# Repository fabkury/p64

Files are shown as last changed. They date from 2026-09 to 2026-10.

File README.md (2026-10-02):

# p64

A small pixel-art display for your desk: 64 x 64 RGB LEDs behind a 3D-printed shell,
powered over USB-C, controlled from a browser. It plays animated pixel art from a microSD
card and from [Makapix Club](https://makapix.club), shows a clock, the weather and the room
temperature, and takes live pixel streams from your computer. Open source, built from two
off-the-shelf Waveshare boards, no soldering.

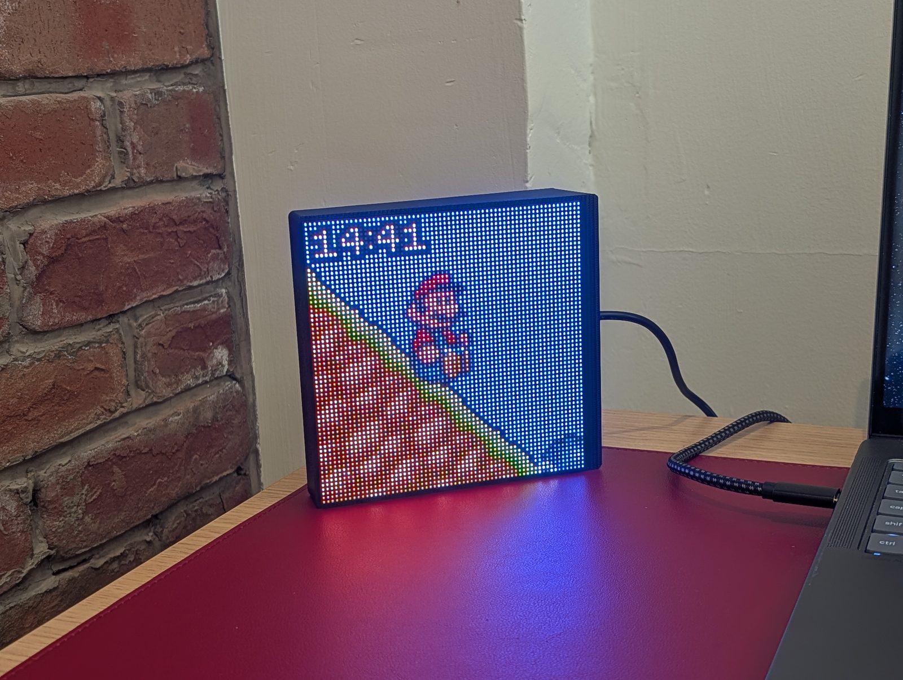
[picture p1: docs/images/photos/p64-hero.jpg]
p64 on a desk, playing an animation with the clock overlay


## What it does

- **Plays pixel art the way it was drawn.** GIF, PNG/APNG, WebP and BMP, static or animated,
  with transparency. Small canvases are scaled up by whole numbers so pixels stay square;
  large ones are scaled down cleanly. Every frame is shown, none skipped.
- **Looks right.** 11-bit colour per channel at a 264 Hz refresh, gamma 2.2, seamless
  changes from one artwork to the next: no blank frame, no flicker, no brightness step.
  A "Photo" mode raises the refresh to 814 Hz for cameras.
- **Runs on its own.** Put files on a microSD card, or pair it with Makapix Club and it
  plays channels of community pixel art, refreshing its cache over Wi-Fi. Playsets group
  channels; a scheduler picks what plays when. Offline, it keeps playing what it has.
- **Is a clock too.** A time overlay on artworks, nine clock faces (digital, analogue, and seven themed ones: split-flap, nixie tubes, a landscape that follows the real sun, a word clock, an hourglass, an orrery and a seven-segment LED or VFD clock),
  weather from Open-Meteo, the room temperature from the board's own sensor, and a night
  schedule that dims or blanks the panel.
- **Takes a live feed.** Send pixels over UDP with DDP (LedFx, xLights, WLED tooling) or
  the raw p64 format; a bundled script mirrors any image, animation or a region of your
  screen to the panel.
- **Is controlled from a browser.** A mobile-friendly web UI on `http://p64.local`
  (five colour themes, installable as a web app), a documented HTTP API with WebSocket
  push, an optional PIN. A tap on the shell skips to the next artwork; the IMU turns the
  picture upright whichever way you stand it.
- **Updates itself.** Firmware updates come from GitHub Releases with a verified install
  and rollback. Nothing is downloaded or installed without you pressing the button.

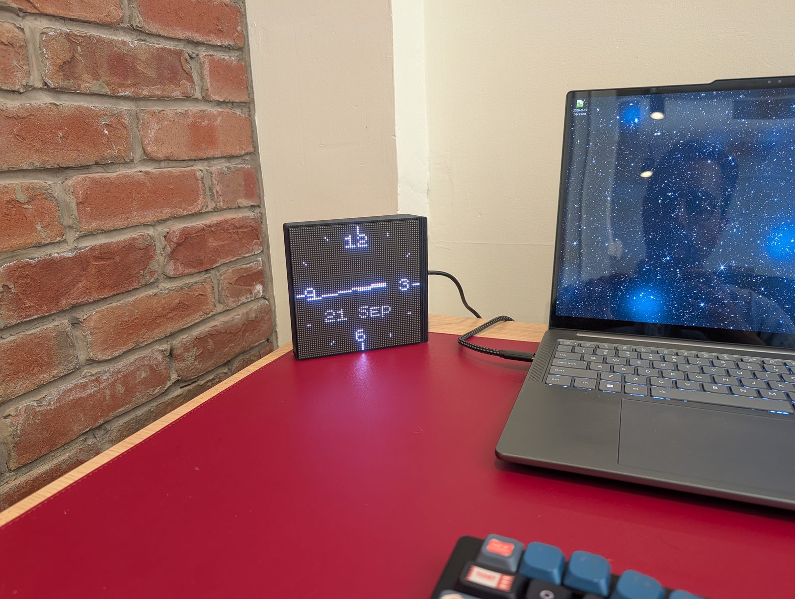
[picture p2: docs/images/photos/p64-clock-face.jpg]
Analogue clock face
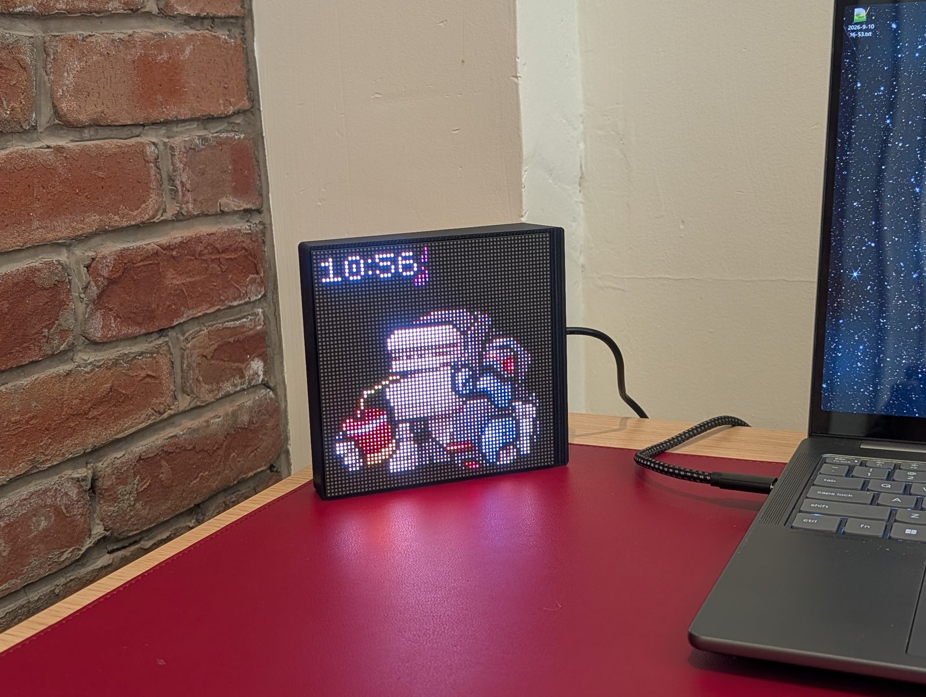
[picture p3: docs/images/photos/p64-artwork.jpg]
An artwork with the time overlay
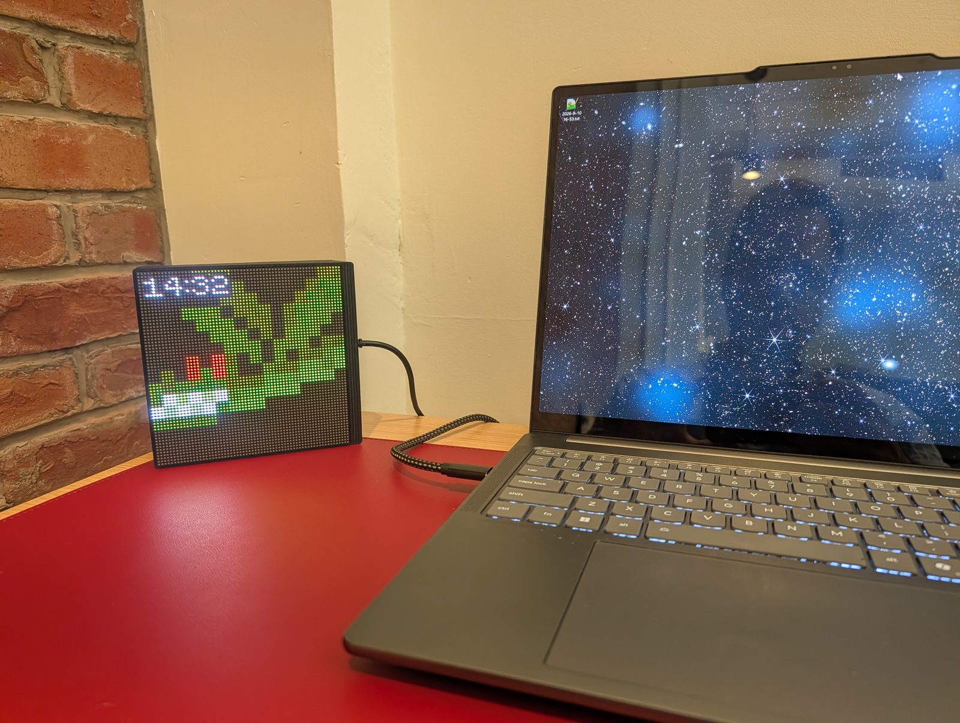
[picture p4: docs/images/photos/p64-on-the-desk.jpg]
Next to a laptop, for scale
|  |  |  |
|---|---|---|
| The analogue clock face | Time overlay on an artwork | 128 mm square, for scale |

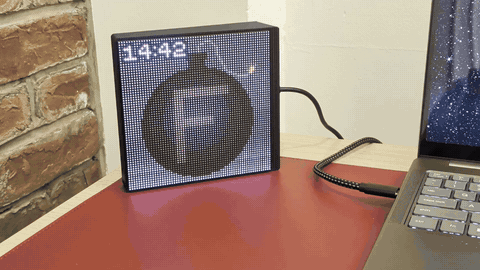
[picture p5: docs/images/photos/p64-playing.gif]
A short clip of an animation playing with the clock overlay


The web UI, on a phone:

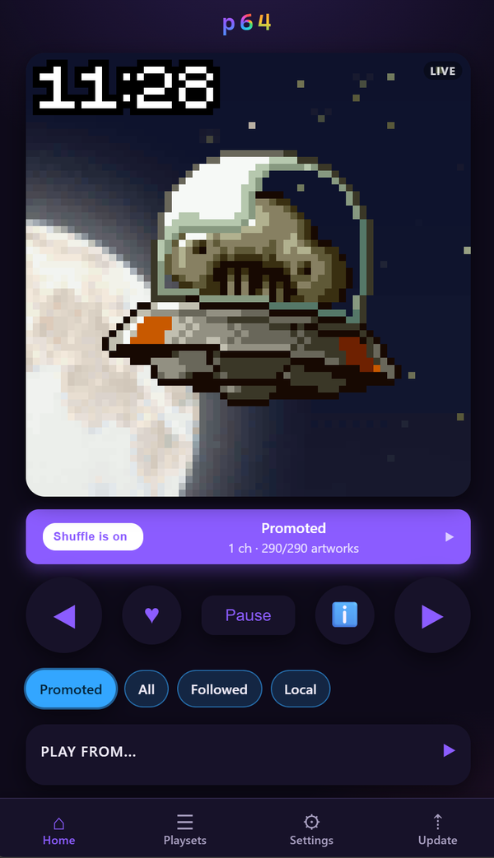
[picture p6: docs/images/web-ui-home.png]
Home page
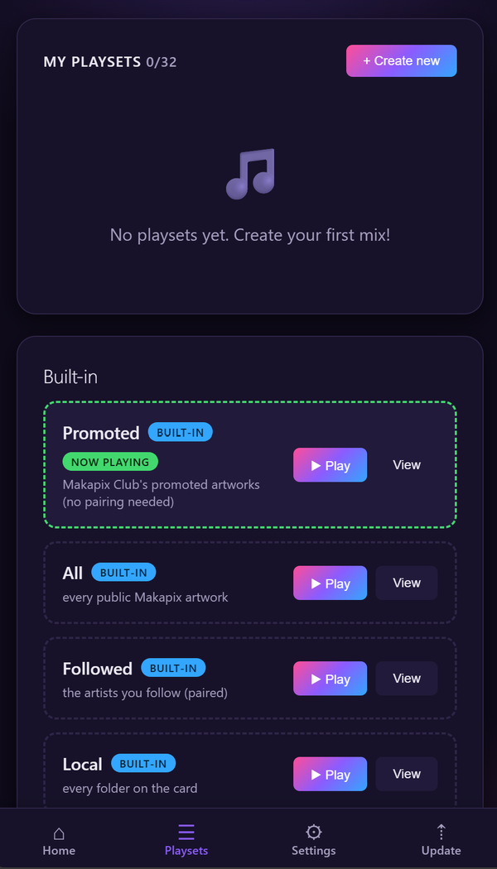
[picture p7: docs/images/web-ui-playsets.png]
Playsets page
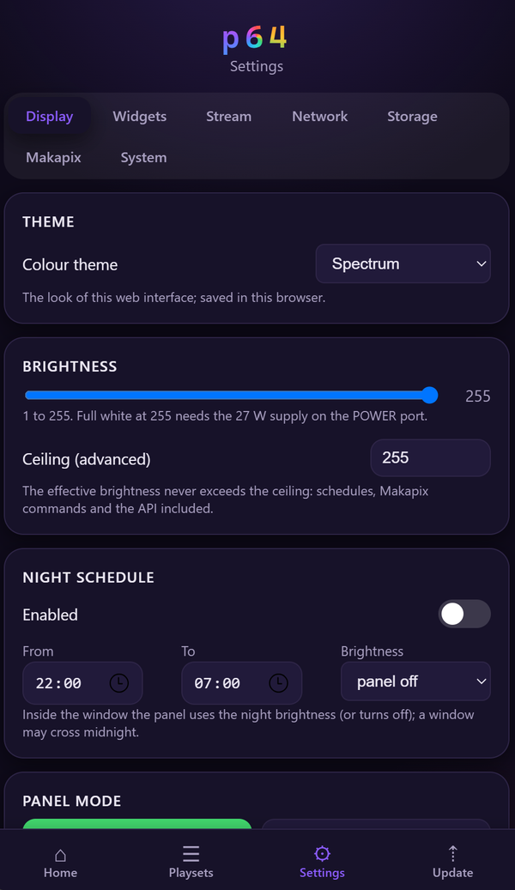
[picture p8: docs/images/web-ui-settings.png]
Settings page
|  |  |  |
|---|---|---|
| Home: live preview, controls, channels | Playsets: your mixes and the built-ins | Settings: display, widgets, network, Makapix |

More photos:

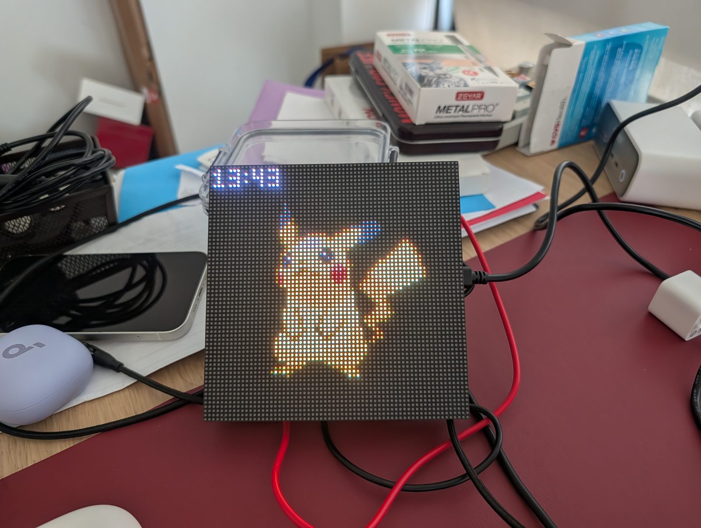
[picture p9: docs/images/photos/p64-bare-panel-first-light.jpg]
The bare panel on the bench, showing its first animation
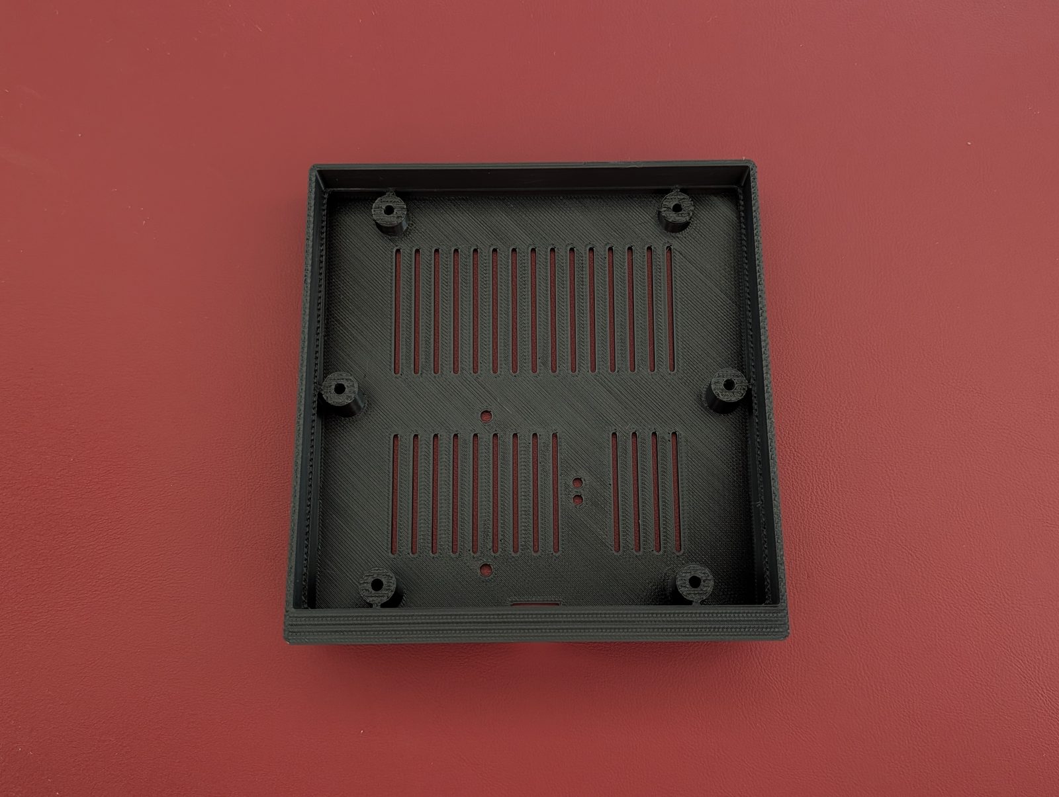
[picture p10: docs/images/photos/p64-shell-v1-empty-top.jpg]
The empty v1 shell seen from above
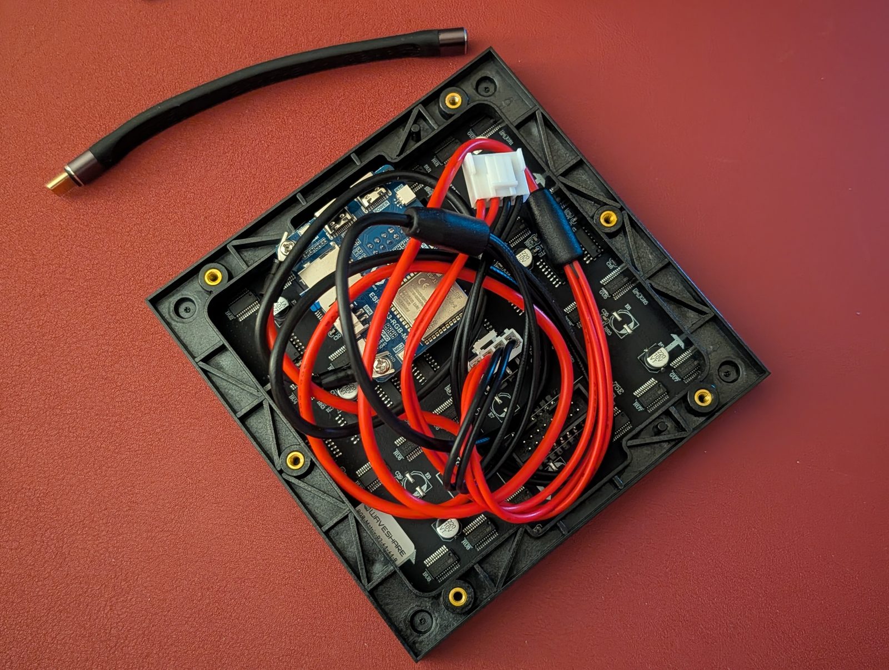
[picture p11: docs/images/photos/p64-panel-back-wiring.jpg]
The driver board and its leads behind the panel
|  |  |  |
|---|---|---|
| First light, before the shell | The v1 shell, empty | The driver board behind the panel |
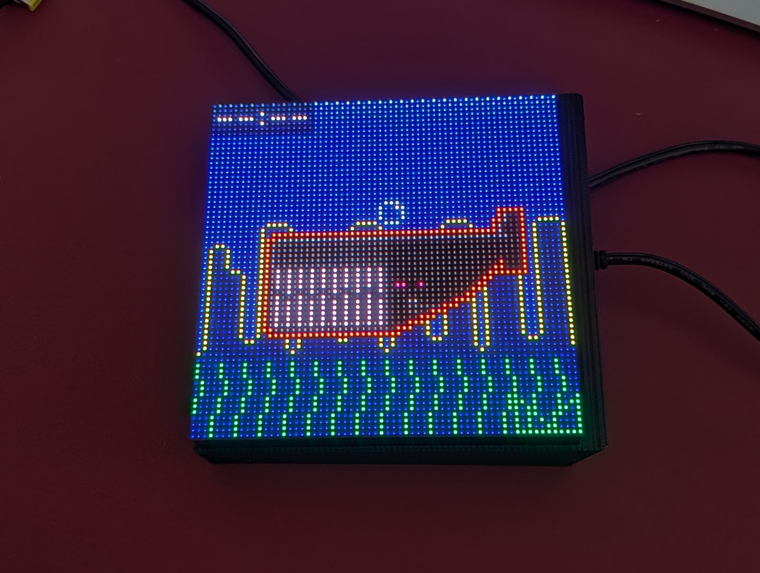
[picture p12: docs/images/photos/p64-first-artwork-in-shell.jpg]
The first artwork in the shell
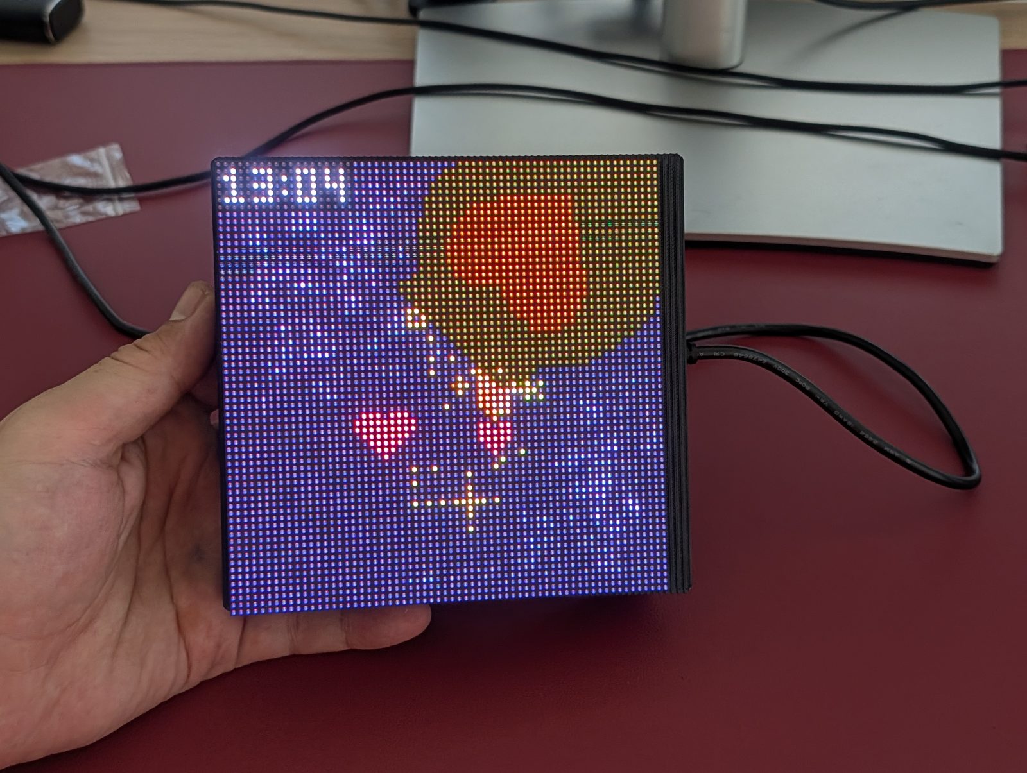
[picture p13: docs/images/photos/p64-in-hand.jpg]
p64 held in one hand
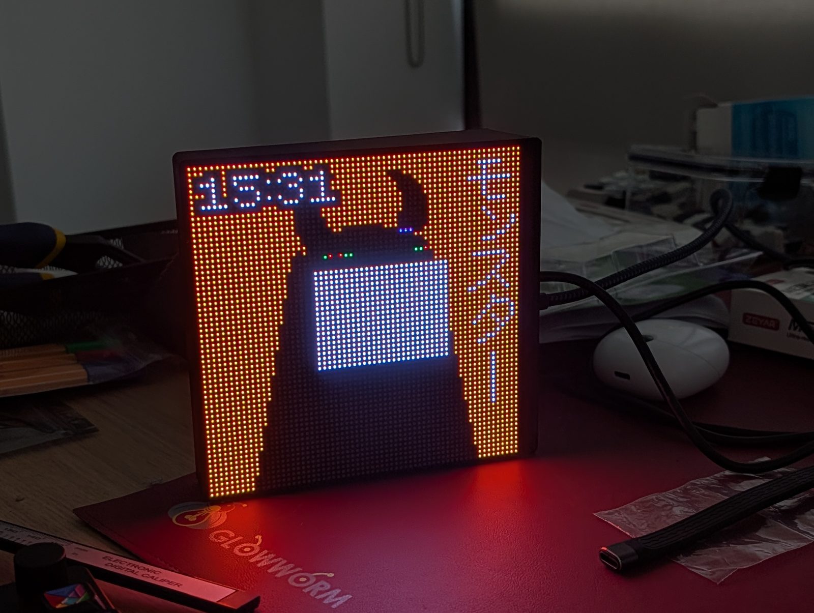
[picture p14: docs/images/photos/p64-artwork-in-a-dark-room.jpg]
An artwork in a dark room
|  |  |  |
| First artwork in the shell | In the hand | Lights off |
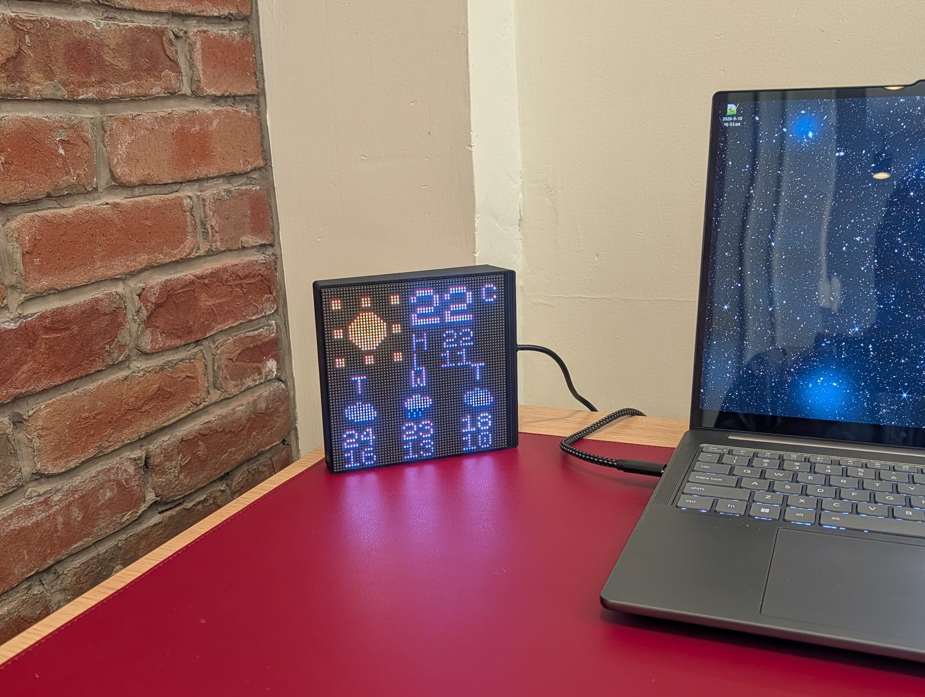
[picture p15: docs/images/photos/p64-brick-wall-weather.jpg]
The weather widget
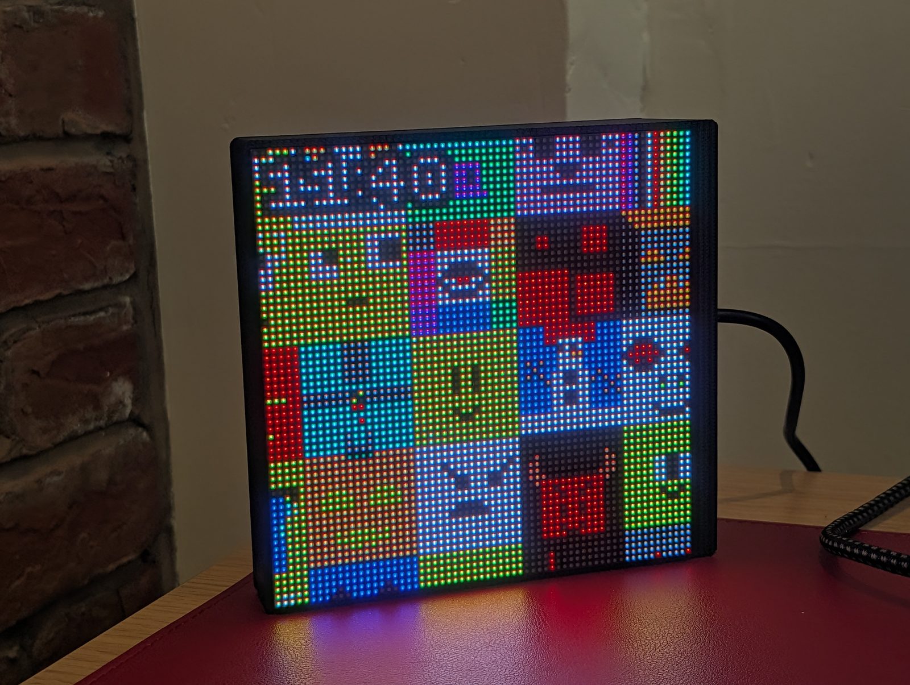
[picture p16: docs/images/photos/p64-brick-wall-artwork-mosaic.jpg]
A mosaic of small artworks
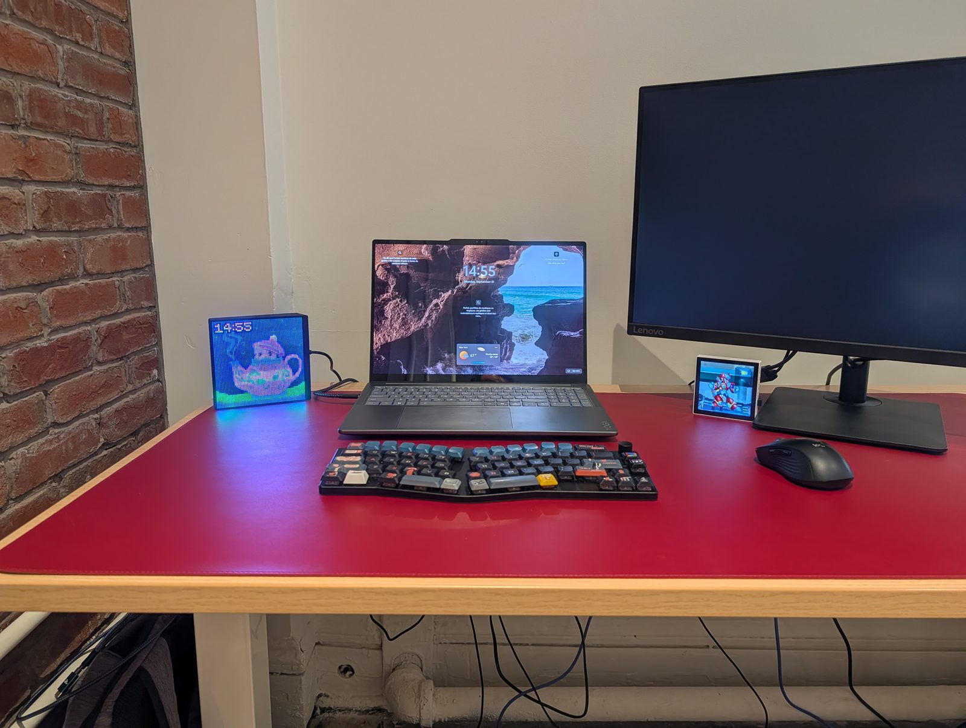
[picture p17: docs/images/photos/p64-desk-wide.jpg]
The whole desk, p64 at the left
|  |  |  |
| The weather widget | A mosaic artwork | On the desk |

The rest are in [`docs/images/photos/`](docs/images/photos/). There is also a 50-second
concept video of p64b rendered from the enclosure model (the shell as designed, the
mock-ups, an exploded view with a look inside the shell, the two knobs at work, the panel
playing animations and the widgets): the pipeline is in
[`docs/video/`](docs/video/README.md), the MP4 is regenerated with one command and is not
committed.

## What you need

Three parts from Waveshare plug together, plus a print and a handful of screws. List
prices on waveshare.com on 2026-09-21, before shipping:

| Part | What it is | Price |
|---|---|---|
| [ESP32-S3-RGB-Matrix](https://www.waveshare.com/esp32-s3-rgb-matrix.htm) | The driver board: ESP32-S3 with 32 MB flash and 16 MB PSRAM, Wi-Fi, HUB75 header, two USB-C ports, IMU, real-time clock, temperature sensor, microSD slot. Ships with the power lead and screws. [Wiki](https://docs.waveshare.com/ESP32-S3-RGB-Matrix). | $24.99 |
| [RGB-Matrix-P2-64x64-B](https://www.waveshare.com/rgb-matrix-p2-64x64.htm?sku=33838) | The panel: 4096 RGB LEDs at a 2 mm pitch, 128 x 128 mm, GOB version (a protective layer over the LEDs). The [standard version](https://www.waveshare.com/rgb-matrix-p2-64x64.htm) without the layer is $28.99 and fits the same shell. [Wiki](https://docs.waveshare.com/RGB-Matrix-Px-64x64). | $31.99 |
| [PSU-27W-USB-C-B](https://www.waveshare.com/psu-27w-usb-c-b.htm?sku=27775) | A 5.1 V USB-C supply; any good 5 V 3 A USB-C supply works. US, EU and UK plugs. | $6.99 |
| The shell | One support-free 3D print, about 80 g of PLA or PETG on a 140 x 140 mm bed, or a print bureau, plus a 2 g insert. Files in `enclosure/output/p64a/` or `p64b/`. The v1 shell in the photos was printed by JLC3DP in black PLA for $18.83, shipping included. | $18.83 at a bureau, a few dollars of filament at home |
| Small parts | Six M3 x 10 screws, a USB-C cable; for the current shell version two small 90-degree USB-C adapters. A microSD card is optional. | a few dollars |

About $64 in electronics plus the print, so a little over $80 before the electronics'
shipping. You also need a computer with a USB-C cable to
flash the firmware the first time; after that the device updates itself over Wi-Fi.

## Two variants

p64 comes in two variants, both supported for good (decided 2026-09-22):

- **p64a, solder-less:** no rotary encoders. Two boards plug together, the power lead goes
  into screw terminals, the shell is `enclosure/output/p64a/`.
- **p64b, with soldering:** two rotary encoder knobs on the back of the shell
  (`enclosure/output/p64b/`), wired to the board's GPIO socket as in `docs/hardware/`.

The firmware is the same; p64a simply has no knobs to read.

## Build one

[docs/build-your-own.md](docs/build-your-own.md) is the step-by-step guide. In short:

1. Order the parts above and print `p64_enclosure_print.stl` plus the small
   `p64_cradle_insert.stl` from `enclosure/output/p64a/v7a/` (no knobs, no soldering) or
   `enclosure/output/p64b/v7b/` (two knobs, soldered wiring); see the two variants above.
2. Install ESP-IDF v5.5, build the firmware from `firmware/` and flash it over the
   board's USB port.
3. Plug the board onto the panel, connect the power lead, slide the panel into the shell
   and fit the six screws.
4. Power it on. It opens a `p64-setup` Wi-Fi network; join it, pick your network in the
   portal, and open `http://p64.local` in a browser.

## Status

p64 is a working prototype. One device runs the firmware every day, and every feature in
[the specification](docs/spec/p64-spec.md) is implemented and checked on it. What is not
there yet, as of 2026-09-21:

- **No firmware release yet.** Building one today means compiling from source with
  ESP-IDF. A first GitHub release with a ready-to-flash image is planned; the updater is
  already in the firmware and waits for it.
- **The shell in the photos is v1.** The current design, v7, adds a window for the USB-C
  cables (and, in p64b, mounts for the two knobs) and is not printed yet. v1 is proven,
  archived under `enclosure/archive/pre-v7/`, and needs a right-angle USB-C cable instead.
- **The two knobs work on the bench, not yet in a shell.** Both are wired to the board's
  GPIO socket on a breadboard and accepted (2026-10-01): one turns the brightness and
  pauses, the other steps through the artworks and likes on Makapix Club. The permanent
  harness and the p64b shell are still to come; the wiring projects are in
  `docs/hardware/`.
- **Some acceptance measurements** in the specification still need instruments.

## Repository map

| Path | What it is |
|---|---|
| `firmware/` | The product firmware: ESP-IDF v5.5, C++20, on a patched `esp-hub75` driver. Its README has the build, flash and test commands; `firmware/docs/` has the architecture, the API and the progress log. |
| `enclosure/` | The OpenSCAD shell (one source, two variant files), with ready-to-print STL/3MF and renders under `enclosure/output/p64a/` and `p64b/`. Its README has the design rationale and the print settings; the earlier versions are under `enclosure/archive/pre-v7/`. |
| `docs/spec/p64-spec.md`, `CONTEXT.md`, `docs/adr/` | What the device does (the specification), the vocabulary, and the decisions that are hard to reverse. |
| `docs/build-your-own.md`, `docs/images/` | The build guide, the photos (`photos/`) and the web UI screenshots. |
| `docs/hardware/` | Wiring projects for the two rotary encoders, with schematics. |
| `firmware/reference/hardware-tests/` | The test firmware that brought up the board and panel; the technical reference for what the hardware taught (pin map, driver patch, frame pacing, DMA). |
| `prompt/` | The task prompt of each development session, in order. |

## About

p64 is a sibling of [p3a](https://github.com/fabkury/p3a), the same author's ESP32-P4
pixel-art player, and a "player" for [Makapix Club](https://makapix.club), a community
site for pixel art whose [server](https://github.com/fabkury/makapix) is open source too.
The firmware, the shell and the documentation were developed with Claude Code, session by
session; the prompts are committed under `prompt/`, and every hardware finding was
verified on the device.

Licensed under the [Apache License 2.0](LICENSE). Bundled fonts are VEXED's Capital Hill,
Everyday Slight, Standard, Typical and Ample, and High Birth (CC BY 4.0); the LED driver is
[esp-hub75](https://github.com/esphome/esp-hub75) with a local patch, the GIF decoder is
bitbank2's AnimatedGIF, and libpng and libwebp decode the rest.

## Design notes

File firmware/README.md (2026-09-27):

# p64 firmware

The firmware of the p64 device: a desktop 64x64 RGB LED matrix built on Waveshare's
ESP32-S3-RGB-Matrix driver board and RGB-Matrix-P2-64x64 panel (the repository README
lists the hardware).

Started from zero on 2026-09-19 and built in ten milestones the same day (M0 to M10,
`docs/PROGRESS.md` has the table, the log and what was verified on the device). The
design is `docs/architecture.md`, the routes `docs/api.md`.

## Specification

What the device does is fixed by `docs/spec/p64-spec.md` at the repository root, with
the vocabulary in `CONTEXT.md` and the decisions in `docs/adr/`.

## Building, flashing, testing

ESP-IDF v5.5.4 (`tools/env.ps1` knows the install), PowerShell 7, from this folder:
`./tools/build.ps1`, `./tools/flash.ps1` (auto-detects the board's COM port),
`./tools/monitor.ps1`, `./tools/idf.ps1 <args>`. `sdkconfig.defaults` is the source
of truth; a changed default needs `sdkconfig` deleted. Wi-Fi credentials live only in
the git-ignored `sdkconfig.secrets`. Boot logs without a reset: `tools/serial_peek.py
COM13 <seconds>` with the IDF venv's python while `POST /api/v1/action/reboot`
restarts the firmware.

Host tests (`python tests/host/run.py`, gcc and the system Python with Pillow) build
the ESP-IDF-free parts: decoders against Pillow pixel for pixel, the content model,
fonts, widgets' pure parts, the stream protocol, the night rule, the time rules, taps and
orientation, the encoders' wire format and detent tracker, the version rule. Device tests under `tests/device/` run against the
live device: `api_smoke`, `content_smoke`, `makapix_smoke [--paired]`,
`widgets_smoke`, `stream_smoke`, `ops_smoke`, `imu_smoke`, `encoders_smoke [--watch S]`, `pin_smoke`, `ota_smoke
[--no-install]`, `ui_smoke`, `cache_sweep_smoke [--delete]`, `panel_mode_smoke`,
`timing_smoke` (playback cadence), `ws_smoke` (the WebSocket push held open), and
`soak --minutes N` for an
unattended acceptance run. The resource floors (internal RAM free and largest block at
steady state and over a soak, core 0 busy share, image size, static internal RAM) live
in `budgets.json`: `api_smoke` and `soak` check the runtime ones against the device,
`tools/check_size.py` the static ones against a build; a change that breaks a floor
raises it there deliberately (rule of 2026-09-22, `docs/review-2026-09/`). Give the
timing-sensitive tests (`stream_smoke`, `soak`) the device's IP rather than `p64.local`:
on this laptop the first mDNS resolution of a process takes up to 3 s, which lands the
stream test's status read after the stream has gone silent (seen 2026-09-22; against the
IP the same run measures 29.7 fps with 0 incomplete frames).
Tools: `stream_send.py` (send pixels), `release_assets.py` (the GitHub release assets),
`cpu_sample.py` (per-task CPU shares and heap figures from `diag/memory`; heap owners
too when the build has `CONFIG_HEAP_TASK_TRACKING`), `check_size.py`, `gen_fonts.py`,
`gen_weather_icons.py`, `gen_ui_icons.py`.

## Fonts and icons

`tools/gen_fonts.py` rasterises the bundled TTFs (`assets/fonts`, VEXED's Capital Hill,
Everyday Slight, Standard, Typical and Ample, and High Birth, CC BY 4.0) into `components/p64_gfx/src/fonts_data.cpp`;
`tools/gen_weather_icons.py` draws the weather icons into `assets/weather/*.png` (edit
the PNGs by hand and rerun to compile them in). Both need Pillow (the system Python)
and both outputs are committed, so the firmware build needs neither.

## HTTP API

Route reference: `docs/api.md`. Device tests: `tests/device/api_smoke.py` and
`tests/device/content_smoke.py` (both need a card with files; `--corpus` uploads the
host corpus). `tests/device/panel_mode_smoke.py` switches Quality and Photo mode a dozen
times and checks the refresh rate, plane count, DMA streaming and the internal heap
after each (the panel modes are refresh profiles of the driver, `docs/architecture.md`
section 4; the 2026-09-20 rework is in `docs/PROGRESS.md`).

## Web UI

`components/p64_web/ui/`: `index.html` (Home), `playsets.html`, `settings.html`,
`update.html`, `static/common.css` and `static/theme.js` (p3a's stylesheet and themes,
copied verbatim; update them from `reference/p3a/webui/static/` when p3a's change),
`static/app.js` (shared helpers), `manifest.json` and the icons from
`tools/gen_ui_icons.py`. Everything is embedded in the image (ADR 0005); a change needs
a rebuild and flash. `tests/device/ui_smoke.py` checks the routes.

## Streams

Pixels over UDP: DDP on 4048 (LedFx, xLights, WLED tooling) and the raw p64 format on
4064 (RGB888, RGB565 or indexed, any size to 128x128, chunked by offset; the header is
in `docs/api.md`). `python tools\stream_send.py p64.local test` sends a moving
pattern, `... image.gif` any image or animation, `... screen --ddp --size 128` the PC
screen; `tests/device/stream_smoke.py` checks both protocols pixel for pixel and the
takeover.

## Decode benchmark (2026-09-19, first firmware milestone of spec 4.4)

Measured on the device with `GET /api/v1/diag/bench` (decode plus scaling to 64x64, per
frame, on the HTTP task on core 0 while the show ran on core 1; Pillow-made corpus from
`tests/host/corpus/`, two loops):

| File | Format | Canvas | Frames | Avg ms/frame | Max ms | Sustainable fps |
|---|---|---|---|---|---|---|
| gif_anim_32.gif | GIF | 32x32 | 8 | 0.98 | 1.07 | 1016 |
| apng_blend_48.png | APNG | 48x48 | 16 | 3.46 | 4.29 | 289 |
| apng_opaque_64.png | APNG | 64x64 | 12 | 4.73 | 5.37 | 212 |
| webp_anim_lossless_64.webp | WebP | 64x64 | 12 | 5.66 | 6.61 | 177 |
| apng_rgba_128.png | APNG | 128x128 | 8 | 22.30 | 25.04 | 45 |
| webp_anim_lossy_128.webp | WebP | 128x128 | 10 | 28.68 | 31.07 | 35 |
| png_rgba_128.png | PNG | 128x128 | 1 | 6.27 | 6.27 | (static) |
| png_rgb_256.png | PNG | 256x256 | 1 | 15.87 | 15.87 | (static) |
| bmp_24_64.bmp | BMP | 64x64 | 1 | 1.01 | 1.01 | (static) |

So 64x64 animations decode well inside the 16.7 ms budget of 60 fps in every format, and
128x128 animations sustain 35 to 45 fps: 128x128 at 60 fps plays in slow motion under
the no-drop rule (ADR 0003), as the spec allows. Run it again after decoder or scaler
changes: `python tests/device/api_smoke.py http://p64.local --corpus --bench`.

## Relation to `reference/hardware-tests/`

`reference/hardware-tests/` is the previous `firmware/` folder: the test firmware that
brought up the driver board and the panel (renamed `hardware-tests/` on 2026-09-19, moved
under `reference/` on 2026-09-24; git history follows both moves, `git log --follow` works
on its files). Unlike the clones beside it, it is tracked in git. It is the technical reference for this project, not the architectural one:

- Take from it what the hardware taught: the pin map, the vendored and patched esp-hub75
  driver, the frame pacing against the panel's DMA, the tonal-depth and refresh numbers,
  the GDMA priority lesson, the network settings and measured throughput, the microSD
  wiring, the ESP-IDF tool scripts and environment facts.
- Do not take its architecture or code patterns (the scene loop, the module layout, the
  fetcher/web split) as given; they were shaped by testing one thing at a time, not by
  the device we want to build.

Its README, `reference/hardware-tests/README.md`, holds the details and the measured numbers.

## Private area

`private/` is a separate repository, `github.com/fabkury/p64-private`, never published:
the user's own components (a private source of channels, ADR 0012). It is git-ignored
here and the pre-commit hook refuses its paths. The build finds it on its own
(`CMakeLists.txt`): its `components/` join the build, `sdkconfig.private` applies on top of
`sdkconfig.defaults`, the version ends in `+private`, `main.cpp` calls `p64::priv::start()`
under `CONFIG_P64_PRIVATE`, and `tests/host/run.py` compiles what
`private/tests/host/manifest.json` names. Without the folder the build is the public
firmware, which is what CI builds. To mount it on a fresh checkout, from `firmware/`:

```
git clone https://github.com/fabkury/p64-private private
```

A private build must not install a public release without knowing it drops the private
parts; the Update page says so (`private_build` in `/api/v1/update`).

## Reference clones

`reference/` holds local clones of upstream repositories, git-ignored (the tracked
`hardware-tests/` beside them is the exception). Waveshare's example repository for the
driver board (schematic, examples, pin map) is the one the hardware tests were written
against; to re-create it, from `firmware/`:

```
git clone https://github.com/waveshareteam/ESP32-S3-RGB-Matrix reference/ESP32-S3-RGB-Matrix
```

Two more clones live there since 2026-09-19 and are used as references by the
specification: `p3a/`, the user's production ESP32-P4 pixel-art player whose module
boundaries, web UI and Makapix client p64 follows, and `makapix/`, the Makapix Club
server, whose `docs/player/`, `docs/mqtt-api/` and `api/openapi.json` are the device
contract:

```
git clone https://github.com/fabkury/p3a reference/p3a
git clone https://github.com/fabkury/makapix reference/makapix
```

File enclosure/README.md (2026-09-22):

# Tabletop enclosure for the Waveshare RGB-Matrix-P2-64x64 + ESP32-S3-RGB-Matrix

This folder is the enclosure part of the [p64 project](../README.md). All paths and
commands below are relative to `enclosure/`.

A single-piece, support-free 3D printed back shell that screws onto the six M3 brass
inserts of the 128 x 128 mm P2 LED matrix, encloses the ESP32-S3-RGB-Matrix controller
that is plugged into the panel's HUB75 IN header, and stands the display on a desk
leaning back 12 degrees. The USB-C cables plug into two small 90-degree adapters that
stay on the controller's ports, through one window in the back face; a second small
print, the cradle insert, is glued inside around them.

The design is **v7**, in one OpenSCAD file, and p64 comes in two variants that share it:

| Variant | Shell | What differs |
|---|---|---|
| **p64a**, solder-less | `src/p64_enclosure_v7a.scad`, outputs in `output/p64a/v7a/` | No rotary encoders: no posts, bushing holes or spot-faces on the back, the lower vent band keeps all its columns. Otherwise identical. |
| **p64b**, with soldering | `src/p64_enclosure_v7b.scad`, outputs in `output/p64b/v7b/` | Two rotary encoders (Adafruit 5880 boards) on the back face, one knob per side; the wiring projects are in `../docs/hardware/`. |

The two variant files are three lines each: they include `src/p64_enclosure_v7.scad`, the
geometry, and set `encoders` to false or true. Both variants are supported for good, so a
change to the shell is made once, in `p64_enclosure_v7.scad`, and both output folders are
regenerated. Nothing of v7 has been printed yet; the fit of the pocket, ledge and bosses,
unchanged since the first version, was verified on the v1 print (see below). The earlier
versions v1 to v6 and their story are in [`archive/pre-v7/`](archive/pre-v7/README.md).

## Files

| Path | What it is |
|---|---|
| `src/p64_enclosure_v7.scad` | The parametric OpenSCAD source (OpenSCAD 2021.01+): the whole shell, the cradle insert, the mock-ups and the section views. Everything below is a parameter. Rendered on its own it gives p64b. |
| `src/p64_enclosure_v7a.scad`, `src/p64_enclosure_v7b.scad` | The variant files: include the source and set `encoders`. Render these, not the source, so the output lands in the right folder. |
| `output/p64a/v7a/`, `output/p64b/v7b/` | One folder per variant and version, identical file names inside: `p64_enclosure_print.stl` / `.3mf` (ready to slice, print orientation), `p64_enclosure_service.stl` (0.45 mm fit clearance instead of 0.3, for MJF/SLA bureaus), `p64_cradle_insert.stl` (the second print), and the renders: `render_back.png`, `render_assembly.png` (with the mock-ups), `render_print.png`, `render_product.png` / `render_product_back.png` (standing on a table), `render_section_ad.png` (through the POWER adapter), `render_section_win.png` (along the adapters' centre line), `render_window.png` (straight at the window: the two socket faces with the insert's sole around them), `render_insert.png` (the insert alone), `render_frame_notch.png` (where to notch the panel frame, in red), `render_section_edge.png` (the wall profile through x = 33: the edge chamfer and fillets); p64b adds `render_section_enc.png` (through an encoder). |
| `input/measurements.md` | Hand measurements of parts that have no drawing: the v1 print, the 90-degree USB-C adapter. |
| `input/usb-c-90-degree-adapter/` | Photos of the 90-degree USB-C adapter; one has the hand measurements drawn on it. |
| `input/PXL_20260918_*.jpg` | Photos of the v1 print, alone and assembled. |
| `input/RGB-Matrix-P2-64x64-2D.dwg`, `.pdf` | Waveshare's drawing of the panel frame (DWG and a PDF rendering of it). |
| `input/ESP32-S3-RGB-Matrix-2D.pdf` | Waveshare's 1:1 drawing of the controller board. |
| `input/*details*.jpg` | Waveshare product photos used for the features the drawings do not cover. |
| `input/adafruit-5880/` | Adafruit's EagleCAD board file of the encoder breakout (CC BY-SA), with a README of what the shell reads from it (p64b). |
| `archive/pre-v7/` | Versions v1 to v6 (sources, outputs, the speaker photos of v5) and their documentation, moved on 2026-09-22. v1 is the only printed one. |
| `archive/2026-08-stand-concept/` | Earlier, abandoned concept (detachable stand, wall keyholes). Kept for reference only. |
| `archive/2026-09-dhruv-solidworks/` | Dhruv's separate SolidWorks take on the enclosure (`p64.SLDPRT` and its STEP export). Kept as-is, never edited here. |

## What the design does

- **Fit:** pocket 128.4 x 128.4 mm (0.3 mm clearance per side around the 127.8 mm frame
  measured in Waveshare's drawing), 2 mm walls, 2.4 mm back wall.
  The walls wrap 13.5 mm forward: over the panel's 12 mm plastic frame and 1.5 mm of the
  2.5 mm LED board and mask stack in front of it, so the mask stands 1.0 mm proud of the
  rim (`proud`; 2.5 mm until 2026-09-22, when the rim ended at the frame) and the front
  is nearly bezel-less. Beside the board the pocket keeps 0.2 mm per side around the
  assumed 128.0 mm board outline (`board`, `board_clr`, not in any drawing); if the real
  board is wider the pocket steps out there automatically and the `front:` echo line
  reports the wall left.
- **Size:** 132.4 mm wide, 132.4 mm tall at the back edge and 139.9 mm at the front (the
  base wedge). The side profile is a wedge: 35.5 mm deep at the bottom (13.5 mm lip +
  22 mm shell) thinning to 21.5 mm at the top (13.5 + 8). The back face is one flat plane
  sloping 6 degrees, so the print still lies flat on it.
- **Interior:** 19.4 mm clear at the bottom edge, 12.9 mm at the top edge of the controller,
  5.8 mm at the top edge of the panel. The mounted controller needs roughly 9 mm and the
  VH4 power plug with its wires about 8 mm, both in the deep half.
- **Mounting:** six counterbored bosses on the panel's inserts, positions from Waveshare's
  drawing: (0, +-56.85) and (+-56.85, +-44) mm, rotated with the panel. Bosses are 10.5 mm in
  diameter around a 6.5 mm counterbore (2 mm walls). M3 x 10 screws go in
  from the back; the boss floor is 5 mm so about 5 mm of thread engages the insert. The two
  top bosses are only 6.6 mm tall because of the wedge; their screw heads end up 1 mm below
  the back face (keep `depth_top` at 8 mm or more, or use M3 x 8 there).
  A 1.6 mm seating ledge with a 45-degree underside supports the frame's 1.6 mm outer wall
  all around, except over 30 mm below the USB-C ports where it is relieved (see the window).
- **Tilt / stand:** the bottom wall thickens into a wedge so the whole base is one flat plane
  at 12 degrees. With the edge fillets the contact patch is 31.2 mm deep; the centre of
  gravity lands about 8 mm in front of the rear contact line, so it takes roughly a
  7-degree backward push to tip.
- **Panel orientation:** the panel is installed rotated 90 degrees counter-clockwise (seen
  from the back) so the controller sits at the bottom with its USB-C ports facing down.
  The LED image is rotated 90 degrees in firmware.
- **Cables:** two small 90-degree USB-C adapters stay plugged on the controller's POWER and
  USB ports; their sockets face the back wall through one window at the bottom centre of
  the back face, and the external cables plug in from behind. Nothing hangs below the base.
- **Back wall:** two bands of ventilation slots, 3 mm pin holes over BOOT and RESET marked
  with short grooves (one groove = BOOT, two grooves = RESET; text labels were dropped because
  their 0.3 mm ribs are too thin for bureau printing), 3.5 mm holes over the two microphones,
  six screw counterbores, the USB-C window with one groove beside its right end (= USB, the
  programming port; POWER has none), and in p64b the two encoder bushings with their
  spot-faces. Every wall and rib is 2.0 mm or thicker, with two named exceptions in the
  glued insert.
- **Edges:** the back face's perimeter has a 1.4 mm 45-degree chamfer, the front rim a
  1.5 mm fillet, the base's front edge a 3 mm fillet, the counterbore mouths a 0.5 mm
  chamfer (see Edges).

Not included: access to the TF card slot. In every orientation the card slot ends up about
39 mm from the nearest wall, so a slot in the shell would be useless. The card has to be
inserted before closing the shell.

## USB-C: the adapters, the window and the cradle insert

- **Hardware** (hand-measured on 2026-09-19, `input/measurements.md`, photos in
  `input/usb-c-90-degree-adapter/`): a generic 19.3 x 12.7 x 8.0 mm aluminium-shelled
  male-to-female right-angle USB-C adapter; the male plug leaves the wide face with its
  centre 4.8 mm from one end (7.7 mm proud of the face, boot included), the female socket
  sits in the far end face. Plugged into a port with the controller on the panel, the body
  hangs below the port with its length running front to back and the socket facing the
  back wall; the two bodies touch (the ports are 12.74 mm apart), so the pair is 25.4 mm
  wide. POWER is the left one seen from the back. Both adapters fit at once (checked
  2026-09-19).
- **Where they end up** (model, `z_chip` = 0.5): receptacle axis 3.7 mm behind the frame's
  back face; bodies from 1.1 mm in front of that face to 18.2 mm behind it, i.e. 0.5 mm
  short of the cavity back and 2.9 mm inside the outer surface; body underside 0.41 mm
  above the frame's outer wall; the pair spans x = -12.4..13.0 mm, y = -61.9..-53.9.
- **Window:** one 28.3 x 10.7 mm rounded-rectangle opening through the back wall, corner
  radius 3.0 (the body's own), 0.5 mm 45-degree chamfer outside. It is sized by the
  tolerance budget below: 1.45 mm of clearance per side in x, 1.95 mm above the bodies and
  0.76 mm below them, so its centre sits 0.6 mm above the pair's. The socket faces sit
  2.9 mm down in it and a cable plug's boot goes into that well. One cable at a time is the
  design case; two boots at or under the USB-C maximum of 12.35 mm would also fit side by
  side. The mic1 hole sits 0.5 mm right and 1.6 mm up from where the microphone is
  (`mic1_off`) so the webs around it keep 2 mm against the window: 2.18 mm to the window
  at the inner face (the chamfer outline comes 1.68 mm close on the surface), 2.05 mm to
  the nearest vent slot. The microphone is about 10 mm behind the wall, so the hole is a
  sound vent and the offset changes nothing audible.
- **Frame notch (hand work):** the bodies reach 1.1 mm in front of the frame's back face,
  and right there the frame's back plate has a 3.9 mm strip between its opening (58.4 mm
  from the centre at the ports) and its 1.6 mm outer wall. Cut that strip away through the
  plate, 27.4 mm wide centred on the **real** ports (1 mm each side of the pair); the outer
  wall stays. Measured from the frame instead of the ports, the whole position budget needs
  29.4 mm: in the panel's own orientation (arrows up, seen from the back) x = -62.3..-58.4,
  y = -15.0..+14.4 mm, which is what `render_frame_notch.png` shows in red. On 2026-09-19
  an adapter on the uncut plate stopped about 1 mm short of seating; after cutting, check
  that both seat fully and that the bodies clear the wall (that check also verifies the
  downward side of the budget, see below).
- **Cradle insert** (`part = "insert"`, `p64_cradle_insert.stl`): a 34 x 7 x 6 mm second
  print: a U (1.2 mm bottom wall, 2 mm side walls up to the bodies' top face, open towards
  the controller) around the last 6 mm of the bodies, standing on a 1.2 mm sole that lies
  on the cavity back and reaches 3 mm beyond the window on each side and 1 mm below it.
  Its opening has 0.55 mm of clearance in x and 0.75 in y (0.3/0.5 plus the print
  allowance), because it is glued to the cavity back while sitting on the real adapters and
  so aligns itself to wherever they are. It takes the sideways and downward part of the
  cable forces so they cannot lever the adapters in the receptacles. The bodies pass
  through the sole's opening into the wall's window, so from outside the sole frames the
  two socket faces at 2.4 mm depth and hides the shell's wider opening on the sides and
  below; above the bodies the 1.95 mm strip stays open into the cavity (a bar there would
  sit in front of the mic1 hole at the worst case). Two 1.5 x 1.2 mm rails on the cavity
  back bracket the sole with the whole x budget of play: a guide for placing it and a shear
  key for the glue. The 1.2 mm sole and bottom wall are deliberate exceptions to the 2 mm
  rule: the sole is a glued lamination on the 2.4 mm wall, the bottom wall is backed by
  the shell's bottom wall within 0.36 mm (a 0.05 mm overlap only if the bodies sat as low
  as they physically can, which would just lift the glued insert by that much; that is
  why it is 1.2 and not 2). 1.2 mm is JLC3DP's thin-wall line: at 1.0 their check flagged
  the insert on 2026-09-22, and a 1 mm entry chamfer along the bottom wall tapered it to
  a knife edge. The entry chamfer is now 0.8 mm on the side walls only (1.2 mm left at
  the edge); the bottom wall has none. The wall's own 2.4 mm depth keeps the
  plugs from ever leaving the receptacles: a plug shell is 6.5 mm long.
- **Ledge relief:** the seating ledge is cut away over 30.3 mm centred below the ports
  (`ledge_relief`); in the previous design the bodies passed 0.7 mm above it.
- **Standing:** the back face points 6 degrees below horizontal (12 degrees of lean minus
  the 6 degree wedge) and the window's centre is about 8 mm above the table, so a cable
  leaves backwards, slightly downwards, and reaches the table a few centimetres behind
  the display (`render_product_back.png`).
- **Numbers** (the `budget:`, `adapters:`, `insert:`, `webs:` and `ledge relief:` echo
  lines): window 28.34 x 10.71, centre y -57.3, bottom edge y -62.65; insert opening
  26.54 x 9.5, outer width 30.54, sole 34.34 x 7.25, rails at x -20.1..-18.6 and
  19.2..20.7; at the worst case (bodies 1.7 mm higher) the side walls end at y -52.2, 1.6 mm
  below the mic1 hole's edge; the window's chamfer stops 1.95 mm from the back face's
  bottom edge chamfer; socket faces z 18.2, well depth 2.92.

### The tolerance budget

The window and the rails are sized so that the print fits at the first try even if the
inputs the model cannot verify are off by their rated error (decided 2026-09-22: fit
before looks, the position budget as rated, JLC3DP FDM). Every clearance is derived from
these parameters, so the numbers can shrink once the real positions are measured.

| Input | Rated error | Where it comes from | Moves the adapter pair |
|---|---|---|---|
| Port position (`hub75_in_native`, `tol_pos`) | +-1.0 mm in x and y | read off a product photo; the v1 print only showed the ports inside a 30 mm pocket | x and y |
| Boot gap (`ad_gap` 1.2, `tol_gap`) | +-0.5 mm | an estimate (7.7 mm plug minus a 6.5 mm shell), not measured | y (how far the bodies hang below the ports) |
| Body size (`ad_len`, `ad_w`, `ad_t`, `tol_body`) | +-0.2 mm per side of the pair | hand measurements on a photo | x and y edges, z (socket face) |
| Socket face depth (`z_chip` 0..1, `ad_plug_c`, `ad_len`, `tol_z`) | +-1.1 mm | `z_chip` is a range, the other two are photo measurements | z only: the well is 1.8 to 4.0 mm deep instead of 2.9, the plugs stay 6.5 mm in the receptacles |
| FDM print allowance (`print_clr`) | 0.25 mm per side of an opening | a guess from the v1 print, whose outside came out 0.3 mm per side larger than the model | shrinks every opening |
| Body corner radius (`ad_r`, 3.0) | real 3.5 to 4 | photos | only ever adds clearance |

Window clearance: x = 1.0 + 0.2 + 0.25 = 1.45 per side; up = 1.0 + 0.5 + 0.2 + 0.25 =
1.95; down = 0.41 + 0.25 + 0.1 = 0.76, because one bound is physical: the bodies cannot
hang lower than the frame's outer wall (inner face at y = -62.3, from the drawing), or the
adapters would not seat on the ports at all. So downwards the shell needs only the print
allowance beyond those 0.41 mm, and "do both adapters seat fully after the notch is cut"
verifies the whole downward side for free. Not absorbed: a port lower than the frame's
wall allows (a hardware collision, found at that check); a socket depth beyond +-1.1 mm
(only the well's depth changes, the cable still plugs in); the microphone position itself
(+-1 mm from the same photo, irrelevant for a vent hole).

Before v7 the window had 0.4/0.6 mm of clearance per side and the cradle 0.3/0.5, i.e.
0.15/0.35 and 0.05/0.25 after the print allowance: a 1 mm error in the port position put
an adapter body into the wall (`archive/pre-v7/`, v6).

### Shrinking the budget (measure later)

Once the notch is cut and both adapters are seated on the real panel, three caliper
measurements pin the inputs down; after them `tol_pos` can drop to the residual (0.3 mm
is realistic for calipers) and the window shrinks accordingly, the insert unchanged:

| Measure | Nominal | Pins down |
|---|---|---|
| Frame's outer side face to the pair's outer side face, on each side (design orientation, ports down) | 50.9 right, 51.5 left | port x (`hub75_in_native[1]` before the 90 degree rotation) |
| Frame's outer bottom face to the bodies' underside | 2.0 | port y plus the boot gap (`hub75_in_native[0]` and `ad_gap`) |
| Frame's back face to the socket faces (depth gauge) | 18.2 | `z_chip` + `ad_plug_c` + `ad_len` |

Enter what differs, regenerate both variants, and read the echo lines: the model prints
every margin.

## Encoders (p64b only)

- **Hardware assumed:** two Adafruit 5880 boards (I2C "seesaw" rotary encoder breakout:
  25.4 x 25.4 mm PCB with four 2.5 mm plated holes on a 20.32 mm square, a Bourns
  PEC11-style 24-detent encoder with push switch soldered at the centre, 15 mm D-shaft,
  M7 x 0.75 bushing, 6.5 mm body height) and 20 mm set-screw knobs. Checked on
  2026-09-22 against the sources and, the same day, with calipers on one of the user's
  boards (`input/measurements.md`: shaft 15.0, body 6.5, PCB 1.6, holes 2.5, board 25.4,
  washer plus nut 2.5, all as modelled; the bushing measured 6.0 instead of the
  datasheet's 5.0 and the model now uses 6.0, which only changes how far it stands out;
  the pin stubs under the board reach 3.0 mm into the 4.1 mm available there; the knob
  is 20 x 15.5). Against the sources: the board outline, corner radius, hole size and hole
  square come from Adafruit's EagleCAD board file, stored in `input/adafruit-5880/` with
  the numbers read from it; the encoder's body height (6.5 mm from the mounting surface),
  the 12.5 x 13.2 mm body, the M7 x 0.75 bushing, the 6.0 mm shaft with its 4.5 mm flat
  and the bushing length per shaft length (5.0 mm for the 15 mm shaft, 7.0 for 20 mm and
  longer) come from the Bourns PEC11 datasheet (rev. 05/11, cited under Sources). All of
  them match the model. Not measured yet: the washer's outer diameter and the nut across
  its corners, which must fit the 14 mm spot-face (an M7 nut and washer are about 11 to
  12 mm).
- **Where:** the shafts leave the back face at (+-47, -25) mm in the shell's coordinates,
  i.e. 19 mm in from each side edge and 41 mm up from the bottom edge, one knob per side.
  That spot is clear of the (+-56.85, 0) and (+-44, -56.85) bosses and the controller
  (x = -16..26), and needs no extra shell depth.
- **How they mount:** each board lies parallel to the back face, component side towards the
  wall. Four 4.5 mm posts hang from the cavity back and end in 2.2 mm pegs that enter the
  board's holes, so the board cannot turn. The bushing passes through a 7.4 mm hole; a
  14 mm, 0.4 mm-deep spot-face on the outside gives the supplied washer and nut a flat seat
  on the sloping wall and 4.0 mm of thread (the 6.0 mm bushing stands 3.6 mm proud of the
  face).
  The nut takes the knob's push force; the pegs only key the board.
- **Numbers** (printed by the `echo` lines): cavity 15.2 mm deep at the encoder; board
  bottom 7.2 mm behind the frame back face (ledge top is at 3.1 mm); posts 8.3 mm from the
  nearest boss; board edge 4.5 mm from the side wall; shaft 12.6 mm proud of the face; knob
  end 35 mm behind the frame back face with the user's 15.5 mm knob. The knobs are
  therefore the deepest point of the shell, 13 mm past the bottom edge: the display stands
  exactly as without them, but laid on its back it rests on the knobs.
- **Vents:** the lower band loses its outer two columns on each side (x = +-36 and +-42)
  where the boards sit; p64a keeps them.
- **Board orientation:** the side wall is only 4.5 mm from the board's outer edge, so turn
  each board with its two STEMMA QT sockets facing up and down and the header pads towards
  the centre (`enc_rot`). The cables then run vertically past the boards.
- **Wiring (not part of the shell):** the two boards chain on the controller's 4-pin SH1.0
  "GPIO" socket (pin 1 = IO45, 2 = IO46, 3 = 3V3, 4 = GND) used as a second I2C bus. The
  STEMMA QT pin order differs, so use an SH-to-header cable pair rather than a straight
  SH-SH cable; IO45/IO46 carry 10 k pull-downs on the controller, so add 2.2 k pull-ups to
  3V3 on SDA and SCL. Second board: close jumper A0 (address 0x37).
  The complete wiring projects, with schematics, bench procedure and firmware plan, are
  `../docs/hardware/encoders-solderless.md` (one encoder, no soldering) and
  `../docs/hardware/encoders-soldered.md` (two encoders, soldered); both belong to p64b.
- **p64a:** `encoders = false` removes the posts, the bushing holes and the spot-faces and
  gives the lower vent band its four outer columns back; nothing else moves.

## Edges

Every outer edge is softened for the hand; the pocket and the inner walls stay sharp for
an accurate fit. With `edge_back_c`, `edge_rim_r`, `edge_base_r` and `cb_chamfer` set to
0 the sharp-edged body comes back exactly.

- **Back face perimeter:** a 45-degree chamfer, 1.4 mm (`edge_back_c`). This edge is the
  bed side of the print, where a fillet would start as a horizontal overhang; a chamfer
  prints clean. 1.4 rather than 1.5 because the top wall and the base meet the back face
  at 96 degrees, not 90, which brings the chamfer closer to the cavity: the material left
  on the corner diagonal (cavity edge to chamfer plane) is 2.02 mm at the top edge, 2.12 at
  the sides and 2.36 at the bottom, printed by the `edges:` echo line; 1.5 mm would leave
  1.95 at the top. The chamfer wraps each rounded corner as a cone. On the back face it
  ends 1.95 mm from the USB window's own chamfer and over 4 mm from the nearest counterbore.
  The bed footprint is 129.6 x 130.3 mm.
- **Front rim:** a 1.5 mm fillet on the outer edge (`edge_rim_r`). The rim is the end of
  the 2 mm wall, so 0.5 mm of flat remains next to the panel; the pocket edge itself stays
  sharp and the fit against the frame is unchanged.
- **Base front edge:** a 3 mm fillet (`edge_base_r`) on the acute 78-degree edge under the
  LED face, the sharpest edge of the shell and the front line of the base. It is backed by
  the solid wedge. The base's front contact line moves back 3.7 mm and the back chamfer
  moves the rear one forward 1.4 mm, so the contact patch is 31.2 mm deep instead of 36.3;
  the centre of gravity stays about 8 mm in front of the rear contact line, so a backward
  push of about 7 degrees tips it. Along the two front-bottom corners the 3 mm rounding
  blends into the rim's 1.5 mm and the vertical corners' 2.6 mm (the most a uniform 2 mm
  wall allows against the frame's sharp corners).
- **Counterbores:** a 0.5 mm chamfer on the six mouths (`cb_chamfer`), where the fingers
  land on the back.
- **Flat by design:** the encoder spot-faces (they must stay flat for the nut).
- **How it is built:** `outer_body()` is the hull of thin sections of the envelope, each
  with every bounding plane moved inwards by its own amount: a stack of 13 sections
  sweeps the rim fillet (7.5 degrees per facet, like `$fn = 48`), a capsule of two spheres
  makes the base bar, two sections make the back chamfer. Each section keeps a corner
  radius of `r_out` minus its inset, so the vertical corners still come out at 2.6 mm.
- **Printing:** the chamfer rises from the bed at 45 degrees along the two straight sides
  and at 42 degrees along the top and bottom edges (those two walls overhang 6 degrees),
  1.4 mm tall, no support. The fillets are at the top of the print. Elephant-foot
  compensation matters less for the outline (the first layer is inside the chamfer) but
  keep it for the holes. `render_section_edge.png` shows the profile through x = 33
  (`part = "section_edge"`, a cut clear of every feature).

## Assembly

Before the first assembly, once:

1. Cut the frame notch (see the window section), push an adapter onto each port (it only
   goes one way, body towards the frame's edge) and check that both seat fully with their
   bodies clear of the frame's wall.
2. Dry-fit: panel with adapters into the shell, the bodies through the insert's U and the
   insert between the two rails, no glue. Check that the insert lies flat on the cavity
   back with the sole's arms overlapping the wall beside the window.
3. Put a thin bead of cyanoacrylate on the sole's back face along its outer edge only (or
   a strip of double-sided tape), well away from the opening, seat the panel with the
   adapters carrying the insert, fit two screws, and let it cure. The adapters position the
   insert; the shell only receives it. From then on the bodies slide into the U as the
   panel seats.

Every time:

1. Plug the controller onto the panel's HUB75 IN header and wire its 5V/GND screw terminals
   to the panel's VH4 power socket, exactly as in Waveshare's photo (ignore the speaker).
   Push the two adapters onto the ports.
2. p64b: plug the STEMMA QT cables into both encoder boards; from inside the shell push each
   board onto its four pegs with the shaft through the wall; from outside fit the washer
   and nut (hand-tight, 10 kgf.cm max) and then the knob; connect the chain to the
   controller's GPIO socket.
3. Slide the panel into the shell from the front with the controller at the **bottom**
   (USB-C ports pointing at the wedge). It seats on the ledge and the six bosses; the
   adapter bodies enter the insert.
4. Fit six M3 x 10 screws from the back. The heads sit 17 mm deep, so use a long PH1 or
   hex driver.
5. Plug the cables into the adapters through the back window, straight, 2.9 mm deep: POWER
   (power only) on the left seen from the back, USB (power + programming) on the right,
   marked by the groove.

Screws: none shipped with the panel or the controller. Buy six M3 x 10 (socket head cap or
pan head, head 6 mm or less for the 6.5 mm counterbore; not countersunk). Nothing else is
screwed: the encoder boards bring their own bushing nut and washer, the adapters simply
stay plugged in, and the insert takes a drop of cyanoacrylate or a strip of tape.

## Printing

- Print `p64_enclosure_print.stl` from your variant's folder as delivered: it already lies
  on its inclined back face, no supports needed. The walls lean 6 degrees, the base face
  overhangs 6 degrees, the ledge underside is 45 degrees, there are 6.5 mm bridges over the
  screw counterbores, the 1.4 mm edge chamfer rises from the bed (first layer
  129.6 x 130.3 mm), the two rails and (p64b) the encoder posts stand up from the cavity
  back, and the window's chamfer is a 45-degree overhang that starts at the bed. Print
  height 35.7 mm; about 82 g of PLA with 20 percent infill.
- Print `p64_cradle_insert.stl` too: sole down, no support, under 2 g; its walls lean
  6 degrees (they follow the adapter bodies, the sole follows the sloping cavity back). If
  the opening comes out tight, a file pass fixes it; loose is fine.
- 0.2 mm layers, 3 to 4 perimeters, 20 percent infill, PLA or PETG.
- For FDM use the 0.3 mm `p64_enclosure_print.stl`: the 0.45 mm `_service.stl` printed in
  PLA left the panel with slight side play (see below). Keep the 0.45 mm file for MJF/SLA.
- Enable elephant-foot compensation (0.1 to 0.2 mm) so the screw counterbores and the
  grooves stay clean on the first layer.
- p64b: the pegs are 2.2 mm pins; MJF nylon prints them fine, for FDM check the fit and
  sand if needed. The spot-faces sit on the bed face and become a 3.3 mm-wide bridge ring
  at the third layer, which is harmless.
- Bed needs at least 140 x 140 mm.

## Verified against the Waveshare drawing

`input/RGB-Matrix-P2-64x64-2D.dwg` (identical to Waveshare's GitHub copy) contains
the plastic frame ("JXS-P2-128*128 bottom case") and the LED mask, not the PCB. Checked:

| Item | Drawing | Model |
|---|---|---|
| Six M3 inserts | (0, +-56.85), (+-56.85, +-44), M3, on dia 9.8 faces | same to 0.01 mm; boss dia 10.5 |
| Frame outline | 127.8 x 127.8, sharp corners, 12 mm deep, no draft | pocket 128.4 (0.3 mm per side), corner r 0.6, lip 12 |
| Outer wall / rim for the ledge | 1.6 mm thick (inner face at +-62.3) | ledge 1.6 mm, sits fully on the wall; the wall is the physical bound of the adapter bodies |
| Back opening | +-51.9, widening to ~+-58.4 for y within +-16 | USB-C ports fall inside the wide part; the frame notch cuts the plate strip between 58.4 and the wall |
| Corner screw recesses | dia 6 at (+-56, +-56), M1 x 6 screws | inside the cavity, 3.7 mm from the ledge |
| Pins | dia 3 x 3 mm at (+-56, -29) | inside the cavity, clear of ledge and bosses |

The controller's own dimensions come from `input/ESP32-S3-RGB-Matrix-2D.pdf` (1:1 vector PDF).

## Things that could not be verified

| Input | Value used | Parameter | Notes |
|---|---|---|---|
| Centre of the panel's HUB75 IN header | (-35.0, +5.4) mm from the panel centre, panel arrows up, seen from the back | `hub75_in_native` | From the product photo, +-1 mm. The pin holes (3 mm), mic holes (3.5 mm) and the USB-C window (`tol_pos`) are sized to absorb that error. With this value the chip's edge overhangs the frame rim by 0.8 mm, which fits the photo. v1 print: its 30 mm base pocket landed exactly on the two USB-C ports; whether the pin and mic holes land over the buttons and mics is not checked yet. |
| Height of the controller PCB's back face above the frame's back face | 0.5 mm | `z_chip` | Must be 0 or more because the chip edge overhangs the rim; 0 to 1 mm is budgeted (`tol_z`). v1 print: with the panel seated there is a visible gap between the controller and the back wall, so the value is safe. |
| 90-degree adapter: boot gap between its body and the receptacle face | 1.2 mm | `ad_gap` | 7.7 mm plug protrusion minus a 6.5 mm plug shell, from the measured photo. Sets how far below the ports the bodies hang; +-0.5 mm is budgeted (`tol_gap`). Measure the seated adapter after notching the frame. |
| 90-degree adapter: corner radius of the body cross-section | 3.0 mm | `ad_r` | From the photos, looks like 3.5 to 4. A smaller value in the model only makes the insert's and the window's corners tighter than needed. |
| FDM print allowance | 0.25 mm per side of an opening | `print_clr` | A guess from the v1 print (outside +0.3 mm per side, holes "clean"). Measure the v7 window against the model when it arrives. |
| LED board / mask outline | 128.0 mm | `board` | Waveshare's quoted panel size; the drawing has the frame (127.8) and not the board. The rim runs 1.5 mm beside the board with 0.2 mm clearance per side (`board_clr`). Measure the board and the mask at their widest; if over 128.0, set `board` and the pocket steps out (the wall there drops below 2 mm past 128.0, the echo warns). |
| LED board + mask thickness in front of the frame | 2.5 mm | `panel_stack` | From the v1 print, where the mask stood 2.5 mm proud of a rim that ended at the frame. Sets the lip together with `proud`. |
| Encoder washer outer diameter and nut across corners (p64b) | under 14 mm | `enc_spot_d` | Not measured yet; the 14 mm spot-face must take both. Everything else about the 5880 was measured on 2026-09-22 (`input/measurements.md`). |

## Verified with the v1 print

The pocket, ledge, bosses, wedge, vents and pin/mic holes of v7 are those of v1, the
first version, whose 0.45 mm-clearance file (`archive/pre-v7/output/v1/p64_enclosure_service.stl`)
was printed by JLC3DP in black FDM PLA (order of 2026-09-05, received 2026-09-18, $18.83
including shipping). Checked by hand the same day; measurements in `input/measurements.md`,
photos `input/PXL_20260918_*.jpg`.

| Item | Result |
|---|---|
| Overall size | 133.0 mm wide (model 132.4, +0.6 mm), 34.6 mm deep at the bottom edge (model 34.6). |
| Screw bosses | All six line up with the panel's inserts. The 3.4 mm holes and 6.5 mm counterbores printed clean; a screw drops in without cleaning. |
| Panel in the pocket | Drops in by hand with slight side play, under 1 mm, at 0.45 mm clearance. Next FDM print: use the 0.3 mm `p64_enclosure_print.stl`. |
| Seating | The frame rests on the ledge all round and the LED mask stands about 2.5 mm proud of v1's rim, which ended at the frame (v7's rim runs 1.5 mm further, so the mask stands 1.0 mm proud). |
| USB-C ports | v1's 30 mm base pocket landed exactly on the two ports (v7 has a window in the back instead). |
| Controller clearance | Visible gap between the controller and the back wall with the panel seated. |
| Back face | Groove marks legible, vent slots, pin holes and mic holes clean; the 2 mm minimum-feature rule held. |
| Stand | Stable at the 12 degree lean; the front-bottom bar was confirmed on the real part. |
| Heat | Barely warm after running for a while; PLA is fine at the brightness used. |
| Not checked yet | Pin holes and mic holes over the buttons and mics (press BOOT through the hole with a pin). |

## Main parameters (`src/p64_enclosure_v7.scad`)

- Shell: `depth_bottom` 22, `depth_top` 8 (set equal for a flat back), `tilt` 12, `proud`
  1.0 with `panel_stack` 2.5 and `frame_d` 12 (the lip, 13.5, is derived), `board` 128.0,
  `board_clr` 0.2, `wall` 2, `back_t` 2.4, `panel_clr` 0.3; screws `screw_len` 10, `engage` 5, `cb_d` 6.5,
  `boss_od` 10.5; `panel_rot` 90; back wall `vents`, `pin_d` 3, `mic_d` 3.5, `mic1_off`
  [0.5, 1.6]
- Edges: `edge_back_c` 1.4, `edge_rim_r` 1.5, `edge_base_r` 3, `cb_chamfer` 0.5 (all 0 =
  the sharp-edged body)
- Adapters and window: `adapters`, `ad_*` (the measured adapter), `ad_win_chamfer` 0.5,
  `ad_mark`; the budget `tol_pos` [1, 1], `tol_gap` 0.5, `tol_body` 0.2, `tol_z` 1.1,
  `print_clr` 0.25, `win_slack` 0.1; `ledge_relief`
- Insert: `ins_clr` [0.3, 0.5], `ins_depth` 6, `ins_sole_t` 1, `ins_wall_t` 2, `ins_bot_t`
  1, `ins_lap` 3, `ins_top_cut` 2.5, `ins_rails`, `ins_rail_h` 1.2, `ins_rail_t` 1.5
- Encoders: `encoders` (the variant switch), `enc_pos`, `enc_rot`, `enc_bush_l`,
  `enc_spot_t`, `enc_post_d`, `enc_peg_d`, `enc_keepout`
- `part` selects `shell`, `print`, `assembly`, `section_ad`, `section_win`, `section_y`,
  `section_enc`, `section_edge` (cut at `section_edge_x`), `product`, `frame`, `insert`

## Regenerating the outputs

Render the variant files, never the source directly, so the output lands in its folder.
p64b (`v7b`) below; p64a is the same with `p64a/v7a` and `_v7a.scad`, minus
`render_section_enc.png`:

```
openscad -o output/p64b/v7b/p64_enclosure_print.stl   -D "part=\"print\""  src/p64_enclosure_v7b.scad
openscad -o output/p64b/v7b/p64_enclosure_print.3mf   -D "part=\"print\""  src/p64_enclosure_v7b.scad
openscad -o output/p64b/v7b/p64_enclosure_service.stl -D "part=\"print\""  -D panel_clr=0.45 src/p64_enclosure_v7b.scad
openscad -o output/p64b/v7b/p64_cradle_insert.stl     -D "part=\"insert\"" src/p64_enclosure_v7b.scad
```

The renders are previews (no `--render`), 1600 x 1200, Metallic scheme:

```
openscad -o output/p64b/v7b/render_back.png         -D "part=\"shell\""        --imgsize=1600,1200 --projection=p --colorscheme=Metallic --camera=-235,-327,307,0,-12,-8 src/p64_enclosure_v7b.scad
openscad -o output/p64b/v7b/render_assembly.png     -D "part=\"assembly\""     --imgsize=1600,1200 --projection=p --colorscheme=Metallic --camera=-235,-327,307,0,-12,-8 src/p64_enclosure_v7b.scad
openscad -o output/p64b/v7b/render_section_enc.png  -D "part=\"section_enc\""  --imgsize=1600,1200 --projection=p --colorscheme=Metallic --camera=-252,-48,94,60,0,8 src/p64_enclosure_v7b.scad
openscad -o output/p64b/v7b/render_print.png        -D "part=\"print\""        --imgsize=1600,1200 --projection=p --colorscheme=Metallic --camera=-270,-350,270,0,0,15 src/p64_enclosure_v7b.scad
openscad -o output/p64b/v7b/render_product.png      -D "part=\"product\""      --imgsize=1600,1200 --projection=p --colorscheme=Metallic --camera=300,495,180,0,0,66 src/p64_enclosure_v7b.scad
openscad -o output/p64b/v7b/render_product_back.png -D "part=\"product\""      --imgsize=1600,1200 --projection=p --colorscheme=Metallic --camera=308,-440,283,0,0,60 src/p64_enclosure_v7b.scad
openscad -o output/p64b/v7b/render_section_ad.png   -D "part=\"section_ad\""   --imgsize=1600,1200 --projection=p --colorscheme=Metallic --camera=110,-120,55,-6,-50,8 src/p64_enclosure_v7b.scad
openscad -o output/p64b/v7b/render_section_win.png  -D "part=\"section_win\""  --imgsize=1600,1200 --projection=p --colorscheme=Metallic --camera=15,-180,45,0,-55,10 src/p64_enclosure_v7b.scad
openscad -o output/p64b/v7b/render_frame_notch.png  -D "part=\"frame\""        --imgsize=1600,1200 --projection=o --colorscheme=Metallic --camera=0,-48,170,0,-48,0 src/p64_enclosure_v7b.scad
openscad -o output/p64b/v7b/render_section_edge.png -D "part=\"section_edge\"" --imgsize=1600,1200 --projection=o --colorscheme=Metallic --camera=333,-4,5,33,-4,5 src/p64_enclosure_v7b.scad
openscad -o output/p64b/v7b/render_insert.png       -D "part=\"insert\""       --imgsize=1600,1200 --projection=p --colorscheme=Metallic --camera=40,-60,50,0,0,2 src/p64_enclosure_v7b.scad
openscad -o output/p64b/v7b/render_window.png       -D "part=\"assembly\""     --imgsize=1600,1200 --projection=o --colorscheme=Metallic --camera=0.3,-57,21,-6,0,0,60 src/p64_enclosure_v7b.scad
```

`render_frame_notch.png` looks straight at the back of the panel (orthographic);
`render_section_edge.png` looks at the cut face from +X (the base on the left, the back
face on top); `render_window.png` uses the gimbal camera form, straight at the back face
around the window, the mic1 hole at the top right. `part = "product"` stands the assembled
shell on its wedge foot (front towards +Y, leaning back 12 degrees, base on z = 0) with a
black LED-face mock-up and a table slab. The `echo` lines of every render print the
margins named in this README.

## Sources

- Panel drawing: https://github.com/waveshareteam/RGB-Matrix-Px-xx/tree/main/hardware/dimensions/RGB-Matrix-Pxx-64x64 (`RGB-Matrix-P2-64x64-2D.dwg`)
- Controller drawing: https://github.com/waveshareteam/ESP32-S3-RGB-Matrix/tree/main/hardware/dimensions (`ESP32-S3-RGB-Matrix-2D.pdf`)
- Wikis: https://docs.waveshare.com/ESP32-S3-RGB-Matrix and https://docs.waveshare.com/RGB-Matrix-Px-64x64
- Encoder board (p64b): https://www.adafruit.com/product/5880 and its EagleCAD files
  https://github.com/adafruit/Adafruit-I2C-QT-Rotary-Encoder-PCB (the board file is
  stored in `input/adafruit-5880/`, CC BY-SA)
- Encoder (p64b): Bourns PEC11 datasheet, rev. 05/11, https://cdn-shop.adafruit.com/datasheets/pec11.pdf
  (not stored: Bourns' copyright)
- Controller GPIO socket pinout (p64b): the schematic in
  https://github.com/waveshareteam/ESP32-S3-RGB-Matrix/tree/main/hardware/schematics
- 90-degree USB-C adapter: a generic aluminium-shelled male-to-female right-angle adapter,
  no drawing; dimensions hand-measured (`input/measurements.md`).

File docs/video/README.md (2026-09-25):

# The p64b concept video

A 50-second rendered concept video of p64b (the variant with the two rotary encoders),
built from the v7b enclosure model, the mock-ups in the same OpenSCAD source and the
firmware's own assets: the panel plays four animations from the host-test GIF corpus, the
clock and weather faces are drawn with the firmware's bundled pixel fonts and weather
icons, and a plasma stands in for a live stream. Made on 2026-09-24 for the public: what
p64 is, what is inside it, and what it does. The device on screen is the model, not a
photo: nothing of v7 has been printed yet (see `enclosure/README.md`).

The video itself (`docs/p64b-concept-v4.mp4`, 1920 x 1080, 30 fps, H.264, silent; `-audio.mp4`
with the music bed) is
not committed, to keep the repository small; this folder holds everything that makes it,
so one command regenerates it. `build/` is git-ignored.

Versions so far, all kept side by side in `docs/` (git-ignored): **v1**, the first cut
(twelve captions of 1.5 to 3 s, two lines each); **v2**, the same render after the user
found v1's text too much and too brief (seven captions of 3 to 4.6 s, one line each);
**v3** (`p64b-concept-v3-draft*.mp4`, 15 fps drafts), a new render: the explosion flies out
horizontally (the tilted axis had sent parts under the table) with outer parts leading
(a shaft no longer pokes through its knob), the user's artworks, the clock fixed,
brighter LEDs under PBR Neutral, the haze; **v4** (the current video, rendered at 96 samples on 2026-09-24) adds the knob
scene, 45 s in all: after the reassembly the camera settles behind the device, which sits
in the left half of the frame, and a "virtual screen" (the front of the panel, drawn flat
in the right half by `compose.py` from the same baked LED frames) shows what each knob
does as it turns and is pressed: A dims and brightens, A pressed blanks the panel (pause) and resumes, B
steps to the next and the previous artwork, B pressed likes (a heart). The knobs are
separate pieces on pivots with a pointer line each (`pieces.scad`), and a faint point
light marks the active knob. The 30 s timelines of v1 to v3 are in git history (commit
d682551).

## Regenerate

Needs OpenSCAD 2021.01 (`C:\Program Files\OpenSCAD`), Blender 5.2 (`C:\Program Files\
Blender Foundation\Blender 5.2`; Cycles on the GPU, OptiX or CUDA, the CPU works but is
slow), ffmpeg on the PATH, and a Python with Pillow and numpy (the system one). From
`docs/video/` in PowerShell 7:

```
.\make.ps1            # everything below, in order; the v4 pass (96 samples, the haze and the glow light)
                      # takes several hours on an RTX 5050 laptop, depending on the GPU's power state
.\make.ps1 -Quick     # 16 samples and every fourth frame, for a look at the motion (7.5 fps)
```

The steps, if you want one of them alone:

| Step | Command | What it does |
|---|---|---|
| 1 | `openscad -o build/values.echo -D piece="values" pieces.scad` and one `-o build/<piece>.stl -D piece="<piece>"` per piece | `pieces.scad` includes the enclosure source with `encoders = true` and exports each mock-up (panel frame, LED board, controller, adapters, cradle insert, encoder boards, knobs, screws) as its own STL in the shell's design coordinates, plus the numbers Blender needs. |
| 2 | `python bake_leds.py` | One 64 x 64 PNG per video frame in `build/leds/` (what the panel shows, from `storyboard.PANEL`), and the LED aperture mask. |
| 3 | `blender -b -P scene.py -- [--start N --end N] [--step N] [--samples N] [--frames a,b,c]` | Builds the scene (the committed `enclosure/output/p64b/v7b/p64_enclosure_print.stl` un-printed back into design coordinates, the pieces, the LED face with the baked sequence, a dark studio, the camera and the explosion from `storyboard.py`), saves `build/p64b.blend`, renders `build/frames/`. |
| 4 | `python compose.py [--frames a,b,c]` | Bloom around the LEDs, the virtual screen of the knob scene, fades, captions, the end card; encodes `../p64b-concept-v4.mp4` with ffmpeg (about 13 min for the 1500 frames). ||| 4 | `python compose.py [--frames a,b,c]` | Bloom around the LEDs, the virtual screen of the knob scene, fades, captions, the end card; encodes `../p64b-concept-v4.mp4` with ffmpeg (about 13 min for the 1500 frames). |

| 5 | `python audio.py --mux ../p64b-concept-v4.mp4 ../p64b-concept-v4-audio.mp4` | The soundtrack: a warm, slow ambient synth bed synthesised from scratch (filtered detuned sawtooth pads over eight added-ninth chords in D, a sine sub bass, a sparse plucked motif, a soft pulse under the explosion and the finale, a synthetic reverb; no samples, nothing to license) with subtle effects from `storyboard.py` (a filtered whoosh as the parts fly out and back, clicks on every knob detent and press, a small chime on the like), normalised to -18 LUFS with ffmpeg's loudnorm and muxed into a copy of the silent video (the video stream is copied). The silent MP4 stays; the one with sound is `docs/p64b-concept-v4-audio.mp4`. A first, lo-fi chiptune version with a drum kit was discarded the same day (2026-09-25) at the user's request. |

`storyboard.py` is the one place with every time: the camera beats, the explosion, what
the panel shows, the captions. Change it and rerun from step 2 (the panel) or 3 (camera,
explosion) or 4 (captions only: a captions change needs no re-render).

## What is in the 50 seconds (v4)

| Time | Picture | Caption |
|---|---|---|
| 0 to 4 s | Front three-quarter view, the hero artwork playing | what p64 is, size |
| 4 to 8 s | Orbit to the back: the vents, the six screws, the USB-C window, the two knobs; the explosion begins | the back of the shell |
| 8 to 15 s | Exploded view from the side, panel to screws: panel, controller, adapters, insert, encoder boards, shell, nuts and knobs, screws | the panel and the driver board; the print, the adapters, the screws |
| 15 to 20 s | The camera swings to the front-right and above and looks into the shell's cavity (the seating ledge, the six bosses, the encoder posts, the vents from inside), a light in there fading in and out, then flies back | inside the shell |
| 20 to 23 s | Everything comes back together while the camera moves behind the device | no soldering for p64a, p64b adds the knobs |
| 23 to 37 s | The knob scene: the device in the left half, the virtual screen in the right; knob A turns down and up, is pressed twice; knob B turns forward and back, is pressed | knob A: brightness, press to pause; knob B: next / previous, press to like |
| 37 to 39 s | The virtual screen fades, the camera returns to the front | |
| 39 to 48 s | Feature beats on the panel: Van Gogh, the digital and analogue clocks, the weather, a live-stream plasma, the living room | card and Makapix Club, clock, weather; streams and the web UI |
| 48 to 50 s | End card | logo, repository, licence |

## Honest notes

- The mock-ups are the enclosure source's own (`ghost_*` modules): boxes and cylinders in
  the right places and sizes, not the real boards' shapes. The screws are modelled here
  (`pc_screws` in `pieces.scad`), M3 x 10 pan heads sitting 1 mm below the back face.
- The LED face is a 64 x 64 texture behind a grid of rounded apertures on a glossy black
  body, a look, not the panel's optics; the real GOB panel diffuses more.
- The artworks (since v3) are the user's selection in `docs/video/artworks/` (animated
  64 x 64 WebP; `f12030f3...` is the hero piece and leads; the sunset, the Van Gogh and the
  living room follow), read with their own frame durations from the ANMF chunks. v1 and
  v2 used corpus GIFs from `firmware/tests/host/corpus/gifs/`; `storyboard.PANEL` takes
  either (`art:` or `gif:`). The LED face's emission is `P64_LED_STRENGTH` (default 4.5 under
  the Khronos PBR Neutral view transform, `P64_VIEW`, whose highlights roll off; v1 and v2
  used Standard at 9, which clipped pale artworks to white; AgX was tried and desaturated
  the LEDs). A scattering volume around the device (`P64_HAZE`, default 0.10 per
  metre, 0 removes it) lets the LEDs light the air in front of them (the user's request
  of 2026-09-24: brighter LEDs with volumetric light). The studio lights are unlinked
  from the volume (Cycles light linking), otherwise their scatter greys the scene and
  swamps the panel; and since the emissive LED face alone scatters too little to read,
  an area light on the face, coloured and dimmed per frame from the baked picture's mean
  (`build/led_mean.json`, written by `bake_leds.py`) and linked to the volume only, does
  the visible glow (`P64_GLOW_W`, default 1.2 W at a full-white panel; 4 W washes the
  picture out, 40 W whites the frame).
- The analogue clock ticks once per second of video time since v3 (v1 and v2 ran it six
  times too fast).
- v4's other look decisions, all the user's: the LED face and mask are matte (the glossy
  coat reflected the key light as a hot spot), the studio lights dim to 12 % for the last,
  frontal stretch (`storyboard.STUDIO_DIM`), a paused panel is off, the stream plasma
  runs at 55 %, the active knob is marked by a floating emissive ring that exists only
  while lit, and the exploded view gets a look into the shell's cavity with its own light.
- Nothing here is measured. The video is a concept render of the v7b model as designed.

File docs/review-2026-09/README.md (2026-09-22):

# Architecture review, September 2026: memory, CPU and testing discipline

Written 2026-09-22 (session prompt `prompt/p021-architecture-discipline-review.txt`),
three days after the product firmware reached M10. The question was whether there are
major breaking changes, including dropped features, that would improve the firmware's
memory, CPU or testing discipline if made now.

The answers, in one paragraph: internal RAM is the only resource in trouble, and it is in
real trouble (13 to 23 KB free at steady state against a 64 KB target, with a low-water
mark of about 1 KB seen on the device today); CPU is not a problem anywhere (core 0 is
3 to 5 % busy, core 1 is 9 to 44 % busy depending on the artwork) and no feature is
worth dropping for it; testing is strong for the pure layers and absent for the state and
timing code where the bugs have been. Two breaking changes are recommended: replace the
MQTT-over-mTLS session with an HTTPS command channel on the fetcher's single TLS slot
(the server's own roadmap already names it), and split the show, renderer, player and
fetcher into pure cores with thin shells so the host can test them. Around those, a set
of measured, non-breaking memory trims and a testing practice (framework, CI, budgets,
the written rule) do the rest. No feature needs to be dropped; streams are the one
candidate for demotion to a compile-time option.

## Files

| File | What it holds |
|---|---|
| `memory.md` | measurements taken today (heap by task, two configuration experiments, the low-water mark), the findings, and what each feature costs in internal RAM |
| `cpu.md` | measured per-task CPU shares at idle and under a 128x128 WebP, the findings, and the drop-a-feature table |
| `testing.md` | what is protected and what is not, the fifteen untested fixed bugs, and the practice changes |
| `proposals.md` | the ranked roadmap: every proposal with its measured or estimated gain, its cost, its risk, and whether it breaks anything |
| `tier1-results.md` | what tier 1 of the roadmap did on 2026-09-22 (prompt p022): the commits, the measurements before and after, the verification of the configuration change |
| `steps3-4-results.md` | what the next session did (prompt p024): doctest and GitHub Actions, and the first pure cores (timing, settings, the Makapix contract, the show's rules), with what their tests found and what remains |
| `step4-results.md` | the rest of step 4 (prompt p025): the fetcher policy, the show core behind `ShowEnv`, the WebSocket test, the seams, and the two latent bugs their tests found |
| `evidence-memory.md` | the code inventory behind `memory.md`: every task, allocation and config item, with file and line |
| `evidence-cpu.md` | the code inventory behind `cpu.md`: every periodic activity, per-frame path, event handler and blocking hazard |
| `evidence-testing.md` | the code inventory behind `testing.md`: coverage by file, seams graded, the device scripts, the regression table |

## Decisions the review was made under

Asked with the tool at the start of the session and answered by the user:

- Makapix Club and the operations layer (web UI, PIN, OTA) are not candidates for
  removal. Everything else may be proposed.
- The device may be measured and flashed freely; the committed build is restored at the
  end. (Done: the device runs the committed build again; the instrumentation lives on
  the branch `review/cpu-instrumentation`.)
- Testing proposals may go as far as a framework, CI and a hardware lane; the user then
  chose GitHub Actions for the host tests and the firmware build, with the device lane
  staying manual.
- The server side of Makapix is open to change (the user owns makapix.club).
- The internal-RAM target is 64 KB free with a 32 KB largest block at steady state.
- Of the non-sacred features the user uses the weather and temperature widgets, the IMU
  and the clock; not the streams.
- The review session proposed only; tier 1 of the roadmap was executed the same
  afternoon under prompt p022 (`tier1-results.md`).

## Method

1. Three code audits (memory, CPU, testing) over `components/p64_*` and `main/`, each
   producing an inventory with file and line references (the `evidence-*.md` files).
2. Measurements on the paired development device: the linker map and `idf.py size`,
   the diagnostics API before and after a reboot, a boot log over the serial console, and
   an instrumentation build (per-task run time and heap-by-task attribution added to
   `GET /api/v1/diag/memory`) sampled at idle and under load.
3. Two configuration experiments flashed and measured (the always-internal malloc
   threshold; Wi-Fi and FreeRTOS code moved out of internal RAM), because they are the
   cheapest candidate levers and estimates for them are unreliable.
4. Synthesis into findings and a ranked roadmap.

## Instrumentation

The measurements used a branch, `review/cpu-instrumentation`, whose one commit was
cherry-picked into main the same day (tier 1, `tier1-results.md`): per-task `run_time`
and `core` in `diag/memory` are always on (`CONFIG_FREERTOS_GENERATE_RUN_TIME_STATS`,
no measurable cost), and the `heap_by_task` array appears when a build sets
`CONFIG_HEAP_TASK_TRACKING` (about 4 KB of internal RAM, so off by default). The
sampling script is `firmware/tools/cpu_sample.py`.

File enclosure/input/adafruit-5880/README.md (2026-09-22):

# Adafruit I2C QT Rotary Encoder board file (Adafruit 4991 / 5880)

`Adafruit I2C QT Rotary Encoder.brd` is the EagleCAD board file of Adafruit's I2C STEMMA QT
rotary encoder breakout, copied unchanged on 2026-09-22 from
https://github.com/adafruit/Adafruit-I2C-QT-Rotary-Encoder-PCB (commit `4b82c1319140`,
2021-05-11). Adafruit 5880 is this board with the encoder pre-soldered. Licence: Creative
Commons Attribution-ShareAlike 3.0 Unported (`license.txt`, Adafruit's copy), which is
why the file can live here; the encoder's datasheet (Bourns PEC11, Bourns' copyright) is
not stored, only cited: https://cdn-shop.adafruit.com/datasheets/pec11.pdf (rev. 05/11;
the same file sits in Adafruit's repository as `pec11.pdf`).

What the p64 shell takes from the board file (read with a small XML parse of the
`plain` outline, the `MOUNTINGHOLE_2.5_PLATED` elements and the `PEC11+SWITCH` footprint):

| Item | Board file | Shell parameter |
|---|---|---|
| Outline | 25.4 x 25.4 mm, 2.54 mm corner radius (four 90-degree arcs) | `enc_board` 25.4, `enc_board_r` 2.54 |
| Mounting holes | drill 2.5 mm, pad 3.2 mm, at (2.54, 2.54), (22.86, 2.54), (2.54, 22.86), (22.86, 22.86): a 20.32 mm square | `enc_hole_p` 20.32, `enc_hole_d` 2.5 |
| Encoder | footprint `PEC11+SWITCH` at the board centre (12.7, 12.7), rotated 45 degrees (`MR135`) | encoder at the centre, body at 45 degrees |
| STEMMA QT sockets | `JST_SH4` at (2.54, 12.7) and (22.86, 12.7): the middle of the left and right edges | `enc_rot` +-90 turns them up and down in the shell |
| Header | `1X06_ROUND_70` at (12.7, 2.54): the middle of the bottom edge | ends up towards the shell's centre |

Not in the board file: the PCB thickness (1.6 mm assumed, Adafruit's usual) and anything
about the encoder's height, which comes from the datasheet.

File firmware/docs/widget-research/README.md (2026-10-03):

# Widget research: new data sources and the competition

Research of 2026-10-03 (prompt p073): the material for a discussion about which widgets
p64 could grow next. Since then the shortlist's first entry, air quality and UV, was
built the same day (prompt p074, spec 7.4); nothing else here is implemented or decided.

Scope, as settled with the user before the research:

- Sources: keyless public APIs, and services that need a user-supplied key, token or
  OAuth (full OAuth acceptable where it is technically feasible).
- Architecture: **device-direct only**. The device fetches and renders by itself; no
  companion server, no project-run cloud.
- Subjects looked at hardest: sky, earth and nature; money and news; transit, sport and
  travel.
- Audience: any p64 builder, worldwide, so global coverage and little setup rank high.
- Competition: commercial pixel displays, open firmware projects, adjacent smart displays.

The files:

| File | What it holds |
|---|---|
| [competition.md](competition.md) | What comparable products ship as widgets and how they work technically |
| [keyless-sources.md](keyless-sources.md) | Public APIs that need no account or key, with measured response sizes |
| [keyed-sources.md](keyed-sources.md) | Key-paste and OAuth services, and what OAuth can be without a backend |

How far to trust the numbers: the keyless catalogue's sizes were measured on 2026-10-03
with plain `curl` from a US address. The keyed survey marks each claim as read on the
provider's documentation, taken from a search summary, or from memory; free-tier figures
change often and every one should be rechecked before anything is built on it. Nothing
was tested from the device.

## What the competition teaches

1. **The widget types everyone has**, in rough order of how often they appear: clock,
   weather, countdown/timer, follower counters, stocks/crypto/currency, sports scores,
   calendar/agenda, transit arrivals, now-playing with album art, "show my own data",
   message board, news, moon/sun, air quality, flights overhead. p64 has the first two
   (and astronomy inside the horizon face) and nothing of the rest.
2. **Almost nobody does it on the device.** Tidbyt/Tronbyt and TRMNL render on a server
   and send an image; AWTRIX, PixelIt and ESPHome are dumb renderers fed by Home
   Assistant or Node-RED; Divoom leans on its own cloud. The projects that fetch and
   render on a microcontroller are Pixelix, Adafruit's MatrixPortal guides and
   witnessmenow's libraries. p64's device-direct rule puts it in that smaller group:
   every widget is firmware code and every key sits on the device, but nothing dies when
   a server does (Tidbyt's end is the cautionary tale).
3. **The most used plugin, wherever it exists, is "poll my URL and show the value"**:
   TRMNL's Private Plugin (first by connections), LaMetric's My Data DIY, Pixelix's
   GrabViaRest. It is device-direct (the device polls; whatever answers is the owner's
   business), so it is inside the rule, and it is the one feature that lets others extend
   p64 without firmware changes.
4. **64x64 is a rare advantage.** Most rivals are 32x8 or 64x32 and reduce everything to
   icon plus scrolling text. Maps, boards, graphs and pictures (radar, chessboard, sky
   chart, contribution graph, album art) are what the small ones cannot do.
5. **Sports is Tidbyt's biggest category and has no microcontroller-only example** in
   the survey; the data is large, league-specific and mostly unofficial.

## What the sources survey teaches

- **Keyless and good**: Open-Meteo's other endpoints (air quality, UV, marine with a
  global tide curve), USGS earthquakes, NOAA SWPC space weather, ISS position and TLEs,
  RainViewer radar tiles (PNG), Frankfurter currency rates, Coinbase/CoinGecko/mempool
  for crypto, Nager.Date holidays, Jolpica F1, MLB (with a field filter), Lichess.
  Responses of 0.1 to 5 KB, cJSON-friendly.
- **Keyless but awkward**: flights overhead (11 to 43 KB, grows with traffic), TfL
  arrivals (27 KB), RSS headlines (15 to 32 KB of XML), Wikipedia "on this day"
  (138 KB), ESPN scores (76 to 287 KB, unofficial). All need a streaming parser.
- **No legitimate keyless stock quotes exist.** Stooq is behind a key since 2026; Yahoo
  is unofficial and against its terms. Stocks mean a pasted Finnhub key.
- **OAuth without a backend is clean on four services**: Microsoft Graph, GitHub, Twitch
  and Trakt accept the device grant with a public client ID and no secret. Google's
  device flow excludes Calendar. Spotify is effectively closed to an open-source project
  (five users per app, Premium, HTTPS or loopback redirects only), so each owner would
  register an app and paste a URL back; Last.fm gives now-playing with one key instead.
- **Calendar's practical route is the private ICS URL**; the cost is a recurrence
  engine and feeds of up to several MB through the single TLS slot.
- **Transit has no worldwide keyless source.** Transitland (key, 10,000 queries a month)
  is the widest aggregator; TfL, Switzerland and Norway are keyless.

## Three enablers that matter more than any one widget

| Enabler | What it unlocks | Cost to look at |
|---|---|---|
| A baseline JPEG decoder | Album art, daily museum art, APOD, satellite and sun images, thumbnails: nearly every image source serves only JPEG | Flash size, work RAM (expected small, unmeasured), a host-tested decoder path like the other three |
| A streaming JSON/XML reader | Flights, sports, TfL, RSS, Wikipedia: anything over ~16 KB that cJSON should not hold whole | A pure, host-testable file; no new RAM class |
| One shared fetch scheduler for widgets | Many small pollers sharing the single TLS slot politely, each with its cadence, its "last good value with age" and its stale rule (what weather does alone today) | Design work; every new host is a 12 to 13 KB TLS session while it lasts, one at a time |

Also common to all: an identifying `User-Agent` (Wikimedia, MET Norway, NWS and GitHub
require one), attribution lines in the web UI's About section, and trusted time before
any dated request (ADR 0011).

## Ranked shortlist

Ranked for any p64 builder by appeal against cost on p64 (internal RAM, the TLS slot,
legibility on 64x64, setup). This is a recommendation to argue with, not a plan.

| # | Widget | Source | Key | Why here | Main cost or risk |
|---|---|---|---|---|---|
| 1 | Air quality and UV | Open-Meteo air quality | none | Global, ~600 B, same provider and terms as weather; could be a page of the weather widget or its own | Pollen is Europe-only |
| 2 | Rain radar | RainViewer tile centred on the location | none | The most 64x64-native idea: one 10 to 16 KB PNG box-averaged 4x, animated from two hours of frames; no small rival can show it | Needs a base map (coastline) drawn on-device; radar coverage is not global; terms are personal use with attribution, no availability promise |
| 3 | Markets ticker | Coinbase or CoinGecko (crypto), Frankfurter (currency); Finnhub for stocks | none; a key for stocks | Fifth most common widget everywhere; 60 to 220 B responses; a sparkline has room on 64x64 | Stocks need a key; Binance is geo-blocked; history for the sparkline must be kept on the device |
| 4 | Sky tonight | SWPC Kp and scales, ISS TLE from CelesTrak with SGP4 on the device, planets computed | none | Extends what the horizon and orrery faces began; aurora chance from Kp and latitude; "ISS overhead in 12 min" is an event worth an interlude | SGP4 is new pure code to write and test; wheretheiss.at is one person's service |
| 5 | Countdown and holidays | User dates in settings; Nager.Date for the next public holiday | none | Third most common type across products; nearly no network | Mostly on-device, so partly outside this research's scope |
| 6 | Planes overhead | OpenSky (anonymous 400 credits a day, or the owner's client credentials for 4,000), adsb.lol | none or a pasted pair | High charm on an LED matrix, proven on ESP32 HUB75 | 11 to 43 KB and growing with traffic: wants the streaming reader; no route or aircraft type without a second source; non-commercial terms |
| 7 | Earthquakes | USGS query, radius and magnitude filter, 475 B as text | none | Official, public domain, global | Dull when nothing happens: better as an event that triggers an interlude than as a standing widget |
| 8 | Tides and waves | Open-Meteo marine | none | The only global keyless tide curve; a tide graph suits the panel | Coastal owners only; a model, not a harbour gauge |
| 9 | Generic "my data" | A URL the owner enters; a small fixed JSON shape (value, label, icon, series) | owner's own | The most used plugin on every platform that has one; opens Home Assistant, Apps Script and anything else without the project running a server | A contract to design and keep; plain-HTTP LAN sources and HTTPS ones both to serve |
| 10 | Calendar agenda | Private ICS URL (Google, Outlook, iCloud); Microsoft Graph by device flow as a second step | a pasted URL | The highest-appeal keyed source in every survey | A recurrence expander (pure, testable, but real work); multi-MB feeds hold the TLS slot 10 to 20 s; outside the three subjects chosen for depth |
| 11 | Next departures | TfL, Swiss, Entur keyless; Transitland with a key | mixed | Second-largest Tidbyt category | Per-region adapters and upkeep; finding a stop ID is the owner's burden; 10,000 queries a month on Transitland |
| 12 | Sport | Jolpica F1 (keyless, 0.8 to 2.4 KB); MLB with `fields=` | none | The clean ones are narrow | Broad live scores exist only as ESPN's unofficial 76 to 287 KB responses or behind paid tiers |
| 13 | Headlines | RSS (BBC, NPR, Al Jazeera) | none | Common on larger displays | Text-heavy content is the weakest fit for 64 px; streaming XML; publisher terms |

Noted but outside the subjects chosen for depth: Last.fm now-playing (one key; album art
needs the JPEG decoder unless its CDN really serves PNG, untested), the GitHub
contribution graph (device flow; 53x7 cells suit the panel), follower counters (Bluesky
and Mastodon keyless, YouTube with a key), the Lichess daily puzzle.

My own reading: 1 and 3 are the cheap wins on existing machinery; 2 and 4 are the ones
that would make p64 look like nothing else; 9 is the strategic one; the JPEG decoder and
the fetch scheduler are worth deciding before any of them, because they change what the
rest costs.

## Open questions for the discussion

- Are new sources new **widgets** (each with a main-state slot and an interlude gap), or
  **pages** of fewer widgets (weather grows air quality, radar, tides)? The settings and
  interlude model of spec 6.1 scales poorly to a dozen kinds.
- Event-driven interludes ("ISS overhead", "earthquake nearby", "aurora likely") do not
  exist in the spec; today interludes are a dice roll at each swap.
- How many pollers may be live at once against the 48 KB floor, and is there a ceiling on
  distinct TLS hosts per hour?
- Does a pasted key deserve the PIN to be mandatory, given the web UI is plain HTTP?
- Is the unofficial-source line (ESPN, Yahoo) "never" or "opt-in and labelled"?

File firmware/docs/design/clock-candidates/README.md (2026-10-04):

# Clock face candidates (prompts p043 to p046, 2026-09-26)

The six faces were designed here as mock-ups, approved by the user on 2026-09-26 and then
implemented in the firmware (`components/p64_widgets/src/face_*.cpp`, settings value
`clock.face`). `tools/mock_clock_faces.py` stays the design reference: it draws the assets
(`assets/clock/<face>/`, baked by `tools/gen_clock_assets.py`), these review images and the
test references under `tests/host/corpus/clock/` that `tests/host/run.py` compares with the
firmware's pixels. Edit a face in the mock, regenerate, then match it in the C++ until the
comparison is exact again.

Every mock-up is made the way the firmware makes it: bitmap assets (the PNGs under
`firmware/assets/clock/<face>/`, drawn by the script and editable by hand afterwards)
stamped onto a 64x64 frame, plus text from the bundled pixel fonts through the firmware's
own glyph tables, integer-scaled, without anti-aliasing. `<face>.png` is the real 64x64 frame, `<face>@8x.png` the same enlarged
nearest-neighbour for looking at, `contact-sheet.png` all six side by side.

| Face | Idea | Assets | Text | Moves |
|---|---|---|---|---|
| `flip` | A split-flap clock: two graphite tiles with rounded corners, a top highlight, a hinge line through the numerals and axle pins; ivory numerals; the weekday and date small and dim above; an amber seconds rail below (30 ticks, one per two seconds). | `tile.png` (30x34, stamped twice), `digits.png` (ten 9x16 Helvetica-bold-style numerals) | Capital Hill 6 px for the date | The rail every second (optional); the flip on the minute (below) |
| `nixie` | Four Nixie tubes on a brass-trimmed walnut base: domed glass with a reflection, warm haze inside, wire numerals in orange with a one-pixel halo, socket and pins, a neon colon; the date in dim amber under the base. | `tube.png` (13x38, stamped four times), `digits.png` (ten 7x11 wire numerals), `base.png` (64x4) | Capital Hill 6 px for the date | The colon blinks (optional) |
| `horizon` | A landscape computed from where the sun really is (below). The time on top in outlined white, the date on the ground. | `sun.png`, `cloud.png`, `far-hills.png`, `near-hills.png`, `tree.png` (masks tinted per moment); the moon is drawn procedurally from its phase | Capital Hill 6 px at 2x for the time, 1x for the date | Every minute |
| `words` | A word clock: a 12x9 grid of letters behind a brushed-steel bezel, the letters that spell the time lit in warm white and the rest barely there ("IT IS HALF PAST TEN AM"); four corner dots add the minutes past the five. The grid is p64's own layout, not a product's. | `alphabet.png` (a 3x5 capital alphabet drawn for the grid), `bezel.png` (64x64 frame with the brush, the inner shadow and four screw heads) | none from the bundled fonts | Every five minutes, and a dot a minute |
| `hourglass` | The hour as sand: the top bulb holds what is left of it, the bottom the heap that has run, a stream between them that loses a grain every second; the surface of the top sand dips into a funnel and the heap rises to a peak under the neck. The hour and the minute stacked beside it in the flip's numerals, the date under them. | `frame.png` (26x52: walnut end plates, brass posts, the glass outline), `sand.png` (4x4 two-tone dither tile); the flip's `digits.png` shared | Everyday Slight 5 px for the date | The stream every second, the sand every minute |
| `orrery` | A brass orrery on a star chart: the Earth (with its Moon on an arm) goes round the Sun once in twelve hours, the Moon round the Earth once an hour, Mercury round the Sun once a minute; dotted brass rings for the orbits, twelve ticks at the rim, the time in figures on a brass plaque at the foot. | `plate.png` (64x64: chart, rings, ticks, plaque, drawn once), `sun.png` (9x9), `earth.png` (5x5), `moon.png` and `mercury.png` (3x3) | Capital Hill 6 px on the plaque | Mercury every second, the Moon and the Earth every minute |

The digits of the Everyday fonts carry a dotted zero and High Birth is the only bold plain
one, so the flip and nixie faces draw their own numerals as assets; that is also what those
clocks look like in life (Helvetica cards, wire cathodes).

## The second three

`words-moments.png`, `hourglass-moments.png` and `orrery-moments.png` show each at six
times of day; `hourglass@8x.gif` and `orrery@8x.gif` a few seconds of each. All three are
deliberately unlike the first three and each other: one is typographic and shows no
figures at all, one shows time as a quantity, one as a mechanism. The words face is
twelve-hour by nature (AM and PM are on the grid); the other two take 12/24 h.

## The flip's animation

`flip-minute.gif` (10:32 to 10:33) and `flip-hour.gif` (10:59 to 11:00), with `@8x`
enlargements. The firmware would keep one 30x34 sprite per tile (the tile asset with its two
numerals stamped on, rebuilt when the pair changes) and animate a change in ten frames of
45 ms: the old upper leaf falls, its rows squashed towards the hinge and darkened as it
tilts away from the light (heights 15, 12, 8, 4, 1), then the new lower leaf lands, growing
from the hinge and lit brighter while it faces the light (heights 2, 6, 10, 14, 16). Each
frame is three row-range copies of the two sprites (the top of the new card, the squashed
leaf, the bottom of the old card), so it costs nothing beyond the copies; the hour tile
starts one frame after the minute tile, as on a real clock. The GIFs hold the last seconds
before the minute, the flip, and the rest.

## The horizon's model

The scene is procedural, from the sun's position rather than from the hour, so every
hour of every day, and every place, looks like itself:

- Sun elevation and azimuth from the latitude and longitude the weather widget already
  holds, the day of the year and the local time (NOAA's low-precision formulas, well under
  a degree; pure arithmetic for a host-tested `solar.cpp`). Checked: New York on
  2026-09-26 rises at 06:50 and sets at 18:50 in the model, as in the almanac.
- The viewer faces the equator: the sun rises on the left and sets on the right in the
  northern hemisphere, mirrored in the southern; the east-west component is projected on
  the view plane so a sun near the zenith stays in the middle. Its height on the panel is
  its elevation.
- The sky is keyed by the elevation (nine stops from -18 degrees, astronomical night, to
  the zenith), with the twilight glow on the sun's side of the horizon only. The sun is a
  red disc within 6 degrees of the horizon and gold with rays above.
- Stars come out from 4 degrees below and are full from 12 below. The moon shows its
  phase (terminator drawn per pixel, from its elongation from the sun) where it really
  is: the Astronomical Almanac's low-precision moon, about 0.3 degrees (since
  2026-10-01; a phase-only estimate before, up to 20 degrees off); on a dark sky its
  night side shows faintly. The sun and the moon rise and set on the far hills' line
  (since 2026-10-01; before, the far hills hid the setting sun from 18 degrees up): the
  disc rests on the line at +0.7 degrees and has slid behind it by -0.83, the almanac's
  sunset (under a pixel a minute); the day's arc is the old round one lifted onto a
  raised horizon (the higher end of the hill line) up to row 18 at the zenith, the local
  line bending only the first 5 degrees; where the hills stand higher than that horizon
  (the peak), they hide a low body.
- The weather widget's current condition, when a location is set, adds clouds (one, two,
  four or seven by the cover, lit by the sky), greys the sky, and streaks rain or drops
  snow, with a snow line on the ground.
- Clouds drift with the minute; the hills are hazed by the horizon colour by day and black
  by night.

`horizon-day.png` shows twelve moments of one day in New York; `horizon-variants.png` the
same afternoon hour in four weathers, and dusk in Sao Paulo (sun setting on the left, the
southern hemisphere), midwinter noon in Tromso (the sun never up, a crescent moon),
midsummer near midnight in Reykjavik (the sun just under the horizon at the north) and noon
in Singapore (the sun near the zenith). Without a location the face would use a fixed
mid-latitude and no weather, so it still runs.

Settings each would honour when implemented: 12/24 h (AM/PM as a small mark), seconds
(rail, colon blink), date order, and the accent colour where a face has one (the flip's
rail, the nixie's glow); the face colour settings of the digital face do not apply to the
themed faces.

## The LED face (prompts p052 and p053, 2026-09-28)

A seven-segment clock drawn from VEXED's **Digital Display** (`assets/fonts/digital-display`,
CC BY 4.0), a 15x19 pixel font that only looks right at multiples of 19 px: the digits and
the colon are rasterised once from the TTF at 19 px into `assets/clock/led/digits.png` and
`colon.png` (`gen_fonts.py` does not bundle this font, it is too tall for the overlay).
HH:MM in one row would be 67 px, so the hours sit at the upper left and the minutes at the
lower right, a staircase, with the seconds at the lower left in two 5x9 seven-segment
digits of the same style (`mini.png`) and the indicators AM, PM and ALM at the upper right
(the words face's 3x5 alphabet). Every digit position keeps its unlit "8" as a faint ghost,
as on the real displays; the leading zero of the hour is blank in 12 h; the ALM dot is lit
for decoration only (an alarm has no meaning yet).

Mocked up as two faces (LED and VFD) and approved on 2026-09-28 with two changes: the VFD
became a style of the one face, and the highlight that swept along the top of the frame
every eight seconds was dropped as artificial; after the first look at the panel (p054)
the ghost and the glow of every style were cut to a third, because the matrix lifts the
dark end and the unlit segments competed with the lit ones; that overshot (too faint to
notice, p055) and half the first values is where they settled (the review images show the
final values). The `led_style` setting picks one of five:

| Style | Look | Assets |
|---|---|---|
| `red`, `green`, `amber`, `blue` | An LED bedside clock: the segments behind a filter tinted in the colour, a dark plastic bezel with the light on its top and left edges and a recessed inner edge, the labels printed on the filter with a lit square dot beside each (AM or PM in 12 h). | `led/bezel.png` (64x64 with the window clear), `digits.png`, `colon.png`, `mini.png` |
| `vfd` | A vacuum fluorescent display: cyan-green phosphor (150, 255, 225) on dark glass with a faint mesh (alternate rows), in a chrome frame with a bright top-left edge; the indicator words themselves light up, a bell beside ALM; a six-bar meter dances in the band between the rows, purely for life. | `led/vfd-frame.png` and the same digits |

What moves: every digit change (the seconds every second, the minutes every minute)
cross-fades over five frames of 40 ms, the segments that go out falling from lit to ghost
while the ones that come in rise, the shared ones staying lit, the way a display with a
slow response changes; the colon blinks with the blinking-colon setting; a one-pixel glow
around every lit pixel breathes over four seconds (255 down to 140 of its colour and back),
so the face redraws every 200 ms whenever it is up (decided 2026-09-28); the VFD's meter
bars ride two unrelated triangle waves each. The face's clock is the local time of day in
milliseconds, so every frame is a function of the moment: the firmware (`face_led.cpp`)
draws the same integer arithmetic over a 0..255 intensity map and a ghost map, and the
seventeen `led-*` references (the styles, 12 h, the blinking colon, frames of the fades)
are pixel-exact.

`led.png` is the 64x64 frame (10:32:37, 24 h, seconds on), `led@8x.png` enlarged,
`led-vfd.png` and `led-vfd@8x.png` the VFD style; `led-styles.png` the five styles;
`led-moments.png` six times of day in 12 h; `led.gif` and `led-vfd.gif` (and `@8x`) eight
seconds from 10:31:57 across the minute change, frame by frame as the firmware draws them.

## Two faces from Retro Diffusion art (p075 and p076, 2026-10-03)

Designed here as mock-ups (p075), approved and implemented the same day (p076): the
settings values `horizon_rd` and `aquarium`, `face_horizon_rd.cpp` and
`face_aquarium.cpp`. Both are drawn from pixel art generated with the Retro Diffusion
API; the raw pictures, every call's payload and price are in `assets/rd-source/`
($2.18 spent), `tools/prep_rd_clock_assets.py` cuts them into `assets/clock-png/<face>/`,
and those PNG files are embedded in the firmware as they are and decoded when the face
starts (`picture.hpp`), unlike the other faces' baked sprites. Decisions taken with the
user: the horizon's computed sky over painted land; a goldfish tank with decor, the time
small on a sign (the time only, no AM or PM), the light following day and night; PNG
assets for both; a 12 px sun and a 12 px moon (the first mock had 8 and 14).

| Face | Idea | Assets | Text | Moves |
|---|---|---|---|---|
| `horizon_rd` | The horizon face's sky and almanac (colours by the sun's elevation, glow on the sun's side, stars, the sun and the moon where they are, the moon's phase, the weather's clouds, rain and snow) over a painted landscape: snow peaks, a lake, pines and a log cabin. The land keeps its colours by day, sinks to a blue night and is warmed at the twilights; the lake mirrors the sky and glitters under the sun and the moon; the cabin's two windows are lit while it is dark. | `land.png` (64x38, at row 26), `lake.png` (the water's mask), `lights.png` (the windows), `sun.png` (12x12), `moon.png` (12x12, the phase's terminator is computed over it), `cloud-a.png`, `cloud-b.png` | Everyday Vast Black 11 px for the time, Capital Hill for AM/PM beside it, Everyday Slight 5 px for the date at the bottom right, on the lake, clear of the cabin; one outline at 75 % black | The lake's glints every 500 ms, the rest every minute |
| `aquarium` | A goldfish tank: a stone castle, a plant, an open treasure chest, gravel, and a wooden sign that carries the time. Three goldfish swim from wall to wall and turn, each on its lane, wagging its tail: a small yellow one and an orange one behind the decor, a large red and white one in front of everything but the sign. By night (from the sun's elevation) the water goes dark blue, the castle's window and door glow, the yellow fish hides and the others swim at half speed. | `tank.png` (16 frames of 64x64: the plant sways, bubbles rise from the chest), `front.png` (the same frames, only what stands in front of the far fish), `sign.png` (27x10), `lights.png`, `fish-a.png` (20x17), `fish-b.png` (26x19), `fish-c.png` (14x10), eight frames each | Everyday Standard 6 px on the sign, cream with a carved shadow | Every 150 ms |

`horizon_rd-day.png` is one day in New York (the same twelve moments as `horizon-day.png`),
`horizon_rd-variants.png` the weather, 12 h, the full and the half moon and Sao Paulo,
`horizon_rd@8x.gif` six seconds of the lake; `aquarium-moments.png` six moments,
`aquarium.gif` and `aquarium-night.gif` (with `@8x`) fourteen and ten seconds of the tank.
The aquarium is integer arithmetic after the sun's elevation, so its references are
compared pixel for pixel; Horizon-RD's within the horizon's tolerance.

## Two analogue faces on Retro Diffusion dials (p077 and p078, 2026-10-03)

Designed here as mock-ups (p077, as "Analogue-RD-1" and "-2"), approved and implemented
the same day (p078) under the names the user chose: the settings values `bracket` and
`station`, `face_bracket.cpp` and `face_station.cpp` on the shared `dial.cpp`. Only the
dial of each is painted (Retro Diffusion, $0.90 for the candidates; the calls are in
`assets/rd-source/calls.json`): `tools/prep_rd_clock_assets.py` cuts
`assets/clock/bracket/dial.png` and `assets/clock/station/dial.png`, baked like the other
sprites. Both dials were generated at 80x80 and the middle 64x64 kept, so that the dial
fills the panel (asked for at 64x64, the model leaves a margin). Everything that must be
exact is drawn, in integers, the same in the mock and the firmware: markers, numerals
(bundled fonts, native size), hands as shapes along their axis with a lit edge and a
one-pixel shadow, the hub, the date. Decided with the user: antique brass and enamel for
the first, a railway station clock for the second; hands by the firmware, styled and
textured per dial; no painted numerals; the second hand with the seconds setting, the
date, something alive.

| Face | Idea | Asset | Text | Moves |
|---|---|---|---|---|
| `bracket` | An antique bracket clock: an engraved brass plate whose corners show around a cream enamel dial. Roman cardinals, a diamond at the other hours, a dot a minute; blued-steel hands, a spade on the hour hand; a brass cap; a mock pendulum, as such clocks have: a curved slot under the XII in which a brass bob swings once every two seconds. | `dial.png` (64x64, the enamel 56 px across) | Capital Hill 6 px for the numerals (its I has serifs), Everyday Slight 5 px for the date | The bob every 100 ms; a thin red second hand that ticks, with the seconds setting |
| `station` | A railway station clock: a white dial in a steel rim, a bar at every hour (heavier at the quarters), a tick a minute, black bar hands with a lighter edge. | `dial.png` (64x64, the dial 59 px across) | Everyday Slight 5 px for the date, grey | A glint crosses the glass for 1.5 s every 12 s; with the seconds setting the red second hand runs the way station clocks do: once round in 58.5 s, then it waits at the top for the minute hand to jump |

`bracket-moments.png` and `station-moments.png` show six times of day, the seconds off and
the month-first date; `bracket.gif` and `station.gif` (with `@8x`) twelve seconds across a
minute change with the seconds on; `station-glint.png` the glint frame by frame.

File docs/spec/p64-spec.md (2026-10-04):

# p64 product specification

Version 1.0, 2026-09-19. Source of truth for what the p64 device does. Words are used as
defined in `CONTEXT.md`; hard-to-reverse choices and their reasons are in `docs/adr/`.
This document says what the device does and what its limits are; how the firmware is
built to do it is the architecture's job and is not written here.

How to change this document: edit it in the same commit as the change it describes; add
an ADR when the change reverses one; keep the settings and limits tables complete.

Sources referred to as "p3a" are the user's ESP32-P4 player firmware (v1.2.3, cloned at
`firmware/reference/p3a`); "the server" is Makapix Club (cloned at
`firmware/reference/makapix`); "the hardware tests" are `firmware/reference/hardware-tests/`.

## 1. Product

p64 is a self-contained desktop pixel-art player: a 64x64 RGB LED panel in a printed
shell, powered over USB-C, controlled from a browser on the same Wi-Fi network and from
Makapix Club. It plays animated and static pixel art from the owner's microSD card and
from Makapix Club channels, shows a clock, the weather and the room temperature as
widgets, and accepts pixel streams from the network.

Posture: a public, open-source, do-it-yourself product (Apache-2.0), the same as p3a:
`main` is production, devices update over the air from GitHub Releases, and every feature
must work for a stranger who assembled the device from the parts list. English only.

Principles, in priority order:

1. Playback is accurate, tearless and jitter-free. Nothing the device does in the
   background may disturb the panel.
2. Every change on the panel is seamless.
3. The device keeps working alone: offline, without a card, without Makapix.
4. The web UI feels like p3a's: same navigation, same look, same vocabulary.
5. Nothing is silently dropped or skipped: rejected files, failed downloads and late
   frames are counted and visible in the web UI.

## 2. Hardware

| Part | Facts | Used by v1 |
|---|---|---|
| Driver board | Waveshare ESP32-S3-RGB-Matrix: ESP32-S3-WROOM-2-N32R16V, 32 MB octal flash, 16 MB octal PSRAM, HUB75 header, two USB-C (POWER, USB), BOOT button, IMU (6-axis), RTC, temperature/humidity sensor, audio codec with two microphones, speaker output, TF slot. Native USB Serial/JTAG on the USB port. | Panel, BOOT, IMU, temperature/humidity sensor, TF slot, USB console (the RTC has no battery and is not used, ADR 0011) |
| Panel | Waveshare RGB-Matrix-P2-64x64: 4096 RGB LEDs, 2 mm pitch, 1/32 scan, HUB75E, 5 V, 15 W max, 128x128 mm. | Yes |
| Power | Waveshare PSU-27W-USB-C-B on the POWER port; the USB port takes a computer for console and flashing. Full white at brightness 255 draws close to the panel's 15 W; a USB-only rig cannot supply that (see brightness ceiling). | Yes |
| Shell | `enclosure/` v4: panel turned 90 degrees clockwise, two rotary encoders on the back planned, panel-mount USB-C sockets. | Rotation default 90; encoders reserved |
| Not used in v1 | Audio codec, speaker, microphones, Bluetooth. | Extension points only |

Firmware platform: ESP-IDF v5.5, C++, the vendored and patched `esp-hub75` driver from
the hardware tests (pin map, GDMA priority, refresh and tonal-depth findings recorded in
`firmware/reference/hardware-tests/README.md`). Single supported target; the panel's width and height are
one configuration property read everywhere, never literal numbers.

## 3. Panel and picture

### 3.1 Panel modes

| Mode | Bit planes | Refresh (measured at 20 MHz pixel clock, 2026-09-20) | Codes per channel | Light at full white | Use |
|---|---|---|---|---|---|
| Quality (default) | 11 | 263.9 Hz (transition bit 5, 37 transmissions per row; low windows 1 2 4 8 16 31 clocks) | 2048 (243 distinct after the gamma 2.2 fit, 51 in the darkest quarter) | 100 % (1984 of 2368 pixel clocks per frame lit) | Normal viewing: dark tones keep their steps |
| Photo | 8 | 813.8 Hz (transition bit 4, 12 transmissions per row) | 256 | about 76 % of Quality (491 of 768 clocks lit, at three times the rate) | Being photographed or filmed: no rolling-shutter banding |

Photo mode is dimmer by design: the five planes sent once carry halved output-enable
windows whatever the plane count, and with only twelve transmissions per row they are a
larger share of the frame. Cameras compensate with exposure; the setting is not meant
for viewing. Quality mode is eleven planes at 264 Hz since 2026-10-02 (ADR 0015; ten
planes at 271.3 Hz and 233 codes before, chosen by the user's eye on the panel). Deeper
settings need a refresh near 140 Hz and 23 to 41 KB more internal RAM, which the device
does not have (settled with the user on 2026-09-20 and 2026-10-02).

Switching modes is a user action in the web UI and the API. The driver's refresh
profile changes in place (no re-initialisation, nothing allocated): the panel shows the
previous picture for a few refresh periods and never blanks; it must not require a
reboot. The mode persists across reboots.
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

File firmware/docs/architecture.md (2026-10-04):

# p64 firmware architecture

How the firmware is built to do what `docs/spec/p64-spec.md` says. Vocabulary from
`CONTEXT.md`. This file is kept current as the code grows; the milestone status is in
`PROGRESS.md` next to it.

## 1. Shape

ESP-IDF v5.5 project, C++20, one application, components under `firmware/components/`.
Boundaries follow p3a's (ADR 0001) but are grouped into fewer, larger components sized
for the ESP32-S3; each component has one job, a public header set under
`include/p64/<name>/`, and no knowledge of the components above it.
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

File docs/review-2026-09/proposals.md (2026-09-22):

# Proposals: the ranked roadmap

Every proposal names its gain (measured where it was measured today, est. otherwise),
its cost in sessions of work, its risk, and whether it breaks a contract (the API, the
Makapix contract, a setting, a file format). Ordered by gain per cost within the three
tiers; the tiers are ordered by urgency. The decisions the review was made under are in
`README.md`; the evidence is in `memory.md`, `cpu.md` and `testing.md`.
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

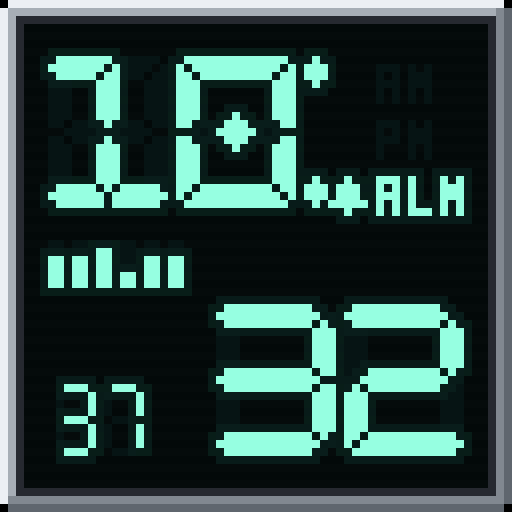
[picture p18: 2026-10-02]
firmware/docs/design/clock-candidates/led-vfd@8x.png

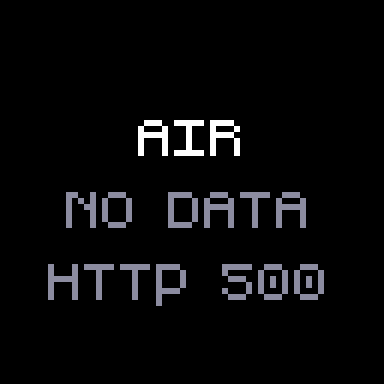
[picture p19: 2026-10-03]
firmware/docs/design/air-widget/no-data.png

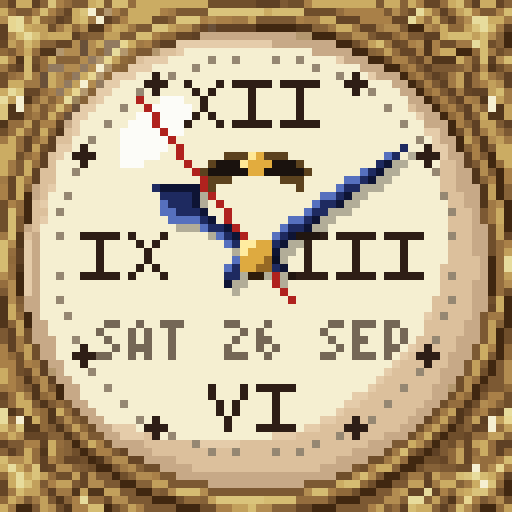
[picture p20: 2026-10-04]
firmware/docs/design/clock-candidates/bracket@8x.gif

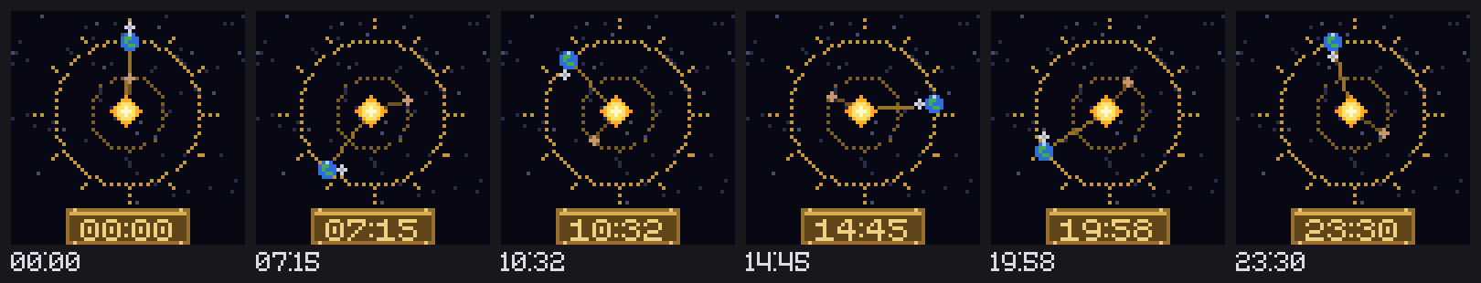
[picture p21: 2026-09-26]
firmware/docs/design/clock-candidates/orrery-moments.png

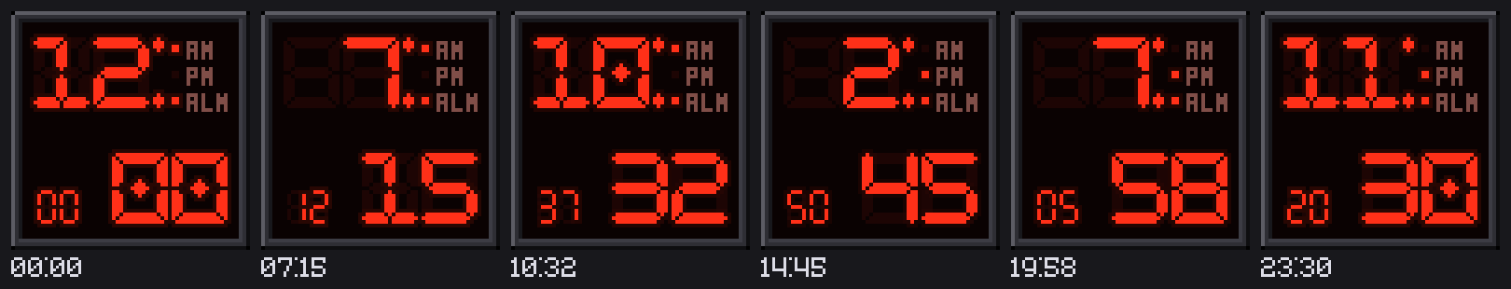
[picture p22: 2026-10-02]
firmware/docs/design/clock-candidates/led-moments.png

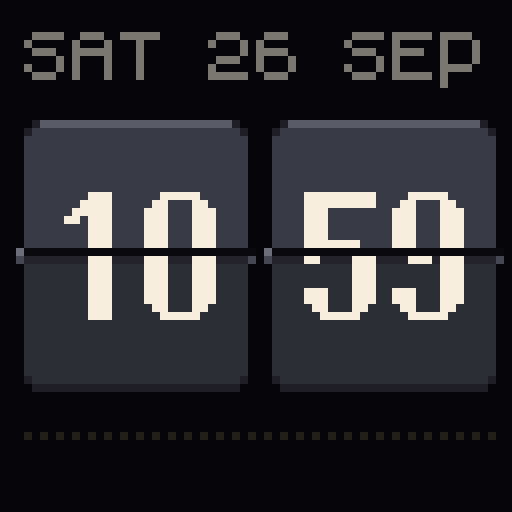
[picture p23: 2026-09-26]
firmware/docs/design/clock-candidates/flip-hour@8x.gif

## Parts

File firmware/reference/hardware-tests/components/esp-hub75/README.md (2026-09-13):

<!-- p64 vendoring note -->
> **p64:** this is [esphome-libs/esp-hub75](https://github.com/esphome-libs/esp-hub75) 0.3.6
> (MIT, see `LICENSE`), copied from the component registry into `firmware/components/`
> so it can be patched. Local changes are marked `p64 patch` in the sources and listed
> in `P64-CHANGES.md` next to this file. Upstream README follows.

# HUB75 DMA Driver Component

Complete API documentation and configuration reference for the HUB75 DMA driver component.

ESP-IDF component for driving HUB75 RGB LED matrix panels via DMA. Supports ESP32, ESP32-S2, ESP32-S3, ESP32-C6, and ESP32-P4.

**Requires ESP-IDF 4.4.8+** (ESP32-C6/P4 require 5.1+). Tested with 4.4.8, 5.5.2, and 6.0-rc1.

## Key Features

- Static circular DMA refresh (no CPU intervention after initialization)
- Multi-platform support: GDMA (S3), I2S (ESP32/S2), PARLIO (P4/C6)
- CIE 1931 gamma correction with native bit-depth LUTs (4-12 bit)
- Multi-panel layouts with serpentine and zigzag chaining
- Display rotation (0°, 90°, 180°, 270°) - runtime configurable
- Double buffering for tear-free animation
- Multiple pixel formats: RGB888, RGB888_32, RGB565

## Installation

### Option 1: Component Manager (Recommended)

**From ESP Component Registry:**

```yaml
dependencies:
  hub75:
    version: "^1.0.0"
```

Browse versions on the [ESP Component Registry](https://components.espressif.com/components/esphome/esp-hub75).

**From Git:**

```yaml
dependencies:
  hub75:
    git: https://github.com/esphome-libs/esp-hub75
    path: components/hub75  # Important: point to subdirectory!
```

**For local development:**

```yaml
dependencies:
  hub75:
    path: /path/to/esp-hub75/components/hub75
```

### Option 2: Manual Copy

Copy the component directory to your project:

```bash
cp -r /path/to/esp-hub75/components/hub75 my_project/components/
```

**Important:** Always point to `components/hub75/` subdirectory, not the repository root. The root contains a standalone test project that will conflict if included as a component.

## Quick Start

```cpp
#include "hub75.h"

void app_main() {
    // Configure for your panel
    Hub75Config config{};
    config.panel_width = 64;
    config.panel_height = 64;
    config.scan_wiring = Hub75ScanWiring::STANDARD_TWO_SCAN;  // Most panels
    config.shift_driver = Hub75ShiftDriver::FM6126A;          // Or GENERIC

    // Set GPIO pins
    config.pins.r1 = 25;
    config.pins.g1 = 26;
    config.pins.b1 = 27;
    config.pins.r2 = 14;
    config.pins.g2 = 12;
    config.pins.b2 = 13;
    config.pins.a = 23;
    config.pins.b = 19;
    config.pins.c = 5;
    config.pins.d = 17;
    config.pins.e = -1;
    config.pins.lat = 4;
    config.pins.oe = 15;
    config.pins.clk = 16;

    // Create and start driver
    Hub75Driver driver(config);
    driver.begin();  // Starts continuous refresh

    // Draw pixels - changes appear automatically!
    driver.set_pixel(10, 10, 255, 0, 0);  // Red
    driver.set_pixel(20, 20, 0, 255, 0);  // Green
    driver.set_pixel(30, 30, 0, 0, 255);  // Blue

    // Optional: Double buffering for tear-free animation
    if (config.double_buffer) {
        driver.clear();  // Clear back buffer
        // ... draw frame ...
        driver.flip_buffer();  // Atomic swap
    }
}
```

**Pin Configuration:** See repository [examples/common/pins_example.h](https://github.com/esphome-libs/esp-hub75/blob/main/examples/common/pins_example.h) for board-specific pre-configured pin layouts.

## API Reference

### Initialization

- `Hub75Driver(config)` - Create driver with configuration
- `bool begin()` - Initialize hardware and start continuous refresh loop
- `void end()` - Stop refresh and cleanup resources

### Drawing

- `void draw_pixels(x, y, w, h, buffer, format, color_order, big_endian)` - Bulk pixel write from buffer (most efficient for images/sprites)
  - `format`: `PixelFormat::RGB888` (24-bit packed), `RGB888_32` (32-bit padded), or `RGB565` (16-bit)
  - `color_order`: `ColorOrder::RGB` or `BGR` (for RGB888_32 only)
  - `big_endian`: Byte order control (affects RGB565 and RGB888_32)
- `void set_pixel(x, y, r, g, b)` - Draw single pixel with RGB888 values (0-255)
- `void fill(x, y, w, h, r, g, b)` - Fill rectangular region with solid color (optimized - color conversion done once)
- `void clear()` - Clear entire display to black

**Note:** `fill()` is more efficient than `set_pixel()` loops for solid color rectangles. For complex graphics primitives (circles, arcs, text), use a graphics library like LVGL or Adafruit_GFX.

### Double Buffering

- `void flip_buffer()` - Swap front and back buffers atomically

When double buffering is enabled, drawing operations (`clear()`, `set_pixel()`, `draw_pixels()`) operate on the back buffer. Call `flip_buffer()` to atomically swap buffers and display the new frame.

**Memory Usage:**
- **GDMA/I2S** (internal SRAM): ~57 KB single-buffer, ~114 KB double-buffer (64×64 panel, 8-bit)
- **PARLIO** (PSRAM): ~284 KB single-buffer, ~568 KB double-buffer (64×64 panel, 8-bit)

Double buffering doubles memory usage but enables tear-free animation. PARLIO uses ~5× more memory than GDMA/I2S, but allocates from PSRAM (typically 8-16 MB available) rather than scarce internal SRAM (~500 KB total). Larger panels scale linearly: 128×128 uses ~4× memory (PARLIO: ~1.1 MB, GDMA: ~228 KB).

### Rotation

- `void set_rotation(Hub75Rotation rotation)` - Set display rotation (0°, 90°, 180°, 270° clockwise)
- `Hub75Rotation get_rotation()` - Get current rotation

**Available rotations:**
- `Hub75Rotation::ROTATE_0` - No rotation (default)
- `Hub75Rotation::ROTATE_90` - 90° clockwise
- `Hub75Rotation::ROTATE_180` - 180°
- `Hub75Rotation::ROTATE_270` - 270° clockwise (90° counter-clockwise)

For 90° and 270° rotations, `get_width()` and `get_height()` return swapped values.

**Note:** Rotation changes take effect immediately. Content is NOT automatically rotated - the coordinate mapping changes. Clear and redraw after changing rotation if needed.

**Multi-Panel Note:** When using rotation with multi-panel layouts, configure `layout_rows`/`layout_cols` based on **physical panel wiring**. Rotation transforms the virtual coordinate space after layout remapping. See [Multi-Panel Guide](../../docs/MULTI_PANEL.md#using-rotation-with-multi-panel-layouts) for details.

### Brightness & Color Control

- `void set_brightness(uint8_t brightness)` - Set display brightness (0-255)
- `void set_intensity(float intensity)` - Set intensity multiplier (0.0-1.0) for smooth dimming
- `uint8_t get_brightness()` - Get current brightness value

**Gamma Correction:**
Gamma correction mode is **compile-time only** (configured via menuconfig):
- `HUB75_GAMMA_MODE=0` - Linear (no correction)
- `HUB75_GAMMA_MODE=1` - CIE 1931 standard (recommended, default)
- `HUB75_GAMMA_MODE=2` - Gamma 2.2

Configure via:
- `idf.py menuconfig` → HUB75 → Color → Gamma Correction Mode
- Or CMake: `target_compile_definitions(app PRIVATE HUB75_GAMMA_MODE=1)`

**Dual-Mode Brightness System:**
- **Basis brightness** (0-255): Adjusts hardware OE (output enable) timing in DMA buffers
- **Intensity** (0.0-1.0): Runtime scaling multiplier for smooth dimming without refresh rate changes
- Final brightness = (basis × intensity) >> 8

### Information

- `uint16_t get_width()` - Get display width in pixels (accounts for rotation)
- `uint16_t get_height()` - Get display height in pixels (accounts for rotation)
- `bool is_running()` - Check if refresh loop is active

**Note:** For 90° and 270° rotations, `get_width()` and `get_height()` return swapped values compared to the physical panel dimensions.

## Configuration Options

### Quick Examples

**Single 64×64 panel:**
```cpp
Hub75Config config{};
config.panel_width = 64;
config.panel_height = 64;
config.shift_driver = Hub75ShiftDriver::FM6126A;  // Try this if GENERIC doesn't work
```

**Two panels side-by-side:**
```cpp
config.layout_cols = 2;  // Two panels horizontally
config.layout = Hub75PanelLayout::HORIZONTAL;
// Virtual display: 128×64
```

**Higher quality display:**
```cpp
// Bit depth: Configure via menuconfig (4-12 bit available)
// (idf.py menuconfig → HUB75 → Panel Settings → Bit Depth)
config.double_buffer = true;   // Tear-free updates
config.min_refresh_rate = 90;  // Smoother for cameras
```

**Rotated display (portrait mode):**
```cpp
config.rotation = Hub75Rotation::ROTATE_90;  // 90° clockwise
// For 64×64 panel: get_width()=64, get_height()=64 (same for square)
// For 64×32 panel: get_width()=32, get_height()=64 (swapped!)
```

**Bit Depth Configuration:**
Bit depth is **compile-time only** (4-12 bits supported):
- Configure via `idf.py menuconfig` → HUB75 → Panel Settings → Bit Depth
- Or CMake: `target_compile_definitions(app PRIVATE HUB75_BIT_DEPTH=10)`
- Changes require full rebuild (regenerates LUT at compile time)

**For complete configuration reference** (all scan patterns, layouts, clock speeds, bit depth options, pin configuration, etc.), see **[MENUCONFIG.md](../../docs/MENUCONFIG.md)**.

## Multi-Panel Layouts

Chain multiple panels for larger displays:

```cpp
config.panel_width = 64;
config.panel_height = 64;
config.layout_rows = 2;    // Two rows vertically
config.layout_cols = 3;    // Three panels per row
config.layout = Hub75PanelLayout::TOP_LEFT_DOWN;  // Serpentine wiring
// Virtual display: 192×128 pixels
```

Panels chain **horizontally across rows** (row-major). Serpentine layouts have alternate rows mounted upside down to save cable length.

**For complete multi-panel guide** (layout patterns, wiring diagrams, coordinate remapping), see **[Multi-Panel Guide](../../docs/MULTI_PANEL.md)**.

## Platform Support

Supports ESP32, ESP32-S2, ESP32-S3, and ESP32-P4 with platform-specific optimizations:

- **ESP32/ESP32-S2** (I2S): ~57 KB SRAM, proven stability
- **ESP32-S3** (GDMA): ~57 KB SRAM, faster clock (40 MHz), ghosting fix
- **ESP32-P4** (PARLIO): ~284 KB PSRAM + ~16 KB SRAM, frees internal memory for apps
- **ESP32-C6** (PARLIO): Planned, same as P4 but no clock gating

**For detailed platform comparison, memory calculations, and implementation specifics**, see **[Platform Details](../../docs/PLATFORMS.md)**.

## Troubleshooting

**Common quick fixes:**
- **Black screen** → Try `shift_driver = Hub75ShiftDriver::FM6126A` (most modern panels)
- **Wrong colors** → Check R1/G1/B1/R2/G2/B2 pin mapping
- **Scrambled display** → Try `FOUR_SCAN_32PX_HIGH` scan wiring for 32px panels with 1/8 scan

**For complete debugging guide** (ghosting, flickering, multi-panel issues, platform-specific problems, error messages), see **[Troubleshooting Guide](../../docs/TROUBLESHOOTING.md)**.

## Advanced Documentation

For deep technical details, see the comprehensive documentation in `docs/`:

- **[Architecture Overview](../../docs/ARCHITECTURE.md)** - BCM timing, DMA descriptor chains, static circular refresh
- **[Platform Details](../../docs/PLATFORMS.md)** - GDMA vs I2S vs PARLIO implementation specifics, memory calculations, optimization strategies
- **[Color & Gamma](../../docs/COLOR_GAMMA.md)** - CIE 1931 correction, bit depth trade-offs, dual-mode brightness system
- **[Board Presets](../../docs/BOARDS.md)** - Pin mappings for supported boards, GPIO restrictions
- **[Menuconfig Reference](../../docs/MENUCONFIG.md)** - Complete menuconfig option guide
- **[Troubleshooting Guide](../../docs/TROUBLESHOOTING.md)** - Complete debugging reference

## License

MIT License - See repository [LICENSE](https://github.com/esphome-libs/esp-hub75/blob/main/LICENSE) file for details.

## Support

For issues, examples, and detailed documentation, visit the main repository:
https://github.com/esphome-libs/esp-hub75

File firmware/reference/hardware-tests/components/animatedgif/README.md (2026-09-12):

# animatedgif (vendored)

[bitbank2/AnimatedGIF](https://github.com/bitbank2/AnimatedGIF) by Larry Bank,
Apache-2.0 (see `LICENSE`). Copy of `src/AnimatedGIF.h`, `src/AnimatedGIF.cpp`
and `src/gif.inl` from upstream commit `c2478eca7aa2f3b7a09bdc583e5a4a43d03ac0d9`
(2026-07-03), with one local patch in `gif.inl` (search for "p64 patch"): the
"file too small" check in `GIFParseInfo()` rejected valid GIFs shorter than about
255 + palette bytes, because it judged by the second read's byte count instead of
the bytes already in the buffer. Three of the Makapix GIFs (200-265 bytes) hit
this. The ESP32-S3 SIMD
assembly files (`s3_transparent.S`, `p4_transparent.S`) and `GIFPlayer.h` are
not copied: they only serve the library's "cooked" RGB565 output mode, which
p64 does not use.

How p64 uses it: `GIF_DRAW_RAW` mode with an RGB888 palette. The library
decodes LZW and calls our line callback with palette indices, the frame's
rectangle, its transparency index and its disposal method; compositing into a
canvas (including disposal method 3, which the library itself does not
implement) lives in `main/gif_player.cpp`.

Build flags set by `CMakeLists.txt`: `__LINUX__` (its non-Arduino build),
`ALLOWS_UNALIGNED`, and `-w` for this component only.

To update: copy the three files from a newer upstream commit, record the
commit here, rebuild, and run `tools/gifcheck/gifcheck.py`.

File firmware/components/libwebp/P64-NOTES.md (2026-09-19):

# libwebp in p64

Vendored from https://github.com/webmproject/libwebp tag v1.4.0 (BSD-3-Clause, see
COPYING and PATENTS), decoder side only: `src/dec`, `src/demux` (demux and
WebPAnimDecoder), the decode sets of `src/dsp` and `src/utils` (the `COMMON_SOURCES` of
their Makefile.am plus the SIMD variants of those files, which compile to nothing on the
ESP32-S3), and the public headers in `src/webp`. The encoder, mux, sharpyuv and the
tools are left out. No source is modified. Threads are not enabled (`WEBP_USE_THREAD`
undefined). p3a fetches the same version at configure time; p64 vendors it so builds are
reproducible offline.

To upgrade: repeat the copy with the new tag (the file sets are listed in
`src/*/Makefile.am`), keep this note and the licence files current.

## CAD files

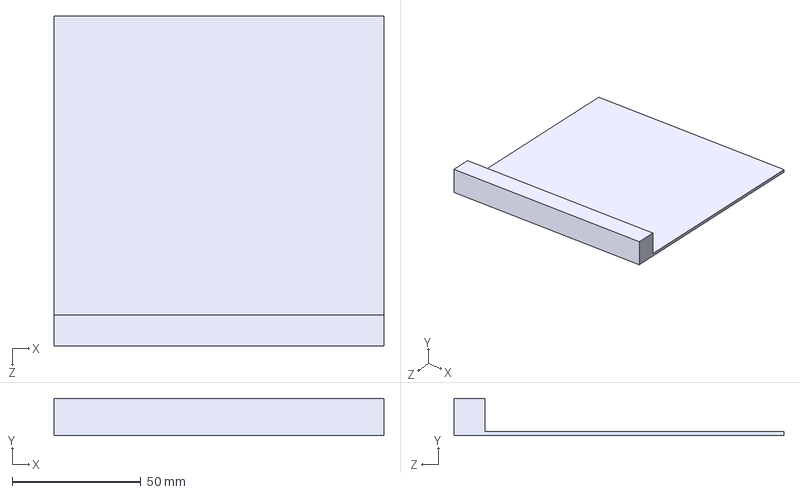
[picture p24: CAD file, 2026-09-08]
dhruv/p64.STEP
128.0 x 14.5 x 128.0 mm

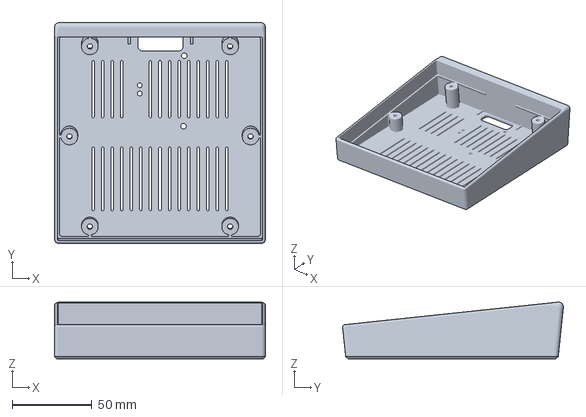
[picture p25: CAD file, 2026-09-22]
enclosure/output/p64a/v7a/p64_enclosure_print.3mf
132.4 x 138.6 x 35.7 mm

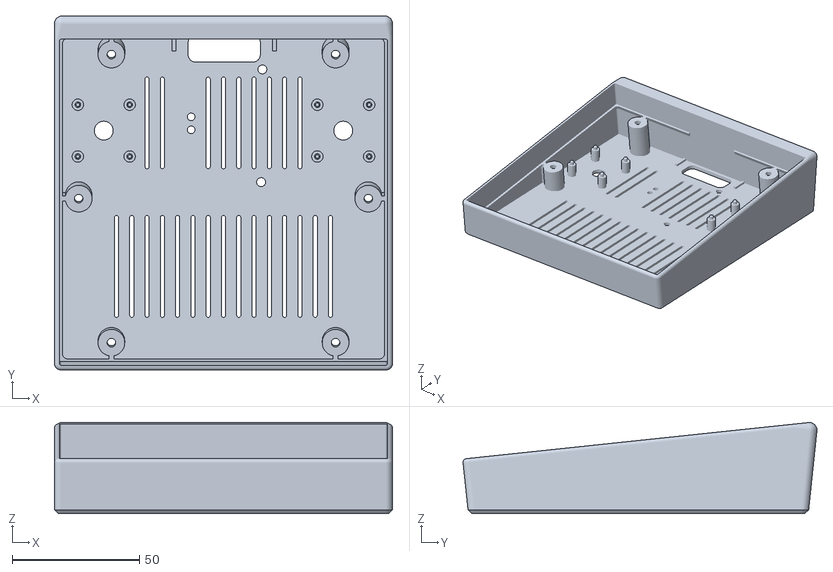
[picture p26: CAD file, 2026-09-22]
enclosure/output/p64b/v7b/p64_enclosure_service.stl
132.7 x 139.0 x 35.7

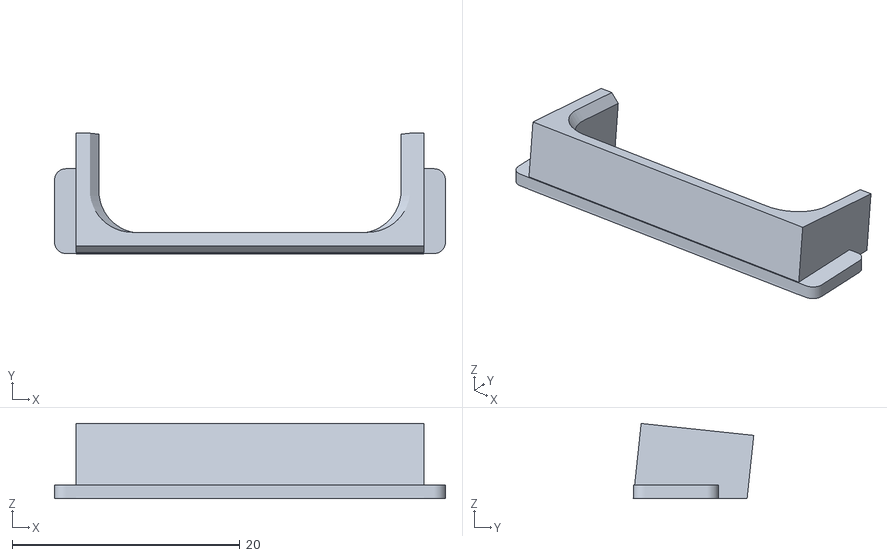
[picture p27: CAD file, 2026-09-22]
enclosure/output/p64b/v7b/p64_cradle_insert.stl
34.3 x 10.6 x 6.59

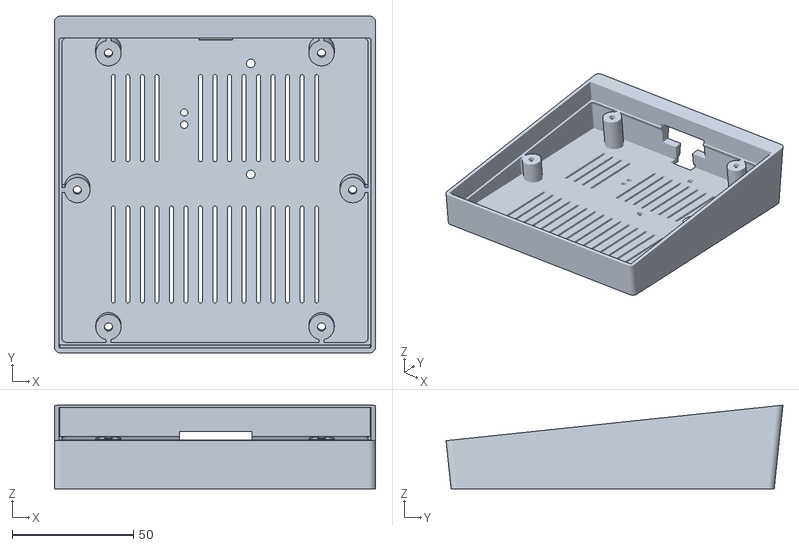
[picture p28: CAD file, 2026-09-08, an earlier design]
enclosure/archive/pre-v7/output/v1/p64_enclosure_service.stl
132.7 x 139.2 x 34.6

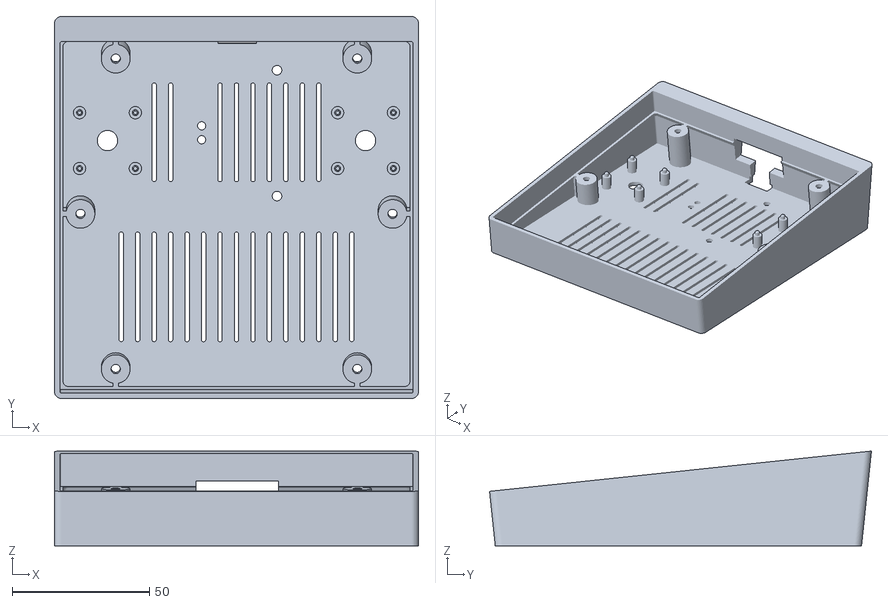
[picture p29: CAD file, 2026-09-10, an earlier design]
enclosure/archive/pre-v7/output/v2/p64_enclosure_service.stl
132.7 x 139.2 x 34.6

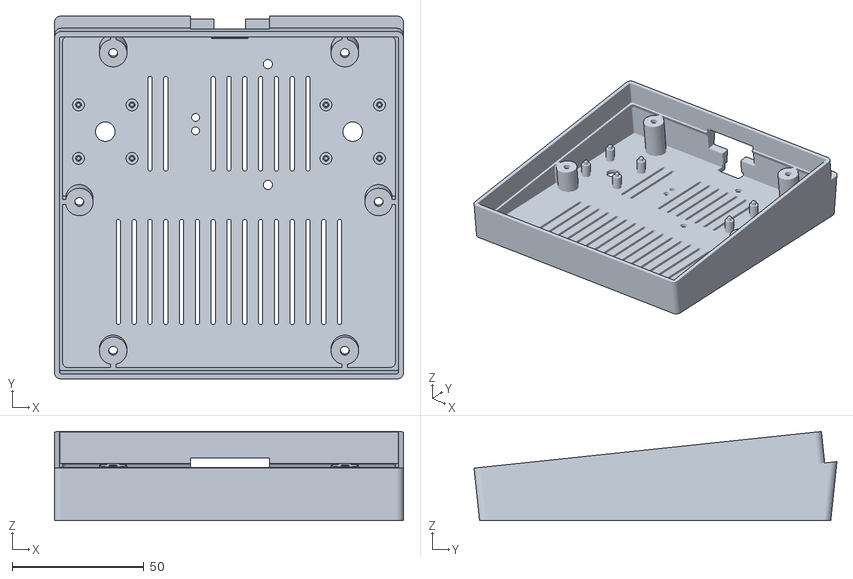
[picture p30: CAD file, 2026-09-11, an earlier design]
enclosure/archive/pre-v7/output/v3/p64_enclosure_service.stl
132.7 x 137.9 x 33.8

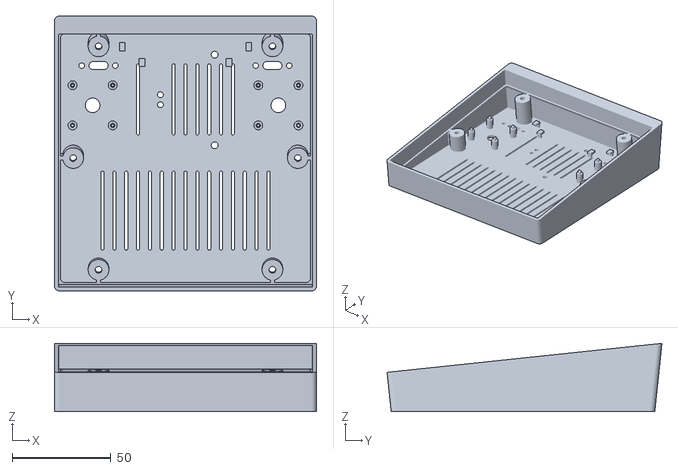
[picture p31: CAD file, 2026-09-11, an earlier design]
enclosure/archive/pre-v7/output/v4/p64_enclosure_service.stl
132.7 x 139.2 x 34.6

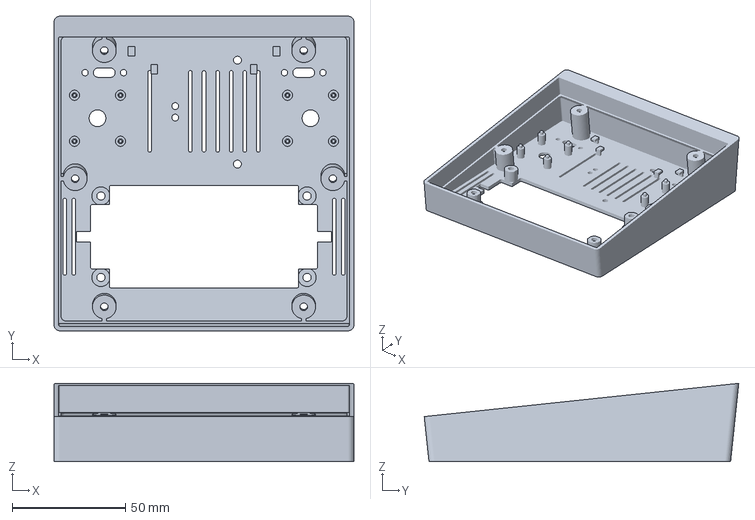
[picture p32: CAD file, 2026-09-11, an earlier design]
enclosure/archive/pre-v7/output/v5/p64_enclosure_print.3mf
132.4 x 138.9 x 34.6 mm

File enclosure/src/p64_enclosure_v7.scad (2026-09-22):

// =====================================================================
//  p64_enclosure_v7.scad
//  Tabletop back shell for the Waveshare RGB-Matrix-P2-64x64-B
//  (128 x 128 mm LED matrix, 6x M3 brass inserts) with the
//  ESP32-S3-RGB-Matrix controller plugged into the HUB75 IN header.
//  Needs OpenSCAD 2021.01 or newer.
//
//  v2 (2026-09-10): adds two rotary encoders on the back face, one near
//  each side edge in the lower half. Each is an Adafruit 5880 board
//  (I2C seesaw breakout, 25.4 mm square, Bourns PEC11-style encoder
//  soldered at its centre, 15 mm D-shaft, M7 x 5 mm bushing). The
//  board lies parallel to the back face, its shaft goes straight out
//  through the wall, the encoder's own washer and nut clamp it from the
//  outside under the knob, and four printed posts with pegs in the
//  board's 2.5 mm holes stop it from turning. Everything else is v1.
//
//  v4 (2026-09-11): two JUXINICE panel-mount USB-C extensions screwed to
//  the back face, their L-plugs inside the cavity below the controller's
//  ports, so v2's plug pocket, base groove and back notch are gone.
//  Superseded: the v1 print showed there is no room for them.
//
//  v6 (2026-09-19): the external cables plug into two small 90-degree
//  USB-C adapters that stay on the controller's ports for good. Each
//  adapter is a 19.3 x 12.7 x 8.0 mm body whose male plug leaves the
//  wide face 4.8 mm from one end and whose female socket sits in the far
//  end face; plugged in, the body hangs below its port with its length
//  running front to back and the socket facing the back wall, and the
//  two bodies touch (ports 12.74 mm apart). The back wall gets one window
//  over both socket faces (they end 2.9 mm inside the outer face) with a
//  1 mm chamfer, a U-shaped cradle on the cavity back keys the last 6 mm
//  of the bodies, and one groove beside the right end of the window marks
//  USB. The bodies' near ends reach 1.1 mm in front of the frame's back
//  face, so the frame's plate strip below the ports has to be notched by
//  hand (see README). v4's sockets, ribbon hooks and vent keep-outs are
//  gone; the lower vent band regains its +-30 columns. Based on v4 (front
//  bar kept, not the v3 plinth; no v5 speaker).
//
//  v6 edges (2026-09-19, edited in place, still v6): the outer edges are
//  softened for the hand. The back face's perimeter gets a 45-degree
//  chamfer (edge_back_c: it is the bed side of the print, where a fillet
//  would overhang), the front rim's outer edge a fillet (edge_rim_r,
//  leaving a flat next to the pocket, whose own edge stays sharp), and the
//  base's front edge, the acute one under the LED face, a larger fillet
//  (edge_base_r) that blends into the rim's along the front corners. The
//  six counterbore mouths get a small chamfer (cb_chamfer). The pocket,
//  ledge, bosses, cradle and every other opening are unchanged. The outer
//  body is now the hull of thin sections of the same envelope (side, top,
//  base, front and back planes), each section inset by its own edge
//  treatment, so the envelope itself did not move: set the three edge
//  values to 0 and the old body comes back exactly.
//
//  v7 (2026-09-22): v6 made tolerant of the inputs it cannot verify. The
//  port position is read off a product photo (+-1 mm), the adapter was
//  measured on a photo, the boot gap that sets how far the bodies hang
//  is an estimate, and an FDM opening prints smaller than modelled; v6's
//  window (0.4/0.6 mm per side) and cradle (0.3/0.5) could not absorb
//  that. v7 names the budget (tol_*, print_clr) and derives every
//  clearance from it: the window is sized for the worst case (its outer
//  chamfer shrinks to 0.5 mm and the mic1 hole moves 1.7 mm away from it
//  so the webs stay at 2 mm; downwards the frame's own wall bounds the
//  error, so that side stays close), and the seating ledge is relieved
//  below the ports. The cradle is no longer part of the shell: it is a
//  separate small print (part = "insert"), a U with v6's tight clearances
//  on a 1 mm sole, glued to the cavity back around the window while it
//  sits on the real adapters, so it aligns itself to wherever they are.
//  Two rails on the cavity back bracket the sole and key the glue joint.
//  Everything else is v6, edges included.
//
//  v7, 2026-09-22 (later, both variants): the walls wrap 1.5 mm further
//  forward, over the edge of the LED board, so the mask stands 1.0 mm
//  proud of the rim instead of 2.5 (`proud`; the lip is derived). The
//  board's outline is not in any drawing and is assumed 128.0 mm
//  (`board`); a stepped pocket appears automatically if board + clearance
//  exceeds the frame pocket. The shell is 1.5 mm deeper at the front,
//  nothing inside moves.
// ---------------------------------------------------------------------
//  Coordinates (design orientation, part = "shell"):
//    origin = centre of the panel frame back face
//    +X = right when looking at the BACK of the panel
//    +Y = up (the desk is towards -Y)
//    +Z = away from the LEDs, into the shell
//  The panel is installed rotated by panel_rot (90 deg CCW seen from
//  the back) so the controller USB-C ports face DOWN. The LED image
//  therefore has to be rotated 90 deg in firmware.
//
//  The shell is a wedge: depth_bottom deep where the controller and
//  cables live, thinning to depth_top at the top edge. The back face is
//  one flat inclined plane, so the print still lies flat on it.
//
//  part = "print"       -> back face on the bed, no supports needed
//  part = "assembly"    -> shell + translucent panel / chip / adapter / encoder mock-ups
//  part = "section_ad"  -> cut through the left (POWER) adapter
//  part = "section_win" -> cut along the adapters' centre line, seen from below
//  part = "section_y"   -> cut through the side screw bosses
//  part = "section_enc" -> cut through the right-hand encoder
//  part = "section_edge"-> cut through the walls at x = section_edge_x, clear of every feature: the edge profiles
//  part = "product"     -> the assembled display standing on a table (LED face mock-up)
//  part = "frame"       -> panel frame and controller only, seen from the back: where to notch the frame plate
//  part = "insert"      -> the cradle insert alone, sole on the bed (v7; a second, separate print)
// =====================================================================

part = "shell";            // "shell" | "print" | "assembly" | "section_ad" | "section_win" | "section_y" | "section_enc" | "section_edge" | "product" | "frame" | "insert"
section_edge_x = 33;       // where "section_edge" cuts: between two vent columns, clear of the encoder boards and the bosses

/* [Panel] */
panel      = 127.8;        // frame outer size, measured in RGB-Matrix-P2-64x64-2D.dwg (Waveshare quotes 128)
panel_clr  = 0.3;          // clearance per side between panel and pocket
frame_d    = 12;           // depth of the plastic frame behind the LED PCB
panel_stack = 2.5;         // LED board + mask in front of the frame's front face (measured on the v1 print: the mask
                           // stood 2.5 mm proud of a rim that ended at the frame)
proud      = 1.0;          // how far the mask stands proud of the rim (user choice 2026-09-22; was 2.5 = frame only)
lip        = frame_d + panel_stack - proud;   // how far the walls wrap forward over the frame: 13.5
board      = 128.0;        // LED board / mask outline (assumed: Waveshare quotes 128; not in any drawing, measure it)
board_clr  = 0.2;          // clearance per side beside the board; the pocket steps out if board + 2*board_clr exceeds it
panel_rot  = 90;           // panel rotation inside the shell, CCW seen from the back
// M3 inserts in the panel's own orientation (arrows up), from RGB-Matrix-P2-64x64-2D.dwg
holes_native    = [[0,56.85],[0,-56.85],[56.85,44],[-56.85,44],[56.85,-44],[-56.85,-44]];
hub75_in_native = [-35.0, 5.4];   // centre of the HUB75 IN header, panel orientation, seen from the back
frame_wall_t    = 1.6;            // the frame's outer wall (drawing); its inner face is at panel/2 - 1.6
frame_open      = 58.4;           // half-width of the frame's back opening at the ports (|y| < 16 native), from the drawing

/* [Shell] */
wall         = 2.0;    // side wall thickness
back_t       = 2.4;    // back wall thickness (perpendicular to the back face)
depth_bottom = 22;     // outer depth behind the frame back face at the bottom edge
depth_top    = 8;      // outer depth at the top edge (>= 8 keeps the top screw heads recessed)
tilt         = 12;     // lean-back angle in degrees
r_in         = 0.6;    // pocket corner radius (the frame corners are sharp; keep small)
ledge_w      = 1.6;    // seating ledge at the frame back face (0 = none); the frame's outer wall is 1.6 mm
ledge_t      = 1.5;
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

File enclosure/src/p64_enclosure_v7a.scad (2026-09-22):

// p64_enclosure_v7a.scad: the p64a shell (solder-less variant, no rotary encoders).
// The geometry lives in p64_enclosure_v7.scad; this file only switches the encoders off.
// The assignment must come AFTER the include: OpenSCAD lets the including file override
// an included file's variables that way (before the include it would be overwritten).
// Outputs: output/p64a/v7a/. Render with the same commands as v7b, this file instead.
include <p64_enclosure_v7.scad>
encoders = false;

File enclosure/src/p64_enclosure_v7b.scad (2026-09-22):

// p64_enclosure_v7b.scad: the p64b shell (soldered variant, two rotary encoders).
// The geometry lives in p64_enclosure_v7.scad; this file only states the variant.
// Outputs: output/p64b/v7b/ (identical to what p64_enclosure_v7.scad renders on its own).
include <p64_enclosure_v7.scad>
encoders = true;

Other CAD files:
enclosure/input/RGB-Matrix-P2-64x64-2D.dwg
enclosure/output/p64a/v7a/p64_enclosure_service.stl
enclosure/output/p64a/v7a/p64_cradle_insert.stl
enclosure/output/p64b/v7b/p64_enclosure_print.3mf
enclosure/archive/pre-v7/output/v6/p64_enclosure_service.stl
docs/video/pieces.scad
dhruv/p64.SLDPRT
enclosure/archive/2026-08-stand-concept/p64.scad
enclosure/archive/2026-09-dhruv-solidworks/p64.SLDPRT
enclosure/archive/pre-v7/output/v1/p64_enclosure_print.3mf
enclosure/archive/pre-v7/output/v1/p64_enclosure_print.stl
enclosure/archive/pre-v7/output/v2/p64_enclosure_print.3mf
enclosure/archive/pre-v7/output/v2/p64_enclosure_print.stl
enclosure/archive/pre-v7/output/v3/p64_enclosure_print.3mf
enclosure/archive/pre-v7/output/v3/p64_enclosure_print.stl
enclosure/archive/pre-v7/output/v4/p64_enclosure_print.3mf
enclosure/archive/pre-v7/output/v4/p64_enclosure_print.stl
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

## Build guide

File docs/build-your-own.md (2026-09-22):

# Build your own p64

This is the walk-through for building a p64 from the parts list in the
[README](../README.md). It assumes you can use a 3D printer or a print bureau, a
screwdriver and a command line. No soldering: the two boards plug together and the
power lead goes into screw terminals.

The state of things on 2026-09-21: the firmware is complete for version 1 and runs
daily on one device, but there is no ready-made firmware image yet, so step 3 compiles it
from source. The shell in the photos is version 1; the current design (v7) is not printed
yet. Both are covered below. p64 comes in two variants: **p64a** without rotary knobs
(no soldering at all) and **p64b** with two knobs on the back (soldered wiring, see
`docs/hardware/`); pick one before printing, the shells differ.

## 1. Order the parts

| Part | Notes |
|---|---|
| Waveshare ESP32-S3-RGB-Matrix | The driver board. Ships with the panel power lead (VH4 plug to bare wires), a 4-pin SH1.0 cable, screws and a small speaker that p64 does not use. |
| Waveshare RGB-Matrix-P2-64x64-B (or the standard RGB-Matrix-P2-64x64) | The 128 x 128 mm panel. The "-B" GOB version has a protective layer over the LEDs; both fit the shell. |
| A 5 V USB-C power supply, 3 A or more | Waveshare's PSU-27W-USB-C-B or any good phone charger. A laptop's USB port also powers it, but not at full brightness on bright content: full white at brightness 255 draws close to the panel's 15 W. |
| A USB-C cable | To power the device and, the first time, to flash it from a computer. For the v1 shell it must be a right-angle ("up/down angled") plug; for v7 any cable, plus two small 90-degree USB-C adapters (19.3 x 12.7 x 8 mm aluminium body, hand-measured in `enclosure/input/measurements.md`) and a drop of cyanoacrylate for the insert. |
| Six M3 x 10 screws | Into the panel's brass inserts. The heads sit 17 mm deep, so a long PH1 or hex driver is needed. |
| microSD card (optional) | FAT32. For your own files and for the Makapix cache; the device also runs without one. |

## 2. Print the shell

Everything is in `enclosure/`; its [README](../enclosure/README.md) explains the design.
Two versions matter:

- **v7, the current design:** `p64_enclosure_print.stl` (or `.3mf`) plus the small
  `p64_cradle_insert.stl`, a second print that is glued inside at the first assembly,
  both from `enclosure/output/p64a/v7a/` (no knobs) or `enclosure/output/p64b/v7b/` (two
  knobs). Cables plug into two 90-degree USB-C adapters that stay on the board's ports,
  reached through one window in the back face. It needs a small notch cut by hand in the
  panel's plastic frame (marked in red in `render_frame_notch.png` next to the STL). v7
  has not been printed yet; its window has room for the measurement errors the design
  carries, see the enclosure README.
- **v1, the proven one:** `enclosure/archive/pre-v7/output/v1/p64_enclosure_print.stl`. Printed by
  JLC3DP in black PLA for $18.83 including shipping, and verified to fit. The cable is a right-angle USB-C plug pushed up into the port from
  underneath, laid in a groove to a notch at the back. No knob mounts.

Print settings: the file already lies on its back face, no supports; 0.2 mm layers,
3 to 4 perimeters, 20 % infill, PLA or PETG, about 80 g; bed at least 140 x 140 mm;
enable elephant-foot compensation (0.1 to 0.2 mm) so the counterbores stay clean. For a
bureau printing in MJF or SLA use the `_service.stl` file with its larger clearance; for
FDM stick to `_print.stl`.

## 3. Build and flash the firmware

The firmware is under `firmware/`, built with ESP-IDF v5.5 (Espressif's SDK) in C++.

1. Install ESP-IDF v5.5.x for the ESP32-S3 target with Espressif's installer (EIM) or
   the [official instructions](https://docs.espressif.com/projects/esp-idf/en/v5.5/esp32s3/get-started/index.html).
2. Clone this repository.
3. On Windows, in PowerShell 7, from `firmware/`: edit the paths at the top of
   `tools/env.ps1` if ESP-IDF is not under `C:\esp\v5.5.4`, then

   ```
   .\tools\build.ps1
   .\tools\flash.ps1
   ```

   The scripts load the ESP-IDF environment themselves and find the board's serial port
   by its USB ID. On Linux or macOS the same project builds with the standard commands
   after sourcing ESP-IDF's `export.sh`, untested by the author so far:

   ```
   idf.py set-target esp32s3
   idf.py build
   idf.py -p /dev/ttyACM0 flash
   ```

4. Connect the computer to the board's **USB** port (the one nearer the middle of the
   board; the other, **POWER**, is power only). No button dance is needed; if flashing
   refuses, hold BOOT, tap RESET, release BOOT.

You can flash before or after assembly. Flashing later is fine too: the USB port stays
reachable in the shell.

## 4. Assemble

1. Plug the driver board onto the panel's **HUB75 IN** header (the panel has two headers,
   IN and OUT; Waveshare's product photos show which).
2. Connect the power lead: the VH4 plug into the panel's power socket, the bare wires into
   the board's 5 V and GND screw terminals, red to 5V.
3. v7 only: push a 90-degree adapter onto each of the board's USB-C ports, body towards
   the frame's edge, after cutting the frame notch. At the first assembly, glue the
   cradle insert to the inside of the back wall while the adapters carry it (the
   enclosure README's Assembly section has the steps). p64b: fit the two encoder boards
   on their pegs and nuts before the panel goes in.
4. Slide the panel into the shell from the front with the board at the **bottom**, so the
   USB-C ports point at the wedge. It seats on the ledge and the six bosses.
5. Fit the six M3 x 10 screws from the back.
6. v1: push the right-angle USB-C plug up into the port from underneath and lay the cable in
   the groove towards the back notch. v7: plug the cable into the adapter through the back
   window.

The firmware rotates the picture 90 degrees by default to match the shell. If you stand
the panel some other way, change the rotation in Settings, or set it to "auto" and the IMU
keeps the picture upright.

## 5. First run

1. Power on. A boot animation plays. Once the device is online it plays Makapix Club's
   Promoted channel, which needs no account; with a card that has files, those play first.
2. With no Wi-Fi network saved, after about a minute the device opens an open Wi-Fi network
   called **p64-setup**. Join it from a phone or laptop; a setup page opens by itself (or
   go to `http://192.168.4.1`). Pick your network from the list, enter the password,
   optionally give the device a name, and save. The device reboots and joins your network.
3. Open `http://p64.local` (or `http://p64-<name>.local`) in a browser. If your network
   does not resolve `.local` names, the device's IP address is in your router's client
   list.

From here everything is in the web UI:

- **Your own files:** upload from the Home page, or copy them onto the microSD card under
  `p64/animations/` and put the card in the slot (the device creates the folders on first
  use). GIF, PNG, APNG, WebP and BMP up to 256 x 256 pixels and 5 MB.
- **Makapix Club:** in Settings, the Makapix tab, press Pair. A six-character code shows
  on the panel; enter it on [makapix.club](https://makapix.club) within 15 minutes. The
  device then plays the channels you choose, and the site can send artworks to it.
- **Playsets:** group channels (your folders, Makapix channels, the clock and the other
  widgets) and choose what plays when.
- **Widgets:** the clock overlay, the clock faces, the weather (set your location) and
  the temperature, on the Widgets tab.
- **Streams:** from a computer with Python and Pillow,
  `python firmware/tools/stream_send.py p64.local image.gif` sends an image or animation,
  `... screen` mirrors your screen, `... test --ddp` sends a DDP test pattern. The panel
  returns to normal playback a few seconds after the stream stops.
- **Panel:** brightness, the night schedule, rotation, the Quality and Photo modes and the
  colour gains on the Display tab.

## 6. If something goes wrong

- **Dim or flickering at high brightness on laptop power:** the USB port cannot supply the
  panel at full white. Use the 27 W supply on the POWER port, or lower the brightness.
- **Cannot reach `p64.local`:** use the IP address from your router, or check the serial
  console (`.\tools\monitor.ps1`, or `idf.py monitor`) where the device prints it at boot.
- **Wrong network saved:** hold BOOT for 10 seconds at power-on. The panel counts down
  the last 3 seconds and the device resets to factory state, including Wi-Fi.
- **After a firmware update the device boots the old version:** an update that fails to
  boot rolls back on its own; the Update page shows both versions and lets you roll back
  by hand.
- Anything else: `firmware/docs/api.md` documents the HTTP API, and
  `http://p64.local/api/v1/status` reports what the device thinks is going on.

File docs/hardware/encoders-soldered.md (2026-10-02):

# Soldered option: two rotary encoders, with soldering

Written 2026-09-21, before anything was built. Both options belong to **p64b**, the variant with encoders; p64a has none. This is the complete project for the two
Adafruit 5880 encoders on the p64, from the parts on the table to two working knobs
inside the p64b shell (enclosure v7b). Its sibling, [the solderless option](encoders-solderless.md), is the one-encoder
project without soldering; the electrical facts (section 3 there) are the same and are
only summarised here.

Two tiers, both documented:

- **Tier 1, one solder bridge.** The only soldering that two 5880s strictly need is the
  address jumper A0 on the second board. Everything else stays on the breadboard, so the
  project can be built and the firmware finished before any further soldering.
- **Tier 2, the permanent harness.** The two pull-up resistors soldered onto board 1 and
  the two cables either mated pin-to-socket or spliced, so nothing but boards and cables
  goes into the shell.

Figures are generated by `tools/draw_encoders.py` (schemdraw) into `img/`; an ASCII
version follows each figure.

Roles decided on 2026-09-20: knob A (address 0x36) turn = brightness, press = pause /
resume; knob B (0x37) turn = next / previous, press = Makapix like; a long press is
unassigned; a settings switch swaps A and B once the shell shows which knob is left.

## 1. Parts

On hand (2026-09-21): the two 5880 boards, the two 5528 knobs, the 4209 and 4397 cables
(150 mm), the 4399 cable (50 mm), the 2.2 k resistors, the ELEGOO breadboards, fine
tweezers, jumper wires or header pins (the 5880 bags include a short header strip each).
The soldering kit of the table below arrived on 2026-09-26, the multimeter (Klein MM325)
and the solder wick on 2026-09-27, the replacement 5880 for knob B on 2026-10-01; the
200 mm 4401 cable and a 2 mm hex key are on hand too (2026-10-01). The
"no multimeter" notes in sections 3.3, 4 and 6.1 stay for a builder without one: the
probe firmware (section 5) is the check that matters.

Still needed:

| Part | For | Note |
|---|---|---|
| Electrical tape or 3 mm heat-shrink | wrapping the cable joints | tape is fine |
| Tier 2 only: 1/4 W 2.2 k resistors (optional) | neater on the board than 1/2 W | the 1/2 W parts work, they are just bulky |
| Tier 2 splice only: wire strippers, 2 mm heat-shrink, a lighter or heat gun | joining the cables | only if the pin-to-socket joints are not wanted |

The soldering kit (on hand since 2026-09-26). The picks are examples chosen on 2026-09-23 for this
project's three small jobs (a surface-mount bridge, two through-hole resistors, perhaps a
rework); any part meeting the spec does:

| Part | Spec | Example | Note |
|---|---|---|---|
| Soldering iron | temperature-controlled, fine conical or small chisel tip | Pinecil V2 (ships with the TS-B2 short tip, fine enough for A0) | runs on any USB-C PD charger of 65 W or more (12 to 20 V) with a C-to-C cable rated 3 A or more; the Miniware TS101 is the equal, dearer alternative |
| Iron stand | holds the hot iron between joints | any "TS100 / Pinecil" stand | the Pinecil comes without one |
| Solder | leaded 63/37, rosin flux core, 0.8 mm (0.031") | Kester 44, 1 oz dispense pak (24-6337-0027) | eutectic: no pasty range, the most forgiving on 0.3 mm pads; 1 oz is a lifetime of this project; avoid unbranded "60/40" spools |
| Flux pen | rosin or no-clean | Kester 951 or MG Chemicals 8341 | makes the A0 bridge a one-touch job, and pulls an A0/A1 bridge apart |
| Tip cleaner | brass wool in a holder | Hakko 599B-02 | does not cool the tip as a wet sponge does |
| Solder wick | desoldering braid, 2 mm | Chemtronics Soder-Wick #2 or MG Chemicals | removes surplus solder (section 8) |
| Flush side cutters | small, flush-cutting | Hakko CHP-170 | trims the resistor leads (section 6.1) |
| Isopropyl alcohol | 91 to 99 %, with cotton swabs | any | cleans the flux off |
| Safety glasses | any | | clipped leads fly |

Not needed: a fume extractor (a window or a fan is enough for five joints), a
helping-hands clip (tape holds the board), spare tips, a silicone mat.

## 2. Electrical summary

Full reasoning and numbers in the solderless option, section 3. In one table:

| Fact | Consequence |
|---|---|
| The controller's only spare connector is the 4-pin JST-SH "GPIO" socket: pin 1 IO45, 2 IO46, 3 3V3, 4 GND (schematic) | second I2C bus, IO45 = SDA, IO46 = SCL |
| STEMMA QT order is GND, V+, SDA, SCL; the socket's is signal, signal, 3V3, GND | never a straight SH-SH cable to the controller; 4209 + 4397 joined by function |
| IO45/IO46 carry 10 k pull-downs (R59/R60); each 5880 has 10 k pull-ups | two boards alone idle at 2.20 V, below the 2.475 V threshold; with one 2.2 k per line: 2.86 V |
| IO46 high at reset breaks the manual download mode | whether USB flashing still works is tested on the bench; if not, unplug the header pins to flash |
| Two seesaw boards need different addresses | board 2 gets jumper A0 bridged: 0x37 |

bus

```
 controller GPIO socket           your 2.2k pull-ups        board 1 (0x36)      board 2 (0x37, A0 bridged)
 IO45 (R59 10k to GND) ---SDA---+----[2.2k]---3V3----------- SDA ---- SDA ---4399--- SDA
 IO46 (R60 10k to GND) ---SCL---+----[2.2k]---3V3----------- SCL ---- SCL ---4399--- SCL
 3V3 -------------------------------------------------------- V+  ---- V+  ---4399--- V+
 GND -------------------------------------------------------- GND ---- GND ---4399--- GND
```

## 3. Soldering, tier 1: the A0 bridge on board 2

This is the smallest soldering job there is: joining two pads that are 0.3 mm apart with
one blob of solder. Do it before the bench build, on the board that will be knob B.

**Test the board before the iron touches it** (lesson of 2026-09-27: the first board B
was bridged untested and then answered at no address, so whether it arrived dead was
never known). Plug the untouched board alone onto the harness and power up: its NeoPixel
lights green and `GET /api/v1/diag/encoders?scan=1` lists 0x36. Only then bridge A0, and
plug it alone again: blue, and 0x37.

### 3.1 Setup

- Iron at 330 °C for leaded 63/37 solder (the range is 320 to 350 °C; lead-free would
  need 350 to 380 °C). A fine conical or small chisel tip (the Pinecil's TS-B2). Ventilate;
  do not breathe the smoke; wash hands after leaded solder.
- Tin the tip: melt a little solder onto it, wipe it in the brass wool; the tip should be
  shiny.
- Board on the bench, back side up, held down with a bit of tape. Find the three jumpers labelled A0, A1, A2 (Adafruit's pinout page); each is a
  pair of small pads with a narrow gap. Only A0 is touched.

### 3.2 The bridge

1. Dab flux on the A0 pads (optional but makes step 3 a one-touch job).
2. Put a small bead of solder on the tip.
3. Touch the tip flat across both pads for one to two seconds. The solder flows onto
   both pads and fills the gap. Lift the iron straight up.
4. Look at it under good light: a smooth, shiny bridge spanning both pads, not a ball
   sitting on one pad, and nothing touching the neighbouring A1 pads or any trace.
5. If it bridged only one pad, add flux and touch again. If it bridged A0 and A1
   together, drag the iron tip across the excess to pull it away, or add flux and wipe
   the tip along the gap; the surplus follows the tip. If that fails, lay solder wick on
   the bridge and press the iron on the wick for two seconds: it soaks the solder up;
   then start again from step 1.
6. Clean the flux with isopropyl alcohol on a cotton swab.

### 3.3 Checks

- Multimeter in continuity mode across the two A0 pads: beep.
- Continuity between the A0 pads and the neighbouring A1 pads: no beep.
- The real test is the probe firmware (section 5): the board must answer at 0x37, and
  the NeoPixel colour tells which board is which.
- No multimeter: inspect under a magnifier or the phone camera zoomed in. A bridge that
  looks continuous and shiny across the A0 gap, with a clear dark gap to A1 on both sides,
  passes; the probe settles it. A board that still answers at 0x36 has an open bridge;
  one that answers at 0x38 has A1 bridged too (an A0+A1 bridge gives 0x39: fix it,
  section 3.2 step 5). A short to a neighbouring trace is unlikely from one small bead but
  is why the inspection is for a gap on both sides.
- Mark the board (a dot of paint or tape on the edge) as "B / 0x37".

## 4. Bench build

Same as the solderless option, section 4, with the second board chained. Nothing is powered until
step 5.

bench map

```
 Adafruit 4209 (controller)      breadboard             Adafruit 4397 (board 1)         4399 (board 1 to board 2)
 yellow pin = IO45 (SDA) ------> row 5  <--[2.2k]--> + rail   row 5  ------> blue socket   = SDA   board 1 0x36 --50 mm--> board 2 0x37
 blue pin   = IO46 (SCL) ------> row 10 <--[2.2k]--> + rail   row 10 ------> yellow socket = SCL
 red pin    = 3V3        ------> + rail                       + rail ------> red socket    = V+
 black pin  = GND        ------> - rail                       - rail ------> black socket  = GND
```

1. Board off (USB and POWER unplugged).
2. Identify the socket pins with the 4209 plugged in and the controller on USB: the pin
   at 3.3 V (expected red), the pin with continuity to the USB-C shell (expected
   black), the two IO pins near 0 V (yellow = IO45, blue = IO46). Record the colours.
   Power off.
3. Plant the four pins: yellow in row 5, blue in row 10, red in the + rail, black in the
   - rail.
4. One 2.2 k from row 5 to the + rail, one from row 10 to the + rail.
5. Power on, measure rows 5 and 10 against the - rail: about 2.7 V expected (3.3 V would
   mean the pull-downs are not fitted; the resistors stay either way). Power off.
6. Header pins into rows 5 and 10 and the two rails; the 4397's sockets onto them by
   function (blue row 5, yellow row 10, red +, black -); its SH plug into board 1 (the
   unmodified 0x36 board).
7. The 4399 from board 1's free socket to board 2 (A0 bridged).
8. Power on, measure again: about 2.86 V (two boards' pull-ups in parallel with the
   2.2 k). Record.
9. `.\tools\flash.ps1` from `firmware/` with everything connected: the IO46 question.
   Pass: the chain stays connected for good. Fail: pull the four 4209 pins to flash.
10. Note `GET /api/v1/diag/memory` once as the baseline.

No multimeter: skip steps 2, 5 and 8. The keyed plug settles the colours (found
2026-09-26): yellow = IO45 (SDA), blue = IO46 (SCL), red = 3V3, black = GND, i.e. the
4209 lands with black on socket pin 4, next to the board's GND label. Before the first
power-up, read the silkscreen beside the socket once more and confirm that the black
wire sits on the pin marked GND and the red one on 3V3: those two are the pair whose
swap could damage a board; the two signal wires swapped only make the probe fail. The
voltages are then inferred: if the probe firmware reads both boards without errors, the
levels are high enough.

Bench record:

| Item | Expected | Measured |
|---|---|---|
| 3V3 / GND pin colours on the 4209 | red / black (keyed plug, 2026-09-26) | |
| Rows 5 and 10, resistors only | ~2.7 V | |
| Rows 5 and 10, both boards | ~2.86 V | |
| A0 continuity on board 2 | beep | beep (2026-09-27, Klein MM325) |
| A0 to the A1 pads on board 2 | no beep | top A1 pad beeps, bottom does not; top A2 to top A1 beeps, bottom to bottom does not: the top row is the jumpers' shared rail, the chip-side pads are clear (2026-09-27) |
| A1 pads on board 2 | no beep | no beep |
| SDA to SCL on board 2, unpowered | ~20 k | 19.93 k (the two 10 k pull-ups in series); SDA or SCL to the VIN pad reads OL, as an unpowered regulator does |
| SDA, SCL, VIN to GND on board 2 | no beep | no beep |
| Board 2 alone on the 4397, powered | 3Vo 3.3 V, SDA and SCL ~2.86 V | 3Vo 3.3 V, SDA 2.88 V, SCL 2.88 V; `?scan=1` empty, both lines idle at 1 |
| `flash.ps1` with IO46 pulled high | works | works with the chain attached (2026-09-26): the chain stays connected for good |
| Free internal heap, largest block, before the probe | from `/diag/memory` | |

## 5. Firmware

Identical to the solderless option, section 6, with two devices. Only the differences:

- **Probe (stage B):** the driver opens both addresses; at start the NeoPixel of 0x36 goes
  green and that of 0x37 blue for two seconds, so the boards identify themselves;
  `GET /api/v1/diag/encoders` and `tests/device/encoders_smoke.py` report both. A board
  that does not answer is logged once and polled again every 5 s (a loose cable must not
  take the other knob down). With the socket empty (every p64a) both lines idle low under
  the controller's pull-downs, and the firmware then reads the levels instead of probing:
  a probe of a low bus times out with an error line from the I2C driver every time (seen
  2026-09-29), while a probe of a high bus with no board at the address is a quiet NACK.
  Written 2026-09-26, before the first power-up
  (`firmware/components/p64_inputs/src/seesaw_wire.hpp`, `seesaw.cpp`,
  `encoder_model.cpp`, `encoders.cpp`; `firmware/docs/architecture.md` 16.1; Kconfig
  `P64_ENCODERS`, `P64_I2C_EXT_SDA/SCL`, `P64_ENCODER_A/B_ADDRESS`).
- **Roles (stage C, built 2026-09-26):** knob A = 0x36: turn = brightness, 7 per detent
  (an even step of perceived lightness since 2026-09-27, 37 detents from 1 to 255;
  `knob_rules.hpp`), shown at once
  and written to the setting 800 ms after the last detent (one NVS write per spin, on an
  internal stack; the poll task never touches flash), press = pause / resume. Knob B =
  0x37: turn = next / previous, press = like the current Makapix artwork (no-op on card
  artworks; the like call blocks up to 20 s, so it runs on its own short-lived task, never
  on the poll task or the show loop). Settings, group `inputs`: `encoders_enabled`,
  `encoders_swap` (A and B exchange roles), `encoders_invert`; the settings page's Inputs
  tab has them and shows which boards answer.
- **Acceptance:** as in A, on both knobs, plus: turning both at once loses no detents;
  unplugging the 4399 while running logs the loss and does not disturb knob A.

### 5.1 Bench state and what to resume (2026-09-26)

- Knob A: accepted on the bench. Stage B: 10 detents clockwise counted +10 and 10 back
  landed on exactly 0, two presses and a long press registered, no read errors, clockwise
  positive (so `encoders_invert` stays off). Stage C: see the progress log for what was
  verified on the device.
- The knob cap (2026-09-27): with the cap pushed fully down the shaft, three clicks
  registered nothing (`presses` stayed 0, no read errors, the switch pin steady at
  released); with the cap off, three clicks counted 3 and toggled the pause. The shaft's
  push travel is well under a millimetre and a cap seated on the nut takes it up. Seat
  the cap with a visible gap, about 1 mm, above the nut, and check `presses` on
  `GET /api/v1/diag/encoders` after fitting it (section 8). Reseated that way the same
  day, the click pauses and resumes the show with the cap on.
- Board B: silent after the A0 bridge. Its ON LED lights; alone on the 4397, on either of
  its sockets, it answers at no address (`?scan=1` empty) with both bus lines idle high;
  board A put back on the same plug answers at once. The photo of the back shows a small
  blob on the A0 pads, A1 and A2 untouched, the 103 pull-up network and the NeoPixel pads
  clean.
- 2026-09-27, with the meter: the bridge conducts, no short to A1 or A2 (the top pad of
  each jumper is a shared rail, so A0-to-top-A1 beeps by design), the pull-ups read
  19.93 k, the board alone powers up (3Vo 3.3 V, SDA and SCL 2.88 V) and still answers at
  no address. So the bridge is not visibly at fault and the chip is not running or not
  talking; the board has no RST pad to read. The bridge was then wicked off (A0 open on
  the meter, pads intact) and the board plugged alone on the 4397 again: ON LED lit,
  3Vo 3.3 V, three scans empty, both lines idle high. **Verdict, 2026-09-27: board B's
  microcontroller is dead; replace the board** (a fresh 5880; ask Adafruit or the
  reseller about the one that never answered). The dead board keeps its knob, nut and
  washer for the replacement. Knob A runs alone meanwhile.
- 2026-10-01, the replacement 5880, tested before soldering: alone on the 4397 it lit
  green and answered at 0x36 (hardware id 0x55, 47 detents, 0 read errors). A0 bridged
  with flux and a small bead; on the meter the A0 pads beep, the chip-side pads of A0 and
  A1 do not, the A1 pads do not, SDA to SCL reads about 20 k. Alone again: blue, 0x37.
- 2026-10-01, both knobs, the bench acceptance of section 5, all passed on the breadboard
  harness with the 50 mm 4399 between the boards: A green and B blue at boot;
  `encoders_smoke.py --expect 2 --watch 45` 0 failures with both knobs turned at once
  (dozens of detents each way, presses on both, 0 read errors on either board); knob B
  turns next and previous and its press likes the Makapix artwork on the panel (the log
  says "liked post 1567"; on a card artwork it says there is nothing to like); the 4399
  pulled from board B while running: knob B dropped after ten failed reads, knob A kept
  the brightness with 0 errors and was never lost, and B was found again at 0x37 without
  a reboot, with its blue identify, about 15 s after the plug went back.
- Next: tier 2 (section 6): the two pull-ups soldered onto board A, and the cables mated
  pin to socket, not spliced (decided 2026-10-01). Then the shell (section 7): the v7b
  print is ordered and awaited (2026-10-01); when it arrives, lay the washer and nut in a
  spot-face before anything else (their diameter is still unmeasured).

## 6. Soldering, tier 2: the permanent harness

Do this after the firmware is accepted on the bench: the breadboard is then the last
thing between the bench and the shell.

### 6.1 The pull-ups on board 1

The 5880 has a row of plated header pads along one edge: VIN, 3Vo, GND, SCL, SDA, INT
(names from Adafruit's pinout page; the silkscreen shows the order). The pull-ups must
go to VIN, which is the 3.3 V the controller supplies and the level the board's own
pull-ups use.

1. Bend each resistor's leads down so it can stand on the board's back (the side
   without the encoder), one lead in the VIN hole, the other in the SDA hole for the
   first resistor and in the SCL hole for the second. Two leads share the VIN hole:
   push one through from each side, or twist the two lead ends together first. With the
   1/2 W bodies this is bulky; 1/4 W resistors lie flat between the holes.
2. Solder each lead in its hole from the component-free side: touch pad and lead with
   the tip, feed solder for one second, lift. A good joint is a shiny cone wetting both
   the pad and the lead.
3. Cut the leads flush with side cutters.
4. Check: continuity between the SDA pad and VIN reads about 2.2 k on the ohms range
   (the 10 k on the board in parallel shows about 1.8 k); the same for SCL. No
   continuity between SDA and SCL, or between VIN and GND. No multimeter: inspect each
   joint for a shiny cone with clear gaps to the neighbouring pads, then run
   `encoders_smoke.py`; a VIN-to-GND short would show as the board not lighting its
   NeoPixel and would be visible as solder across two adjacent holes.

Board 2 gets no resistors: one pair per bus.

### 6.2 The cables

Two acceptable ways; the first needs no soldering at all and is what the author
recommends for a first project.

**Mated (no solder).** Each male pin of the 4209 pushes into one female socket of the
4397, paired by function, each joint wrapped in tape or heat-shrink:

harness

```
 4209 (controller)            4397 (board 1)
 yellow pin (IO45 = SDA) --->  blue socket   (SDA)
 blue pin   (IO46 = SCL) --->  yellow socket (SCL)
 red pin    (3V3)        --->  red socket    (V+)
 black pin  (GND)        --->  black socket  (GND)
```

**Spliced (solder).** Cut the header end off the 4209 and the socket end off the 4397,
leaving the lengths the shell needs (about 60 mm each is plenty: the GPIO socket is
20 mm from the right-hand board). Strip 5 mm of each wire, slide a 20 mm piece of 2 mm
heat-shrink onto one side, twist the pairs by function (yellow-4209 to blue-4397,
blue to yellow, red to red, black to black), tin each twist with the iron, slide the
heat-shrink over it and shrink. Then a larger piece over all four. Do one pair at a
time; the colours cross, so label the 4209 side first.

### 6.3 Between the boards

The 200 mm 4401 (or a 100 mm 4210, tight) from board 1's free socket to board 2. The
sockets face up and down in the shell, so the cable runs down from the right board, along
the bottom of the cavity, above the two USB-C adapters and the cradle insert, and up into
the left board.

## 7. In-shell assembly

The p64b shell (enclosure v7b, `enclosure/output/p64b/v7b/`) has both encoder positions:
shafts at (±47, -25) mm on the back face, i.e. 19 mm in from each side edge and 41 mm up
from the bottom edge. Each position has four posts from the inside of the back wall, each
ending in a 2.2 mm peg for one of the board's 2.5 mm holes, a 7.4 mm hole for the bushing
and, outside, a 14 mm spot-face 0.4 mm deep that gives the washer and nut a flat seat on
the sloping wall (`enclosure/README.md`, "Encoders (p64b only)", and
`enclosure/src/p64_enclosure_v7.scad`). The pegs only key the board so it cannot turn; the
washer and nut clamp it and take the knob's push. The boards go in before the panel, which
closes the shell's open front.

1. Firmware accepted on the bench, tier 2 done, power off.
2. First time only, on the fresh print: lay the washer and nut in a spot-face. Their outer
   diameter and the nut across its corners have not been measured
   (`enclosure/input/measurements.md`); an M7 set is about 11 to 12 mm, the seat is 14.
3. Plug the 4397 (or the spliced harness) into board 1 and the 4401 between the boards
   before mounting: once mounted the STEMMA QT sockets face up and down, 4.5 mm from the
   side wall, and are hard to reach.
4. Board 1 (0x36, with the resistors) goes to the right-hand position (seen from the
   back), nearest the controller's GPIO socket; board 2 to the left. Turn each board with
   its two sockets up and down and the header pads towards the centre of the shell; that
   is the only orientation the shell leaves room for. If the shell shows the roles should
   be the other way round, `encoders.swap` fixes it without rewiring.
5. From inside, push each board onto its four pegs with the shaft through the 7.4 mm
   hole, until the bushing base sits flat on the inner wall. A tight peg (elephant foot)
   gets a light trim, not force.
6. From outside, washer and nut on the bushing, hand-tight, at most 10 kgf·cm. With the
   shell on its side, a finger inside holds the board while the nut starts. The 6.0 mm
   bushing leaves 4.0 mm of thread for the 2.5 mm washer and nut.
7. Knobs on, black mark up, set screw onto the flat of the D-shaft with the 2 mm hex
   key.
8. Route the harness from the controller's GPIO socket (on the controller's right edge
   at about the encoders' height) to board 1; coil the slack flat against the back wall,
   away from the controller's power leads and the two USB-C adapters; the board-to-board
   cable along the bottom (section 6.3).
9. Connect the chain to the GPIO socket while the panel is still outside the shell, then
   slide the panel in (controller at the bottom) and fit the six M3 x 10 screws, as in
   `enclosure/README.md`, "Assembly". The pin stubs under each board reach 3.0 mm into
   the 4.1 mm left to the panel frame, so the panel seats clear of them.
10. Run `encoders_smoke.py` again with the shell closed, both knobs.

To take a board out: panel out, knob off, nut and washer off, then the board lifts off
its pegs.

Fitting the caps: push each cap on until about 1 mm of shaft shows above the nut, not
all the way down. The push switch travels less than a millimetre, and a cap resting on
the nut turns without ever pressing it (bench, 2026-09-27: three clicks counted 0 with
the cap down, 3 with it off). Then click each knob and watch `presses` on
`GET /api/v1/diag/encoders`.

The knobs are the deepest point of the shell, 13 mm past its bottom edge: the display
stands as p64a does, but laid on its back it rests on the knobs.

## 8. What can go wrong

| Symptom | Likely cause | Check |
|---|---|---|
| Both boards answer at 0x36 (probe says "0x37 missing"; both NeoPixels green at boot) | A0 bridge not conducting | continuity across the A0 pads |
| A board's ON LED lights but it answers at no address, alone on the harness that works with the other board, and `GET /api/v1/diag/encoders?scan=1` shows both lines idle at 1 | the board itself: solder beyond the A0 pads, a lifted pad, or a board that never ran | meter it (A0 beep, chip-side A1/A2 pads clear, SDA to SCL ~20 k, powered 3Vo 3.3 V and lines ~2.9 V), wick the bridge off and scan at 0x36; still silent with bare pads = dead chip, replace (bench, 2026-09-27: board B, every reading normal, never answered) |
| A board answers at 0x38 or 0x3A | the wrong jumper was bridged (A1 = 0x38, A2 = 0x3A) | fine, the firmware can take the address as a setting; or fix the bridge |
| Rows read 2.2 V with both boards | a pull-up missing or in the wrong row | resistor legs in rows 5 / 10 and the + rail |
| Knob B works, knob A does not, or vice versa | the 4399 / 4401 not seated | reseat; the probe re-polls a missing board every 5 s |
| `flash.ps1` cannot enter download mode | IO46 high at reset | pull the four 4209 pins (or open the joints), flash, replace |
| Solder bridge across A0 and A1 | too much solder | flux and drag the tip to pull the excess; if it stays, solder wick, then redo the bridge |
| Device reboots when a knob is turned | the poll task touched flash (NVS) | brightness through the settings path from the show loop only |
| Count runs backwards | sign convention | `encoders.invert` |
| A knob turns (detents count) but its click does nothing: `presses` stays 0, no read errors | the cap is seated on the nut and takes up the shaft's push travel (2026-09-27, knob A) | lift the cap about 1 mm; click with the cap off to prove the switch |

## Sources

- Waveshare ESP32-S3-RGB-Matrix schematic (GPIO socket U8, R59/R60 10 k):
  https://github.com/waveshareteam/ESP32-S3-RGB-Matrix/tree/main/hardware/schematics
- Adafruit 5880 guide (pinout, 10 k pull-ups, jumpers A0/A1/A2 = 0x37/0x38/0x3A):
  https://learn.adafruit.com/adafruit-i2c-qt-rotary-encoder/pinouts
- Adafruit seesaw register map: https://github.com/adafruit/Adafruit_Seesaw
- Adafruit 5528 knob (6 mm bore, 2 mm hex set screw): https://www.adafruit.com/product/5528
- ESP32-S3 datasheet, VIH min 0.75 VDD; strapping pins IO45/IO46.
- Shell: `enclosure/README.md` ("Encoders (p64b only)" and "Assembly") and
  `enclosure/src/p64_enclosure_v7.scad`, rendered as `src/p64_enclosure_v7b.scad`.

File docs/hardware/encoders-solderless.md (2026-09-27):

# Solderless option: one rotary encoder, no soldering

Written 2026-09-21, before anything was built. Both options belong to **p64b**, the variant with encoders; p64a has none. This is the complete project for one
Adafruit 5880 encoder on the p64, from the parts on the table to a working knob inside
the shell, without a soldering iron. Its sibling, [the soldered option](encoders-soldered.md), is
the two-encoder project with soldering. Both share the same electrical facts, the same
bench test and the same firmware plan; they differ in the number of boards, in how the
second address is set and in how the harness is made permanent.

Figures are generated by `tools/draw_encoders.py` (schemdraw) into `img/`; an ASCII
version follows each figure so the text stands on its own.

## 1. The short answer

Yes, with one encoder the project is solderless, in two steps:

- **On the bench** it is solderless without any caveat: the pull-up resistors and the
  pin-order crossing live on the ELEGOO breadboard. Sections 3 to 6.
- **Inside the shell** it stays solderless if one of three things holds, and the first
  bench measurement (section 4, step 4) tells which apply:
  1. the controller's IO45/IO46 pull-downs turn out not to be fitted: then no resistors
     are needed and the harness is just the two cables mated pin-to-socket;
  2. the resistors are needed, and a tiny breadboard (46 x 36 x 10 mm) rides inside the
     shell: this needs a shell revision with a pocket for it, because the v7b shell (like
     v6 before it) has no free 10 mm-deep flat of that size (section 7.2);
  3. the resistors are needed, and the Adafruit 5880 is swapped for a SparkFun Qwiic
     Twist, which carries its own 2.2 k pull-ups: no resistors, no breadboard, no solder,
     but a different board than the one on the table (section 7.3 and the appendix).

The soldering that the two-encoder project needs is only the address jumper on the
second board. With one board there is nothing to bridge.

Roles decided on 2026-09-21: turn = next / previous artwork, press = pause / resume.
Brightness stays on the web UI and on Makapix.

## 2. Parts

On hand (2026-09-21):

| Part | Used for |
|---|---|
| Adafruit 5880, I2C QT Rotary Encoder with encoder soldered (seesaw, address 0x36) | the knob |
| Adafruit 5528, 20 mm aluminium knob, 6 mm bore, set screw | the knob cap |
| Adafruit 4209, JST-SH 4-pin to premium male headers, 150 mm | controller socket to breadboard |
| Adafruit 4397, JST-SH 4-pin to premium female sockets, 150 mm | breadboard to encoder board |
| Adafruit 4399, JST-SH to JST-SH, 50 mm | not needed with one board (the soldered option uses it) |
| 2.2 kΩ resistors, 1/2 W, 5 % (40) | two pull-ups; the wattage is irrelevant here, 1/4 W would be neater |
| ELEGOO 400-point breadboards (3) | the bench junction |
| Multimeter | pin identification and the idle-level measurement |
| Jumper wires or 0.1-inch header pins | the 4397's female sockets need a pin to grip; the 5880 bag includes a short header strip |

Still needed:

| Part | For | Note |
|---|---|---|
| 2 mm hex key | the knob's set screw | not included with the knob (Adafruit) |
| Tiny breadboard, 46 x 36 x 10 mm (e.g. Adafruit 65) | in-shell path 2 only | plus double-sided foam tape |
| SparkFun Qwiic Twist (DEV-15083) | in-shell path 3 / appendix only | about $25 |
| Electrical tape or 3 mm heat-shrink | wrapping the pin-to-socket joints inside the shell | tape is fine |

## 3. The facts behind the wiring

### 3.1 The only spare connector

The ESP32-S3-RGB-Matrix brings out one spare connector: the 4-pin JST-SH 1.0 mm socket
labelled GPIO (U8 on Waveshare's schematic). Its pins, per the schematic:

| Socket pin | Signal | Our use |
|---|---|---|
| 1 | IO45 | SDA of the second I2C bus |
| 2 | IO46 | SCL of the second I2C bus |
| 3 | 3V3 | V+ of the encoder board |
| 4 | GND | GND |

The controller's internal I2C bus (IO47/IO48, with the IMU, RTC and SHTC3) is not on any
connector, so the encoder gets a bus of its own. Verify the pin order with the
multimeter before plugging anything else in (section 4, step 2).

### 3.2 STEMMA QT pin order is different

STEMMA QT / Qwiic cables are wired GND, V+, SDA, SCL (black, red, blue, yellow). The
Waveshare socket is signal, signal, 3V3, GND. A plain SH-to-SH cable between the two
would put 3.3 V on the encoder's SDA pin and ground on its V+ pin. That is why the
harness is made of the 4209 (SH plug to male pins) and the 4397 (SH plug to female
sockets), joined by function. The keyed SH plug of the 4209 fits the controller's socket
one way only, and that way (found on 2026-09-26 by plugging it in; the schematic order
was read the other way round when this was written) lands black on pin 4:

| 4209 wire | Lands on socket pin | Is actually |
|---|---|---|
| yellow | 1 | IO45 = SDA |
| blue | 2 | IO46 = SCL |
| red | 3 | 3V3 |
| black | 4 | GND |

So power and ground keep their colours, and only the two signal wires lie: yellow (SCL
by convention) carries SDA and blue (SDA by convention) carries SCL. Only on the 4397
(plugged into the encoder board) do all four colours mean what they say.

The whole bus, as a schematic:

bus

```
 controller GPIO socket           your 2.2k pull-ups          Adafruit 5880 (0x36)
 IO45 (R59 10k to GND) ---SDA---+----[2.2k]---3V3------------ SDA   (10k pull-up on board)
 IO46 (R60 10k to GND) ---SCL---+----[2.2k]---3V3------------ SCL   (10k pull-up on board)
 3V3 -------------------------------------------------------- V+
 GND -------------------------------------------------------- GND
```

### 3.3 The pull-downs, and why two resistors are needed

Per the schematic, IO45 and IO46 each carry a 10 k pull-down to ground on the controller
(R59, R60). The 5880 carries 10 k pull-ups to V+ on SDA and SCL. Together they form a
voltage divider: the idle level of each line is 3.3 V x 10k / (10k + R_up), where R_up
is every pull-up in parallel.

idle level

```
        3V3
         |
       [R_up]   all pull-ups in parallel
         |
         +------ V_idle = 3.3 V x 10k / (10k + R_up)
         |
       [10k]    R59 (SDA) or R60 (SCL), on the controller
         |
        GND
```

The ESP32-S3 reads a HIGH only above 0.75 x 3.3 V = 2.475 V (datasheet VIH). Cases:

| Configuration | R_up | V_idle | Result |
|---|---|---|---|
| one 5880, nothing else | 10 k | 1.65 V | fails: the bus never reads idle |
| one 5880 + 2.2 k on each line | 1.80 k | 2.80 V | ok |
| two 5880 + 2.2 k (soldered option) | 1.53 k | 2.86 V | ok |
| Qwiic Twist alone (its own 2.2 k) | 2.2 k | 2.70 V | ok, small margin |
| 5880 + Qwiic Twist (appendix) | 1.80 k | 2.80 V | ok |
| pull-downs not fitted | any | 3.3 V | ok, no resistors needed |

The low level is unaffected: the seesaw pulls the line to ground through 1.5 to 1.8 k,
about 2 mA, well within what I2C allows. Nothing here is delicate; a 1.5 k or 3.3 k
resistor would also work. 2.2 k is what is on the table.

### 3.4 Strapping pins

IO45 and IO46 are ESP32-S3 strapping pins. IO45 selects the flash voltage at reset,
which the N32R16V module fixes by eFuse, so a pull-up on IO45 is harmless. IO46 high at
reset makes the ROM's manual download mode an invalid combination. Whether the USB
Serial/JTAG reset that the flash script uses still enters download mode with IO46 pulled
high is unknown and is settled on the bench (section 4, step 8). If it does not, the
rule is: pull the 4209's four header pins out of the breadboard (or the joints, in the
shell) before flashing, never the SH plug (SH connectors are rated for few mating
cycles).

### 3.5 Bus speed and cable length

150 + 150 mm of cable at 100 kHz is comfortable. The firmware starts at 100 kHz and tries
400 kHz only after everything else is verified.

## 4. Bench build

One ELEGOO breadboard. Rows are numbered along the long side, five tie points per row
per half; the two long strips on each edge are the + and - rails. Nothing is powered
until step 5.

bench map

```
 Adafruit 4209 (controller)      breadboard             Adafruit 4397 (encoder board)
 yellow pin = IO45 (SDA) ------> row 5  <--[2.2k]--> + rail       row 5  ------> blue socket   = SDA
 blue pin   = IO46 (SCL) ------> row 10 <--[2.2k]--> + rail       row 10 ------> yellow socket = SCL
 red pin    = 3V3        ------> + rail                           + rail ------> red socket    = V+
 black pin  = GND        ------> - rail                           - rail ------> black socket  = GND
```

1. **Board off.** Unplug the controller's USB and POWER.
2. **Identify the socket pins.** Plug the 4209's SH plug into the GPIO socket. Power the
   controller from USB only. Multimeter on DC volts, black probe on the USB-C shell (a
   ground). Touch each free header pin: one reads 3.3 V (expected: red, socket pin 3);
   the two IO pins read close to 0 V (their pull-downs); the GND pin reads 0 V and beeps
   in continuity mode against the USB shell (expected: black). Write the four colours
   down against their function. If red is not the 3.3 V pin, the socket's pin order
   differs from the schematic reading; use what you measured from here on. Power off.
3. **Plant the four pins.** Yellow (IO45) into row 5, blue (IO46) into row 10, red (3V3)
   into the + rail, black (GND) into the - rail. Use the outer holes of the rows so the
   inner holes stay free.
4. **Pull-ups.** One 2.2 k from row 5 to the + rail, one from row 10 to the + rail. Bend
   the leads gently; the 1/2 W leads are stiff. Nothing else on the board yet.
5. **Measure the divider.** Power on. Measure row 5 and row 10 against the - rail.
   Expected about 2.7 V (2.2 k up against 10 k down, plus the chip's weak internal
   pull-down). Two other outcomes are informative: 3.3 V means the pull-downs are not
   fitted (in-shell path 1 applies; the resistors stay, they are harmless), and about
   0 V means the pin is driven low by the firmware or the socket order is not what step
   2 concluded. Power off.
6. **Pins for the 4397.** Push a header pin (or a jumper wire) into row 5, row 10, the +
   rail and the - rail. Slide the 4397's female sockets onto them by function: blue on
   row 5, yellow on row 10, red on the + rail, black on the - rail. Plug the SH end into
   either STEMMA QT socket of the 5880.
7. **Measure again.** Power on. Row 5 and row 10 should now read about 2.8 V (the board's
   10 k pull-ups added in parallel). The board's NeoPixel stays dark; that is normal, it
   lights only on command. Record both numbers in section 5.
8. **The strapping question.** With everything connected, run `.\tools\flash.ps1` from
   `firmware/`. Pass: the encoder can stay connected for good. Fail (the tool cannot
   enter download mode): pull the four 4209 pins out of the breadboard, flash, plug them
   back in, and section 3.4's rule stands.
9. **Baseline.** Note `GET /api/v1/diag/memory` once, before the probe firmware, so the
   memory cost of the encoder task can be compared later.

## 5. Bench record

Fill in when done; the numbers decide the in-shell path and are copied into the READMEs.

| Item | Expected | Measured |
|---|---|---|
| 3V3 pin colour on the 4209 | blue | |
| GND pin colour on the 4209 | black | |
| Row 5 / row 10 with resistors, no board | ~2.7 V | |
| Row 5 / row 10 with the board | ~2.8 V | |
| `flash.ps1` with IO46 pulled high | works | |
| Free internal heap, largest block, before the probe | from `/diag/memory` | |

## 6. Firmware

The firmware side is the same for A and B except for the device count and the roles. It
is done in two stages, each verified on the device before the next starts, in the product
firmware itself (no separate test program: the diagnostics endpoints and smoke tests are
already there).

### 6.1 Stage B: the probe

- **Config:** `P64_ENCODERS` (bool, on), `P64_I2C_EXT_SDA` = 45, `P64_I2C_EXT_SCL` = 46,
  next to the existing I2C options in `main/Kconfig.projbuild`.
- **Bus:** `system::i2c_bus` gains a second bus on the other I2C controller (`I2C_NUM_1`)
  for those pins, created on first use like the first, internal pull-ups enabled (they
  add a weak 45 k in parallel, which helps slightly), internal pull-downs disabled. The
  IMU keeps its own bus, so the 250 Hz IMU polling and the encoder polling never contend.
- **Seesaw driver** (`p64_inputs/src/seesaw.*`): the protocol is a two-byte register
  address (module, register), a STOP, a pause of about 250 µs, then the read. That pause
  is the one thing that trips people using the new I2C driver; it belongs in the driver,
  not the callers. Registers used (from Adafruit's `Adafruit_seesaw.h`):
  - STATUS 0x00 / HW_ID 0x01: Adafruit's header says 0x87 for the ATtiny817; the 5880
    on the bench answered 0x55 (2026-09-26); the probe logs what it reads.
  - STATUS 0x00 / SWRST 0x7F: software reset at start.
  - ENCODER 0x11 / POSITION 0x30 (int32, big-endian) and DELTA 0x40.
  - GPIO 0x01: DIRCLR_BULK 0x03, PULLENSET 0x0B, BULK_SET 0x05 with mask 1 << 24 to make
    the switch (seesaw pin 24) an input with pull-up; BULK 0x04 reads it (0 = pressed).
  - NEOPIXEL 0x0E: PIN 0x01 = 6, BUF_LENGTH 0x03 = 3, BUF 0x04, SHOW 0x05.
- **Poll task** on core 0, 50 Hz, stack in PSRAM
  (`xTaskCreatePinnedToCoreWithCaps`). The seesaw counts detents itself, so no step is lost
  between polls. The task never touches flash: anything that ends in NVS is handed to
  the show loop as an event (rule from `CLAUDE.md`).
- **Visible checks:** at start the NeoPixel of 0x36 goes green for two seconds, then
  off; every detent and press logs one line; `GET /api/v1/diag/encoders` returns
  positions, press states, counters and read errors per address;
  `tests/device/encoders_smoke.py` prints positions live while the knob is turned and
  checks that the expected addresses answer.
- **Acceptance:** 200 detents each way with no miscount, presses register, no read
  errors over ten minutes with the panel busy and Makapix connected, and internal RAM
  after boot within a few hundred bytes of the bench baseline. The sign of the count
  (Adafruit's examples negate it, so clockwise may come out negative) is settled here.

### 6.2 Stage C: the roles

- Turn clockwise = next, counter-clockwise = previous (through history, as the API
  actions do); press = pause / resume. A long press is reported but unassigned.
- Plumbing: the encoder events join `inputs::Hooks` next to the tap gestures; the show
  loop handles them exactly as it handles `/api/v1/action/next`, `previous` and `pause`.
- Settings: `encoders.enabled`, `encoders.invert` (swap the turn direction).
- Docs: `firmware/docs/architecture.md`, `api.md`, `PROGRESS.md`; the wiring and the
  bench numbers into `firmware/reference/hardware-tests/README.md` (board facts) and `enclosure/README.md`.

## 7. In-shell assembly, solderless

### 7.1 The harness

The breadboard's crossing job is done by mating the two cables directly: each male pin of
the 4209 pushes into one female socket of the 4397, paired by function. Wrap each joint
in a turn of tape (or slide 3 mm heat-shrink over the socket before mating and shrink it
with a hair dryer). No tool, no solder.

harness

```
 4209 (controller)            4397 (encoder board)
 yellow pin (IO45 = SDA) --->  blue socket   (SDA)
 blue pin   (IO46 = SCL) --->  yellow socket (SCL)
 red pin    (3V3)        --->  red socket    (V+)
 black pin  (GND)        --->  black socket  (GND)
```

The pull-ups are the remaining question, answered by the bench measurement of section 4,
step 5:

### 7.2 Path 1 and path 2: the 5880 stays

- **Path 1, pull-downs not fitted** (row 5 read 3.3 V): mate the cables as above, plug
  the 4397 into the 5880, done. Nothing else in the shell.
- **Path 2, pull-downs present** (row 5 read about 2.7 V): the resistors need a junction
  box, and the solderless junction box is a tiny breadboard, 46 x 36 x 10 mm (Adafruit
  65 or the same SYB-170 from any supplier), stuck to the inside of the shell's back
  wall with foam tape, with the same layout as section 4 (rows 5 and 10, the two rails,
  two resistors, the 4209 pins and header pins for the 4397). Where it goes: the v7b
  cavity has no free flat 10 mm deep and 46 x 36 mm in size. Measured against the v7
  source (`enclosure/src/p64_enclosure_v7.scad`, echo lines, 2026-09-23; v7 did not
  change the cavity there, v6 gave the same numbers): the controller occupies
  x = -16..26, y = -53..-3 mm (shell coordinates, seen from the back) and stands 7.7 mm behind the frame face; the encoder board takes
  x = 34..60, y = -38..-12 (the right-hand position; the left mirror is free with one
  knob); above the controller the cavity is 12.9 mm deep at y = -3 and drops below 10 mm
  around y = +25. So the breadboard needs a shell revision after v7 with a local pocket
  about 5 mm deeper over roughly x = -25..25, y = 0..40, on the back face above the
  controller. v7 went to the USB-C window and has no such pocket; until a revision has
  one, path 2 runs on the bench only.

### 7.3 Path 3: the Qwiic Twist instead

If the pull-downs are present and a shell pocket is not wanted, the SparkFun Qwiic Twist
(DEV-15083) replaces the 5880: it has 2.2 k pull-ups of its own (SparkFun's hookup
guide), which puts the idle level at 2.70 V, above the 2.475 V threshold with a small
margin. Then the harness is the mated cables alone, with no junction box, but the Twist
board is 25.4 x 30.5 mm with a different hole pattern, so the v7b encoder posts (made for
the 5880) do not fit it: the Twist needs a shell revision with its own posts. The knob fits: the Twist's encoder has a
6 mm shaft and the 5528 knob grips any 6 mm shaft with its set screw. The Twist's RGB LED
sits under the knob and is simply left off. The appendix has its wiring and firmware.

### 7.4 Mounting the knob

1. Firmware first: finish stages B and C on the bench, then power off.
2. First time only, on the fresh v7b print: lay the washer and nut in the spot-face. Their
   outer diameter and the nut across its corners have not been measured
   (`enclosure/input/measurements.md`); an M7 set is about 11 to 12 mm, the seat is 14.
3. Plug the harness's 4397 into the 5880 before mounting: once mounted the STEMMA QT
   sockets face up and down, 4.5 mm from the side wall, and are hard to reach.
4. From inside the shell push the board onto its four pegs with the shaft through the
   7.4 mm hole, until the bushing base sits flat on the inner wall. Use the v7b right-hand
   position seen from the back (19 mm in from the side edge, 41 mm up from the bottom
   edge), nearest the controller's GPIO socket; turn the board with its two sockets up and
   down and the header pads towards the centre (`enc_rot`), the only orientation the shell
   leaves room for. A tight peg (elephant foot) gets a light trim, not force. The
   left-hand position's hole stays open; a second board can go there later
   ([the soldered option](encoders-soldered.md)).
5. From outside fit the washer and the nut on the 5880's bushing, hand-tight, at most
   10 kgf·cm; with the shell on its side, a finger inside holds the board while the nut
   starts. The nut takes the knob's push force; the pegs only stop the board turning.
6. Slide the knob on, black mark up, and tighten the set screw with the 2 mm hex key
   onto the flat of the D-shaft.
7. Route the harness: the GPIO socket is on the controller's right edge at about the
   encoder's height, so the 300 mm of cable is far more than the 20 mm gap; coil the
   slack flat against the back wall, away from the controller's power leads and the two
   USB-C adapters, and keep it off the encoder board's solder side.
8. Connect the harness to the GPIO socket while the panel is still outside the shell,
   then slide the panel in (controller at the bottom) and fit the six M3 x 10 screws, as
   in `enclosure/README.md`, "Assembly". The pin stubs under the board reach 3.0 mm into
   the 4.1 mm left to the panel frame, so the panel seats clear of them.
9. Run `encoders_smoke.py` once more with the shell closed.

To take the board out: panel out, knob off, nut and washer off, then the board lifts off
its pegs. The knob is the deepest point of the shell, 13 mm past its bottom edge: the
display stands as p64a does, but laid on its back it rests on the knob.

## 8. What can go wrong

| Symptom | Likely cause | Check |
|---|---|---|
| Probe logs "no seesaw at 0x36" | SDA/SCL swapped, a socket not seated, or idle level too low | rows read ~2.8 V; swap yellow/blue pins |
| Rows read 1.65 V with the board | a pull-up missing or in the wrong row | resistor legs in row 5 / row 10 and the + rail |
| `flash.ps1` cannot enter download mode | IO46 high at reset | pull the four 4209 pins, flash, replace (section 3.4) |
| Reads work, then errors under load | bus too fast for the cable | stay at 100 kHz |
| Device reboots when a knob is turned | the poll task touched flash (NVS) | events to the show loop only (section 6.1) |
| Count runs backwards | sign convention | `encoders.invert` |

## Appendix: two knobs without soldering (5880 + Qwiic Twist)

The two-encoder project needs soldering only because two 5880s must have different
addresses (jumper A0). A second board with a software-set address avoids it: the SparkFun
Qwiic Twist answers at 0x3F by default (0x3E with its own jumper, not needed), changeable
by register and stored in its EEPROM. The 5880 keeps 0x36. Both boards' pull-ups in
parallel (10 k and 2.2 k) give an idle level of 2.80 V, so no external resistors, no
breadboard, and the harness of section 7.1 is the whole wiring.

twist

```
 controller GPIO ---4209 + 4397 mated---> 5880 (0x36) ---4399 50 mm---> Qwiic Twist (0x3F)
 IO45 = SDA, IO46 = SCL, 3V3, GND         10k pull-ups                  2.2k pull-ups
```

- **Parts:** one Qwiic Twist (DEV-15083, about $25); the 4399 between the boards on the
  bench, and for the shell a 200 mm SH-SH cable (Adafruit 4401), because the two knob
  positions are 94 mm apart and the sockets face up/down.
- **Bench:** section 4 without step 4's resistors, and with the Twist chained on the
  5880's free socket. Expect about 2.8 V on rows 5 and 10.
- **Firmware:** a second small driver (`p64_inputs/src/twist.*`), plain byte registers
  with an auto-incrementing pointer (SparkFun's Arduino library header): ID 0x00
  (expect 0x5C), STATUS 0x01 (bit 0 encoder moved, bit 1 button pressed, bit 2 button
  clicked; write back to clear), COUNT 0x05 (int16), DIFFERENCE 0x07 (int16), RED /
  GREEN / BLUE 0x0D..0x0F (set to 0 to keep the LED dark), CHANGE_ADDRESS 0x18, LIMIT
  0x19. The probe treats both boards alike behind one `Encoder` interface.
- **Roles** as decided on 2026-09-20 for two knobs: the 5880 is knob A (turn =
  brightness, press = pause / resume), the Twist is knob B (turn = next / previous,
  press = Makapix like), with a settings switch to swap them once the shell shows which
  is left.
- **Shell:** a revision after v7 must give the Twist its own posts (25.4 x 30.5 mm board, its hole pattern
  from SparkFun's Eagle files) at the left position; the right position keeps the 5880's.

## Sources

- Waveshare ESP32-S3-RGB-Matrix schematic (GPIO socket U8, R59/R60 10 k):
  https://github.com/waveshareteam/ESP32-S3-RGB-Matrix/tree/main/hardware/schematics
- Adafruit 5880 guide (pinout, 10 k pull-ups, jumpers, switch on seesaw pin 24, NeoPixel
  on pin 6): https://learn.adafruit.com/adafruit-i2c-qt-rotary-encoder/pinouts
- Adafruit seesaw register map: https://github.com/adafruit/Adafruit_Seesaw
- SparkFun Qwiic Twist hookup guide (2.2 k pull-ups, 0x3F, register map):
  https://learn.sparkfun.com/tutorials/qwiic-twist-hookup-guide
- Adafruit 5528 knob (6 mm bore, 2 mm hex set screw): https://www.adafruit.com/product/5528
- ESP32-S3 datasheet, VIH min 0.75 VDD; strapping pins IO45/IO46.
- Shell numbers: `enclosure/src/p64_enclosure_v7.scad` (rendered as
  `src/p64_enclosure_v7b.scad`) and `enclosure/README.md` ("Encoders (p64b only)" and
  "Assembly").

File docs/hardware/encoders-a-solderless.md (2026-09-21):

# Option A: one rotary encoder, no soldering

Written 2026-09-21, before anything was built. This is the complete project for one
Adafruit 5880 encoder on the p64, from the parts on the table to a working knob inside
the shell, without a soldering iron. Its sibling, [Option B](encoders-b-soldered.md), is
the two-encoder project with soldering. Both share the same electrical facts, the same
bench test and the same firmware plan; they differ in the number of boards, in how the
second address is set and in how the harness is made permanent.

Figures are generated by `tools/draw_encoders.py` (schemdraw) into `img/`; an ASCII
version follows each figure so the text stands on its own.

## 1. The short answer

Yes, with one encoder the project is solderless, in two steps:

- **On the bench** it is solderless without any caveat: the pull-up resistors and the
  pin-order crossing live on the ELEGOO breadboard. Sections 3 to 6.
- **Inside the shell** it stays solderless if one of three things holds, and the first
  bench measurement (section 4, step 4) tells which apply:
  1. the controller's IO45/IO46 pull-downs turn out not to be fitted: then no resistors
     are needed and the harness is just the two cables mated pin-to-socket;
  2. the resistors are needed, and a tiny breadboard (46 x 36 x 10 mm) rides inside the
     shell: this needs a shell revision (v7) with a pocket for it, because v6 has no free
     10 mm-deep flat of that size (section 7.2);
  3. the resistors are needed, and the Adafruit 5880 is swapped for a SparkFun Qwiic
     Twist, which carries its own 2.2 k pull-ups: no resistors, no breadboard, no solder,
     but a different board than the one on the table (section 7.3 and the appendix).

The soldering that the two-encoder project needs is only the address jumper on the
second board. With one board there is nothing to bridge.

Roles decided on 2026-09-21: turn = next / previous artwork, press = pause / resume.
Brightness stays on the web UI and on Makapix.

## 2. Parts

On hand (2026-09-21):

| Part | Used for |
|---|---|
| Adafruit 5880, I2C QT Rotary Encoder with encoder soldered (seesaw, address 0x36) | the knob |
| Adafruit 5528, 20 mm aluminium knob, 6 mm bore, set screw | the knob cap |
| Adafruit 4209, JST-SH 4-pin to premium male headers, 150 mm | controller socket to breadboard |
| Adafruit 4397, JST-SH 4-pin to premium female sockets, 150 mm | breadboard to encoder board |
| Adafruit 4399, JST-SH to JST-SH, 50 mm | not needed with one board (Option B uses it) |
| 2.2 kΩ resistors, 1/2 W, 5 % (40) | two pull-ups; the wattage is irrelevant here, 1/4 W would be neater |
| ELEGOO 400-point breadboards (3) | the bench junction |
| Multimeter | pin identification and the idle-level measurement |
| Jumper wires or 0.1-inch header pins | the 4397's female sockets need a pin to grip; the 5880 bag includes a short header strip |

Still needed:

| Part | For | Note |
|---|---|---|
| 2 mm hex key | the knob's set screw | not included with the knob (Adafruit) |
| Tiny breadboard, 46 x 36 x 10 mm (e.g. Adafruit 65) | in-shell path 2 only | plus double-sided foam tape |
| SparkFun Qwiic Twist (DEV-15083) | in-shell path 3 / appendix only | about $25 |
| Electrical tape or 3 mm heat-shrink | wrapping the pin-to-socket joints inside the shell | tape is fine |

## 3. The facts behind the wiring

### 3.1 The only spare connector

The ESP32-S3-RGB-Matrix brings out one spare connector: the 4-pin JST-SH 1.0 mm socket
labelled GPIO (U8 on Waveshare's schematic). Its pins, per the schematic:

| Socket pin | Signal | Our use |
|---|---|---|
| 1 | IO45 | SDA of the second I2C bus |
| 2 | IO46 | SCL of the second I2C bus |
| 3 | 3V3 | V+ of the encoder board |
| 4 | GND | GND |

The controller's internal I2C bus (IO47/IO48, with the IMU, RTC and SHTC3) is not on any
connector, so the encoder gets a bus of its own. Verify the pin order with the
multimeter before plugging anything else in (section 4, step 2).

### 3.2 STEMMA QT pin order is different

STEMMA QT / Qwiic cables are wired GND, V+, SDA, SCL (black, red, blue, yellow). The
Waveshare socket is signal, signal, 3V3, GND. A plain SH-to-SH cable between the two
would put 3.3 V on the encoder's SDA pin and ground on its V+ pin. That is why the
harness is made of the 4209 (SH plug to male pins) and the 4397 (SH plug to female
sockets), joined by function. On the 4209, plugged into the controller, the colours lie:

| 4209 wire | Lands on socket pin | Is actually |
|---|---|---|
| black | 1 | IO45 = SDA |
| red | 2 | IO46 = SCL |
| blue | 3 | 3V3 |
| yellow | 4 | GND |

Only on the 4397 (plugged into the encoder board) do the colours mean what they say.

The whole bus, as a schematic:

bus

```
 controller GPIO socket           your 2.2k pull-ups          Adafruit 5880 (0x36)
 IO45 (R59 10k to GND) ---SDA---+----[2.2k]---3V3------------ SDA   (10k pull-up on board)
 IO46 (R60 10k to GND) ---SCL---+----[2.2k]---3V3------------ SCL   (10k pull-up on board)
 3V3 -------------------------------------------------------- V+
 GND -------------------------------------------------------- GND
```

### 3.3 The pull-downs, and why two resistors are needed

Per the schematic, IO45 and IO46 each carry a 10 k pull-down to ground on the controller
(R59, R60). The 5880 carries 10 k pull-ups to V+ on SDA and SCL. Together they form a
voltage divider: the idle level of each line is 3.3 V x 10k / (10k + R_up), where R_up
is every pull-up in parallel.

idle level

```
        3V3
         |
       [R_up]   all pull-ups in parallel
         |
         +------ V_idle = 3.3 V x 10k / (10k + R_up)
         |
       [10k]    R59 (SDA) or R60 (SCL), on the controller
         |
        GND
```

The ESP32-S3 reads a HIGH only above 0.75 x 3.3 V = 2.475 V (datasheet VIH). Cases:

| Configuration | R_up | V_idle | Result |
|---|---|---|---|
| one 5880, nothing else | 10 k | 1.65 V | fails: the bus never reads idle |
| one 5880 + 2.2 k on each line | 1.80 k | 2.80 V | ok |
| two 5880 + 2.2 k (Option B) | 1.53 k | 2.86 V | ok |
| Qwiic Twist alone (its own 2.2 k) | 2.2 k | 2.70 V | ok, small margin |
| 5880 + Qwiic Twist (appendix) | 1.80 k | 2.80 V | ok |
| pull-downs not fitted | any | 3.3 V | ok, no resistors needed |

The low level is unaffected: the seesaw pulls the line to ground through 1.5 to 1.8 k,
about 2 mA, well within what I2C allows. Nothing here is delicate; a 1.5 k or 3.3 k
resistor would also work. 2.2 k is what is on the table.

### 3.4 Strapping pins

IO45 and IO46 are ESP32-S3 strapping pins. IO45 selects the flash voltage at reset,
which the N32R16V module fixes by eFuse, so a pull-up on IO45 is harmless. IO46 high at
reset makes the ROM's manual download mode an invalid combination. Whether the USB
Serial/JTAG reset that the flash script uses still enters download mode with IO46 pulled
high is unknown and is settled on the bench (section 4, step 8). If it does not, the
rule is: pull the 4209's four header pins out of the breadboard (or the joints, in the
shell) before flashing, never the SH plug (SH connectors are rated for few mating
cycles).

### 3.5 Bus speed and cable length

150 + 150 mm of cable at 100 kHz is comfortable. The firmware starts at 100 kHz and tries
400 kHz only after everything else is verified.

## 4. Bench build

One ELEGOO breadboard. Rows are numbered along the long side, five tie points per row
per half; the two long strips on each edge are the + and - rails. Nothing is powered
until step 5.

bench map

```
 Adafruit 4209 (controller)      breadboard             Adafruit 4397 (encoder board)
 black pin  = IO45 (SDA) ------> row 5  <--[2.2k]--> + rail       row 5  ------> blue socket   = SDA
 red pin    = IO46 (SCL) ------> row 10 <--[2.2k]--> + rail       row 10 ------> yellow socket = SCL
 blue pin   = 3V3        ------> + rail                           + rail ------> red socket    = V+
 yellow pin = GND        ------> - rail                           - rail ------> black socket  = GND
```

1. **Board off.** Unplug the controller's USB and POWER.
2. **Identify the socket pins.** Plug the 4209's SH plug into the GPIO socket. Power the
   controller from USB only. Multimeter on DC volts, black probe on the USB-C shell (a
   ground). Touch each free header pin: one reads 3.3 V (expected: blue, socket pin 3);
   the two IO pins read close to 0 V (their pull-downs); the GND pin reads 0 V and beeps
   in continuity mode against the USB shell (expected: yellow). Write the four colours
   down against their function. If blue is not the 3.3 V pin, the socket's pin order
   differs from the schematic reading; use what you measured from here on. Power off.
3. **Plant the four pins.** Black (IO45) into row 5, red (IO46) into row 10, blue (3V3)
   into the + rail, yellow (GND) into the - rail. Use the outer holes of the rows so the
   inner holes stay free.
4. **Pull-ups.** One 2.2 k from row 5 to the + rail, one from row 10 to the + rail. Bend
   the leads gently; the 1/2 W leads are stiff. Nothing else on the board yet.
5. **Measure the divider.** Power on. Measure row 5 and row 10 against the - rail.
   Expected about 2.7 V (2.2 k up against 10 k down, plus the chip's weak internal
   pull-down). Two other outcomes are informative: 3.3 V means the pull-downs are not
   fitted (in-shell path 1 applies; the resistors stay, they are harmless), and about
   0 V means the pin is driven low by the firmware or the socket order is not what step
   2 concluded. Power off.
6. **Pins for the 4397.** Push a header pin (or a jumper wire) into row 5, row 10, the +
   rail and the - rail. Slide the 4397's female sockets onto them by function: blue on
   row 5, yellow on row 10, red on the + rail, black on the - rail. Plug the SH end into
   either STEMMA QT socket of the 5880.
7. **Measure again.** Power on. Row 5 and row 10 should now read about 2.8 V (the board's
   10 k pull-ups added in parallel). The board's NeoPixel stays dark; that is normal, it
   lights only on command. Record both numbers in section 5.
8. **The strapping question.** With everything connected, run `.\tools\flash.ps1` from
   `firmware/`. Pass: the encoder can stay connected for good. Fail (the tool cannot
   enter download mode): pull the four 4209 pins out of the breadboard, flash, plug them
   back in, and section 3.4's rule stands.
9. **Baseline.** Note `GET /api/v1/diag/memory` once, before the probe firmware, so the
   memory cost of the encoder task can be compared later.

## 5. Bench record

Fill in when done; the numbers decide the in-shell path and are copied into the READMEs.

| Item | Expected | Measured |
|---|---|---|
| 3V3 pin colour on the 4209 | blue | |
| GND pin colour on the 4209 | yellow | |
| Row 5 / row 10 with resistors, no board | ~2.7 V | |
| Row 5 / row 10 with the board | ~2.8 V | |
| `flash.ps1` with IO46 pulled high | works | |
| Free internal heap, largest block, before the probe | from `/diag/memory` | |

## 6. Firmware

The firmware side is the same for A and B except for the device count and the roles. It
is done in two stages, each verified on the device before the next starts, in the product
firmware itself (no separate test program: the diagnostics endpoints and smoke tests are
already there).

### 6.1 Stage B: the probe

- **Config:** `P64_ENCODERS` (bool, on), `P64_I2C_EXT_SDA` = 45, `P64_I2C_EXT_SCL` = 46,
  next to the existing I2C options in `main/Kconfig.projbuild`.
- **Bus:** `system::i2c_bus` gains a second bus on the other I2C controller (`I2C_NUM_1`)
  for those pins, created on first use like the first, internal pull-ups enabled (they
  add a weak 45 k in parallel, which helps slightly), internal pull-downs disabled. The
  IMU keeps its own bus, so the 250 Hz IMU polling and the encoder polling never contend.
- **Seesaw driver** (`p64_inputs/src/seesaw.*`): the protocol is a two-byte register
  address (module, register), a STOP, a pause of about 250 µs, then the read. That pause
  is the one thing that trips people using the new I2C driver; it belongs in the driver,
  not the callers. Registers used (from Adafruit's `Adafruit_seesaw.h`):
  - STATUS 0x00 / HW_ID 0x01: expect 0x87 (ATtiny817); the probe logs what it reads.
  - STATUS 0x00 / SWRST 0x7F: software reset at start.
  - ENCODER 0x11 / POSITION 0x30 (int32, big-endian) and DELTA 0x40.
  - GPIO 0x01: DIRCLR_BULK 0x03, PULLENSET 0x0B, BULK_SET 0x05 with mask 1 << 24 to make
    the switch (seesaw pin 24) an input with pull-up; BULK 0x04 reads it (0 = pressed).
  - NEOPIXEL 0x0E: PIN 0x01 = 6, BUF_LENGTH 0x03 = 3, BUF 0x04, SHOW 0x05.
- **Poll task** on core 0, 50 Hz, stack in PSRAM
  (`xTaskCreatePinnedToCoreWithCaps`). The seesaw counts detents itself, so no step is lost
  between polls. The task never touches flash: anything that ends in NVS is handed to
  the show loop as an event (rule from `CLAUDE.md`).
- **Visible checks:** at start the NeoPixel of 0x36 goes green for two seconds, then
  off; every detent and press logs one line; `GET /api/v1/diag/encoders` returns
  positions, press states, counters and read errors per address;
  `tests/device/encoders_smoke.py` prints positions live while the knob is turned and
  checks that the expected addresses answer.
- **Acceptance:** 200 detents each way with no miscount, presses register, no read
  errors over ten minutes with the panel busy and Makapix connected, and internal RAM
  after boot within a few hundred bytes of the bench baseline. The sign of the count
  (Adafruit's examples negate it, so clockwise may come out negative) is settled here.

### 6.2 Stage C: the roles

- Turn clockwise = next, counter-clockwise = previous (through history, as the API
  actions do); press = pause / resume. A long press is reported but unassigned.
- Plumbing: the encoder events join `inputs::Hooks` next to the tap gestures; the show
  loop handles them exactly as it handles `/api/v1/action/next`, `previous` and `pause`.
- Settings: `encoders.enabled`, `encoders.invert` (swap the turn direction).
- Docs: `firmware/docs/architecture.md`, `api.md`, `PROGRESS.md`; the wiring and the
  bench numbers into `hardware-tests/README.md` (board facts) and `enclosure/README.md`.

## 7. In-shell assembly, solderless

### 7.1 The harness

The breadboard's crossing job is done by mating the two cables directly: each male pin of
the 4209 pushes into one female socket of the 4397, paired by function. Wrap each joint
in a turn of tape (or slide 3 mm heat-shrink over the socket before mating and shrink it
with a hair dryer). No tool, no solder.

harness

```
 4209 (controller)            4397 (encoder board)
 black pin  (IO45 = SDA) --->  blue socket   (SDA)
 red pin    (IO46 = SCL) --->  yellow socket (SCL)
 blue pin   (3V3)        --->  red socket    (V+)
 yellow pin (GND)        --->  black socket  (GND)
```

The pull-ups are the remaining question, answered by the bench measurement of section 4,
step 5:

### 7.2 Path 1 and path 2: the 5880 stays

- **Path 1, pull-downs not fitted** (row 5 read 3.3 V): mate the cables as above, plug
  the 4397 into the 5880, done. Nothing else in the shell.
- **Path 2, pull-downs present** (row 5 read about 2.7 V): the resistors need a junction
  box, and the solderless junction box is a tiny breadboard, 46 x 36 x 10 mm (Adafruit
  65 or the same SYB-170 from any supplier), stuck to the inside of the shell's back
  wall with foam tape, with the same layout as section 4 (rows 5 and 10, the two rails,
  two resistors, the 4209 pins and header pins for the 4397). Where it goes: the v6
  cavity has no free flat 10 mm deep and 46 x 36 mm in size. Measured against the v6
  source: the controller occupies x = -16..26, y = -53..-3 mm (shell coordinates, seen
  from the back) and stands 7.7 mm behind the frame face; the encoder board takes
  x = 34..60, y = -38..-12 (the right-hand position; the left mirror is free with one
  knob); above the controller the cavity is 12.9 mm deep at y = -3 and drops below 10 mm
  around y = +25. So the breadboard needs a v7 shell with a local pocket about 5 mm
  deeper over roughly x = -25..25, y = 0..40, on the back face above the controller. That
  revision also drops the unused second encoder hole. Until v7 exists, path 2 runs on the
  bench only.

### 7.3 Path 3: the Qwiic Twist instead

If the pull-downs are present and a shell pocket is not wanted, the SparkFun Qwiic Twist
(DEV-15083) replaces the 5880: it has 2.2 k pull-ups of its own (SparkFun's hookup
guide), which puts the idle level at 2.70 V, above the 2.475 V threshold with a small
margin. Then the harness is the mated cables alone, in the v6 shell as it is, except that
the Twist board is 25.4 x 30.5 mm with a different hole pattern, so the encoder posts of
v6 (made for the 5880) need redoing in v7 anyway. The knob fits: the Twist's encoder has a
6 mm shaft and the 5528 knob grips any 6 mm shaft with its set screw. The Twist's RGB LED
sits under the knob and is simply left off. The appendix has its wiring and firmware.

### 7.4 Mounting the knob

1. Firmware first: finish stages B and C on the bench, then power off.
2. From inside the shell push the board onto its four pegs with the shaft through the
   7.4 mm hole (the v6 right-hand position; the board is turned so its two STEMMA QT
   sockets face up and down, `enc_rot`).
3. From outside fit the washer and the nut on the 5880's bushing, hand-tight, at most
   10 kgf·cm. The nut takes the knob's push force; the pegs only stop the board turning.
4. Slide the knob on, black mark up, and tighten the set screw with the 2 mm hex key
   onto the flat of the D-shaft.
5. Route the harness: the GPIO socket is on the controller's right edge at about the
   encoder's height, so the 300 mm of cable is far more than the 20 mm gap; coil the
   slack flat against the back wall, away from the panel's ribbon and the USB adapters,
   and keep it off the encoder board's solder side.
6. Connect the chain before sliding the panel in, then run `encoders_smoke.py` once
   more with the shell closed.

## 8. What can go wrong

| Symptom | Likely cause | Check |
|---|---|---|
| Probe logs "no seesaw at 0x36" | SDA/SCL swapped, a socket not seated, or idle level too low | rows read ~2.8 V; swap black/red pins |
| Rows read 1.65 V with the board | a pull-up missing or in the wrong row | resistor legs in row 5 / row 10 and the + rail |
| `flash.ps1` cannot enter download mode | IO46 high at reset | pull the four 4209 pins, flash, replace (section 3.4) |
| Reads work, then errors under load | bus too fast for the cable | stay at 100 kHz |
| Device reboots when a knob is turned | the poll task touched flash (NVS) | events to the show loop only (section 6.1) |
| Count runs backwards | sign convention | `encoders.invert` |

## Appendix: two knobs without soldering (5880 + Qwiic Twist)

The two-encoder project needs soldering only because two 5880s must have different
addresses (jumper A0). A second board with a software-set address avoids it: the SparkFun
Qwiic Twist answers at 0x3F by default (0x3E with its own jumper, not needed), changeable
by register and stored in its EEPROM. The 5880 keeps 0x36. Both boards' pull-ups in
parallel (10 k and 2.2 k) give an idle level of 2.80 V, so no external resistors, no
breadboard, and the harness of section 7.1 is the whole wiring.

twist

```
 controller GPIO ---4209 + 4397 mated---> 5880 (0x36) ---4399 50 mm---> Qwiic Twist (0x3F)
 IO45 = SDA, IO46 = SCL, 3V3, GND         10k pull-ups                  2.2k pull-ups
```

- **Parts:** one Qwiic Twist (DEV-15083, about $25); the 4399 between the boards on the
  bench, and for the shell a 200 mm SH-SH cable (Adafruit 4401), because the two knob
  positions are 94 mm apart and the sockets face up/down.
- **Bench:** section 4 without step 4's resistors, and with the Twist chained on the
  5880's free socket. Expect about 2.8 V on rows 5 and 10.
- **Firmware:** a second small driver (`p64_inputs/src/twist.*`), plain byte registers
  with an auto-incrementing pointer (SparkFun's Arduino library header): ID 0x00
  (expect 0x5C), STATUS 0x01 (bit 0 encoder moved, bit 1 button pressed, bit 2 button
  clicked; write back to clear), COUNT 0x05 (int16), DIFFERENCE 0x07 (int16), RED /
  GREEN / BLUE 0x0D..0x0F (set to 0 to keep the LED dark), CHANGE_ADDRESS 0x18, LIMIT
  0x19. The probe treats both boards alike behind one `Encoder` interface.
- **Roles** as decided on 2026-09-20 for two knobs: the 5880 is knob A (turn =
  brightness, press = pause / resume), the Twist is knob B (turn = next / previous,
  press = Makapix like), with a settings switch to swap them once the shell shows which
  is left.
- **Shell:** v7 must give the Twist its own posts (25.4 x 30.5 mm board, its hole pattern
  from SparkFun's Eagle files) at the left position; the right position keeps the 5880's.

## Sources

- Waveshare ESP32-S3-RGB-Matrix schematic (GPIO socket U8, R59/R60 10 k):
  https://github.com/waveshareteam/ESP32-S3-RGB-Matrix/tree/main/hardware/schematics
- Adafruit 5880 guide (pinout, 10 k pull-ups, jumpers, switch on seesaw pin 24, NeoPixel
  on pin 6): https://learn.adafruit.com/adafruit-i2c-qt-rotary-encoder/pinouts
- Adafruit seesaw register map: https://github.com/adafruit/Adafruit_Seesaw
- SparkFun Qwiic Twist hookup guide (2.2 k pull-ups, 0x3F, register map):
  https://learn.sparkfun.com/tutorials/qwiic-twist-hookup-guide
- Adafruit 5528 knob (6 mm bore, 2 mm hex set screw): https://www.adafruit.com/product/5528
- ESP32-S3 datasheet, VIH min 0.75 VDD; strapping pins IO45/IO46.
- Shell numbers: `enclosure/src/p64_enclosure_v6.scad` and `enclosure/README.md`.

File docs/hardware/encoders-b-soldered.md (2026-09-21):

# Option B: two rotary encoders, with soldering

Written 2026-09-21, before anything was built. This is the complete project for the two
Adafruit 5880 encoders on the p64, from the parts on the table to two working knobs
inside the v6 shell. Its sibling, [Option A](encoders-a-solderless.md), is the one-encoder
project without soldering; the electrical facts (section 3 there) are the same and are
only summarised here.

Two tiers, both documented:

- **Tier 1, one solder bridge.** The only soldering that two 5880s strictly need is the
  address jumper A0 on the second board. Everything else stays on the breadboard, so the
  project can be built and the firmware finished before any further soldering.
- **Tier 2, the permanent harness.** The two pull-up resistors soldered onto board 1 and
  the two cables either mated pin-to-socket or spliced, so nothing but boards and cables
  goes into the shell.

Figures are generated by `tools/draw_encoders.py` (schemdraw) into `img/`; an ASCII
version follows each figure.

Roles decided on 2026-09-20: knob A (address 0x36) turn = brightness, press = pause /
resume; knob B (0x37) turn = next / previous, press = Makapix like; a long press is
unassigned; a settings switch swaps A and B once the shell shows which knob is left.

## 1. Parts

On hand (2026-09-21): the two 5880 boards, the two 5528 knobs, the 4209 and 4397 cables
(150 mm), the 4399 cable (50 mm), the 2.2 k resistors, the ELEGOO breadboards, a
multimeter, a soldering iron with solder, jumper wires or header pins (the 5880 bags
include a short header strip each).

Still needed:

| Part | For | Note |
|---|---|---|
| 2 mm hex key | the knobs' set screws | not included with the knobs |
| SH-SH cable, 200 mm (Adafruit 4401) | board to board inside the shell | the two knob positions are 94 mm apart and the sockets face up/down; the 50 mm 4399 is for the bench only |
| Electrical tape or 3 mm heat-shrink | wrapping the cable joints | tape is fine |
| Tier 2 only: 1/4 W 2.2 k resistors (optional) | neater on the board than 1/2 W | the 1/2 W parts work, they are just bulky |
| Tier 2 splice only: wire cutters/strippers, 2 mm heat-shrink, a lighter or heat gun | joining the cables | only if the pin-to-socket joints are not wanted |
| Soldering consumables | flux (a pen), a damp sponge or brass wool, isopropyl alcohol | flux makes the jumper bridge easy |

## 2. Electrical summary

Full reasoning and numbers in Option A, section 3. In one table:

| Fact | Consequence |
|---|---|
| The controller's only spare connector is the 4-pin JST-SH "GPIO" socket: pin 1 IO45, 2 IO46, 3 3V3, 4 GND (schematic) | second I2C bus, IO45 = SDA, IO46 = SCL |
| STEMMA QT order is GND, V+, SDA, SCL; the socket's is signal, signal, 3V3, GND | never a straight SH-SH cable to the controller; 4209 + 4397 joined by function |
| IO45/IO46 carry 10 k pull-downs (R59/R60); each 5880 has 10 k pull-ups | two boards alone idle at 2.20 V, below the 2.475 V threshold; with one 2.2 k per line: 2.86 V |
| IO46 high at reset breaks the manual download mode | whether USB flashing still works is tested on the bench; if not, unplug the header pins to flash |
| Two seesaw boards need different addresses | board 2 gets jumper A0 bridged: 0x37 |

bus

```
 controller GPIO socket           your 2.2k pull-ups        board 1 (0x36)      board 2 (0x37, A0 bridged)
 IO45 (R59 10k to GND) ---SDA---+----[2.2k]---3V3----------- SDA ---- SDA ---4399--- SDA
 IO46 (R60 10k to GND) ---SCL---+----[2.2k]---3V3----------- SCL ---- SCL ---4399--- SCL
 3V3 -------------------------------------------------------- V+  ---- V+  ---4399--- V+
 GND -------------------------------------------------------- GND ---- GND ---4399--- GND
```

## 3. Soldering, tier 1: the A0 bridge on board 2

This is the smallest soldering job there is: joining two pads that are 0.3 mm apart with
one blob of solder. Do it before the bench build, on the board that will be knob B.

### 3.1 Setup

- Iron at 320 to 350 °C (leaded 63/37 solder) or 350 to 380 °C (lead-free). A fine
  conical or small chisel tip. Ventilate; do not breathe the smoke; wash hands after
  leaded solder.
- Tin the tip: melt a little solder onto it, wipe on the damp sponge or brass wool; the
  tip should be shiny.
- Board on the bench, back side up, held down with a bit of tape or in a helping-hands
  clip. Find the three jumpers labelled A0, A1, A2 (Adafruit's pinout page); each is a
  pair of small pads with a narrow gap. Only A0 is touched.

### 3.2 The bridge

1. Dab flux on the A0 pads (optional but makes step 3 a one-touch job).
2. Put a small bead of solder on the tip.
3. Touch the tip flat across both pads for one to two seconds. The solder flows onto
   both pads and fills the gap. Lift the iron straight up.
4. Look at it under good light: a smooth, shiny bridge spanning both pads, not a ball
   sitting on one pad, and nothing touching the neighbouring A1 pads or any trace.
5. If it bridged only one pad, add flux and touch again. If it bridged A0 and A1
   together, drag the iron tip across the excess to pull it away, or add flux and wipe
   the tip along the gap; the surplus follows the tip.
6. Clean the flux with isopropyl alcohol on a cotton swab.

### 3.3 Checks

- Multimeter in continuity mode across the two A0 pads: beep.
- Continuity between the A0 pads and the neighbouring A1 pads: no beep.
- The real test is the probe firmware (section 6): the board must answer at 0x37, and
  the NeoPixel colour tells which board is which.
- Mark the board (a dot of paint or tape on the edge) as "B / 0x37".

## 4. Bench build

Same as Option A, section 4, with the second board chained. Nothing is powered until
step 5.

bench map

```
 Adafruit 4209 (controller)      breadboard             Adafruit 4397 (board 1)         4399 (board 1 to board 2)
 black pin  = IO45 (SDA) ------> row 5  <--[2.2k]--> + rail   row 5  ------> blue socket   = SDA   board 1 0x36 --50 mm--> board 2 0x37
 red pin    = IO46 (SCL) ------> row 10 <--[2.2k]--> + rail   row 10 ------> yellow socket = SCL
 blue pin   = 3V3        ------> + rail                       + rail ------> red socket    = V+
 yellow pin = GND        ------> - rail                       - rail ------> black socket  = GND
```

1. Board off (USB and POWER unplugged).
2. Identify the socket pins with the 4209 plugged in and the controller on USB: the pin
   at 3.3 V (expected blue), the pin with continuity to the USB-C shell (expected
   yellow), the two IO pins near 0 V (black = IO45, red = IO46). Record the colours.
   Power off.
3. Plant the four pins: black in row 5, red in row 10, blue in the + rail, yellow in the
   - rail.
4. One 2.2 k from row 5 to the + rail, one from row 10 to the + rail.
5. Power on, measure rows 5 and 10 against the - rail: about 2.7 V expected (3.3 V would
   mean the pull-downs are not fitted; the resistors stay either way). Power off.
6. Header pins into rows 5 and 10 and the two rails; the 4397's sockets onto them by
   function (blue row 5, yellow row 10, red +, black -); its SH plug into board 1 (the
   unmodified 0x36 board).
7. The 4399 from board 1's free socket to board 2 (A0 bridged).
8. Power on, measure again: about 2.86 V (two boards' pull-ups in parallel with the
   2.2 k). Record.
9. `.\tools\flash.ps1` from `firmware/` with everything connected: the IO46 question.
   Pass: the chain stays connected for good. Fail: pull the four 4209 pins to flash.
10. Note `GET /api/v1/diag/memory` once as the baseline.

Bench record:

| Item | Expected | Measured |
|---|---|---|
| 3V3 / GND pin colours on the 4209 | blue / yellow | |
| Rows 5 and 10, resistors only | ~2.7 V | |
| Rows 5 and 10, both boards | ~2.86 V | |
| A0 continuity on board 2 | beep | |
| `flash.ps1` with IO46 pulled high | works | |
| Free internal heap, largest block, before the probe | from `/diag/memory` | |

## 5. Firmware

Identical to Option A, section 6, with two devices. Only the differences:

- **Probe (stage B):** the driver opens both addresses; at start the NeoPixel of 0x36 goes
  green and that of 0x37 blue for two seconds, so the boards identify themselves;
  `GET /api/v1/diag/encoders` and `tests/device/encoders_smoke.py` report both. A board
  that does not answer is logged once and polled again every 5 s (a loose cable must not
  take the other knob down).
- **Roles (stage C):** knob A = 0x36: turn = brightness in the spec's curve steps (through
  the settings path, which wraps NVS on an internal stack; the poll task itself never
  touches flash), press = pause / resume. Knob B = 0x37: turn = next / previous, press =
  like the current Makapix artwork (no-op on card artworks; the like call blocks up to
  20 s, so it is queued to the Makapix task, never run from the show loop). Settings:
  `encoders.enabled`, `encoders.swap` (A and B exchange roles), `encoders.invert`.
- **Acceptance:** as in A, on both knobs, plus: turning both at once loses no detents;
  unplugging the 4399 while running logs the loss and does not disturb knob A.

## 6. Soldering, tier 2: the permanent harness

Do this after the firmware is accepted on the bench: the breadboard is then the last
thing between the bench and the shell.

### 6.1 The pull-ups on board 1

The 5880 has a row of plated header pads along one edge: VIN, 3Vo, GND, SCL, SDA, INT
(names from Adafruit's pinout page; the silkscreen shows the order). The pull-ups must
go to VIN, which is the 3.3 V the controller supplies and the level the board's own
pull-ups use.

1. Bend each resistor's leads down so it can stand on the board's back (the side
   without the encoder), one lead in the VIN hole, the other in the SDA hole for the
   first resistor and in the SCL hole for the second. Two leads share the VIN hole:
   push one through from each side, or twist the two lead ends together first. With the
   1/2 W bodies this is bulky; 1/4 W resistors lie flat between the holes.
2. Solder each lead in its hole from the component-free side: touch pad and lead with
   the tip, feed solder for one second, lift. A good joint is a shiny cone wetting both
   the pad and the lead.
3. Cut the leads flush with side cutters.
4. Check: continuity between the SDA pad and VIN reads about 2.2 k on the ohms range
   (the 10 k on the board in parallel shows about 1.8 k); the same for SCL. No
   continuity between SDA and SCL, or between VIN and GND.

Board 2 gets no resistors: one pair per bus.

### 6.2 The cables

Two acceptable ways; the first needs no soldering at all and is what the author
recommends for a first project.

**Mated (no solder).** Each male pin of the 4209 pushes into one female socket of the
4397, paired by function, each joint wrapped in tape or heat-shrink:

harness

```
 4209 (controller)            4397 (board 1)
 black pin  (IO45 = SDA) --->  blue socket   (SDA)
 red pin    (IO46 = SCL) --->  yellow socket (SCL)
 blue pin   (3V3)        --->  red socket    (V+)
 yellow pin (GND)        --->  black socket  (GND)
```

**Spliced (solder).** Cut the header end off the 4209 and the socket end off the 4397,
leaving the lengths the shell needs (about 60 mm each is plenty: the GPIO socket is
20 mm from the right-hand board). Strip 5 mm of each wire, slide a 20 mm piece of 2 mm
heat-shrink onto one side, twist the pairs by function (black-4209 to blue-4397,
red to yellow, blue to red, yellow to black), tin each twist with the iron, slide the
heat-shrink over it and shrink. Then a larger piece over all four. Do one pair at a
time; the colours cross, so label the 4209 side first.

### 6.3 Between the boards

The 200 mm 4401 (or a 100 mm 4210, tight) from board 1's free socket to board 2. The
sockets face up and down in the shell, so the cable runs down from the right board, along
the bottom of the cavity above the USB adapters' ribbons, and up into the left board.

## 7. In-shell assembly

The v6 shell already has both encoder positions, from v2: shafts at (±47, -25) mm on the
back face, four locating pegs per board, a 7.4 mm hole with a spot-face for the washer
and nut, boards turned so the STEMMA QT sockets face up and down (`enclosure/README.md`,
v2 section, and `enclosure/src/p64_enclosure_v6.scad`).

1. Firmware accepted on the bench, tier 2 done, power off.
2. Plug the 4397 (or the spliced harness) into board 1 and the 4401 between the boards
   before mounting; the sockets are hard to reach afterwards.
3. Board 1 (0x36, with the resistors) goes to the right-hand position (seen from the
   back), nearest the controller's GPIO socket; board 2 to the left. If the shell shows
   the roles should be the other way round, `encoders.swap` fixes it without rewiring.
4. From inside, push each board onto its pegs with the shaft through the wall; from
   outside, washer and nut on the bushing, hand-tight, at most 10 kgf·cm.
5. Knobs on, black mark up, set screw onto the flat of the D-shaft with the 2 mm hex
   key.
6. Route the harness from the controller's GPIO socket (on the controller's right edge
   at about the encoders' height) to board 1; coil the slack flat against the back wall,
   away from the panel ribbon and the USB adapters; the board-to-board cable along the
   bottom.
7. Connect the chain before sliding the panel in; close the shell; run
   `encoders_smoke.py` again with the shell closed, both knobs.

## 8. What can go wrong

| Symptom | Likely cause | Check |
|---|---|---|
| Both boards answer at 0x36 (probe says "0x37 missing") | A0 bridge not conducting | continuity across the A0 pads |
| A board answers at 0x38 or 0x3A | the wrong jumper was bridged (A1 = 0x38, A2 = 0x3A) | fine, the firmware can take the address as a setting; or fix the bridge |
| Rows read 2.2 V with both boards | a pull-up missing or in the wrong row | resistor legs in rows 5 / 10 and the + rail |
| Knob B works, knob A does not, or vice versa | the 4399 / 4401 not seated | reseat; the probe re-polls a missing board every 5 s |
| `flash.ps1` cannot enter download mode | IO46 high at reset | pull the four 4209 pins (or open the joints), flash, replace |
| Solder bridge across A0 and A1 | too much solder | flux and drag the tip to pull the excess |
| Device reboots when a knob is turned | the poll task touched flash (NVS) | brightness through the settings path from the show loop only |
| Count runs backwards | sign convention | `encoders.invert` |

## Sources

- Waveshare ESP32-S3-RGB-Matrix schematic (GPIO socket U8, R59/R60 10 k):
  https://github.com/waveshareteam/ESP32-S3-RGB-Matrix/tree/main/hardware/schematics
- Adafruit 5880 guide (pinout, 10 k pull-ups, jumpers A0/A1/A2 = 0x37/0x38/0x3A):
  https://learn.adafruit.com/adafruit-i2c-qt-rotary-encoder/pinouts
- Adafruit seesaw register map: https://github.com/adafruit/Adafruit_Seesaw
- Adafruit 5528 knob (6 mm bore, 2 mm hex set screw): https://www.adafruit.com/product/5528
- ESP32-S3 datasheet, VIH min 0.75 VDD; strapping pins IO45/IO46.
- Shell: `enclosure/README.md` (v2 encoder section, v6) and `enclosure/src/p64_enclosure_v6.scad`.

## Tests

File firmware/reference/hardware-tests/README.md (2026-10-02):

# p64 hardware tests

This folder was `firmware/` until 2026-09-19, then `hardware-tests/` at the repository
root until 2026-09-24, when it moved under `firmware/reference/` (tracked in git, unlike
the upstream clones beside it). It is the test firmware that brought up the driver board
and the panel, kept as technical reference (pin map, driver patch, frame pacing, tonal
depth, network settings, microSD, measured numbers) for the product firmware that is
being built from zero in `firmware/`. It still builds and flashes as described below;
every relative path in this document is from this folder.

ESP-IDF firmware for the Waveshare ESP32-S3-RGB-Matrix driver board and the
RGB-Matrix-P2-64x64 panel. Written in C++20 directly on top of the
[esphome/esp-hub75](https://github.com/esphome-libs/esp-hub75) DMA driver (pulled in
by the IDF component manager); no Arduino, no LVGL.

## What it does today: Makapix Club artwork with a clock

At boot the firmware plays a random GIF from the microSD card's root (black, with the
clock, when the card has none). In the background it asks Makapix Club for a random
promoted GIF that fits the panel and downloads it; the panel switches to that artwork
the moment it lands, and from then on to a fresh download every 30 s, or as soon as
the next one lands when it is late (Wi-Fi down, request failed, NTP not synced yet):
the current artwork stays up meanwhile and the fetcher keeps trying every few
seconds. Nothing but fresh downloads plays after the startup one; no GIF is embedded in
the firmware any more (the 64 Makapix GIFs that were `assets/gifs/` here live in
`../../tests/host/corpus/gifs/` since 2026-09-24, as the test corpus of `gifcheck` and of
the product firmware's host tests; the copy loop under "microSD card" puts them on a card). GIFs
play at their intended speed, looping as needed; frame delays are honoured with the
browser rule (a delay under 20 ms is shown for 100 ms). Top-left, on a 70 % black box
(the artwork shows through at 30 % brightness), a 24-hour clock (HH:MM) set from NTP
over Wi-Fi; it reads `--:--` until the first sync. A GIF requested over the network
(see "Web control" below) pre-empts the rotation for its requested time, and GIF files
copied to the microSD card can be played one at a time or as a playlist (see "microSD
card").
Pressing **BOOT** restarts the scene.

### Makapix Club client (`main/net/makapix.*`)

Anonymous HTTPS, two requests per artwork, both against the public API of
<https://makapix.club> (its code is at <https://github.com/fabkury/makapix>):

```
GET /api/post?promoted=true&sort=random&limit=1&width_max=64&height_max=64&file_format=gif
GET /api/d/{public_sqid}.gif
```

The first returns one random promoted post with a GIF variant no larger than
`P64_MAKAPIX_MAX_DIMENSION` (64, the panel size, by default; the JSON carries sqid,
title, artist, size and the files list; 143 candidates at the time of writing); the
second is the GIF file itself. The API also takes `width_min`/`height_min`, which is
how the 128x128-only test below was run (of the first 200 promoted GIFs up to 128 px on
2026-09-15: 82 were 128x128, 82 64x64, 20 32x32, 16 16x16). A fetcher task on the Wi-Fi core
does the work: it waits for Wi-Fi and the NTP sync (TLS checks certificate dates),
skips artworks shown in the last 32 picks (re-drawing up to three times), caps the
download at `P64_MAKAPIX_MAX_BYTES` (1 MB), retries once, and hands the bytes to the
scene through a mutex. The scene logs title, artist and the page URL for each artwork.

Measured 2026-09-15 over 12 minutes of the show (serial log, 24 swaps, device already
running, home Wi-Fi at -49 dBm): the next artwork was ready 5.1 to 19.6 s after each
swap (median 5.9 s, mean 6.8 s, standard deviation 3.0 s; the fetch starts within a
millisecond of the swap, so this is the two HTTPS requests end to end), never late for
the 30 s slot; all 24 intervals were 30.0 s, no fetcher warning, no panel sync timeout.
The slowest three fetches (19.6, 10.8, 9.2 s) were the server's erratic throughput, not
retries. So the 30 s slot has 10 s of margin at the worst seen; a slot under ~20 s would
start to run late.

Same measurement the same day with the rotation restricted to 128x128 artworks only
(`P64_MAKAPIX_MAX_DIMENSION` 128 plus a temporary `width_min=128&height_min=128` in the
query; window from the first 30 s swap, 24 swaps, all 128x128, 3 KB to 443 KB, median
32 KB): ready 5.2 to 20.5 s after the swap (median 5.9 s, mean 7.3 s, standard deviation
3.4 s), never late, every interval 30.0 s, no warning, no sync timeout. The first
download took 20.5 s from boot (a 211 KB file; 10.7 s at 64 px). Decode plus box-average
downscale of a 128x128 frame to 64x64 cost 1.2 to 5.4 ms (median 2.3 ms) against 0.3 to
1.3 ms for 64x64 sources; the delivered GIF frame rates were unchanged (median 10 fps).
The stats line's "render ms per frame" reads 280 ms on a still image: that field sums
the render calls of a whole 10 s window over the frames presented (one), so it is an
accounting artifact, not a slow frame. Reverted to 64 afterwards.
User agent: `p64/<git version>`. Menu `p64 > Makapix Club` can disable it or change
the host.

### Web control (`main/net/web.*`): play a GIF on command

The device runs a small HTTP server on port 80 and announces itself over mDNS as
**p64.local** (hostname and an `_http._tcp` service; the DHCP hostname is `p64` too).
Endpoints:

| Request | Effect |
|---|---|
| `GET /play?post=<Makapix post URL or sqid>[&seconds=N]` | download that post's GIF and play it |
| `GET /play?url=<GIF URL>[&seconds=N]` | download any GIF (http or https) and play it |
| `POST /play` with the same fields form-encoded | same |
| `GET /stop` | end on-demand playback now; the rotation resumes |
| `GET /pattern` | hold a tone test pattern (grey and colour ramps of the darkest quarter, a full ramp, two shaded spheres) until `/stop` or the next `/play` |
| `GET /play?file=<name>[&seconds=N]` | play a GIF file from the microSD card |
| `GET /sd` | JSON: card info and its GIF files |
| `PUT /sd/<name>`, `GET /sd/<name>`, `DELETE /sd/<name>` | copy a GIF to the card, read it back, remove it |
| `GET /sd/play[?seconds=N]` | play every GIF on the card in turn (30 s each by default) until `/stop` or another request |
| `GET /sd/mount` | mount the card again after swapping it |
| `GET /debug` | panel DMA health (stall flag, cumulative timeouts and late flips), GDMA priority, timing, crypto settings |
| `GET /debug/dma?priority=N` | GDMA priority of the panel's channel, 0 to 5, applied at once |
| `GET /debug/stress[?loops=N]` | run the download speed test now (about 12 MB per pass, a heavy TLS load) |
| `GET /debug/reboot` | restart the board |
| `GET /status` | JSON: what is playing (name, source, size, seconds left), the last request (id, state, error), Wi-Fi IP and RSSI, heap |
| `GET /` | a form for phones |

`post` accepts `https://makapix.club/p/7fQw`, `makapix.club/p/7fQw` or just `7fQw`.
`seconds` defaults to 60 (`P64_WEB_DEFAULT_SECONDS`); `0` keeps the GIF up until the
next request or `/stop`. `/play` answers at once with `202 Accepted` and a JSON summary
(`id`, `sqid` or `url`, `seconds`); the fetcher task then downloads the file ahead of
the rotation's own requests and the scene switches as soon as it lands (3 to 10 s over
TLS to Makapix, less for plain HTTP). Failures (bad sqid, 404, not a GIF, too large,
offline) show up in `/status` under `request.error` and in the log. A newer request
replaces one still waiting; when the time is up, the rotation continues with a fresh
slot. Limits: files up to 4 MB and 512x512 px (`P64_WEB_MAX_BYTES`, `P64_WEB_MAX_DIMENSION`);
larger frames are scaled down to the panel like everything else. Anything on the LAN
can call these endpoints: there is no authentication.

```
curl "http://p64.local/play?post=https://makapix.club/p/Hqm"
curl "http://p64.local/play?post=Hqm&seconds=120"
curl "http://p64.local/play?url=https://vault.makapix.club/02/33/478727e5-b81c-4c4e-9742-0607fdb86d7f.gif&seconds=0"
curl http://p64.local/status
curl http://p64.local/stop
```

### microSD card (`main/sdcard.*`)

The board's card slot is wired to the ESP32-S3's SDMMC host in 1-bit mode (CLK GPIO 1,
CMD 44, D0 17, from Waveshare's BSP), which has its own DMA engine. The card is mounted
at boot as FAT at `/sdcard` with long file names; a card with no FAT file system (for
example a 64 GB card that comes as exFAT) is formatted to FAT32 on the first failed
mount (`P64_SD_FORMAT_IF_MOUNT_FAILED`, on by default: it erases the card). There is no
card-detect line, so a swapped card needs `GET /sd/mount`. GIF files live in the card's
root; other files are ignored.

Copying files works over HTTP because the card sits in the board: `curl -T file.gif
http://p64.local/sd/file.gif` for each file (any script, phone app or the front page's
drag-and-drop zone does the same with a `PUT`). Uploads stream to a `.part` file, are
checked for the GIF header, then renamed. Playback of a card file follows the same path
as a Makapix post: the fetcher task reads the file into PSRAM (1 to 9 ms for the files
tried) and the scene switches to it; `/sd/play` walks the whole card, one file per slot,
keeping the current file up until the next has loaded, skipping files that fail, and
looping until `/stop` or another request. `/status` shows the card (name, size, free
space, GIF count) and the playlist position.

Measured 2026-09-13 with a 32 GB card: the 64 Makapix GIFs (1.07 MB) copied in 38 s
with one curl call per file (the per-request HTTP overhead dominates; a 124 KB file took
1 s), a file read back byte-identical, the panel's frame pacing unaffected by card
traffic (SDMMC does not use the GDMA that the panel uses). Menu `p64 > microSD card`
holds the pins, the bus clock (20 MHz; lower it if the panel ever stalls during card
traffic) and the format policy.

```
for f in ../../tests/host/corpus/gifs/*.gif; do curl -T "$f" "http://p64.local/sd/$(basename "$f")"; done
curl http://p64.local/sd
curl "http://p64.local/sd/play?seconds=10"
curl "http://p64.local/play?file=5PKj_32x32_piranha-plant.gif&seconds=20"
curl -X DELETE http://p64.local/sd/5PKj_32x32_piranha-plant.gif
```

Windows 10+, macOS, iOS and Linux with Avahi resolve `p64.local`; Android's browser
does not, so use the IP address from `/status` (or the router) there. Menu
`p64 > Web control` can disable the server or change hostname, port and limits.

Per GIF the log reports frames shown, fps, loops and decode+scale time per frame; every
10 s the main loop logs frames presented, render / wait / copy times, late flips and
sync timeouts. Frames are only presented when a GIF frame or the clock changed.

Artwork is scaled in the firmware to 64x64 with the aspect ratio kept: nearest
neighbour when enlarging (pixel art stays crisp), box average when shrinking, black
bars around the image. Transparent pixels show black.

Menu `p64` in menuconfig (`.\tools\idf.ps1 menuconfig`) holds the knobs: brightness cap,
Wi-Fi credentials, NTP server, timezone (POSIX TZ string, default New York), Makapix
on/off, host and download cap, the web control (on/off, hostname, port, default seconds,
size limits), seconds per artwork, and two switches that turn the show back into the
frame-rate test: ignore frame delays, and show the delivered fps top-right.

Earlier scenes (bouncing ball, white fades, full-power white, the rotating square hue
wheel) live in git history (`git log -- main/scenes`).

### Wi-Fi credentials

Copy `sdkconfig.secrets.example` to `sdkconfig.secrets` (git-ignored) and fill in the
SSID and password; the project's `CMakeLists.txt` applies it on top of
`sdkconfig.defaults`. Like any defaults file it only reaches an existing generated
`sdkconfig` after `menuconfig` or after deleting `sdkconfig`. Without it the firmware
runs offline and the clock stays at `--:--`. The network stack, lwIP and SNTP run on
core 0; the main task (rendering) is pinned to core 1 so traffic never delays a frame.
First sync after boot takes 5 to 30 s (Wi-Fi join, DNS, SNTP's own start-up delay).

TLS uses the hardware AES and SHA engines (ESP-IDF's defaults). They stream through
GDMA, the shared DMA block that also feeds the panel, and on 2026-09-12 their bursts
stalled the panel whenever it ran at 32 MHz: the LCD FIFO underran, the DMA descriptor
pointer froze mid-frame and only a reboot recovered it (none at 20 MHz, none with
software crypto, and restarting the driver in place did not help). The root cause,
found on 2026-09-13, is GDMA arbitration: every channel sat at priority 0, so a long
crypto burst could hold the panel's channel off for longer than the panel's FIFO
lasts; the FIFO has no back-pressure, so it must never wait. The vendored driver now
sets the panel's channel to priority 5 (`HUB75_GDMA_PRIORITY`, see "GDMA priority
experiment" below), which made 32 MHz survive three passes of the download speed test
with hardware crypto. The display still logs "panel DMA stalled" once if a stall ever
happens, and `/debug` reports it.

#### GDMA priority experiment (2026-09-13)

32 MHz, 10 bit planes, transition bit 4 (434 Hz), hardware AES and SHA on. Health read
from `/debug` (cumulative timeouts and the stall flag), load from `/debug/stress` (one
pass = about 12 MB: two 1 MB and one 5 MB HTTPS download from Cloudflare, a 5 MB HTTP
download, seven Makapix downloads).

| Panel channel priority | Load | Result |
|---|---|---|
| 5 | 50 s of the show with its Makapix fetches | 0 timeouts |
| 5 | 2 stress passes back to back (about 140 s of TLS) | 0 timeouts, no stall |
| 5 | reboot, 1 more stress pass | 0 timeouts, no stall |
| 0 (switched live) | the show's next Makapix fetch | stalled after 2.6 s, every wait timed out from then on |

Throughput at priority 5 matched the earlier measurements: 531 KB/s for the 5 MB HTTPS
download, 476 KB/s HTTP, 360 KB/s per file from Makapix on a kept-alive connection. So
the panel's priority costs the network nothing measurable. The clock stays at 20 MHz
regardless, because 32 MHz shortens every LED pulse 1.6x (plane 0 would be 31 ns); the
option is open now, with or without hardware crypto. One side note: while the speed
test saturated the link, the web server stopped answering for about 30 s; the panel
was unaffected.

### GIF pipeline

`components/animatedgif` is a vendored copy of bitbank2/AnimatedGIF (Apache-2.0, see
its README for the one local patch). It is used in RAW mode: the library decodes LZW
and hands `GifPlayer` (`main/gif_player.*`) one line at a time with the palette, the
frame rectangle, the transparency index and the disposal method; `GifPlayer`
composites into an RGB888 canvas of the GIF's logical size, honouring all four disposal
modes (the library itself does not implement "restore previous"), and `Scaler` fits the
canvas into the 64x64 frame. `gif_player.*` has no ESP-IDF dependencies on purpose.

`tools/gifcheck/gifcheck.py` builds that exact code natively (needs g++ and Pillow),
decodes every GIF in `../../tests/host/corpus/gifs/`, and compares every frame's canvas against Pillow
and every scaled frame against a Python twin of the scaler, pixel-exact. Run it after
touching the decoder, the compositor, the scaler or the assets:

```
python tools\gifcheck\gifcheck.py          # all GIFs; exit code 0 when everything matches
python tools\gifcheck\gifcheck.py a.gif    # specific files
```

Adding artwork to the device: copy the `.gif` to the microSD card (see "microSD
card"); the corpus is only for testing and is not embedded in the firmware.

The panel is driven in its **native orientation** (`CONFIG_HUB75_ROTATE_0`).

Verified on the hardware on 2026-09-08: with the panel in native orientation, seen
from the front, the native bottom edge (the floor line) is at the bottom and the
controller board with its two USB-C ports sits behind the **right** edge. The enclosure
mounts the panel turned 90 degrees clockwise (front view) so the USB-C ports point down;
that puts the native right edge at the bottom. The driver setting for that is
`CONFIG_HUB75_ROTATE_90=y` (its transform maps image (x, y) to native (y, 63 - x), so
image "down" becomes native +x). Switch it in `sdkconfig.defaults` when the enclosure
arrives and the ball will again fall toward the physical bottom.

## Frame pacing: locked to the panel refresh

The panel refreshes at 271.3 Hz (64x64, 10 bit planes with the five lowest sent once
per frame, 20 MHz HUB75 clock; see "Tonal depth and refresh" below). The driver
double-buffers, but its
`flip_buffer()` only relinks the DMA descriptor chain: the DMA keeps scanning the old
front buffer until that frame ends, and the driver gives no signal when it has
switched. Drawing into the back buffer too early tears.

`Display` therefore watches the LCD GDMA channel directly (`display.cpp`):

1. `present()` copies the RAM frame into the back buffer, notes which chain is front
   (the one containing the descriptor the channel is fetching, `dscr`; the last
   descriptors of both chains were learned at start-up from two frame boundaries),
   clears the channel's end-of-frame flag, then flips.
2. The scene renders the next frame into RAM straight away (rendering overlaps the
   panel's switch).
3. `wait_for_back_buffer()` sleeps until shortly before the predicted boundary
   (boundaries are exactly periodic), spins on the end-of-frame flag, then reads the
   channel's `dscr` register: if the descriptor being fetched still lies in the chain
   that was front at the flip, the flip missed the boundary (the DMA had already
   prefetched the last descriptor) and it waits for the next one. Testing against the
   chain noted at flip time, rather than the chain that just ended, is what keeps this
   correct when presents are sparse and many boundaries have passed in between.
   The front chain must not be identified from `eof_des_addr` either: it names the
   chain whose frame ended last, so for one frame after a switch it still points at
   the previous front. A present inside that window (every artwork transition presents
   two frames a few milliseconds apart) recorded the wrong chain, every later check
   then said "still old" until the timeout, and with 100 ms GIF delays the overdue next
   frame recreated the condition: 4 to 11 late flips per frame for minutes at a time
   (found and fixed on 2026-09-12).
4. Only then does the next `present()` copy into the freed buffer.

Results on the hardware (2026-09-12), one new frame per refresh in every case:

| Scene | HUB75 clock | Refresh | Delivered | Per frame: copy / render / wait | Late flips per 10 s |
|---|---|---|---|---|---|
| Ball | 20 MHz | 76.3 Hz | 76.0 fps | 5.8 / 0.04 / 7.3 ms | 3 |
| Ball | 32 MHz | 122.1 Hz | 122.0 fps | 5.8 / 0.04 / 2.4 ms | 0 |
| GIFs (16 to 64 px) | 32 MHz | 122.1 Hz | 122.1 fps | 5.8 / 1.0 to 1.4 / 1.0 to 1.4 ms | 0 |

For these small GIFs decode plus scale costs 1.0 to 1.4 ms per frame (a single-frame
GIF re-parses its header every frame), so the copy still dominates and the frame rate
stays at the refresh cap. Larger artwork would eat into the remaining ~1 ms of headroom
and start dropping to every other refresh.

"Late flips" are flips that landed in the DMA's prefetch window and cost one extra
refresh. If the GDMA channel cannot be found the wait falls back to a full refresh
period after each flip ("timed fallback" in the log, about 50 fps at 76 Hz).

The main task must block at least once in a while or the idle task on core 0 starves
and the task watchdog fires every 5 s; the wait sleeps whenever a whole tick of slack
exists and forces a one-tick yield once a second otherwise.

The copy into the driver's bit-plane buffers is the limit: 5.8 ms with 8 planes, 6.9 ms
with the current 10 planes, almost two of the 3.69 ms refresh periods, so at most every
second refresh can carry a new frame (about 135 fps, far above any GIF). Going further
means shrinking the copy (dirty-rectangle updates, or a faster blit inside the driver).

## Tonal depth and refresh

An LCD receives gamma-encoded values, so dark tones get as many codes as bright ones;
the panel modulates light linearly in time, so with 8 bit planes the darkest quarter of
the input range (0-63 of 255) had only 11 distinct codes and dark artwork (Makapix Hqm,
a shaded brown ball) showed 2-3 flat shades. More planes double the frame time each,
and the driver's `HUB75_MIN_REFRESH_RATE` knob, which sends the low planes once instead
of repeating them, collapsed the levels in the released driver because it kept the same
output-enable window for every plane (8 bits forced to 150 Hz gave 66 levels, worse
than plain 7 bits).

The driver is therefore vendored under `components/esp-hub75` and patched (see its
`P64-CHANGES.md`): planes at or below the transition bit T are sent once with a halving
output-enable window, so every plane keeps its binary weight, and the LUT is refitted
to the planes' real on-times after each brightness change.

Correction (2026-10-02, found in the product firmware): this folder's patch writes each
plane's window into that plane's own buffer, but a buffer's output-enable bits gate the
data latched by the buffer sent before it. Here each window therefore lights the plane
below it, the data weighs 3 7 15 31 62 62 124 248 496 931 clocks instead of the 1 3 7 15
31 62 .. 992 below, the darks are two to three times too bright and the light falls by
half from input 51 to 52. The product driver (`firmware/components/esp-hub75`,
`p64bcm::buffer_windows`) puts each window into the next buffer; this test bed is left as
it was, so read its dark-tone numbers below as the intent, not what the panel showed. Frame time is
32 rows x (T + 2^(bits-1-T)) transmissions x 64 pixels / clock, with T the smallest
value that reaches the minimum refresh rate. Current setting: 10 bits, minimum 250 Hz,
hence T = 4, 36 transmissions per row, 271.3 Hz, 1024 codes per channel; output-enable
windows 1/3/7/15/31 pixel clocks (50 ns to 1.55 us) for planes 0-4 and 62 for the rest.
The 50 ns pulse of plane 0 (1/1979 of full scale) may give little light, which would
merge neighbouring codes: the darkest quarter has 49 codes on paper and at least 25
(it had 11 at 8 bits). The step below, minimum 140 Hz -> T = 3, 145.8 Hz, keeps all
ten planes at 150 ns or longer (48 dark codes); the steps above are 465 Hz (T = 5,
plane 0 without a window, 13-25 dark codes) and 698 Hz (T = 6, 7-14, the old 8-bit
look). The clock stays at 20 MHz by choice: 32 MHz would shorten every pulse 1.6x. It is
no longer forced by the crypto engines (the panel's GDMA channel now has priority, see
"Wi-Fi credentials") nor by the SD card (its host has its own DMA). The tone curve is gamma 2.2 (the released driver's gamma
2.2 table was broken: black mapped to full white; fixed in the patch), matching the
sRGB monitors the artwork is made on. Photos need an exposure of one refresh or longer,
1/270 s. Use `/pattern` to judge the darks against a monitor. Brightness below 255
shortens every window and costs the low planes first, so dim in software if ever needed.

## Setup (Windows)

ESP-IDF **v5.5.x** installed with Espressif's Installation Manager (EIM). This machine
has v5.5.4 at `C:\esp\v5.5.4\esp-idf` with tools under `C:\Espressif\tools`; the
ESP32-S3 toolchain was added with

```
$env:IDF_TOOLS_PATH = 'C:\Espressif\tools'
C:\Espressif\tools\python\v5.5.4\venv\Scripts\python.exe C:\esp\v5.5.4\esp-idf\tools\idf_tools.py install --targets esp32s3,esp32p4,esp32c6
```

(`idf_tools.py` refuses to run from Git Bash; use PowerShell.) `tools/env.ps1` holds
those paths; edit it if ESP-IDF lives elsewhere.
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

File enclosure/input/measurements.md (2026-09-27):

# Hand measurements

Parts measured by hand for the enclosure. Values are in millimetres unless noted.
Add new parts or new measurements below; keep one section per part. (The speaker box
that only v5 used is measured in `../archive/pre-v7/README.md`.)

## v1 shell print (received 2026-09-18)

`output/v1/p64_enclosure_service.stl` (0.45 mm fit clearance), ordered from JLC3DP on
2026-09-05 (order D2026090531500023, $18.83 including shipping), printed in black FDM
PLA. Photos, all taken on
2026-09-18 (removed from `input/` on 2026-09-27; they stay in git history, added by
commit f862e6e, `git show f862e6e:enclosure/input/<file>`):

| File | Shows |
|---|---|
| `PXL_20260918_170429654.jpg` | Open shell, cavity up, beside the panel with the controller and power leads |
| `PXL_20260918_170508326.jpg` | Assembled display in hand, lit, cable leaving the base pocket |
| `PXL_20260918_170630166.jpg` | Assembled display standing on the desk, front, off |
| `PXL_20260918_170639495.jpg` | Back face standing: six counterbores, vents, pin holes with groove marks, mic holes, cable notch |
| `PXL_20260918_170650583.jpg` | Side view standing: wedge profile, frame edge proud of the shell |
| `PXL_20260918_233146091.jpg` | Panel back with the controller out of the shell, next to the short right-angle USB-C cable |
| `PXL_20260918_234736918.MP.jpg` | Display standing, lit, in the dark |

Measured on 2026-09-18:

| Item | Value | Model |
|---|---|---|
| Width | 133.0 | 132.4 |
| Depth at the bottom edge, front lip to back face | 34.6 | 34.6 |
| Panel side play in the pocket | under 1 | 0.45 per side |

Notes:
- All six bosses line up with the inserts; screw holes and counterbores printed clean.
- The frame sits on the ledge all round with the LED mask about 2.5 mm proud.
- The base pocket lands exactly on the two USB-C ports.
- Visible gap between the controller and the back wall.
- Stands stably at 12 degrees; barely warm after running for a while.
- Not checked yet: pin and mic holes over the buttons and mics; the plug in the pocket and
  the cable in the groove to the back notch.

## Panel driver chips (read 2026-09-27)

The chips on the back of the RGB-Matrix-P2-64x64 are all the same, marked `FM6124HJ` and
`C003173` (a lot code). The FM6124 is a plain constant-current shift register without
configuration registers; the firmware's FM6126A setting works because its register writes
pass through unread. Recorded here because Waveshare's page does not name the chip.

## 90-degree USB-C adapter (two, one per driver-board port)

Small aluminium-shelled USB-C male-to-female right-angle adapter: the male plug leaves the
wide face of the body near one end, the female socket sits in the far end face. Two are
used, one on each of the driver board's ports (POWER and USB), and they stay there; the
external cable plugs into the adapter's socket from the back of the shell (v6). Photos in
`usb-c-90-degree-adapter/`: `PXL_20260919_152802345.jpg` (side, plug to the right),
`PXL_20260919_152820195.jpg` (female end face), `PXL_20260919_152837459.jpg` (plug end),
and `PXL_20260919_152802345 - with measures.jpeg` (the side view with the measurements
drawn on; the GIMP source `.xcf` is kept next to it, untracked).

Measured on 2026-09-19 (the side photo):

| Item | Value |
|---|---|
| Body length, near end face to female socket face | 19.3 |
| Body thickness (along the plug axis) | 8.0 |
| Near end face to the plug tip, along the body | 13.3 (so the plug's far edge is 6.0 from the near end) |
| Body face to the plug tip, along the plug axis | 15.7 - 8.0 = 7.7 |
| Body width across the end face | 12.7 (the two bodies touch when both are plugged in: the ports are 12.74 apart) |

Derived, used by v6: the plug's centre is 4.8 from the near end (6.0 minus half of the
2.4 mm plug thickness); the boot between the body face and the receptacle face is about
1.2 (7.7 minus a 6.5 mm plug shell), an estimate.

Checked on the panel the same day:
- Both adapters fit in the two ports at once; the bodies touch.
- Plugged into a port with the controller on the panel, the adapter body lands on the
  frame's back plate below the port and stops about 1 mm short of fully seated. The
  shell design (v7) therefore assumes a notch cut through the plate strip below the
  ports, see `README.md` (v6).

## Adafruit 5880 rotary encoder breakout (p64b)

The shell's numbers for the board come from Adafruit's EagleCAD file
(`adafruit-5880/README.md`) and for the encoder from the Bourns PEC11 datasheet, checked
on 2026-09-22. Measured with calipers on one of the user's two boards the same day:

| Item | Model | Measured 2026-09-22 | Sets |
|---|---|---|---|
| Shaft tip to the bushing base (the body's top face) | 15.0 | 15.0 | `enc_shaft_l`; the 15 mm shaft, so the datasheet's 5.0 mm bushing |
| Threaded bushing length | 5.0 (datasheet) | 6.0, "to the best of my efforts" | `enc_bush_l`, now 6.0: the bushing stands 3.6 mm proud of the face and leaves 4.0 mm of thread for the nut (needs 2.5); the board's position does not depend on it |
| PCB top face (component side) to the bushing base | 6.5 | 6.5 | `enc_body_h` |
| PCB thickness | 1.6 | 1.6 | `enc_board_t` |
| Washer + nut stacked, height | 2.5 | 2.5 | `enc_nut_h` |
| Washer outer diameter, nut across corners | under 14 (the spot-face) | not measured | the 14 mm spot-face; an M7 nut and washer are about 11 to 12 mm, so a check, not a worry |
| Tallest feature below the PCB (pin stubs, solder) | 0 (not modelled) | about 3.0 | the room there is 4.1 mm (board bottom 7.2 mm behind the frame's back face, ledge top at 3.1): clear by 1 mm |
| Mounting hole diameter | 2.5 | 2.5 | `enc_hole_d` (the 2.2 mm pegs) |
| Mounting hole spacing | 20.32 | not measured (board file) | `enc_hole_p` |
| Board width | 25.4 | 25.4 | `enc_board` |
| Knob, diameter x height | 20 x 12.5 (mock-up) | 20.0 x 15.5 | `knob_d`, `knob_h`, mock-up only: the knob end is now 35.1 mm behind the frame's back face, 13 mm past the shell's bottom edge |
| Cap seating | | about 1 mm of shaft left above the nut (2026-09-27) | not modelled; a cap pushed down onto the nut takes up the switch's push travel and the click never registers (`docs/hardware/encoders-soldered.md` section 8) |

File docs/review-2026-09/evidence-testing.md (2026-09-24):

# Evidence: testing inventory (code audit, 2026-09-22)

What protects the firmware today, file by file, from the code on 2026-09-22. Paths are
relative to `firmware/`. The analysis and proposals are in `testing.md`.

## 1. Host tests

Framework: hand-rolled. `tests/host/main.cpp:46-65` defines `CHECK(cond)` and
`CHECK_EQ(a,b)`, which bump two file-static counters (`g_checks`, `g_failures`, lines
43-44), print `FAIL file:line: expr` to stderr and continue. `run_unit()`
(main.cpp:1118-1145) calls 24 `test_*` functions in sequence in one process and returns
1 if any check failed. No isolation: no fixtures, no per-test setup or teardown, shared
static state (a `static ReadySlot slots` at main.cpp:222), no way to run one test by
name, and the pass output is one line (`unit tests: 1433 checks, 0 failures`) without
test names. `tests/host/run.py` (460 lines) is the driver: it compiles the sources with
the PC's gcc and g++ into `tests/host/build/` (mtime-based incremental, run.py:123-125),
runs `unit`, then runs `dump` (main.cpp:1152-1235) to write every frame of every corpus
file and checks the dumps in Python against Pillow (run.py:358-395), a spec-compliant
APNG compositor written because Pillow's is wrong (run.py:204-300), a Python twin of the
scaler (run.py:157-201) and the browser delay rule (run.py:350-355). Tolerance 0 for
GIF, PNG and BMP, 1 for WebP and APNG (run.py:371). Corpus: 22 Pillow-made files in
`tests/host/corpus/` plus 64 GIFs from the hardware tests (in `tests/host/corpus/gifs/`
since 2026-09-24): 86 files, 1531
frames.

Flags: C++ `g++ -std=c++20 -O2 -Wall -Wextra -D__LINUX__` (run.py:128); vendored C
`gcc -O2 -w -DHAVE_UNISTD_H` (warnings suppressed, run.py:130); link `-static`
(run.py:153). No `-Werror`, no sanitizers, no coverage, no `-g`. A cold build emits two
warnings, both in vendored AnimatedGIF, none in p64 code.

Time (measured on this laptop, 2026-09-22): cold build 100.8 s, almost all libwebp,
libpng and zlib (119 objects); warm unit tests 0.2 s; warm unit plus the full corpus
7.0 s. Needs gcc on the PATH, the system Python with Pillow, `IDF_PATH` for cJSON
(run.py:36) and a prior firmware build for `managed_components/espressif__zlib`
(run.py:137).

Check counts (static `CHECK` sites in main.cpp; loops make the runtime count 1433;
PROGRESS.md recorded 74 at M1 and 1115 at M5):

| Area | Test functions | Sites |
|---|---|---|
| p64_decode (delay rule, sniffing) | 2 | 16 |
| p64_gfx (scaler x2, rotation and gains, blend, 5x7 text, bundled fonts) | 6 | 84 |
| p64_playback (`FrameQueue`, header-only) | 1 | 8 |
| p64_content (playset model, JSON, scheduler x2, history, makapix index) | 6 | 142 |
| p64_widgets (clock_format, analogue, weather_model) | 3 | 60 |
| p64_stream (protocol: raw and DDP headers, assembler, conversion) | 1 | 60 |
| p64_system (night, rtc_codec) | 2 | 30 |
| p64_inputs (taps, orientation) | 2 | 29 |
| p64_ota (version) | 1 | 14 |
| Total | 24 | 445 sites, 1433 at runtime, plus 86 corpus files |

Compiled into the host binary (run.py:40-69): 28 p64 sources plus
`animatedgif/src/AnimatedGIF.cpp`, zlib (10 files), libpng, libwebp (dec, dsp, utils,
demux) and IDF's `cJSON.c`. 26 of the 74 p64 `.cpp` files are host-compiled. Six more
are already IDF-free but not listed in run.py: `p64_gfx/src/png_encode.cpp`,
`p64_content/src/local_index.cpp` (dirent and stat only),
`p64_playback/src/artwork.cpp`, `p64_net/src/tz.cpp`, `main/status_screens.cpp`,
`main/boot_animation.cpp`.

Documentation drift: `docs/architecture.md:44-46` and `:173` say `tools/hosttest/`
builds the host tests and `tools/bench/` the benchmark; neither directory exists (the
tests are `tests/host/`, the benchmark is `GET /api/v1/diag/bench`). The table at
architecture.md:14-33 lists `p64_ops` (there is `p64_ota` plus `main/ops.cpp`), marks
`p64_net` "no" although `tz.cpp` is pure, and omits `p64_ota`'s host-tested
`version.cpp`.

## 2. Seams

Method: an include scan plus call-site counts (ESP_LOG, esp_timer, FreeRTOS tasks,
queues and semaphores, NVS, sockets and httpd, heap_caps, cJSON) per file.

| File | What blocks it | Pure part inside | Grade |
|---|---|---|---|
| `main/show.cpp` (1470 lines) | the FreeRTOS command queue (:221, :1177, :1238), `esp_task_wdt` (:1234-1236), `esp_timer` (:199), `esp_random` (:558, :727), `heap_caps` (:1175), 24 log sites, and direct calls into makapix, wifi, card, stream, web, widgets, settings, state_store and the loader (:19-39). State is file-static globals in an anonymous namespace. | `pick_fresh` (:346), `mark_entry` (:383), `install` (:696), `same_channels` (:687), `enter_animation_show` (:292), `channel_status` and `no_artwork_reason` (:249, :265), the tick and timer gating | Expensive seam: a "state struct + injected clock and RNG + effects interface" split touches the whole file. Highest value: the 2026-09-21 frozen-artwork and Followed-restore bugs live here. |
| `p64_makapix/src/api.cpp` (433) | one `ESP_LOGD` (:429), `esp_app_get_description` (:147), `CONFIG_*` (:98, :378, :383); transport through `net::fetch` (:55) | `entry_from_post` (:100), `fill_page` (:82), the `query_page` body (:219), `download_url` (:377): 83 cJSON calls, the site contract | Cheap seam: a log shim header, a stub `net::fetch`, a version string. |
| `p64_makapix/src/makapix.cpp` (722) | `esp_timer`, mbedtls x509 (`cert_not_after` :146), tasks | `handle_command` (:227) parses the MQTT command JSON | Cheap for `handle_command` if it returns a command struct; expensive for the rest. |
| `p64_makapix/src/mqtt.cpp` (283) | the esp_mqtt client and its event structs (`on_event` :59, fragment reassembly :29-30) | the payload builders `publish_capabilities`, `status`, `state`, `view`, `ack` (:39-266) build cJSON then call `publish()` (:34) | Cheap for the payloads (return the string); medium for the event handler. |
| `p64_makapix/src/fetcher.cpp` (770) | the task loop, queue, `esp_timer` (19 sites), heap | `refresh_step` (:248), `finish_walk` (:190), `next_download` (:328), the "park an offline Followed job" rule (:566) | Expensive seam: policy interleaved with API, cache and task calls. |
| `p64_makapix/src/cache.cpp` (211) | `ESP_LOG`, `heap_caps`, one `vTaskDelay`; POSIX file I/O under `/sdcard` | `sweep_folder` (:169) and `sweep` (:198) are directory walks | Cheap: a root-path parameter plus shims; testable on a temporary directory. |
| `p64_makapix/src/credentials.cpp` | NVS only (38 sites) | none | Cheap but low value. |
| `p64_web/src/*.cpp` (7 files, about 1750 lines) | every handler takes `httpd_req_t*` (api.cpp:242-572, auth.cpp:158-296, content, files, makapix_routes, ws, ui); body parsing (`parse_body` api.cpp:126) and validation inline | `build_status` (api.cpp:147), `check_pin` and the lockout (auth.cpp:113), `hash_pin` (auth.cpp:50, mbedtls sha256), `valid_pin` (:98) | Expensive as written; a p3a-style "(method, path, query, body) to (status, json)" core would be moderate per file, large in total. The auth lockout and session logic is a cheap seam with clock and RNG injection. |
| `p64_system/src/settings.cpp` (466) | NVS confined to `nvs_write_impl` and `nvs_read_impl` (:384-411, wrapped by `on_internal_stack` :413-414), six log sites, `std::mutex` | `Settings::clamp` (:121), `to_json` (:161-258), `apply_json` (:260-380): 84 cJSON calls, every range, enum and clamp rule of spec section 16 | Cheap seam: compile with a stub for the two NVS functions and a log shim. The M4 "values wrapped before clamping" bug lives in this pure code and has no host test. |
| `p64_system/src/state_store.cpp` | NVS only | none | Cheap, low value. |
| `p64_playback/src/player.cpp` (196) | a FreeRTOS task and command queue (`take_command` :70), `esp_timer`, `heap_caps` | the timeline rule in `run()` (:80): due = previous due + delay, the 60 Hz floor, `decoded_late`, the generation announcement | Expensive (medium size): extract a `Timeline` struct with an injected `now()`. |
| `p64_playback/src/renderer.cpp` (170) | `esp_timer` (6 sites), `Display`, `heap_caps` | the schedule in `run()` (:80): target = max(due, previous + delay), re-anchor only beyond one period, the copy lead; the M1 and M5 pacing bugs live here | Expensive but small: a `Schedule` struct would be pure. |
| `p64_net/src/*.cpp` | wifi.cpp: esp_wifi, netif, mdns, NVS, timers; fetch.cpp: esp_http_client and a semaphore; http_server.cpp and setup_portal.cpp: httpd; dns_hijack.cpp: lwIP; clock.cpp: SNTP | `tz.cpp` is pure (not compiled); the Wi-Fi fallback and backoff state (`on_event` :173, timers :150-172) | Genuinely stack-bound except `tz.cpp` (free) and the backoff state (expensive). |
| `p64_ota/src/ota.cpp` (479) | `esp_ota_ops`, `esp_partition`, `esp_https_ota`, mbedtls sha256, a task and a semaphore | the `do_check` release-JSON parsing (:119-138: tag, body, assets, the `.sha256` asset), `hex_to_bin` (:66); the version rule is already in `version.cpp` | Cheap for a `parse_release(json)` split; hardware-bound for install and rollback. |
| `p64_inputs/src/inputs.cpp`, `qmi8658.cpp` | a task, `esp_timer`, the cJSON diagnostics document; the I2C driver | already extracted: `tap.cpp`, `orientation.cpp` | Pure core already; the remainder is hardware-bound. |
| `p64_stream/src/stream.cpp` | lwIP sockets, a task, `esp_timer`, the watchdog | `deliver` (:95), conversion and scaling; the parsers are already in `protocol.cpp` | Pure core already; the socket loop is genuinely bound. |
| `p64_widgets/src/widgets.cpp` (444) | tasks (`sensor_task` :53, `weather_task` :84), `esp_timer` (`local_time_at` :130) | the digital clock, weather and temperature `FrameSource` drawing, `temperature_text` (:146), `draw_trend` (:156) | Cheap: draw from a `tm` plus a model, as `analogue.cpp` already does. |
| `p64_display/src/display.cpp`, `p64_storage/src/card.cpp`, `main/loader.cpp`, `main/ops.cpp`, `main/main.cpp` | GDMA registers, hub75, SDMMC and VFS, task wiring | nothing worth extracting | Genuinely hardware-bound. |
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

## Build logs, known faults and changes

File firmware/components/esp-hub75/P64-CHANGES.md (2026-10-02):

# p64 changes to esp-hub75

Base: esphome-libs/esp-hub75 0.3.6 (component registry, 2026-09). Search the sources for
`p64 patch` to find every modified spot. Only the ESP32-S3 (GDMA) backend is changed;
the I2S and PARLIO backends keep upstream behaviour (they inherit the new getters'
defaults).

## Binary-weighted low bit planes (gdma_dma.cpp, set_brightness_oe_internal)

Upstream meets `HUB75_MIN_REFRESH_RATE` by sending the bit planes at or below
`lsbMsbTransitionBit` once each while keeping every plane's output-enable window the
same. Those planes then all weigh one transmission, so the number of distinct brightness
levels collapses to transmissions-per-row + 1 (8 bits forced to 150 Hz gave 66 levels).
The patch gives each such plane half the output-enable window of the plane above it,
which restores its binary weight: the refresh gain of the shortened chain is kept and
the panel keeps 2^bits levels. The shortest window is the one of plane 0:
`(63 * brightness/255) >> (transition + 1)` pixel clocks; at 20 MHz, 10 bits and
transition 3 that is 3 clocks = 150 ns.

The windows are computed once per plane and must be superincreasing (each plane weighs
at least the sum of the planes below it) for the LUT fit below to hold. Upstream's
one-pixel floor for planes that truncate to zero can break that: ten planes at
transition bit 6 gave planes 0, 1 and 2 one clock each, the fit's monotonic walk got
stuck at code 3 and every input above 13 mapped to it (a posterized, nearly black
picture: p64's first Photo mode, 2026-09-20). A plane that would weigh less than the
planes below it is now blanked instead (window 0).

## Each window in the buffer after its plane (2026-10-02, p64_bcm.h buffer_windows)

The panel's shift registers latch a buffer's data at its last clock, so while a buffer is
clocked out the LEDs show the data of the buffer sent before it, gated by the
output-enable bits of the buffer being sent (upstream relies on this when buffer 0
carries the previous row's address). Upstream gives every plane the same window, so the
lag costs it nothing. The halving windows above were written into their own plane's
buffer and so each lit the plane below it: the data weighed 3 7 15 31 62 62 124 248 496
931 clocks in Quality instead of 1 3 7 15 31 62 124 248 496 992, the darks came out two
to three times too bright and the light fell at every 32nd code (by half from input 51
to 52, 31 falls along the ramp; Photo had 7, the deepest at input 98). Found by reading
the code on 2026-10-02 and confirmed on the panel with four grey bands (48, 51, 52, 56:
the third at half the second). `p64bcm::buffer_windows()` now puts the window of plane b
into buffer b + 1 and the top plane's into buffer 0, and the LUT is fitted to
`p64bcm::data_weights()`, the time each plane's data is on the LEDs given the windows in
the buffers. Total light, refresh and memory are unchanged.

## LUT fitted to the real on-times (gdma_dma.cpp, fit_lut_to_weights)

Integer windows and latch blanking make the plane weights only approximately binary, so
after every brightness change the 256-entry LUT is refitted: each input maps to the code
whose summed on-time is nearest the gamma table's target. This replaces upstream's
`adjust_lut_for_bcm()` monotonicity nudge, which is no longer called. Lowering the
brightness shortens every window, so the low planes lose resolution first; run the panel
near full brightness for the best gradation and dim in software if needed.

## The fit's targets are 16 bits wide (2026-10-02, color_lut.h FIT_TARGETS)

The fit used to take its targets from the compile-time gamma table, which has one step
per code of `HUB75_BIT_DEPTH`: 1/1023 of full light, 1.9 pixel clocks in p64's Quality
profile, coarser than the one-clock window of plane 0. Dark targets were rounded before
the fit saw them. `FIT_TARGETS` is the same curve over 0..65535 (the generators accept
16 bits now) and `fit_lut_to_weights()` uses it: Quality goes from 229 to 233 distinct
codes, 41 instead of 37 in the darkest quarter, and inputs 6 and 7 are no longer black
(1 to 5 still are: their light is under half a clock). Photo keeps 179. Costs 512 bytes
of flash.

## The light plan: set_light() below the brightness curve's floor (2026-09-27)

`Hub75Driver::set_light(light_q16)` asks for a share of the profile's full light
(16.16, 65536 = full) instead of a brightness, and `get_light_plan()` reports what was
done. Upstream's `set_brightness()` runs the user value through a quadratic curve floored
at `min_brightness_` (17 on a 64-wide panel: four clocks on the top plane) and the
output-enable windows are whole pixel clocks, so the panel had 59 distinct levels, the
lowest at 6.4 % of full light and the bottom ones 25 % apart. `p64bcm::plan_light()`
(p64_bcm.h, host-tested) takes the smallest output-enable level at or above the floor
whose light reaches the request and scales the LUT's targets down for the rest
(`fit_lut()` gained a `scale_q16` argument): above the floor every request lands within a
clock with the scale between about 0.75 and 1; below the floor the level stays at the
floor and the scale alone dims, one bit of tonal depth per halving (the codes left are
the low planes' short pulses). `set_brightness()` returns to the curve. The plan is
recomputed inside `set_brightness_oe()`, so a refresh profile switch replans the same
share of the new profile's full light. p64's `Display::set_brightness()` maps its 1..255
(perceived lightness, spec 3.2) to a share of light and calls `set_light()`.

## HUB75_MIN_REFRESH_RATE range (Kconfig)

Raised from 30-240 to 30-2000 Hz: with binary-weighted low planes a high minimum is a
usable setting (p64 runs 250, which selects transition bit 4 and 271 Hz on a 64x64
panel at 20 MHz).

## GDMA channel priority (Kconfig HUB75_GDMA_PRIORITY, gdma_dma.cpp)

The panel's GDMA transmit channel gets the arbitration priority `HUB75_GDMA_PRIORITY`
(0-5, default 0 = upstream behaviour) right after `gdma_connect()`, and
`Hub75Driver::set_dma_priority()` / `get_dma_priority()` change and read it at
runtime. The panel's FIFO has no back-pressure: when other GDMA users (the hardware
AES/SHA engines during TLS) burst at the same priority, the panel channel can be
starved and the refresh stalls for good. See p64's README for the measurements.

## GDMA channel id getter (hub75.h, platform_dma.h, gdma_dma.h/.cpp)

`Hub75Driver::get_dma_channel_id()` returns the GDMA channel the panel streams on (-1 on
other platforms or before `begin()`), from `gdma_get_channel_id()`. p64's display layer
watches that channel's registers for frame boundaries; it used to scan the channels for
the LCD peripheral selector, which found a stale channel after a driver restart (the
panel mode switch re-creates the driver) because the old channel's selector still read
"LCD".

## Refresh profile changed in place (hub75.h, platform_dma.h, gdma_dma.h/.cpp)

`Hub75Driver::set_refresh_profile(planes, min_hz)` (and `set_min_refresh_rate(hz)`,
which keeps the plane count) changes the number of bit planes sent and the minimum
refresh rate without tearing the driver down: the DMA stops, the transition bit is
recomputed, the output-enable windows and the LUT are refitted, the descriptor chains
are rebuilt for the new transmission pattern, and the DMA restarts on the same channel
with the pixel data still in the row buffers (the caller redraws: those codes were made
with the previous LUT). The row buffers always hold the compile-time depth; a smaller
`planes` leaves the top planes out of the chain and the LUT produces codes of that many
bits (the compile-time gamma table is normalised by its own maximum).
`get_bit_planes()` reports the count in force. p64 switches between Quality (10 planes,
250 Hz minimum -> 271 Hz; 11 planes -> 264 Hz with rounded low windows since 2026-10-02)
and Photo (8 planes, 600 Hz minimum -> 814 Hz) this way.
Re-creating the driver (`end()` then a new `begin()`) leaves the DMA stalled on this
board: the descriptor pointer never moves again, in either mode.

The descriptor arrays are allocated once, at the size of the first chain built, and
every later profile is rebuilt inside them; a profile needing more descriptors is
refused before the DMA is touched, and a rebuild that fails anyway restores the
previous profile and restarts the DMA. The first version freed and re-allocated the
arrays (2 x 13.8 KB of internal DMA memory for ten planes) on every switch; after hours
of uptime the second block was not available, the rebuild failed with the DMA stopped
and the panel stayed dark until a reboot (2026-09-20).

## Timing getters (hub75.h, platform_dma.h, gdma_dma.h/.cpp)

`Hub75Driver::get_frame_period_us()`, `get_descriptor_count()` and
`get_lsb_msb_transition_bit()` expose the refresh period, descriptors per frame and the
transition bit, which p64's frame-locked rendering needs (it used to assume full binary
code modulation).

## Gamma 2.2 table generator fixed (color_lut.h, constexpr_pow22)

Upstream computes x^2.2 with a four-term log series that only holds near x = 1 and a
short exp series: for x = 0 it returned 1 (black mapped to full white) and the table was
not monotonic, so the library's own static checks rejected `HUB75_GAMMA_2_2` at any bit
depth. The table now uses x^2 times the fifth root of x by Newton's method, exact at the
endpoints and monotonic.

## The plane arithmetic in p64_bcm.h; the LUT fit skips blanked planes (2026-09-22)

The output-enable windows of a refresh profile (the halving below the transition bit, the
one-clock fallback, the blanking of a plane that would break the superincreasing
weights) and the LUT fit moved unchanged into `src/platforms/gdma/p64_bcm.h`, a
header without ESP-IDF includes that `GdmaDma` calls and the firmware's host tests
compile (`firmware/tests/host/unit/bcm.cpp`: every profile from 6 to 10 planes, every
transition bit, every brightness).

Those tests showed the blanking of 2026-09-20 was not enough on its own: with a plane
blanked (weight 0) the fit still walked every code in order and stopped at the first
code made of the blanked plane alone, which weighs less than the code before it; ten
planes at transition bit 6 still fitted 3 codes. The fit now walks only the codes built
from lit planes. Quality (10 planes, bit 4) and Photo (8 planes, bit 4) never blank a
plane, so their tables are unchanged (229 and 179 distinct codes at full brightness, in
the driver's log on the device and in the test).

## Rounded low windows for a profile (2026-10-02, the eleven-plane trial)

`set_refresh_profile(planes, min_hz, round_low)` takes a third argument: with it the
halved output-enable windows of the planes sent once are rounded to the nearest clock
instead of truncated (`p64bcm::plane_windows`, `weight_total`, `plan_light`). Eleven
planes at a 250 Hz minimum land on transition bit 5 (37 transmissions per row, 264 Hz);
truncated, their low windows are 0 1 3 7 15 31 (plane 0 falls back to one clock and
weighs what plane 1 does, 239 codes), rounded they are 1 2 4 8 16 31, binary from one
clock (243 codes, 51 in the darkest quarter against the ten-plane Quality's 233 and 41).
The default stays false; p64's Quality mode is this profile since 2026-10-02, Photo keeps
the truncated windows.

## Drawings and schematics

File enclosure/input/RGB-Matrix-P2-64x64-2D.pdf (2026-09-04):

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

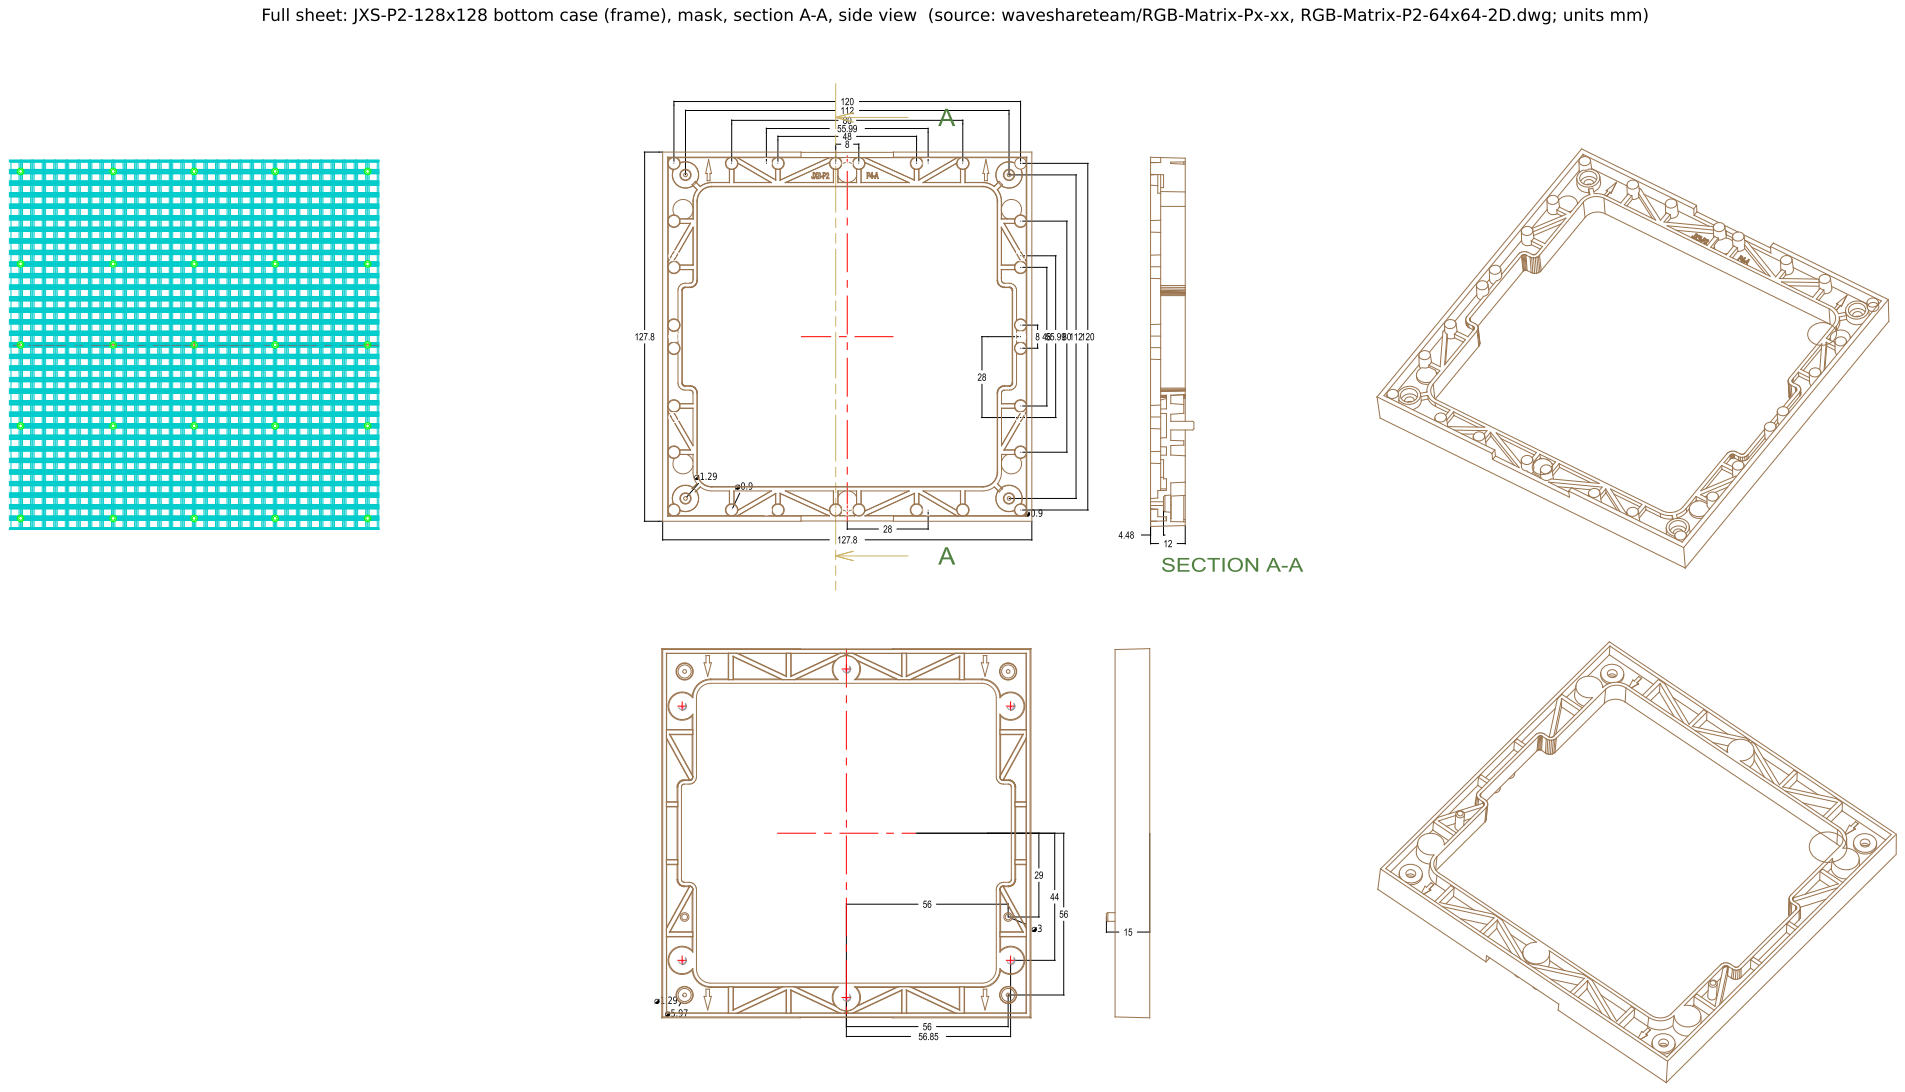
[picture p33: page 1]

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

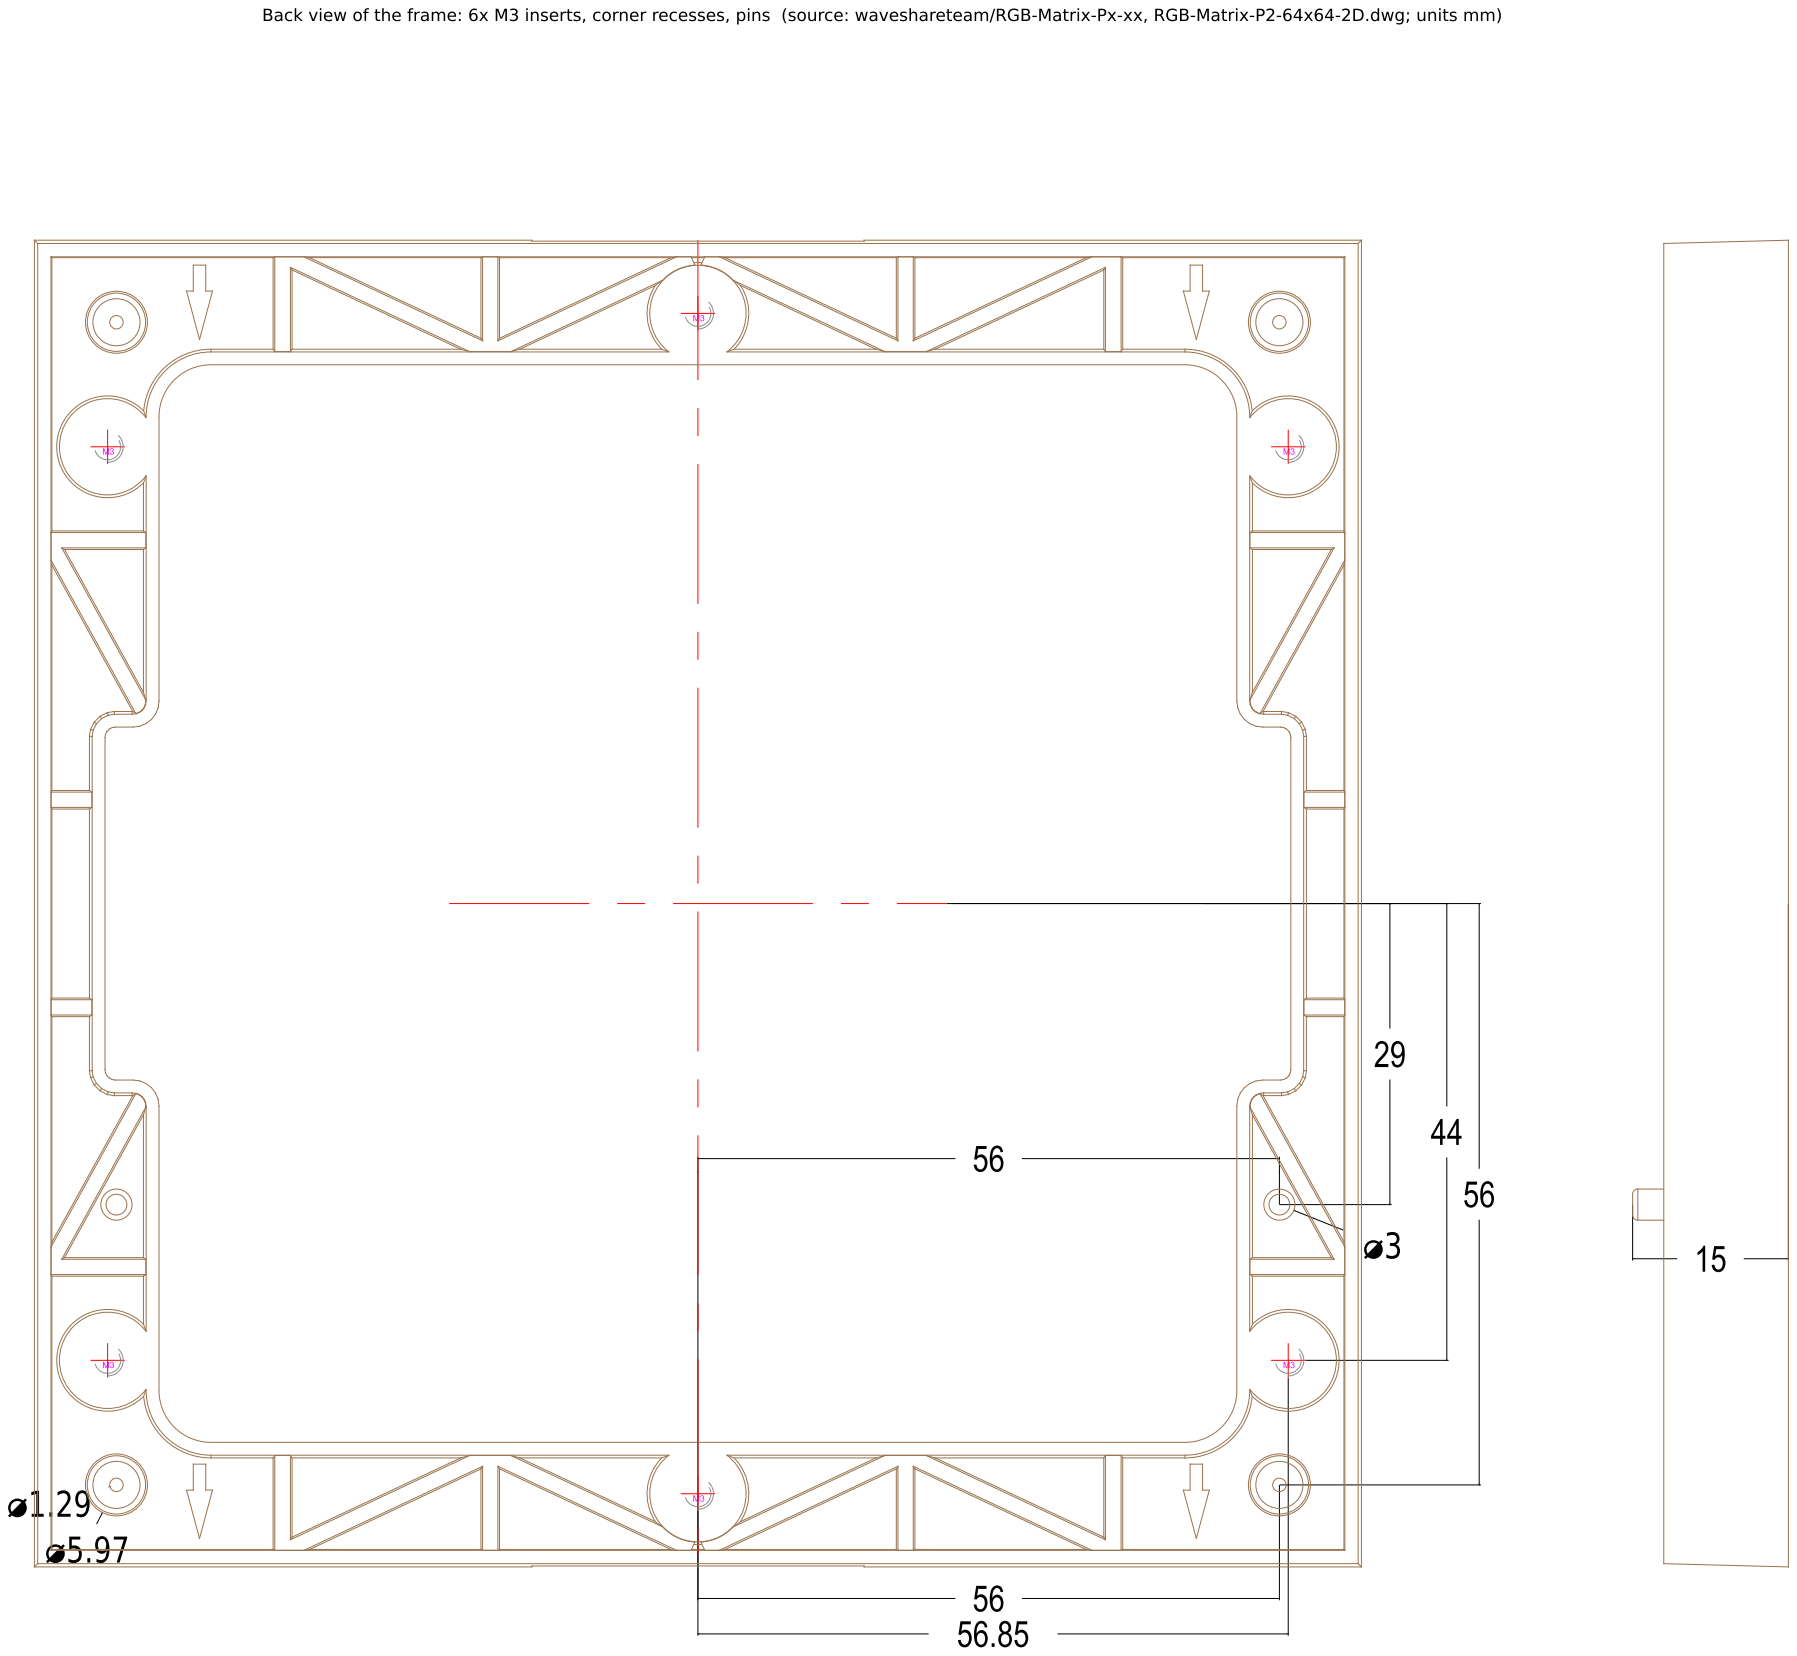
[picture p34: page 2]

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

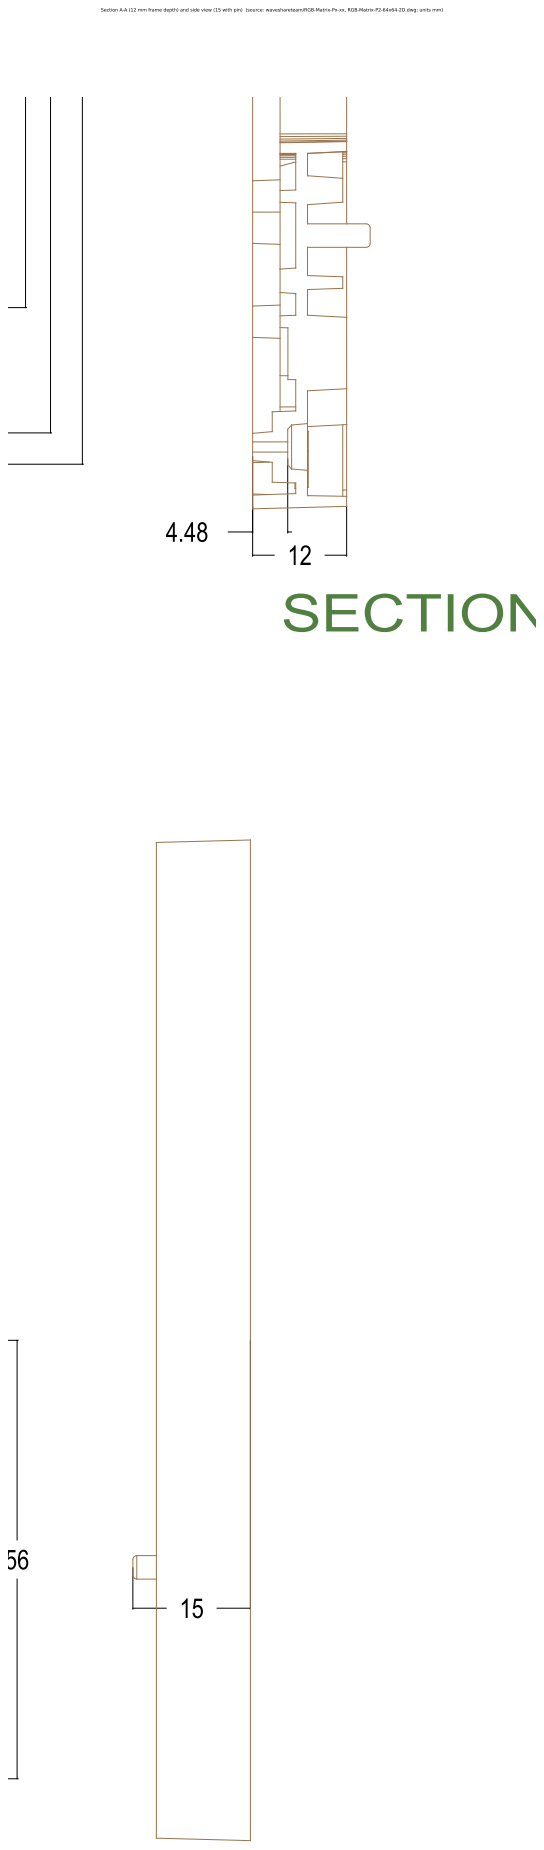
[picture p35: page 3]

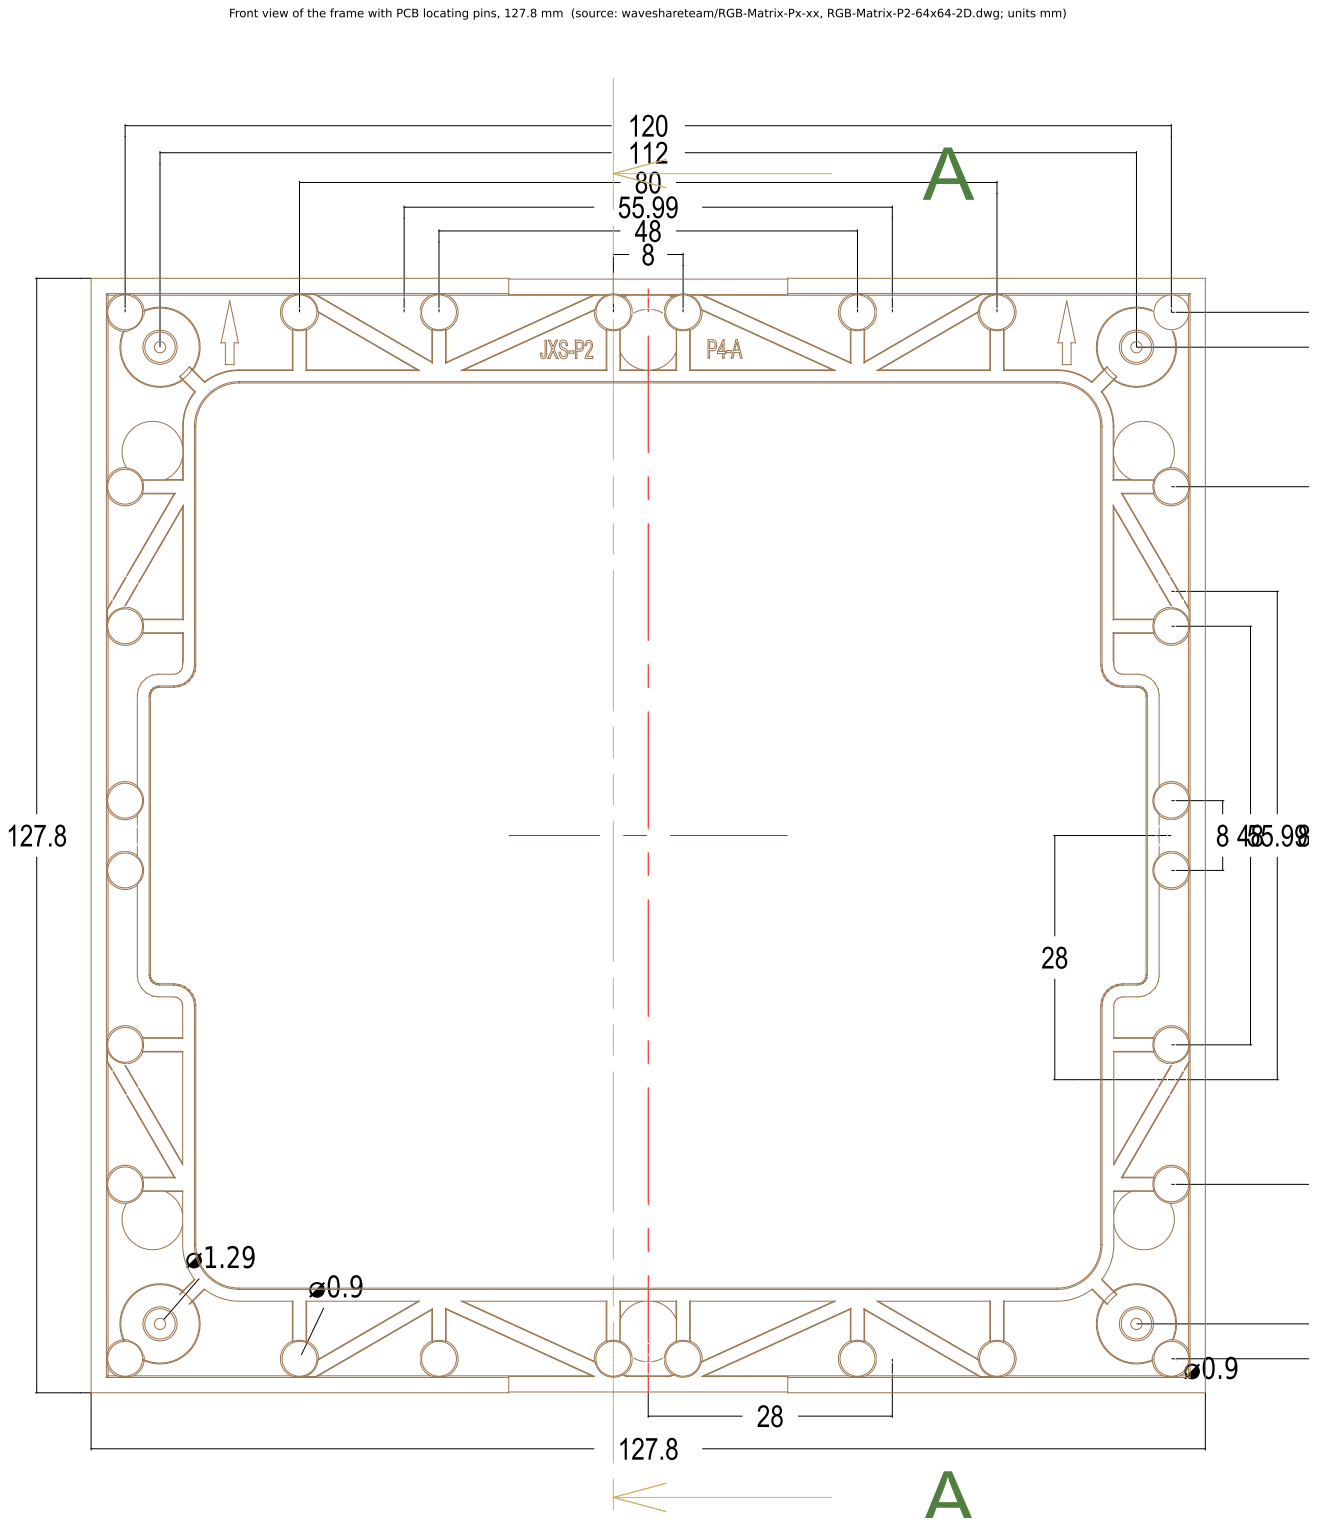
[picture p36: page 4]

Front view of the frame with PCB locating pins, 127.8 mm (source: waveshareteam/RGB-Matrix-Px-xx, RGB-Matrix-P2-64x64-2D.dwg; units mm)

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

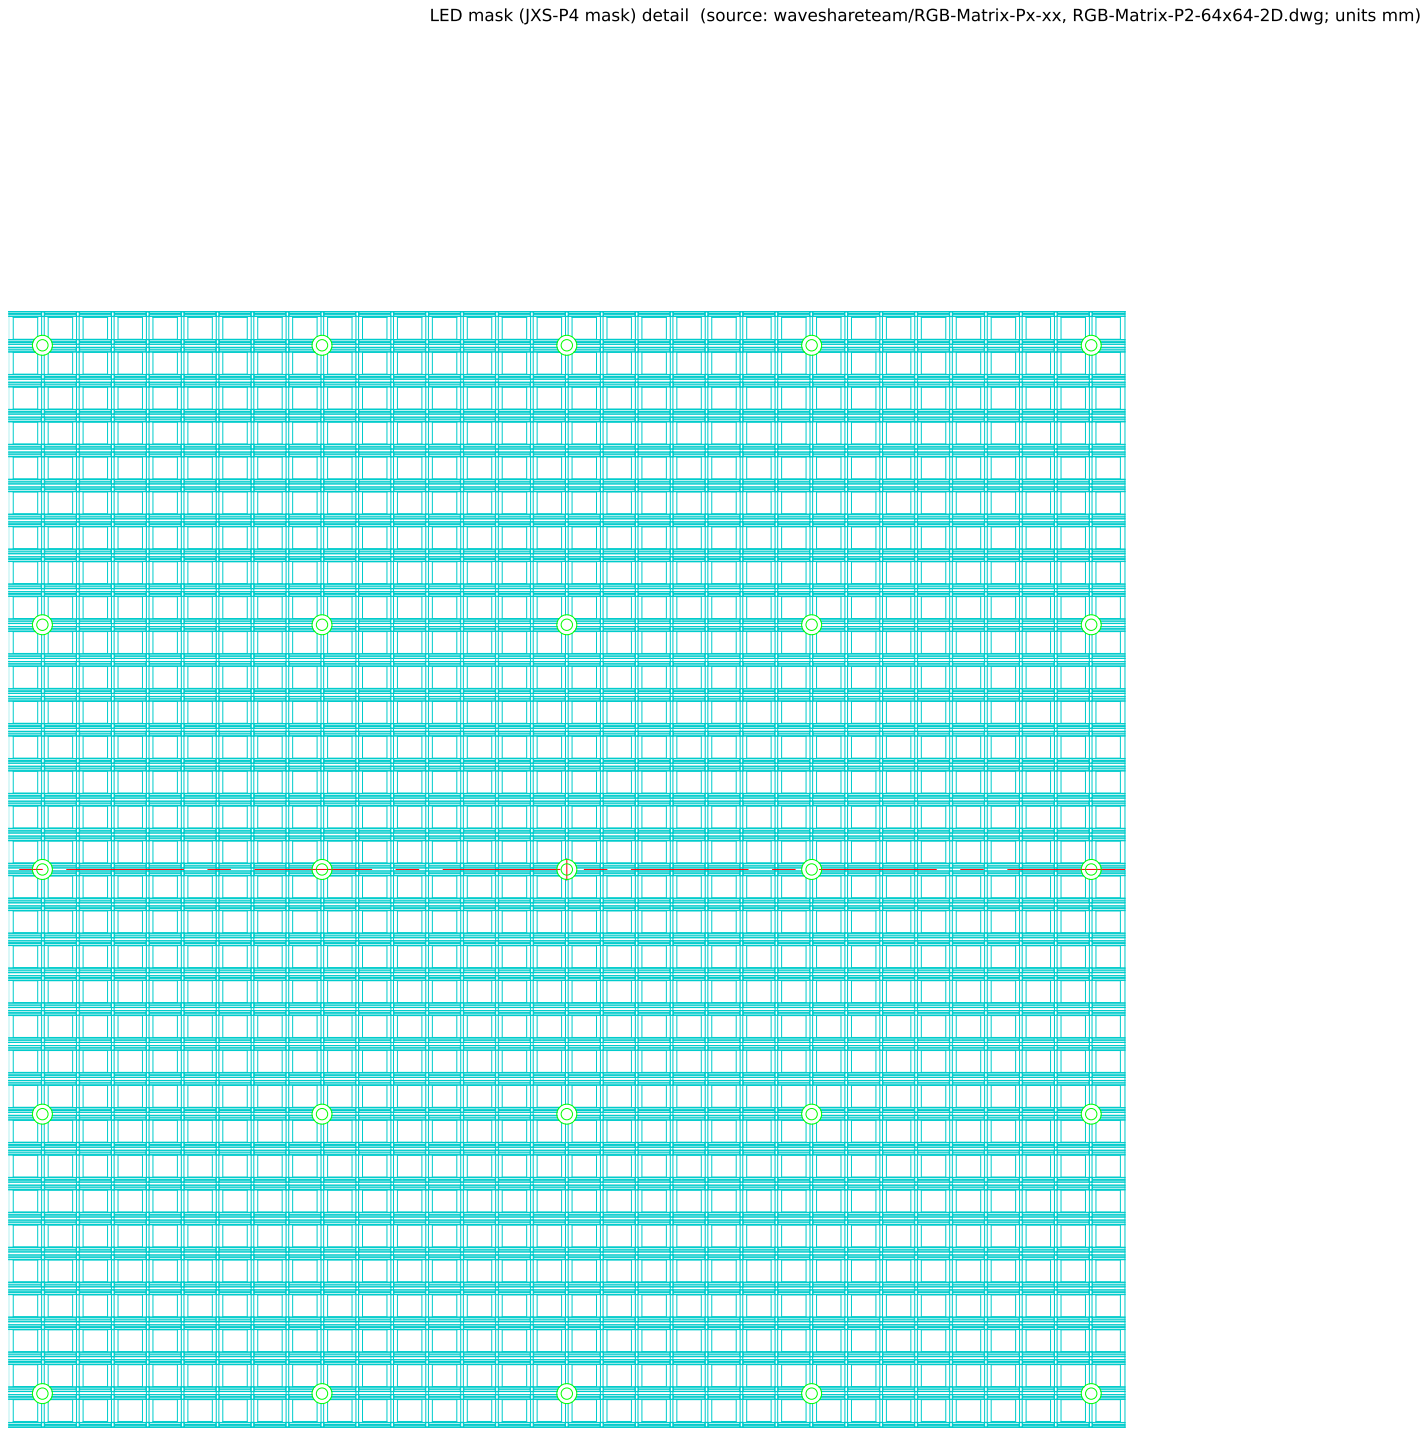
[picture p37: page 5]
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

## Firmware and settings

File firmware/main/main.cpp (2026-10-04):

// p64 -- firmware entry point.
//
// Milestone M6: app_main wires the display, the playback tasks, the network, the web
// layer and Makapix Club, mounts the card, restores the active playset and hands the
// main task to the show loop (main/show.cpp, the state machine).

#include <atomic>
#include <cinttypes>
#include <memory>
#include <new>
#include <string>
#include <vector>

#include "cJSON.h"
#include "esp_app_desc.h"
#include "esp_heap_caps.h"
#include "esp_log.h"
#include "esp_ota_ops.h"
#include "esp_timer.h"
#include "freertos/FreeRTOS.h"
#include "freertos/idf_additions.h"
#include "freertos/task.h"
#include "nvs_flash.h"
#include "sdkconfig.h"

#include "p64/display/display.hpp"
#include "p64/gfx/frame.hpp"
#include "p64/makapix/makapix.hpp"
#include "p64/net/clock.hpp"
#include "p64/net/http_server.hpp"
#include "p64/net/setup_portal.hpp"
#include "p64/net/wifi.hpp"
#include "p64/playback/frame_queue.hpp"
#include "p64/playback/player.hpp"
#include "p64/playback/renderer.hpp"
#include "p64/storage/card.hpp"
#include "p64/system/event_bus.hpp"
#include "p64/system/log_ring.hpp"
#include "p64/system/settings.hpp"
#include "p64/web/web.hpp"
#include "p64/inputs/inputs.hpp"
#include "p64/inputs/knob_rules.hpp"
#include "p64/ota/ota.hpp"
#ifdef CONFIG_P64_PRIVATE
#include "p64/private/private.hpp"
#endif
#include "p64/stream/stream.hpp"
#include "p64/system/reliability.hpp"
#include "ops.hpp"
#include "p64/widgets/widgets.hpp"
#include "show.hpp"

namespace {

constexpr const char *TAG = "p64";

// The display and the queue indices stay in internal RAM (.bss); the three 12 KB ready
// frames and the preview live in PSRAM (allocated in app_main), keeping internal RAM
// for Wi-Fi, TLS and task stacks.
p64::display::Display g_display;
p64::playback::ReadySlot *g_slots = nullptr;
p64::playback::FrameQueue *g_queue = nullptr;
p64::playback::Player g_player;
p64::playback::Renderer g_renderer;

void init_nvs() {
  esp_err_t err = nvs_flash_init();
  if (err == ESP_ERR_NVS_NO_FREE_PAGES || err == ESP_ERR_NVS_NEW_VERSION_FOUND) {
    ESP_LOGW(TAG, "NVS needs erasing (%s)", esp_err_to_name(err));
    ESP_ERROR_CHECK(nvs_flash_erase());
    err = nvs_flash_init();
  }
  ESP_ERROR_CHECK(err);
}

// The brightness the knob has reached but not yet written (-1: none pending).
std::atomic<int> g_knob_brightness{-1};

// The picture settings the display applies directly; the panel mode goes through the
// renderer (switched between two frames).
void apply_display_settings(const p64::system::Settings &s) {
  // Rotation "auto": the IMU's resolved value once it has one; the setting is the fallback.
  const uint16_t rotation = s.rotation_auto && p64::inputs::auto_rotation_resolved() ? p64::inputs::auto_rotation() : s.rotation;
  g_display.set_rotation(static_cast<p64::gfx::Rotation>(rotation));
  g_display.set_mirror(s.mirror);
  g_display.set_gains(s.gain_r, s.gain_g, s.gain_b);
  const int pending = g_knob_brightness.load();
  if (pending >= 0) {
    p64::system::Settings live = s;
    live.brightness = static_cast<uint8_t>(pending);
    g_display.set_brightness(p64::ops::effective_brightness(live));
  } else {
    g_display.set_brightness(p64::ops::effective_brightness(s));
  }
  g_renderer.request_mode(static_cast<p64::display::Mode>(s.panel_mode));  // the same values (settings.hpp)
}

// The brightness knob (p64b): every detent goes to the panel at once, through the same
// effective-brightness rule as the setting (ceiling, night window), and the setting is
// written once, 800 ms after the last detent, so a spin of forty detents costs one NVS
// write, not forty. The pending value is what apply_display_settings() shows meanwhile.
esp_timer_handle_t g_knob_commit = nullptr;

void knob_brightness_commit(void *) {
  const int v = g_knob_brightness.load();
  if (v < 0) return;
  p64::system::settings_update([v](p64::system::Settings &s) { s.brightness = static_cast<uint8_t>(v); });
  g_knob_brightness = -1;
}

void knob_brightness_step(int32_t detents) {
  const auto s = p64::system::settings_view();
  const int pending = g_knob_brightness.load();
  const uint8_t current = pending >= 0 ? static_cast<uint8_t>(pending) : s->brightness;
  const uint8_t next = p64::inputs::brightness_after(current, detents);
  g_knob_brightness = next;
  p64::system::Settings live = *s;
  live.brightness = next;
  g_display.set_brightness(p64::ops::effective_brightness(live));
  if (!g_knob_commit) {
    const esp_timer_create_args_t args = {knob_brightness_commit, nullptr, ESP_TIMER_TASK, "knob", false};
    esp_timer_create(&args, &g_knob_commit);
  }
  esp_timer_stop(g_knob_commit);
  esp_timer_start_once(g_knob_commit, 800 * 1000);
}

// The navigate knob's press: like the Makapix artwork on the panel. The call blocks up
// to 20 s on the Makapix worker, so it runs on a short-lived task (stack in PSRAM: TLS
// and JSON only, no flash) and never on the poll task; one at a time.
std::atomic<bool> g_like_busy{false};

void knob_like_task(void *arg) {
  const auto post = static_cast<int32_t>(reinterpret_cast<intptr_t>(arg));
  std::string error;
  if (p64::makapix::like(post, true, error)) ESP_LOGI(TAG, "knob: liked post %ld", static_cast<long>(post));
  else ESP_LOGW(TAG, "knob: like of post %ld failed: %s", static_cast<long>(post), error.c_str());
  g_like_busy = false;
  vTaskDelete(nullptr);
}

void knob_like() {
  const int32_t post = p64::show::current_post_id();
  if (post < 0) {
    ESP_LOGI(TAG, "knob: nothing of Makapix on the panel to like");
    return;
  }
  if (g_like_busy.exchange(true)) return;
  if (xTaskCreatePinnedToCoreWithCaps(knob_like_task, "knob_like", 6144, reinterpret_cast<void *>(static_cast<intptr_t>(post)),
                                      4, nullptr, 0, MALLOC_CAP_SPIRAM | MALLOC_CAP_8BIT) != pdPASS)
    g_like_busy = false;
}

}  // namespace

// cJSON trees (the API's status and settings documents, several KB each, six at once
// when a browser opens a page) come from PSRAM, not the scarce internal heap.
void *psram_malloc(size_t n) {
  void *p = heap_caps_malloc(n, MALLOC_CAP_SPIRAM | MALLOC_CAP_8BIT);
  return p ? p : malloc(n);
}

extern "C" void app_main() {
  cJSON_Hooks json_hooks = {psram_malloc, free};
  cJSON_InitHooks(&json_hooks);
  p64::system::logring::init(32 * 1024);
  const esp_app_desc_t *app = esp_app_get_description();
  ESP_LOGI(TAG, "p64 firmware %s (IDF %s), built %s %s", app->version, app->idf_ver, app->date, app->time);
  // This task becomes the show loop. ESP-IDF starts app_main at priority 1, below every
  // other task on core 0; the architecture (section 2) puts the show loop at 5, level
  // with httpd, the event dispatcher and MQTT and above the fetcher, the loader and the
  // widgets' tasks, so a TLS handshake never holds the user's commands (review of
  // 2026-09-22, which found it still at 1).
  vTaskPrioritySet(nullptr, 5);

  init_nvs();
  p64::system::reliability::init();
  p64::system::event_bus_init();
  p64::system::settings_init();
  const p64::system::Settings s = p64::system::settings();

  if (!g_display.begin()) {
    ESP_LOGE(TAG, "display failed to start; nothing to do");
    return;
  }
  g_display.set_rotation(static_cast<p64::gfx::Rotation>(s.rotation));
  g_display.set_mirror(s.mirror);
  g_display.set_gains(s.gain_r, s.gain_g, s.gain_b);
  g_display.set_brightness(p64::ops::effective_brightness(s));

  // Frames in PSRAM (see the globals above).
  void *slot_mem = heap_caps_malloc(sizeof(p64::playback::ReadySlot) * p64::playback::FrameQueue::kSlots,
                                    MALLOC_CAP_SPIRAM | MALLOC_CAP_8BIT);
  g_slots = new (slot_mem) p64::playback::ReadySlot[p64::playback::FrameQueue::kSlots];
  static p64::playback::FrameQueue queue(g_slots);
  g_queue = &queue;
  g_renderer.start(g_display, *g_queue, &g_player);
  g_player.start(*g_queue);
  p64::system::subscribe(p64::system::Event::SettingsChanged,
                         [](const p64::system::Message &) { apply_display_settings(p64::system::settings()); });
  if (s.panel_mode == p64::system::PanelMode::Photo) g_renderer.request_mode(p64::display::Mode::Photo);

  // The show puts the boot animation up at once; the card mounts and the playset is
  // restored while it runs (spec 15.1).
  if (!p64::show::init(g_player, g_renderer, s.boot_animation_ms)) {
    ESP_LOGE(TAG, "show failed to start");
    return;
  }
  // BOOT held at power-on: the factory reset countdown (spec 9); returns at once otherwise.
  {
    void *mem = heap_caps_malloc(sizeof(p64::gfx::Frame), MALLOC_CAP_SPIRAM | MALLOC_CAP_8BIT);
    auto *scratch = mem ? new (mem) p64::gfx::Frame() : new p64::gfx::Frame();
    p64::ops::check_boot_hold(g_player, *scratch);
  }

  // Network: Wi-Fi start creates the TCP/IP stack; the HTTP server, the portal and the
  // API come right after; SNTP waits for the network on its own.
  p64::net::wifi::start(s.hostname());
  p64::net::http::start();
  p64::net::portal::init(p64::web::ui_handler);
  p64::web::Hooks hooks;
  hooks.next = p64::show::next;
  hooks.previous = p64::show::previous;
  hooks.pause = p64::show::pause;
  hooks.resume = p64::show::resume;
  hooks.reset_timer = p64::show::reset_timer;
  hooks.refresh = p64::show::refresh;
  hooks.interlude = p64::show::interlude;
  hooks.go_to = p64::show::go_to;
  hooks.play_file = p64::show::play_file;
  hooks.play_post = p64::makapix::play_post;
  hooks.play_url = p64::makapix::play_url;
  hooks.like = p64::makapix::like;
  hooks.activate_playset = p64::show::activate_playset;
  hooks.playback_status = p64::show::status_json;
  hooks.channels = p64::show::channels_json;
  hooks.history = p64::show::history_json;
  hooks.playsets = p64::show::playsets_json;
  hooks.snapshot = [](p64::gfx::Frame &out) { return g_renderer.snapshot(out); };
  hooks.request_mode = [](p64::display::Mode m) { g_renderer.request_mode(m); };
  hooks.display = [] { return &g_display; };
  hooks.night_active = p64::ops::night_active;
  hooks.factory_reset = [] { p64::ops::factory_reset(); };
  p64::web::init(hooks);
  p64::ops::start([] { apply_display_settings(p64::system::settings()); });
  p64::net::clock::start(s.ntp_server, s.timezone);
  p64::system::subscribe(p64::system::Event::SettingsChanged, [](const p64::system::Message &) {
    const p64::system::Settings now = p64::system::settings();
    p64::net::clock::set_timezone(now.timezone);
    p64::net::clock::set_ntp_server(now.ntp_server);
    p64::net::wifi::set_hostname(now.hostname());
  });

  // Makapix Club: commands from the site drive the show; downloads come back as
  // play-this requests; the Followed playset arrives as a transient activation.
  p64::makapix::Hooks mk;
  mk.next = p64::show::next;
  mk.previous = p64::show::previous;
  mk.set_paused = p64::show::set_paused;
  mk.set_brightness = [](uint8_t b) {
    p64::system::settings_update([b](p64::system::Settings &st) { st.brightness = b; });
  };
  mk.set_rotation = [](uint16_t r) {
    p64::system::settings_update([r](p64::system::Settings &st) { st.rotation = r; });
  };
  mk.set_mirror = [](bool m) {
    p64::system::settings_update([m](p64::system::Settings &st) { st.mirror = m; });
  };
  mk.play_artwork = [](const std::string &path, int32_t post_id, const std::string &name) {
    p64::show::play_downloaded(path, "makapix", post_id, name);
  };
  mk.play_playset = p64::show::activate_transient;
  mk.current_post_id = p64::show::current_post_id;
  mk.is_paused = p64::show::is_paused;

  if (p64::storage::mount()) {
    p64::system::publish(p64::system::Event::CardMounted);
  } else {
    p64::system::publish(p64::system::Event::CardFailed);
  }
  p64::makapix::start(mk);
#ifdef CONFIG_P64_PRIVATE
  // The private area (../private, a separate repository): its content providers and
  // routes register now, before the saved playset is activated.
  p64::priv::start();
#endif
  p64::widgets::start();
  if (!p64::stream::start()) ESP_LOGE(TAG, "stream listener failed to start");
  p64::inputs::Hooks in;
  in.next = p64::show::next;
  in.previous = p64::show::previous;
  in.rotation_changed = [] { apply_display_settings(p64::system::settings()); };
  in.brightness_step = knob_brightness_step;
  in.toggle_pause = [] { p64::show::set_paused(!p64::show::is_paused()); };
  in.like = knob_like;
  p64::inputs::start(in);
  p64::ota::start();
  p64::show::restore();
  p64::show::run();
}

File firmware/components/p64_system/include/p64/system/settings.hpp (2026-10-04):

// p64 -- Settings: the one document of user settings (spec section 16), typed, kept in
// NVS as JSON, read as snapshots and written through update(). Every change is
// announced on the event bus (Event::SettingsChanged) after it is persisted.
//
// Wi-Fi credentials and Makapix credentials are not here: they live in their own NVS
// namespaces, owned by p64_net and p64_makapix.
#pragma once

#include <cstdint>
#include <functional>
#include <memory>
#include <string>

#include "p64/gfx/frame.hpp"

struct cJSON;  // apply_json's reader takes a parsed document

namespace p64::system {

// The values are display::Mode's (main.cpp and api.cpp cast one to the other).
enum class PanelMode : uint8_t { Quality = 0, Photo = 1 };
enum class MainState : uint8_t { AnimationShow = 0, Widget = 1, Stream = 2 };
enum class PickMode : uint8_t { Random = 0, Recency = 1 };
enum class ChannelSelect : uint8_t { Stochastic = 0, Swrr = 1 };
// The clock overlay's position: the four corners, or centred at the top or the bottom.
enum class Corner : uint8_t { TopLeft = 0, TopRight = 1, BottomLeft = 2, BottomRight = 3, TopCenter = 4, BottomCenter = 5 };
enum class WidgetKind : uint8_t { Clock = 0, Weather = 1, Temperature = 2, Air = 3 };
constexpr int kWidgetKindCount = 4;
// The clock widget's face (spec 7.1): the digital and analogue ones honour the font and
// colour settings; the six themed ones (approved 2026-09-26) draw with their own assets.
enum class ClockFace : uint8_t { Digital = 0, Analogue = 1, Flip = 2, Nixie = 3, Horizon = 4, Words = 5, Hourglass = 6, Orrery = 7, Led = 8, HorizonRd = 9, Aquarium = 10, Bracket = 11, Station = 12 };
// The LED face's look (p053): four LED colours behind a filter, or a vacuum fluorescent display.
enum class LedStyle : uint8_t { Red = 0, Green = 1, Amber = 2, Blue = 3, Vfd = 4 };

struct Settings {
  // Display
  uint8_t brightness = 255;          // 1..255
  uint8_t brightness_ceiling = 255;  // 1..255
  struct Night {
    bool enabled = false;
    uint16_t start_minutes = 22 * 60;  // minutes after midnight, local time
    uint16_t end_minutes = 7 * 60;
    uint8_t brightness = 0;  // 1..255, or 0 = panel off
  } night;
  PanelMode panel_mode = PanelMode::Quality;
  uint16_t rotation = 90;      // 0, 90, 180, 270
  bool rotation_auto = false;  // IMU decides; `rotation` is the fallback
  bool mirror = false;         // the picture flipped left-right, as the viewer sees it
  gfx::Rgb background{0, 0, 0};
  uint8_t gain_r = 100, gain_g = 100, gain_b = 100;  // 50..100 %
  uint16_t boot_animation_ms = 3000;                 // 0 (off) or 1000..7000 (decided 2026-09-26)

  // Show
  MainState main_state = MainState::AnimationShow;
  uint32_t auto_swap_seconds = 30;  // 0, or 5..86400
  PickMode pick_mode = PickMode::Random;
  ChannelSelect channel_select = ChannelSelect::Stochastic;
  struct ClockOverlay {
    bool enabled = true;
    std::string font = "capital-hill";
    Corner corner = Corner::TopLeft;
    bool h24 = true;
    gfx::Rgb colour{255, 255, 255};
    // The 1 px border around the text that makes it read over any artwork, blended over
    // the artwork at `border_opacity` (1..255; the text itself is always opaque).
    bool border = true;
    gfx::Rgb border_colour{0, 0, 0};
    uint8_t border_opacity = 255;
  } clock_overlay;

  // Widgets
  WidgetKind widget = WidgetKind::Clock;
  // Interludes (ADR 0014): the median gap in minutes between interludes of each kind,
  // 0 = never, else 5..1440; the per-swap probability follows from the auto-swap interval.
  uint16_t interlude_clock = 30, interlude_weather = 180, interlude_temperature = 0, interlude_air = 0;
  // A clock interlude draws a random face (p057): all nine, never the previous one again.
  bool interlude_random_clock_face = false;
  struct Clock {
    ClockFace face = ClockFace::Digital;
    LedStyle led_style = LedStyle::Red;  // the LED face only
    std::string font = "capital-hill";
    uint8_t scale = 2;      // 1..3
    bool seconds = false;
    bool blink_colon = false;
    bool h24 = true;
    bool month_first = false;  // date order: day-month (default) or month-day
    gfx::Rgb colour{255, 255, 255};
    gfx::Rgb background{0, 0, 0};
  } clock;
  struct Weather {
    bool location_set = false;
    float latitude = 0, longitude = 0;
    bool imperial = false;
    uint16_t refresh_minutes = 30;  // 10..180
  } weather;
  // The air widget (spec 7.4): the weather's location and refresh; the index it shows.
  struct Air {
    bool european = false;  // the European AQI instead of the US one
  } air;
  struct Temperature {
    int8_t offset_temperature = 0;  // -10..10 units
    int8_t offset_humidity = 0;
    bool trend = true;
  } temperature;

  // Stream
  bool stream_takeover = true;
  uint32_t stream_silence_ms = 5000;  // 500..60000
  bool ddp_enabled = true;
  uint16_t ddp_port = 4048;
  bool raw_udp_enabled = true;
  uint16_t raw_udp_port = 4064;
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

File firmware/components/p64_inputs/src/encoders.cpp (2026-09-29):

#include "encoders.hpp"

#include <atomic>
#include <cstdint>
#include <mutex>

#include "driver/gpio.h"
#include "encoder_model.hpp"
#include "esp_heap_caps.h"
#include "esp_log.h"
#include "esp_timer.h"
#include "freertos/FreeRTOS.h"
#include "freertos/idf_additions.h"
#include "freertos/task.h"
#include "p64/inputs/knob_rules.hpp"
#include "p64/system/i2c_bus.hpp"
#include "sdkconfig.h"
#include "seesaw.hpp"

namespace p64::inputs::encoders {
namespace {

constexpr const char *TAG = "encoders";
constexpr uint32_t kPollMs = 20;                       // 50 Hz; the seesaw counts detents between polls
constexpr uint32_t kRetryPolls = 5000 / kPollMs;       // a missing board is tried again every 5 s
constexpr uint32_t kIdentifyPolls = 2000 / kPollMs;    // the NeoPixel identify at start
constexpr uint32_t kLostAfterErrors = 10;              // consecutive read failures before a board counts as gone

struct Knob {
  Knob(const char *n, uint8_t a, uint8_t r_, uint8_t g_, uint8_t b_) : name(n), address(a), r(r_), g(g_), b(b_) {}
  const char *name;
  uint8_t address;
  uint8_t r, g, b;  // the identify colour
  seesaw::Board board;
  EncoderTracker tracker;
  uint32_t consecutive_errors = 0;
  uint32_t read_errors = 0;
  uint32_t polls = 0;
  uint32_t lost = 0;  // how many times the board stopped answering
  bool warned_missing = false;
  int64_t last_event_us = 0;
  const char *last_event = "";
  uint32_t pixel_until_poll = 0;  // the identify colour stays on until this poll
};

#ifdef CONFIG_P64_ENCODERS
Knob g_knobs[2] = {{"A", CONFIG_P64_ENCODER_A_ADDRESS, 0, 40, 0}, {"B", CONFIG_P64_ENCODER_B_ADDRESS, 0, 0, 40}};
#else
Knob g_knobs[2] = {{"A", 0x36, 0, 40, 0}, {"B", 0x37, 0, 0, 40}};  // never opened
#endif
std::mutex g_mutex;
bool g_started = false;
uint32_t g_poll = 0;
Hooks g_hooks;
std::atomic<bool> g_enabled{true};
std::atomic<bool> g_swap{false};
std::atomic<bool> g_invert{false};
bool g_socket_low_warned = false;  // poll task only

KnobRole role_of_knob(const Knob &k) { return role_of(static_cast<int>(&k - g_knobs), g_swap.load()); }

// The idle levels of the socket's two lines: both 1 only while a board's pull-ups are
// there (an empty socket sits low under the controller's pull-downs, knob_rules.hpp).
bool lines_idle_high() {
#ifdef CONFIG_P64_ENCODERS
  return socket_idle_high(gpio_get_level(static_cast<gpio_num_t>(CONFIG_P64_I2C_EXT_SDA)),
                          gpio_get_level(static_cast<gpio_num_t>(CONFIG_P64_I2C_EXT_SCL)));
#else
  return true;
#endif
}

// Opens a board that is not open and lights its identify colour; true when it answers.
// The levels first, then the probe: on a live bus an absent board costs one quiet NACK,
// while a probe of an empty socket (p64a) times out and the I2C driver logs an error
// line each time, so the lines are only read there, every 5 s, with no bus traffic.
bool try_open(Knob &k, i2c_master_bus_handle_t bus, uint32_t poll) {
  if (!lines_idle_high()) {
    if (!g_socket_low_warned) {
      ESP_LOGW(TAG, "GPIO socket lines idle low: nothing attached, not probing (looked at again every 5 s)");
      g_socket_low_warned = true;
    }
    return false;
  }
  g_socket_low_warned = false;
  if (i2c_master_probe(bus, k.address, 20) != ESP_OK || !k.board.open(bus, k.address)) {
    if (!k.warned_missing) {
      ESP_LOGW(TAG, "knob %s: no seesaw at 0x%02x (polled again every 5 s)", k.name, k.address);
      k.warned_missing = true;
    }
    return false;
  }
  k.warned_missing = false;
  k.consecutive_errors = 0;
  k.tracker.resync();
  ESP_LOGI(TAG, "knob %s: seesaw at 0x%02x, hardware id 0x%02x", k.name, k.address, k.board.hw_id());
  k.board.set_pixel(k.r, k.g, k.b);
  k.pixel_until_poll = poll + kIdentifyPolls;
  return true;
}

void poll_knob(Knob &k, uint32_t t_ms) {
  int32_t position = 0;
  bool down = false;
  if (!k.board.read_position(position) || !k.board.read_switch(down)) {
    std::lock_guard<std::mutex> lock(g_mutex);
    ++k.read_errors;
    if (++k.consecutive_errors == kLostAfterErrors) {
      ++k.lost;
      k.board.close();
      k.warned_missing = false;
      ESP_LOGW(TAG, "knob %s: 0x%02x stopped answering (%lu read errors)", k.name, k.address,
               static_cast<unsigned long>(k.read_errors));
    }
    return;
  }
  EncoderEvent ev;
  {
    std::lock_guard<std::mutex> lock(g_mutex);
    k.consecutive_errors = 0;
    ++k.polls;
    ev = k.tracker.feed(t_ms, position, down);
    if (ev.any()) {
      k.last_event_us = esp_timer_get_time();
      k.last_event = ev.turned > 0 ? "cw" : ev.turned < 0 ? "ccw" : ev.long_press ? "long" : ev.pressed ? "press" : "release";
    }
  }
  if (!ev.any()) return;
  const bool enabled = g_enabled.load();
  const KnobRole role = role_of_knob(k);
  const char *what = role == KnobRole::Brightness ? "brightness" : "navigate";
  if (ev.turned != 0)
    ESP_LOGI(TAG, "knob %s (%s): %+ld (position %ld)%s", k.name, what, static_cast<long>(ev.turned),
             static_cast<long>(position), enabled ? "" : " (knobs off)");
  if (ev.pressed) ESP_LOGI(TAG, "knob %s (%s): pressed%s", k.name, what, enabled ? "" : " (knobs off)");
  if (ev.long_press) ESP_LOGI(TAG, "knob %s: long press (unassigned)", k.name);
  if (!enabled) return;
  if (role == KnobRole::Brightness) {
    if (ev.turned != 0 && g_hooks.brightness_step) g_hooks.brightness_step(ev.turned);
    if (ev.pressed && g_hooks.toggle_pause) g_hooks.toggle_pause();
  } else {
    // Several detents between two polls are one step: a swap takes longer than a detent.
    if (ev.turned > 0 && g_hooks.next) g_hooks.next();
    if (ev.turned < 0 && g_hooks.previous) g_hooks.previous();
    if (ev.pressed && g_hooks.like) g_hooks.like();
  }
}

void task(void *) {
  i2c_master_bus_handle_t bus = system::i2c_ext_bus();
  if (!bus) {
    ESP_LOGE(TAG, "no external I2C bus: encoders off");
    vTaskDelete(nullptr);
    return;
  }
  for (Knob &k : g_knobs) try_open(k, bus, 0);
  TickType_t wake = xTaskGetTickCount();
  while (true) {
    vTaskDelayUntil(&wake, pdMS_TO_TICKS(kPollMs));
    const uint32_t poll = ++g_poll;
    const auto t_ms = static_cast<uint32_t>(esp_timer_get_time() / 1000);
    for (Knob &k : g_knobs) {
      if (!k.board.is_open()) {
        if (poll % kRetryPolls == 0) try_open(k, bus, poll);
        continue;
      }
      if (k.pixel_until_poll && poll >= k.pixel_until_poll) {
        k.board.set_pixel(0, 0, 0);
        k.pixel_until_poll = 0;
      }
      poll_knob(k, t_ms);
    }
  }
}

}  // namespace
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

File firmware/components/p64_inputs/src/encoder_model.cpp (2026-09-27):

#include "encoder_model.hpp"

namespace p64::inputs {

EncoderEvent EncoderTracker::feed(uint32_t t_ms, int32_t position, bool down) {
  EncoderEvent ev;
  if (have_position_) {
    // Two's-complement subtraction wraps correctly across INT32_MAX / INT32_MIN.
    const auto delta = static_cast<int32_t>(static_cast<uint32_t>(position) - static_cast<uint32_t>(last_position_));
    ev.turned = invert_ ? -delta : delta;
    detents_ += ev.turned;
  }
  have_position_ = true;
  last_position_ = position;

  // The switch: a level must be seen on two consecutive polls to count (20 ms at 50 Hz,
  // longer than the contact bounce of the encoder's push switch).
  if (down == raw_down_ && down != held_) {
    held_ = down;
    if (held_) {
      ev.pressed = true;
      ++presses_;
      down_since_ms_ = t_ms;
      long_reported_ = false;
    } else {
      ev.released = true;
    }
  }
  raw_down_ = down;
  if (held_ && !long_reported_ && t_ms - down_since_ms_ >= kLongPressMs) {
    long_reported_ = true;
    ev.long_press = true;
    ++long_presses_;
  }
  return ev;
}

void EncoderTracker::resync() { have_position_ = false; }

}  // namespace p64::inputs

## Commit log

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2026-09-04 Verify against the Waveshare frame drawing; tighten the fit and widen photo-derived features
    Checked the SCAD against RGB-Matrix-P2-64x64-2D.dwg (added to the repo): the six M3 inserts match to 0.01 mm. The frame is 127.8 mm square with sharp corners, 12 mm deep, 1.6 mm outer wall; pocket is now 128.4 mm (0.3 mm per side), corner radius 0.6, ledge 1.6 mm so it sits fully on the wall. The drawing has no PCB, so the HUB75 header position stays photo-derived; pin holes, mic holes and the plug pocket were enlarged to absorb +-1 mm, and the lower vent band shortened to clear the mic holes. z_chip set to 0.5 mm since the chip edge overhangs the frame rim. README documents what was verified and wha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
    [RGB-Matrix-P2-64x64-2D.dwg, p64_enclosure.scad, p64_enclosure_print.3mf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]
2026-09-04 Add service-print STL variant (0.45 mm fit clearance, 0.8 mm labels) for MJF/SLA bureaus
    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
    [p64_enclosure_service.stl]
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2026-09-08 Replace text labels with groove marks and bring all walls to 2 mm for bureau printing
    JLC3DP flagged the debossed BOOT/RST lettering: the ribs between letter strokes were 0.33 mm. Labels are now one groove (BOOT) and two grooves (RESET), 1.2 mm wide with 1.5 mm ribs. Screw bosses widened to 10.5 mm (2.0 mm walls around the counterbore) and pin holes reduced to 3.0 mm (2.05 mm bridge). Service STL, home STL/3MF, renders and README regenerated.
    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
    [p64_enclosure.scad, p64_enclosure_print.3mf, p64_enclosure_print.stl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]
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2026-09-08 Add the p64 firmware: ESP-IDF bring-up test for the ESP32-S3-RGB-Matrix + P2 64x64
    C++20 application on the esphome/esp-hub75 DMA driver (fetched by the component
    manager, pinned in dependencies.lock). Cycles through a bouncing ball (shows the
    panel's native "down" and origin), a white fade linear in driver units, a white
    fade linear in CIE lightness, and a rotating square hue wheel; BOOT skips ahead.
    sdkconfig.defaults carries everything board-specific: WROOM-2-N32R16V octal
    flash/PSRAM, console on native USB Serial/JTAG, the HUB75 pin map from the
    schematic, FM6126A init (unconfirmed), 8-bit CIE1931 colour, double buffering.
    tools/*.ps1 activate the EIM ESP-IDF v5.5.4 install and wrap bui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
    [partitions.csv]
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2026-09-11 Add enclosure v3: wedge foot moved to a heel under the back
    v3 is v2 with the stand's wedge relocated from below the front edge to
    the back-bottom edge (foot = "back"; foot = "front" reproduces v2). The
    front now shows the same 2 mm rim on all four sides instead of a 9 mm
    bar under the LED matrix; the base is still one flat plane at 12 degrees
    over the full 34 mm depth, so the stance is unchanged and the display
    stands 7 mm lower.
    - back_slab() extends the sloping back face below the bottom edge by the
    heel height, corrected for the slope; outer_body() no longer extends
    the front outline; standing() and the echo lines follow.
    - Cable groove and plug pocket cut through the heel as before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
    [p64_enclosure_print.3mf, p64_enclosure_print.stl, p64_enclosure_service.stl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]
2026-09-11 Revert "Add enclosure v3: wedge foot moved to a heel under the back"
    The heel was on the wrong side. Leaning back 12 degrees makes the shell's
    back-bottom edge dip 34 * sin(12) = 7.1 mm below the front-bottom edge, so
    the flat base needs material added at the front (the v1/v2 bar) or removed
    at the back. A heel at the back tilts the stance further and the product
    render showed the shell sunk 14 mm into the table. Removing the whole v3
    set until a viable variant is chosen.
    This reverts commit 8c8f2e4.
    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
    [p64_enclosure_print.3mf, p64_enclosure_print.stl, p64_enclosure_service.stl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]
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2026-09-11 Add v4 meshes and document the USB-C socket design
    Print STL/3MF and the 0.45 mm service STL for v4 (watertight, 86.5 cm3,
    same 132.4 x 138.9 x 34.6 mm footprint as v2). README: v4 section with
    the assumed JUXINICE dimensions, socket placement and clearances, wall
    features, ribbon hooks, removed base cut-outs, assembly and printing
    notes; file table, regenerate and render commands, sources. Root README
    marks v4 as the current design.
    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
    [p64_enclosure_print.3mf, p64_enclosure_print.stl, p64_enclosure_service.stl]
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2026-09-11 Add enclosure v5 source: the shipped speaker sunk into the upper back
    v5 is v4 plus the 99.4 x 44.4 x 20.7 mm speaker box that comes with the
    controller, rear-firing. A plus-shaped window in the back wall centred
    at (0, +27) lets the 8.7 mm of body behind the lug plane into the cavity;
    the four corner lugs rest on the outer face and M4 thread-forming screws
    go through them into printed bosses inside (8 mm, 7 mm tall, 3.6 mm
    pilot, clipped clear of the window). The drivers stay exposed, 12 mm
    proud of the back. Notches at both window ends pass the lead; the upper
    vent band is replaced by two slots each side of the box. New part
    "section_spk" cuts through the lugs; the product view shows the b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
    [p64_enclosure_v5.scad]
2026-09-11 Add v5 outputs and document the speaker mount
    Print STL/3MF and the 0.45 mm service STL for v5 (watertight, 78.9 cm3,
    footprint unchanged), eight renders including the speaker section.
    README: v5 section with the measured speaker geometry, window shape,
    bosses and screws, clearances to the top bosses and to the panel's VH4
    socket and HUB75 OUT header, lead notches, vents, assembly and printing;
    file table rows for v5, the measurements file and the speaker photos;
    regenerate and render commands. Root README marks v5 as current.
    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
    [p64_enclosure_print.3mf, p64_enclosure_print.stl, p64_enclosure_service.stl]
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2026-09-12 New test cycle: hue-cycling ball with FPS counter, full white, longer hue wheel; frame-lock rendering to the panel refresh
    Phases are now ball 10 s (colour runs once around the hue circle, delivered fps in
    3x5 digits top-right), full power all-white 20 s, and the square hue wheel 50 s
    (still one turn per 20 s). The fade scenes are gone.
    Display now reads the LCD GDMA channel itself: present() clears the channel's
    end-of-frame flag before flipping, and wait_for_back_buffer() sleeps until just
    before the predicted boundary, spins on the flag and confirms from eof_des_addr and
    dscr that the DMA moved to the other chain before the next copy. Measured on the
    board: 76.0 fps (one frame per 76.3 H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
    [display.cpp, main.cpp]
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2026-09-12 Frame-rate test: 32 MHz HUB75 clock (122 Hz refresh), ball scene only, keep the idle task fed
    Raising the clock from 20 to 32 MHz takes the panel refresh from 76.3 to 122.1 Hz; the
    frame-locked loop follows: 122.0 fps measured, zero late flips, copy 5.8 ms of the
    8.2 ms period. The white and hue-wheel scenes are removed (git history keeps them);
    the ball runs in 10 s rounds with statistics after each.
    With the shorter period the wait no longer had two whole ticks of slack and stopped
    sleeping, so the idle task on core 0 starved and the task watchdog fired every 5 s.
    The wait now sleeps on one tick of slack and forces a one-tick yield at least once
    a second; spin lead trimmed to 0.6 ms.
    Co-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
    [display.cpp, main.cpp]
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2026-09-12 GIF show at real speed with an NTP clock; back to 76 Hz; fix DMA sync for sparse presents
    Frame-rate testing is over: the HUB75 clock returns to 20 MHz (76 Hz), GIF frame
    delays are honoured (browser rule: under 20 ms shows for 100 ms), each GIF stays
    30 s, and the fps overlay is off. Both test behaviours remain behind menuconfig
    switches (P64_GIF_MAX_SPEED, P64_SHOW_FPS).
    New: Wi-Fi station (net/wifi) and SNTP clock (net/clock); a 24-hour HH:MM clock
    top-left on a black box, "--:--" until the first sync; timezone and NTP server in
    menuconfig (default New York, pool.ntp.org). Credentials come from the git-ignored
    sdkconfig.secrets, applied by the project CMakeLists (template committed). The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
    [display.cpp, main.cpp]
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2026-09-12 Play random promoted Makapix Club artwork, fetched in the background every 30 s
    Boot shows a random embedded GIF; a fetcher task on the Wi-Fi core then asks
    makapix.club anonymously for one random promoted GIF no larger than the panel
    (/api/post?promoted=true&sort=random&limit=1&width_max=64&height_max=64&
    file_format=gif) and downloads it (/api/d/{sqid}.gif). Each 30 s slot switches to
    the artwork that arrived, or to an embedded GIF when none did, and requests the
    next. Recently shown sqids are skipped, downloads capped at 1 MB, TLS waits for
    the NTP sync. Menu p64 > Makapix Club: enable, host, cap.
    TLS now runs AES and SHA in software: the hardware engines' GDMA bursts starve the
    LCD_CAM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
    [display.cpp, main.cpp]
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2026-09-13 Fix frame pacing after back-to-back presents: identify the front DMA chain from dscr
    Display::present() identified the chain that was front from the GDMA channel's
    eof_des_addr. That register names the chain whose frame ended last, so for one refresh
    after a buffer switch it still points at the previous front. Two presents within one
    refresh, which happens at every artwork transition and after a single-frame GIF hold,
    therefore recorded the wrong chain, and every later wait_for_back_buffer() saw the DMA
    "still in the old chain" until its timeout. With 100 ms GIF frame delays the overdue
    next frame recreated the condition, so the show ran at 4 to 11 late flips per frame
    for minutes at a time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
    [display.cpp]
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2026-09-13 Vendor esphome/esp-hub75 0.3.6 as a local component
    Unmodified copy of the registry component (MIT) under firmware/components/esp-hub75,
    so the driver can be patched for output-enable-weighted low bit planes. The manifest
    no longer pulls it from the registry; main links "esp-hub75" instead of the managed
    name. Builds to the same firmware as before.
    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
    [hub75_types.h]
2026-09-13 esp-hub75 patch: binary-weighted low bit planes, fitted LUT, working gamma 2.2
    The driver meets HUB75_MIN_REFRESH_RATE by sending the bit planes at or below its
    transition bit once each, but upstream keeps every plane's output-enable window the
    same, so those planes all weigh one transmission and the distinct levels collapse to
    transmissions-per-row + 1 (8 bits forced to 150 Hz gave 66 levels). Each such plane
    now gets half the output-enable window of the plane above it, which restores its
    binary weight: the shortened chain's refresh gain is kept together with 2^bits levels.
    The 256-entry LUT is refitted to the planes' real on-times (integer windows, latch
    blanking) after every brightness ch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
    [display.cpp]
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2026-09-14 microSD card: mount, copy GIFs over HTTP, play card files and a card playlist
    New sdcard module: SDMMC 1-bit (CLK 1, CMD 44, D0 17, the board's wiring), FAT at
    /sdcard with long file names, formatted automatically when a card has no FAT file
    system (menu "microSD card": pins, bus clock, format policy). GIF files live in the
    card's root.
    Web control gains the card: GET /sd lists it, PUT /sd/<name> copies a GIF onto it
    (streamed to a .part file, header-checked, then renamed), GET /sd/<name> reads it back,
    DELETE /sd/<name> removes it, GET /sd/mount remounts after a swap; the front page shows
    the card's files with Play/Delete buttons and a drag-and-drop zone that uploads through
    the browser. /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
    [main.cpp]
2026-09-14 GDMA priority for the panel's channel, debug endpoints, on-demand speed test
    esp-hub75 patch: HUB75_GDMA_PRIORITY (0-5, default 0 = upstream) is applied to the
    panel's GDMA transmit channel after gdma_connect(), and Hub75Driver::set_dma_priority()
    / get_dma_priority() change and read it live. Display exposes health() (stall flag,
    cumulative frames, late flips and timeouts, priority, transition bit),
    set_dma_priority() and instance(). The speed test can run on demand (run_now(loops)),
    and the web control gains, behind P64_DEBUG_ENDPOINTS (on): GET /debug (panel health,
    timing, crypto settings), /debug/dma?priority=N, /debug/stress[?loops=N] (about 12 MB
    of HTTPS/HTTP downloads per pass, a hea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
    [display.cpp]
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2026-09-15 Show: card GIF at boot, then only fresh Makapix downloads, swapped as soon as ready
    The show no longer embeds any GIF. At boot it reads a random GIF from the microSD
    card (black with the clock when the card has none), switches to the first Makapix
    download the instant it lands, then to a fresh download every 30 s, or as soon as the
    next one lands when it is late; the current artwork stays up meanwhile and the scene
    re-requests every 5 s so failures retry forever. A web request sets the rotation's
    artwork aside and resumes it afterwards when no download is waiting.
    assets/gifs stays as the gifcheck test corpus and the card copy set; the binary
    shrinks from 2.3 MB to 1.2 MB. Verified on the b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
    [main.cpp]
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2026-09-19 Rename firmware/ to hardware-tests/: the test bed becomes the technical reference
    The firmware written so far brought up the board and the panel one thing at a
    time (driver patch, frame pacing, GDMA priority, network, microSD, web control)
    without building towards the p64 device itself. It moves to hardware-tests/ as
    is, still building and flashing, to serve as the technical reference for the
    product firmware that will be started from zero in a fresh firmware/ folder.
    Pure rename plus path fixes: .gitignore (build products, generated sdkconfig,
    secrets and the ignored reference/ clones follow the folder), the repository
    map and status in README.md, CLAUDE.md (sections renamed "Hardware test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
    [partitions.csv]
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2026-09-19 Add enclosure v6 source: 90-degree USB-C adapters on the controller's ports
    v6 is v4 with the JUXINICE panel-mount sockets removed: the v1 print showed
    there is no room for them. Instead two small 90-degree USB-C adapters
    (19.3 x 12.7 x 8.0 mm, plug centre 4.8 mm from one end, socket in the far
    end face) stay plugged into POWER and USB, bodies hanging below the ports
    and touching each other, sockets facing the back wall. One 26.2 x 9.2 mm
    chamfered window at the bottom centre of the back face reaches both socket
    faces (2.9 mm inside the surface); a U-shaped cradle on the cavity back
    (2 mm walls, 6 mm deep, 0.3/0.5 mm clearance, entry chamfer) keys the last
    6 mm of the bodies; one groove besi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
    [p64_enclosure_v6.scad]
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2026-09-19 Firmware M4: API v1, WebSocket push, live preview, file manager, web UI; panel modes in place
    p64_web: /api/v1 with p3a's envelope (status, settings with clamping, actions
    next/play/reboot, the panel frame as PNG or raw, Wi-Fi scan/set/erase, the time
    zone list, diagnostics: log ring buffer, memory with task stacks, DMA priority,
    the decode benchmark), the card file manager (list, get, upload validated by
    sniffing and a trial decode, delete, mkdir, rename), a WebSocket that pushes
    status every 2 s and on events, and an embedded single-page UI with a live
    preview polled at 2.5 fps. The application injects hooks, so the component
    knows no application code. p64_system gains the log ring; p64_gf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
    [display.cpp, main.cpp]
2026-09-19 Firmware M5: content model (playsets, channels, scheduler, history), the show state machine, playset API
    p64_content: channels and playsets with validation and p3a-compatible JSON, the
    scheduler ported from p3a (SWRR and stochastic selection over normalised weights
    with credit correction; random and recency picks with offsets; PCG32), a history
    ring of 32 with a position, the local folder index (newest first, PSRAM entries),
    the playset store on the card. Host-tested (1115 checks).
    main/show.cpp is the Animation show state machine on the main task: command queue,
    auto-swap timer, pause, play-this, activation persisted in NVS, restore at boot,
    history navigation that drops vanished files, a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
    [main.cpp]
2026-09-19 Firmware M7: widgets (fonts pipeline, clock overlay, clock, weather, temperature, interludes, main states)
    p64_gfx: Capital Hill 6 px and Everyday Typical 7 px rendered by tools/gen_fonts.py
    into fonts_data.cpp (Font tables, outline drawing, top anchored on digits/capitals).
    p64_widgets: ClockSource, WeatherSource (Open-Meteo, 48 pixel icons from
    tools/gen_weather_icons.py, letter/icon/high/low strip), TemperatureSource (on-board
    SHTC3 over the new i2c_master driver, 60 s sampling), the HH:MM corner overlay with
    outline. Settings gain clock, weather and temperature groups.
    Show: main states (animation show / widget), the overlay keyed on the artwork being
    up, interludes rolled at auto-swap a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
    [main.cpp, settings.hpp]
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2026-09-19 Firmware M9 (part 1): reliability, RTC, night schedule, factory reset, task watchdog
    p64_system: reliability (reset reason, per-cause reboot counters in NVS, the core dump
    summary, OTA image confirmation deferred to 30 s after boot so a crashing update rolls
    back), the shared internal I2C bus, the PCF85063A RTC (seeds the clock at boot; NTP and
    manual sets write it back; host-tested codec), the pure night-schedule rule.
    main/ops: the night applier on a 15 s timer, the factory reset (API with the
    confirmation word, BOOT held 10 s at power-on with a 3-2-1 countdown screen), image
    confirmation. Task watchdog on the show loop, the loader and the stream listener.
    API: set_time, factory_reset, dia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
    [main.cpp, ops.cpp]
2026-09-19 Firmware M9 (part 2): IMU taps and gravity auto-rotation (p64_inputs)
    p64_inputs: QMI8658 accelerometer polled at 250 Hz on a PSRAM-stack task, the
    host-tested TapDetector (impulse shape, 80..350 ms double window, 1 s lockout,
    sensitivity 1..10 = 2.5..0.25 g) and OrientationTracker (an "upright now" calibration
    stores the gravity angle for the current rotation; hysteresis: a second within 30
    degrees of a right angle and at least 0.55 g in the plane; holds when flat). Single tap
    = next, double = previous; rotation_auto drives the display once resolved.
    API: diag/imu, action/calibrate_upright, inputs in the status. Kconfig
    P64_IMU_ROTATION_SIGN for the mounting direction.
    Verified on the devic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
    [inputs.cpp, main.cpp, qmi8658.cpp]
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2026-09-20 Firmware M10 (part 1): the web UI in p3a's layout and themes, plus the flash-guard fix
    p64_web/ui: Home (live preview from /api/v1/frame, now-playing card with channel rows
    and the shuffle toggle, transport with like and info, playset pills, "Play from..."
    with upload to a folder and URL or Makapix link, banners), Playsets (list, built-ins,
    the editor with the balance bar, channel cards with reorder, add-channel dialog with
    Local folders and the Makapix kinds with browser-side checks), Settings (Display,
    Widgets, Stream, Network with the PIN and the time, Storage with the file manager,
    Makapix, System with diagnostics and about), Update. p3a's common.css and theme.js
    verbatim (five themes),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
    [main.cpp]
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2026-09-20 Firmware: panel modes as driver refresh profiles; fix the dark panel and the posterized Photo mode
    Two bugs from the user's report of 2026-09-20. Photo mode (ten planes at transition
    bit 6) gave planes 0, 1 and 2 one-clock output-enable windows, the weights stopped
    being superincreasing and the LUT fit's monotonic walk stuck at code 3: three output
    levels, a dim posterized picture. Every mode switch freed and re-allocated both
    descriptor chains from internal DMA memory (2 x 13.8 KB); after hours of uptime the
    second allocation failed with the DMA already stopped, the new rate was kept as in
    force so retries were no-ops, and the panel stayed dark until a reboot.
    Driver patch: set_refresh_pro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
    [display.cpp]
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2026-09-21 Firmware: maximum Makapix artwork size, a channel setting
    A new Makapix setting, maximum artwork size (32, 64, 128 or 256 pixels per
    side, default 128, other values snap up), keeps the channels to artworks that
    fit it: the paired listings ask the server with width/height lte criteria of
    query_posts, the anonymous promoted feed has no size filter so the fetcher
    drops oversized entries from every page, and the show never picks an
    oversized entry from an index walked before the setting changed. A change
    refreshes every channel at once. Play-this, the site's commands, URLs and the
    card stay free up to the 256x256 canvas. A select on the Settings Makapix
    tab, `makapix.max_size` in the API, the sp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
    [settings.hpp]
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2026-09-22 enclosure v7: tolerance budget around the USB-C adapters, cradle as a glued insert
    v6's window (0.4/0.6 mm per side) and cradle (0.3/0.5) sit around parts whose
    position is known to about 1 mm: the port position is read off a product photo,
    the boot gap that sets how far the adapter bodies hang is an estimate, the body
    was measured on a photo, and an FDM opening prints smaller than modelled. v7
    names that budget (tol_pos, tol_gap, tol_body, tol_z, print_clr) and derives
    every clearance from it: window 28.3 x 10.7 (1.45 mm in x, 1.95 above, 0.76
    below, where the frame's own wall bounds the error), corner radius equal to
    the body's, outer chamfer 0.5, the mic1 hole moved 0.5/1.6 mm so the webs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
    [p64_cradle_insert.stl, p64_enclosure_print.3mf, p64_enclosure_print.stl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]
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2026-09-22 settings: the document's rules in settings_model.cpp, host-tested
    Review proposal P-T2. settings.cpp keeps the store (NVS, the shared view, events); the
    clamping, the enum names and the JSON form move unchanged to settings_model.cpp, which
    has no ESP-IDF include. Six host cases: defaults and a full document round-trip, every
    range clamps instead of wrapping (the M4 bug, device-checked for one key until now), the
    maximum size snaps to its four steps, invalid values fall back, unknown enum names leave
    the value alone, partial documents merge and bad JSON is refused.
    [settings_model.cpp]
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2026-09-22 show: the decision rules in show_rules.cpp, host-tested (first slice of the show core)
    Review proposal P-T1. show.cpp keeps its state and effects and asks main/show_rules for
    the decisions bugs have lived in: the swap-timer gate (the frozen artwork of
    2026-09-21), the replacement of a pick prepared from a tiny cache (the one-file replay
    of M6), the entry a fresh pick avoids, the interlude roll, the stream gate and the Stage
    that parks what the state puts up while a stream holds the panel, and the channel
    status and no-artwork texts. Nine host cases replay those scenarios. Device: widgets,
    stream, content, timing, api and ops smoke tests pass.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
    [show_rules.hpp]
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2026-09-22 show: the whole show logic in show_core.cpp behind ShowEnv, host-tested through scenarios
    Review proposal P-T1. The logic of show.cpp (playsets and channels, picking and
    preparing, history, auto-swap, pause, play-this, status screens, the Widget and Stream
    states, the stream takeover, the status JSON) moves unchanged into main/show_core.cpp.
    Its outside calls go through one interface, ShowEnv (clock, randomness, settings,
    persistence, the player, the loader, Makapix, storage, Wi-Fi, stream, events, log), and
    its globals become the fields of one State. show.cpp is now the shell: the command queue,
    the task loop, the public API and the device's ShowEnv.
    Nine host scenarios drive the core thro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
    [show_core.hpp]
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

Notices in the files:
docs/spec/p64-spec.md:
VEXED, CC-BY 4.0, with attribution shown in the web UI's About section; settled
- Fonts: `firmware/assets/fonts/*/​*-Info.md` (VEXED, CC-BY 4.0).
